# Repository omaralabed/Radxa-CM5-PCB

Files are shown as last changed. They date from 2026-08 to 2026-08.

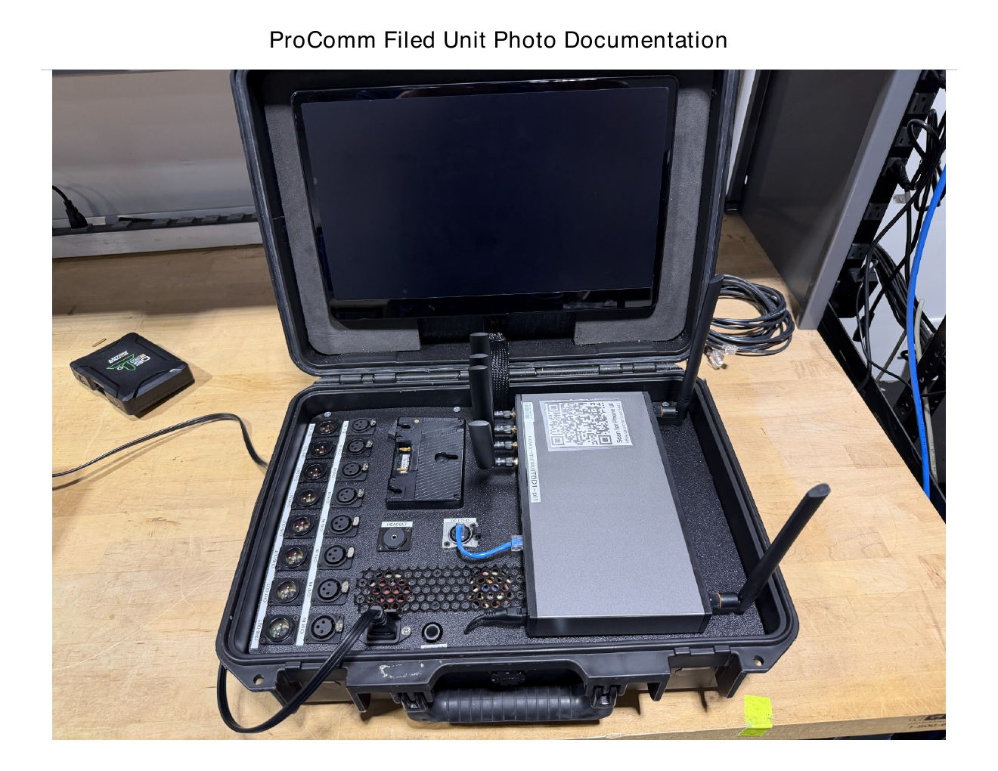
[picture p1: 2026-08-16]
references/procomm-field-unit/procomm_field_unit-4.png

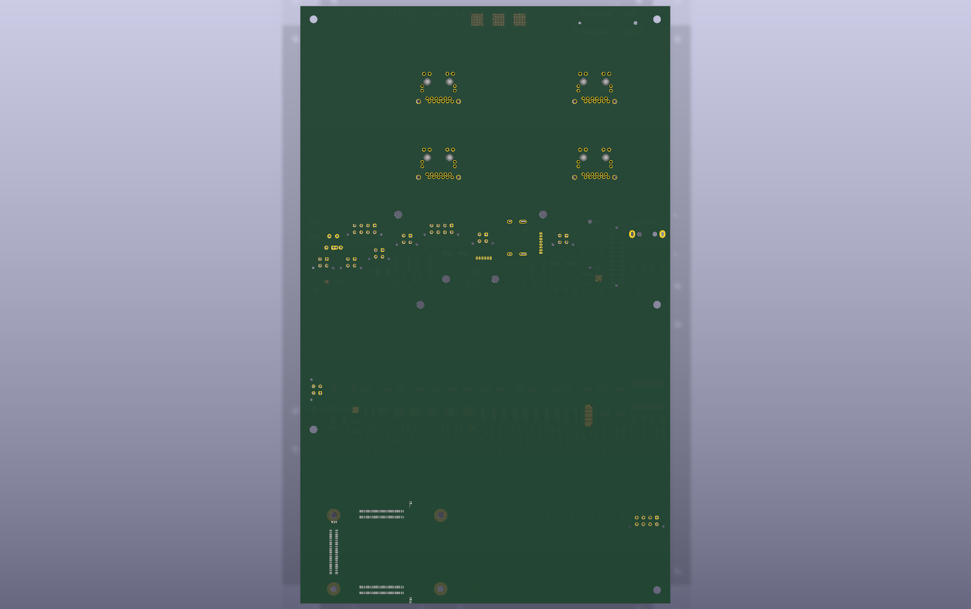
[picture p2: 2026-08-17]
cad/kicad/PCB-REVIEW/3D/CM5-Carrier-PCB-A1-bottom.png

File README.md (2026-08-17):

# Radxa CM5 Carrier PCB

Project workspace for a custom carrier board for the Radxa CM5 compute module.

## Self-Contained Project Files

Only the current Rev L top-panel drawing and Rev L underside-floorplan drawing
are retained under `cad/`. They reserve a 15 mm four-side frame/screw keepout,
limit the suspended PCB envelopes, and control six rigid M3 supports per long
PCB before routing. The battery calculation
is under `docs/`. The obsolete 8.7 GB design-session recording was intentionally
removed before repository publication.

Mechanical fabrication remains on A2 `HOLD_FOR_MEASUREMENT`. The controlled
gate is `docs/fabrication-readiness-audit-a2.md`; it corrects the below-panel
stack, locks battery-removed/eight-antennas-folded transport closure, and uses
the monitor's documented 396.24 x 203.20 x 20.32 mm body envelope. Actual case,
display-installation, dock, fan, tray, and connector checks remain required
before routing.

The ProComm field-unit photo PDF and rendered reference pages are preserved
under `references/procomm-field-unit/`.

## Current Status

- Workspace initialized.
- Official Radxa CM5 documentation and reference design identified.
- Audio architecture selected: photo-reference two-column XLR bank, left male outputs and right female inputs, with balanced 8x8 AK5558VN ADC and AK4458VN DAC over TDM.
- Capacitor/active-balanced XLR electrical reference selected from `/Users/viewvision/Desktop/ProComm enclosure and PCB boards`: THAT1206 input receivers, OPA1652/THAT1646 output drivers, coupling/filter/protection capacitors, and fail-silent output relays. The A1 AKM clock, level, filter, and rail starting values are calculated and captured; first-article audio validation remains mandatory.
- XLR bank geometry extracted from `/Users/viewvision/Desktop/2026/ProComm PCB XLRs + Transformer`: Neutrik `NC3MAV` / `NC3FAV`, 28 mm row pitch, 43.38 mm circular-center column spacing.
- Integrated headset architecture selected: ES8316 codec on a separate I2S bus,
  with headphone amplifier/driver and mic bias/preamp conditioning for a CTIA
  TRRS headset.
- Network architecture requirement added: 2x WAN, cellular WAN, 2x shared LAN, high-capacity Wi-Fi AP broadcast.
- Rev A Ethernet is locked to 1 GbE: native CM5 Ethernet for WAN1, three
  Microchip `LAN7430` controllers for WAN2/LAN1/LAN2, and an
  `PI7C9X2G608GP` PCIe switch shared with the 4T4R Wi-Fi AP module.
- Cellular modem direction locked to the ProComm native M.2 Key-B reference:
  SIM8260G-M2-class 3052 global target, 3042/3052 support, dual Nano-SIM, four
  cellular/GNSS antenna paths, and dedicated 3.8 V-class modem rail.
- Software runtime direction added: protect SIP/audio on reserved CPU resources,
  use the GPU for touchscreen UI, meters, waveform/spectrum display, and
  graphics, and reserve the NPU for future AI noise/classification and smart
  monitoring.
- Local touchscreen locked: JUNEBOX / DTM MALL `B0GK5X95D9` 15.6-inch HDMI
  touchscreen in the iM2300 lid, with USB touch and 12 V display power.
- Thermal architecture locked: four PWM/tach fans. The CM5 and modem are on the
  carrier underside with downward-facing heatsinks and attached, structurally
  supported dedicated fans. The enclosure uses a right-wall filtered intake
  and an operator-wall center-right exhaust; the top panel has no fan or mesh
  openings.
- The `RPS-400-24-C` remains bottom-mounted in a guarded hinge/display-side bay.
  Its footprint is rotated 90 degrees and shifted into the digital side, giving
  146 mm nominal separation from the audio quiet boundary to the grounded guard
  with a controlled 125 mm minimum. Enclosure-fan power/PWM harnesses stay out
  of the PSU corridor and the XLR analog quiet zone.
  The HDMI, USB-touch, and 12 V lid harness uses a separate protected corridor
  with at least 15 mm clearance to the PSU guard through service motion.
- Storage decision selected: CM5 eMMC only.
- Recovery/provisioning selected: USB recovery, debug UART, and network provisioning.
- Enclosure selected: Pelican Storm Case iM2300 with custom top panel and PCB mounted underneath.
- Top-panel connector envelope source-checked: 17.00 in x 11.733 in nominal base bezel reference.
- Power architecture selected: same ProComm source-selection baseline from
  `/Users/viewvision/Desktop/ProComm enclosure and PCB boards`, with
  bottom-panel MEAN WELL `RPS-400-24-C` 24 V AC/DC PSU as the locked
  production primary source,
  D-Tap / Gold Mount backup-source selection, telemetry, and Radxa-specific
  downstream regulators.
- Wi-Fi AP and cellular modem power are separate dedicated rails.
- No-blink primary/backup transfer is locked: with a valid backup source
  present, CM5, display, audio, headset, networking, and fan control must ride
  through source transfer without reset or mute.
- Preliminary system block diagram and power budget created; locked production
  PSU basis is `RPS-400-24-C` at 24 V / 10.5 A / 252 W convection-rated unless
  forced-air PSU cooling is intentionally designed and validated.
- AC mains entry direction selected: top-panel fused IEC C14 inlet with no
  built-in switch, using Qualtek `719W-00/03` as the production starting part;
  RS PRO `811-7204` remains the style reference.
- Main power control selected to match ProComm: E-Switch `RA812C1121`
  maintained DPST rocker. Its two isolated poles disable the LTC4421 primary
  selector and LTC4418 backup preselector; no high-current source wiring crosses
  the panel switch.
- Rev A schematic architecture, regulator starting parts, board partition,
  audio level, connector protection, antenna placement, service access, and
  AC safety/EMC direction are locked in `notes/rev-a-hardware-architecture.md`.
- The native KiCad 10 A1 suite under `cad/kicad/` now contains sixteen reviewed
  controlled schematic sheets across `PWR-SELECT`, `CM5-CARRIER`, and
  `AUDIO-8X8`. The
  source/status/telemetry, carrier/audio, fan, temperature-alert, and XLR
  interfaces have 174 critical connector and control pin/net assignments
  machine-validated. Each of the three electrically authoritative board roots
  reports `0 errors / 0 warnings`; isolated child-sheet context findings match
  a strict explicit allowlist. The controlled audit covers 1203 unique
  components and intentionally blocks final routing on ten audio package
  coupons. Native PCB-A1 files now carry the complete netlists, exact locked
  mating geometry, controlled support patterns, and deterministic in-board
  functional placement for all 1,190 schematic footprints; production routing
  has not begun.
- The three PCB-A1 baselines are checked by
  `cad/kicad/validate_pcb_placement.py` and
  `cad/kicad/validate_pcb_drc_baseline.py`. Locked XLR, RJ45, SIM, CM5, and
  support geometry has zero DRC errors. See
  `cad/kicad/PCB_LAYOUT_STATUS_A1.md` for the exact source, transform, placement,
  DRC, and 3D-review record.
- Footprint Coupon A1 is now a controlled 100 x 80 mm, six-layer KiCad board
  with zero DRC violations. It compares open, bottom-tented, and selective
  Type VII exposed-pad vias for AK5558VN/AK4458VN and includes physical fit
  sites for the TQ2-12V relay and Kycon CTIA jack. The PCBWay-ready Gerber,
  drill, drawing, placement, render, BOM, inspection, and result package is in
  `fabrication/footprint-coupon-a1`; physical qualification remains pending.
- The controlled PCBWay one-shot submission gate is under
  `fabrication/pcbway-release/`. It inventories the three production PCBs,
  complete PCBA outputs, mechanical machining release, harnesses, firmware,
  tests, and physical signoffs. Its validator prevents a partial or internally
  inconsistent factory upload.
- The reviewed factory-facing schematic PDFs are under
  `outputs/schematic-release-a1/`. The accompanying
  `docs/schematic-release-status-a1.md` records the passed electrical gates and
  the physical coupon/mechanical holds that must close before PCB placement.
- The complete native KiCad design now has one entry point at
  `cad/kicad/SYSTEM/Radxa-CM5-ProComm-System.kicad_pro`. Its first page is the
  real pin-level system electrical interconnect and pages 2-17 contain all
  sixteen component-level sheets, while preserving the three separate physical
  PCB netlists.
- The Radxa CM5 V2.21 A0 pin allocation is controlled in
  `notes/cm5-pin-allocation-a0.md` and
  `outputs/cm5-pin-allocation-a0/radxa_cm5_pin_allocation_a0.xlsx`. The audit
  contains 76 unique physical pins with no duplicate claims or source/mux
  mismatches. The monitor USB2 touch test and final `VCC_SYSIN` tolerance check
  remain release actions.

## Official References

- Radxa CM5 download page: https://docs.radxa.com/en/som/cm/cm5/download
- Radxa CM5 hardware interface page: https://docs.radxa.com/en/som/cm/cm5/hardware/hw-interface
- Radxa CM5 IO reference design: https://github.com/radxa/radxa-cm-projects/tree/main/cm5/radxa-cm5-io-board
- ProComm field unit photo documentation:
  `references/procomm-field-unit/procomm-field-unit-photo-documentation.pdf`

## Local Folders

- `cad/` - schematic and PCB design files
- `cad/kicad/` - native sixteen-sheet KiCad A1 capture, validators, and review artifacts
- `docs/` - datasheets, PDFs, pinout exports, design notes
- `fabrication/` - Gerbers, drill files, assembly files, BOM exports
- `notes/` - requirements and review notes
- `outputs/` - controlled engineering workbooks and review deliverables
- `references/` - vendor reference designs and imported examples

## Active Notes

- `notes/rev-a-hardware-architecture.md` - locked Rev A schematic architecture and release gates
- `notes/cm5-pin-allocation-a0.md` - controlled CM5 V2.21 pin ownership,
  mux exclusions, and schematic-integration actions
- `notes/connector-protection-matrix.md` - external-connector ESD, surge, and current-limit plan
- `notes/audio-tdm-architecture.md` - AK5558VN/AK4458VN TDM plan and CM5 pin candidates
- `notes/audio-8x8-a1.md` - detailed A1 TDM, analog level, power, grounding,
  sequencing, and routing-release contract
- `notes/enclosure-mechanical.md` - Pelican iM2300 enclosure constraints
- `docs/pcb-and-connector-mechanical-protection-a2.md` - controlled six-point
  PCB supports and panel/frame connector load paths
- `notes/headset-audio.md` - integrated 3.5 mm headset jack plan
- `notes/legacy-procomm-reference.md` - reference review of previous ProComm enclosure/PCB folder
- `notes/network-architecture.md` - WAN/LAN/Wi-Fi architecture options
- `notes/network-module-selection.md` - selected network, Wi-Fi AP, and cellular modem-slot direction
- `notes/power-architecture.md` - bottom-mounted 24 V AC/DC PSU plus D-Tap and Gold Mount power plan
- `notes/pre-schematic-open-decisions.md` - remaining decisions before schematic capture
- `notes/procomm-capacitor-xlr-audio-reference.md` - active capacitor-coupled XLR electrical reference from prior ProComm board
- `notes/software-runtime-architecture.md` - CPU partitioning and GPU/VPU/NPU offload plan for SIP/audio reliability
- `notes/system-block-diagram.md` - top-level power, data, audio, network, modem, display, and thermal block diagram
- `notes/power-budget.md` - first-pass power budget and locked production PSU margin check
- `notes/no-blink-power-transfer.md` - seamless primary/backup transfer requirements and validation plan
- `notes/power-regulators-a1.md` - calculated A1 regulator tree, selected parts,
  sequencing, hold-up, source-current checks, and release tests
- `notes/thermal-fans.md` - CPU and enclosure fan control plan
- `docs/thermal-control-firmware-spec.md` - Linux device-tree, driver,
  thermal-service, watchdog, fail-safe, and qualification specification for
  board-controlled fan speed
- `docs/power-telemetry-software-spec.md` - three-channel INA228 hardware map,
  carrier harness, Linux hwmon integration, touchscreen fields, calibration,
  backup-runtime method, and future firmware release checklist
- `notes/top-panel-layout.md` - source-checked iM2300 connector-panel layout envelope
- `notes/main-power-switch.md` - exact ProComm-matching DPST switch, cutout,
  harness, wiring, and acceptance tests
- `notes/xlr-bank-reference.md` - extracted Neutrik XLR bank geometry from the legacy ProComm XLR KiCad folder
- `notes/requirements.md` - product requirements draft
- `notes/bringup-checklist.md` - board bring-up checklist
- `notes/cellular-modem-reference.md` - native M.2 B-Key cellular modem reference adapted from ProComm
- `docs/power_budget_preliminary.csv` - CSV version of the preliminary power budget
- `docs/source_current_check_preliminary.csv` - CSV source-current check for 24 V, D-Tap, and Gold Mount operation
- `docs/akm_clock_mode_matrix_a1.csv` - locked 48 kHz TDM256 clock, strap,
  register, address, and start-up matrix
- `docs/audio_8x8_level_budget_a1.csv` - calculated +4/+24 dBu input and
  600-ohm output level budget
- `docs/audio_8x8_bom_a1.csv` - generated detailed AUDIO-8X8 schematic BOM
- `docs/qualification/footprint-coupon-a1.md` - controlled AKM exposed-pad,
  Panasonic relay, and Kycon jack physical qualification plan

## Remaining Detailed-Capture Work

The architecture and native CAD tool are selected. Complete these engineering
inputs before production layout release:

- Final CM5 `VCC_SYSIN` tolerance/setpoint release and monitor USB2 touch test
- Six-layer-or-greater controlled-impedance PCB stackup from the fabricator
- Physical build and signed inspection of Footprint Coupon A1, 67 PWR-SELECT
  passive MPN assignments, placement/thermal review, safety review, and final
  mechanical CAD
- Bench measurements for display, modem, Wi-Fi, fans, audio, transfer, and thermal load
- Manufacturing target: prototype only or assembly-ready production files

## Version Control Policy

- Canonical repository: https://github.com/omaralabed/Radxa-CM5-PCB
- `main` holds the latest reviewed project state.
- After each completed controlled design update, run the applicable validation,
  create a focused commit, and push it to `origin/main`.
- Do not commit temporary renders, editor state, KiCad session files, or local
  scratch data covered by `.gitignore`.

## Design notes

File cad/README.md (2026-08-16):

# CAD Workspace

Native schematic tool: KiCad 10. The three-board A0 capture is under `kicad/`;
see `kicad/README.md` for project status, regeneration, validation, and the
detailed-capture order.

## Current Mechanical Concept

- `im2300-top-panel-layout-rev-l.svg` - current connector-placement concept. It
  reserves a 15 mm four-side frame/screw keepout, moves the XLR bank only 2.3
  mm right to clear that boundary, and retains the preliminary centered
  90 x 8 mm notch opening through the hinge edge for the HDMI, USB-touch, and
  12 V display harness. It also adds two diffused 12 V warm-white courtesy
  lights and one latching capacitive touch control in the clear strip above
  the Gold Mount keepout. It includes
  the 8x8 XLR bank, left-to-right Gold Mount engagement sweep, four RP-SMA
  Wi-Fi and four SMA cellular bulkheads with inboard folded-transport
  projections, four Ethernet ports,
  lid-display harness, headset/SIM service, status, LEMO backup,
  separate DPST main source-enable rocker, and guarded fused C14 zone. It has
  no fan or mesh cooling openings; enclosure airflow is on the case sidewalls.

This SVG is a placement study, not a fabrication cut file. Replace every
connector representation with the final manufacturer's panel-cutout drawing
and replace the nominal panel outline with measurements from the actual case.

## Current Underside Study

- `mechanical/im2300-underside-pcb-floorplan-rev-l.svg` - current pre-routing
  floorplan. It limits `AUDIO-8X8` to 78 x 268 mm and `CM5-CARRIER` to 166 x
  268 mm, keeps both boards out of the 15 mm perimeter band, places the CM5 and
  modem on B.Cu with downward cooling cartridges, rotates the PSU 90 degrees
  in a guarded hinge-side floor bay at least 125 mm from the audio quiet
  boundary, and defines the right-wall intake/operator-wall exhaust airflow
  corridor. The nominal guard separation is 146 mm, and the lid-display bundle
  has a separate protected route with at least 15 mm guard clearance. It
  reserves the rear bodies plus fused 12 V harness route
  for the independent panel lights. It
  reserves the Gold Mount battery insertion corridor on the left and locks
  engagement toward the network side. It controls six rigid M3 mounting
  positions per long PCB and reserves their NPTH/copper/component keepouts.
- `mechanical/pcb-and-connector-support-detail-rev-a.svg` - controlled factory
  detail for long-PCB supports and panel/frame connector load transfer.

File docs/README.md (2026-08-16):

# Documents

Place downloaded datasheets, pinout tables, and exported design PDFs here.

Official Radxa resources are listed in the project README. The reference design is cloned under `references/radxa-cm-projects/cm5/radxa-cm5-io-board/`.

Mechanical A2 release gate:

- `fabrication-readiness-audit-a2.md` - factory-facing fit, material, thermal,
  power, transport-closure, and first-article audit.
- `mechanical-stack-budget-a2.csv` - controlled panel, tray, PSU, carrier,
  cooling, display, battery, and RF stack budget.
- `../fabrication/mechanical-release/` - M001-M080 register, A2 release data,
  printable worksheet, and validator.

Preliminary engineering tables:

- `power_budget_preliminary.csv` - typical, continuous-design, and transient
  load budget.
- `source_current_check_preliminary.csv` - source current at PSU and backup
  voltages.
- `battery_runtime_preliminary.csv` - Dionic XT 90 ideal and conservative
  backup-runtime estimates.
- `panel_mechanical_bom_preliminary.csv` - exact panel-part candidates,
  mechanical status, controlled drawing references, and fabrication blockers.
- `power_switch_bom.csv` - exact DPST panel-switch and four-wire harness parts.
- `../fabrication/harnesses/H01-PSU-24V.md` - factory assembly, pinout, length,
  crimp, routing, and acceptance requirements for the bottom-PSU 24 V harness.
- `../fabrication/harnesses/H01-PSU-24V-BOM.csv` - exact Mega-Fit, TPA, crimp,
  ring-terminal, and wire parts for that harness.
- `../fabrication/harnesses/H03-Lid-Display-Bundle.md` - controlled 1 m
  prototype HDMI, USB-touch, and monitor-power service bundle definition.
- `../fabrication/harnesses/H03-Lid-Display-BOM.csv` - selected carrier-side
  connectors and sample-gated monitor-side cable parts.
- `power_regulator_bom_a1.csv` - A1 regulator-sheet BOM exported directly from
  KiCad, including selected manufacturers and MPNs.
- `power_regulator_calculations_a1.csv` - machine-checkable rail, source,
  protection, and hold-up calculations for the A1 regulator capture.

Firmware and operating-system integration:

- `thermal-control-firmware-spec.md` - controlled EMC2305/TMP117 Linux
  integration, fan-channel mapping, device-tree starting point, fan curves,
  watchdog behavior, fail-safe requirements, and release tests.
- `power-telemetry-software-spec.md` - INA228 primary/backup/load channel map,
  I2C harness, Linux hwmon starting point, touchscreen requirements,
  calibration, runtime estimation, and future firmware checklist.

Controlled interface allocation:

- `radxa_cm5_v2210_pinout.xlsx` - local controlled copy of the official Radxa
  CM5 V2.21 connector pinout.
- `../outputs/cm5-pin-allocation-a0/radxa_cm5_pin_allocation_a0.xlsx` - A0
  physical-pin assignment, resource map, GPIO/control allocation, conflict
  ledger, and normalized official source rows.

Mechanical manufacturer drawings are archived under `mechanical-parts/`.

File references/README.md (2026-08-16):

# References

Vendor reference designs and examples live here.

Current references:

- `radxa-cm-projects/cm5/radxa-cm5-io-board/` - vendored official Radxa CM5 IO
  board reference design; upstream commit is recorded in
  `radxa-cm-projects/SOURCE.md`
- `procomm-field-unit/` - source photo PDF and rendered visual-reference pages
- `datasheets/AsiaRF-AW7915-NP1.pdf` - locked 4T4R Mini PCIe Wi-Fi module brief
- `datasheets/Molex-0679101002-Mini-PCIe-socket.pdf` - selected 52-position
  Mini PCIe host-socket drawing and recommended PCB layout
- `datasheets/INA228.pdf` - TI 85 V, 20-bit current/power monitor datasheet
- `datasheets/Vishay-WSK2512.pdf` - four-terminal source/load shunt datasheet

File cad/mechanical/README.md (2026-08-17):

# iM2300 Mechanical Studies

These drawings extend the current Rev L top-panel placement. The underside Rev L preserves
the XLR and panel datums while adding the A2 vertical-stack gate, low-profile
bottom tray, six supports per long PCB, selected modem fan, transport-closure
rules, PSU airflow wash, and corrected panel-thickness logic.

- `im2300-closed-lid-stack-rev-g.svg`: corrected side section using datum A at
  the finished panel top face, 3.175 mm panel thickness, the monitor's
  documented 396.24 x 203.20 x 20.32 mm body envelope, 65.425 mm nominal space below the panel underside, and
  battery-removed transport closure with all eight released compact hinged
  antennas installed and folded inboard. Their approximately 32 mm preliminary
  folded envelope remains sample-controlled and requires 12.7 mm (0.50 in)
  dynamic clearance from the monitor front.
- `im2300-underside-pcb-floorplan-rev-l.svg`: pre-routing revision that reserves
  a 15 mm four-side frame/screw keepout, reduces the audio and carrier board
  envelopes to 78 x 268 mm and 166 x 268 mm, moves the two Delta
  `THA0412AD-TZW3` enclosure fans to a right-wall intake and operator-wall
  exhaust, keeps all fan/PWM wiring out of the analog quiet zone and guarded
  PSU corridor, keeps the PCIe switch
  beside the CM5, fits the full-size AW7915-NP1 Mini PCIe card and eight coax
  paths, defines protected high-speed, lid-harness, TDM, RF, and power
  corridors, reserves the panel-mounted warm-white courtesy-light bodies and
  their independent fused AUX_12V harness, and keeps the Gold Mount insertion
  corridor clear on the left so the battery slides toward the network side.
  It also freezes six collision-checked M3 support coordinates on each long
  PCB, with 3.4 mm NPTH holes, 8 mm all-layer copper keepouts, and 10 mm
  component keepouts.
  The PSU guard is nominally 146 mm from the audio quiet boundary and may not
  fall below 125 mm after the physical tolerance stack is released.
  The lid-display harness has a separate protected corridor with 15 mm minimum
  clearance to the PSU guard. The complete installed PSU guard stays no more
  than 48 mm above the deepest floor and retains 10 mm minimum to carrier B.Cu.
- `cm5-5540a-delta-cooling-concept-rev-b.svg`: downward-facing cooling cartridge
  for
  the Radxa `5540A` heatsink and Delta `FFB0412EN-00Y2E` CPU fan, including
  a fan-to-heatsink adapter plus structural vibration-isolated support bracket,
  a 10 mm minimum bottom intake gap, and the protected 3 A fan power branch.
- `im2300-sidewall-cooling-layout-rev-c.svg`: preliminary right-wall intake and
  operator-wall exhaust centers, selected Qualtek guards, custom splash-hood
  rules, clean-air PSU wash, reinforcement/gasket rules, and thermal acceptance.
- `im2300-cooling-clearance-rev-d.scad`: parametric 3D clearance concept for the
  panel, suspended boards, hinge-side PSU, sidewall fans, and downward-facing
  CM5/modem cooling stacks, corrected panel underside, tray, and guarded PSU
  Z stack and all twelve controlled panel-to-PCB standoffs. Its assertions are
  planning checks, not release CAD.
- `pcb-and-connector-support-detail-rev-a.svg`: factory detail for supports
  `A1-A6` and `C1-C6`, panel-flanged connectors, and custom capture brackets
  that keep plug/unplug and downward loads out of PCB laminate and solder.
- `sim-service-daughterboard-stack-rev-b.svg`: exact horizontal 76 x 40 mm
  SIM-SERVICE relationship to carrier J702, four `SD1-SD4` / `S1-S4` support
  pairs, 2.50 mm Hirose DF40 mating height, and panel-clearance/load proof.

These drawings are fit studies, not fabrication releases. Replace nominal case,
monitor, connector, PCB, heatsink, fan, PSU, battery-dock, and harness envelopes
with measured dimensions and manufacturer STEP/drawing data before release.

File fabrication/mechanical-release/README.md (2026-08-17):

# iM2300 Mechanical Release Package

## Status

- Package revision: A2
- Release state: `HOLD_FOR_MEASUREMENT`
- Panel installation plane: 38.1 mm below the case parting line
- Controlled concept drawings:
  - `../../cad/im2300-top-panel-layout-rev-l.svg`
  - `../../cad/mechanical/im2300-underside-pcb-floorplan-rev-l.svg`
  - `../../cad/mechanical/im2300-sidewall-cooling-layout-rev-c.svg`
  - `../../cad/mechanical/im2300-closed-lid-stack-rev-g.svg`
  - `../../cad/mechanical/pcb-and-connector-support-detail-rev-a.svg`

This package controls the measurements that must be taken from the actual
Pelican iM2300, custom four-side frame, installed display assembly, battery
dock, and production connector samples. The monitor body uses the documented
396.24 x 203.20 x 20.32 mm nominal envelope; its mount, connector, cable, and
closed-lid geometry remain installation checks. Published case dimensions are
useful for planning but are not fabrication datums.

## Required Equipment

- Calibrated 0.01 mm digital caliper
- 300 mm depth gauge or height gauge
- Steel rule and machinist square
- Radius gauges or a printed radius template
- Feeler gauges or calibrated spacer blocks
- Actual iM2300 case, display, battery and dock, fans/guards, XLR connectors,
  C14 inlet, LEMO connector, switches, SIM holders, RJ45s, RF bulkheads, and
  four samples of each selected compact hinged antenna

## Datum System

- `A`: finished top-panel plane
- `B`: finished left panel edge at the operator-facing orientation
- `C`: finished hinge-side panel edge
- `D`: case parting-line plane
- `E`: custom frame inner support edge

All panel X/Y coordinates use the intersection of datums `B` and `C` as the
origin. Positive X runs toward the RF bank. Positive Y runs toward the
operator/handle side.

All vertical dimensions use the finished top face of the panel as datum `A`.
At the published 106.7 mm base depth, a 38.1 mm recess places `A` 68.6 mm
above the nominal deepest floor. A 3.175 mm panel leaves 65.425 mm below the panel
underside. These are planning values only; measure the actual floor ribs,
frame, tray, panel, and case.

## Procedure

1. Install temporary gauge rails at exactly 38.1 mm below datum `D`.
2. Measure the case opening at the four corners and centerlines without forcing
   the case walls outward. Record every value in
   `im2300-measurement-register.csv`.
3. Derive the preliminary plate size using the Pelican bezel rule: subtract
   2.3876 mm, then subtract 0.4572 mm per 6.35 mm of recess. At 38.1 mm recess,
   the total nominal subtraction is 5.1308 mm from each measured opening
   dimension. The actual frame geometry remains the controlling fit check.
4. Produce a cardboard, acrylic, or inexpensive aluminum gauge plate. Verify
   insertion, removal, frame seating, gasket clearance, and all screw access.
5. Mount representative connectors, battery, display, sidewall fans, guards, CM5
   cooling stack, and harnesses. Close and latch the case for the closure and
   impact-clearance measurements.
   Fit 1000 +/- 25 mm H03A HDMI, H03B USB-touch, and H03C display-power
   prototype cables. Verify full lid travel, then release the panel-service
   clamps and raise the connected top panel at least 300 mm while tilting it
   at least 45 degrees. No connector may carry tension and no cable may enter
   a fan, airflow path, sharp-edge zone, or PCB keepout.
   Mount the Gold Mount dock with its supplied backplate against a supported
   flat panel/frame load path. The battery engages from left to right and
   removes from right to left. Measure the complete slide travel and verify at
   least 20 mm of clear insertion/hand space between the XLR hardware and dock.
   Carry the dock, battery, insertion, and vibration loads entirely through the
   top panel/custom frame. No dock fastener or load path may terminate in a PCB.
   Perform the transport-closure test with the battery removed and all eight
   released compact hinged antennas installed and folded inboard toward the
   panel center. Do not force or latch a closure that shows interference.
   Upright antennas, substitute antenna models, or battery-installed closure
   require a separate signed sweep record.
6. Enter measured minimum/maximum values in
   `mechanical-release-a2.json`, attach measurement photos or inspection
   records, and run `validate_mechanical_release.py --release`.
7. Rev L nominal board envelopes, the controlled A1-A6/C1-C6 primary support
   pattern, and the SD1-SD4/S1-S4 direct SIM-stack pattern authorize
   engineering PCB placement and routing. Only after the release
   validator passes may the exact panel outline, connector Z datums, panel
   screw coordinates, and production machining files be frozen for fabrication.

## Hard Constraints

- Continuous 15.0 mm no-PCB frame/screw band on all four sides.
- `AUDIO-8X8` PCB envelope no larger than 78 x 268 mm.
- `CM5-CARRIER` PCB envelope no larger than 166 x 268 mm.
- Panel screws and frame hardware are mechanically independent of PCB mounts.
- Top panel is 3.175 mm nominal 5052-H32 aluminum with a matte black finish;
  validate a 3.0-3.3 mm coupon. Rear-pocket the RA812 rocker area to no more
  than 3.0 mm without weakening its local support.
- Bottom equipment tray is 2.0 mm nominal 5052-H32 aluminum. Its released top
  surface may be no more than 3.0 mm above the deepest local case-floor datum.
  Do not put a compressible foam stack under the PSU.
- The QRC-GOLD dock is top-panel/custom-frame hardware, not a PCB-mounted part;
  only its strain-relieved removable power harness reaches the selector PCB.
- Minimum 12.7 mm (0.50 in) closed-lid dynamic clearance from the monitor
  front after tolerance stack-up.
- Transport closure requires the Gold-mount battery removed and all four
  Taoglas `GW.05.0153` Wi-Fi antennas plus all four Taoglas `TG.66.A113`
  cellular antennas installed and folded inboard. Upright or substitute
  antennas are not an approved closure configuration.
- Minimum 3.0 mm static clearance between unrelated metal hardware; use more
  where cables, latches, fingers, insulation, or vibration motion require it.
- XLR bank outside edge remains at least 15.0 mm from the finished panel edge.
- The CM5/modem dedicated fan inlets face the bottom and retain at least 10 mm
  unobstructed clearance through the full tolerance and vibration stack.
- The right-wall filtered intake and operator-wall center-right exhaust require
  separate reinforcement plates, gaskets, guards, and splash-directed louvers.
- Maintain at least 100 mm practical separation between enclosure fan/PWM
  hardware and the AUDIO-8X8 quiet boundary; route fan power with a filtered
  star return and outside the guarded hinge-side PSU harness corridor.
- Rotate the `RPS-400-24-C` footprint 90 degrees in plan and maintain at least
  125 mm from the AUDIO-8X8 quiet boundary to the nearest grounded PSU guard
  edge after tolerance stack-up. The Rev L nominal study provides 146 mm.
  Keep the complete tray-mounted PSU/terminal-guard envelope no more than
  48.0 mm above the deepest interior floor. Maintain at least 10 mm vertically
  from that guard to the nearest carrier
  component or panel underside and keep the overlying carrier B.Cu area clear.
- Keep the actual HDMI, USB-touch, and 12 V lid-harness cable envelope at least
  15 mm from the grounded PSU guard through full lid travel and the complete
  panel-lift service motion. No mains conductor, fan harness, or shared clamp
  may enter that protected corridor.
- Gold Mount engagement is left to right. Keep the left insertion corridor and
  complete battery motion sweep free of panel hardware and connected cables.
- Use the six controlled supports `A1-A6` on AUDIO-8X8 and `C1-C6` on
  CM5-CARRIER from `pcb-support-pattern-a2.csv`. Each support uses a 3.4 mm
  finished NPTH, 8.0 mm all-layer copper keepout, 10.0 mm component keepout,
  and a rigid captive metal M3 standoff. Maximum longitudinal support-row span
  is 128 mm. Do not soft-float either PCB.
- Plug the horizontal SIM-SERVICE daughterboard directly into carrier J702
  through the specified Hirose DF40 plug/socket pair. Use all four matched
  `SD1/S1` through `SD4/S4` M3 supports with 2.50 +/-0.05 mm precision sleeves.
  No SIM cable harness is permitted, and the DF40 pair is not structural.
- Every user-operated connector shall transfer plug, unplug, downward push,
  cable-side, and vibration loads to the panel or frame. Follow
  `connector-load-path-a2.csv`; solder-only retention is prohibited. Release
  the RJ45 capture bracket and headset/SIM service-board coupons before routing.
- Qualify the complete unit at 45 C ambient and 151.7 W continuous load.
  Measure at least 15 CFM through-case with a clean filter, at least 12 CFM at
  the released filter-maintenance limit, and keep PSU inlet air at or below
  50 C. The RPS-400-24-C derates with temperature.

## Files

- `im2300-measurement-register.csv`: inspection record for the actual hardware
- `mechanical-release-a2.json`: machine-readable release gate
- `validate_mechanical_release.py`: package/release validator
- `pcb-support-pattern-a2.csv`: controlled board and panel support coordinates
- `connector-load-path-a2.csv`: controlled load path for each interface group
- `sim-service-daughterboard-stack-a1.csv`: direct socket stack, support pairs,
  connector datums, and panel-clearance calculation
- `im2300-measurement-worksheet-a2.svg`: printable factory worksheet

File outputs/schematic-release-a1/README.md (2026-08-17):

# Schematic Release A1

## State

**ELECTRICAL_CAPTURE_COMPLETE / PCB_ROUTING_HELD**

This folder contains the factory-review PDF set generated from all sixteen
controlled KiCad schematic sheets. The editable whole-system entry point is
`../../cad/kicad/SYSTEM/Radxa-CM5-ProComm-System.kicad_pro`.

- `Radxa-CM5-ProComm-Complete-Electrical-A2.pdf`: native KiCad 17-page export;
  page 1 is the real system electrical interconnect and pages 2-17 are the
  complete component-level circuits.
- `Power-Selector-Schematic-A1.pdf`: no-blink primary/backup selector,
  hold-up, telemetry, and protected output.
- `CM5-Carrier-Schematic-A1.pdf`: CM5 allocation, network, Wi-Fi, cellular,
  display, headset, power, fan, sensor, and service interfaces.
- `Audio-8x8-Schematic-A1.pdf`: AK5558VN ADC, AK4458VN DAC, TDM clock/control,
  balanced line stages, relays, XLRs, and audio power.
- `Radxa-CM5-ProComm-Schematic-Release-A1.pdf`: cover plus the complete master
  set in electrical review order.
- `SHA256SUMS.txt`: controlled hashes for all five release PDFs.

Regenerate only after the complete capture gate passes:

```sh
cad/kicad/review_detailed_capture.sh
/Users/viewvision/.cache/codex-runtimes/codex-primary-runtime/dependencies/python/bin/python3 \
  cad/kicad/build_schematic_release.py
```

The schematic set is electrically reviewed but does not authorize PCB routing.
Ten routing-critical footprint coupons and the measured enclosure/mechanical
release remain open. See `../../cad/kicad/FOOTPRINT_RELEASE.md` and
`../../fabrication/mechanical-release/README.md`.

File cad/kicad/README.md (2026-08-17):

# KiCad Hardware Projects

## Tool And Status

- Native CAD tool: KiCad 10.0.5.
- Capture milestone: A1 detailed CM5-carrier schematic suite.
- PCB milestone: native PCB-A1 in-board engineering-placement baselines.
- These files are not a fabrication release.
- Rev L nominal envelopes and controlled support coordinates authorize
  engineering carrier, audio, and selector PCB layout. Exact machining datums,
  production connector Z, and fabricator-approved impedance tables remain
  final-release gates.

## Project Split

- `SYSTEM/Radxa-CM5-ProComm-System.kicad_pro`: one native KiCad electrical
  project for the complete design. Page 1 captures the exact system harness,
  power, display, fan, network, service, RF, and XLR pin/net interconnects;
  pages 2-17 contain the sixteen component-level sheets. System connector and
  sheet instances are excluded from BOM and board update; the three physical
  PCB netlists remain controlled by their board projects below.

- `PWR-SELECT/PowerSelector.kicad_pro`: Radxa A1 source-selector capture with
  1.50 mOhm source-shunt starting values, three INA228 telemetry channels, and
  a delivered-load shunt. Four 6800 uF / 50 V Nichicon snap-ins plus 660 uF of
  local hybrids form the floor-mounted hold-up bank; all 15 A-class thermal,
  SOA, inrush, tolerance, retention, and transfer assumptions still require
  release validation.
- `CM5-CARRIER/CM5-Carrier.kicad_pro`: carrier interface overview and shared
  interboard connector contract.
- `CM5-CARRIER/CM5-Core-Allocated.kicad_pro`: exact 300-contact CM5 connector
  representation with all 76 allocation-ledger contacts owned, three
  official-source DF40 footprints, four grounded module mounts, plus
  power/service controls and debug UART.
- `CM5-CARRIER/Network-PCIe.kicad_pro`: native WAN1, PI7C9X2G608GP PCIe switch,
  three LAN7430 endpoints, four protected MagJacks, and the AW7915-NP1 4T4R
  Wi-Fi interface through a Molex 0679101002 Mini PCIe socket.
- `CM5-CARRIER/WWAN-SIM.kicad_pro`: USB3/USB2 cellular B-key interface, modem
  controls, protection, dual nano-SIM holders, and FSA2567 SIM mux.
- `CM5-CARRIER/Display-Harness.kicad_pro`: HDMI, USB touch, and the locked
  12 V / 2.5 A monitor branch.
- `CM5-CARRIER/Audio-Control.kicad_pro`: differential I2S0/TDM interboard link,
  I2S1 ES8316 CTIA headset path, and TPA6132A2 headphone amplifier.
- `CM5-CARRIER/Power-Regulators-A1.kicad_pro`: calculated 10.5-30 V power tree,
  protected input from the no-blink selector, dedicated system/radio/network/audio rails, branch
  protection, sequencing, and rail test access.
- `CM5-CARRIER/Thermal-IO.kicad_pro`: I2C translation, GPIO expansion, three
  temperature zones, status outputs, and four independent PWM/tach fans.
- `AUDIO-8X8/Audio-8x8.kicad_pro`: native audio interface sheet with the
  carrier contract and eight `NC3MAV` outputs plus eight `NC3FAV` inputs.
- `AUDIO-8X8/Audio-TDM-Clock.kicad_pro`: differential TDM harness receivers,
  ADC return driver, reset/mute defaults, and clock contract.
- `AUDIO-8X8/AK5558-ADC.kicad_pro`: exact eight-channel ADC pin capture,
  references, bypassing, mode straps, and I2C address `0x10`.
- `AUDIO-8X8/AK4458-DAC.kicad_pro`: exact eight-channel DAC pin capture,
  references, bypassing, mode defaults, and I2C address `0x11`.
- `AUDIO-8X8/Audio-Inputs.kicad_pro`: eight THAT1206/OPA1652 active-balanced
  input channels with protection and anti-alias networks.
- `AUDIO-8X8/Audio-Outputs.kicad_pro`: eight OPA1652/THAT1646 active-balanced
  output channels with fail-silent relays and connector protection.
- `AUDIO-8X8/Audio-Power.kicad_pro`: isolated bipolar line-stage power,
  low-noise AKM rails, sequencing, and controlled ground star.
- `INTERBOARD_INTERFACE_CONTRACT.md`: controlled pin assignment shared by all
  three projects.
- `../../notes/cm5-pin-allocation-a0.md` and
  `../../outputs/cm5-pin-allocation-a0/radxa_cm5_pin_allocation_a0.xlsx`:
  controlled Radxa CM5 V2.21 module-pin ownership and mux-conflict audit for
  detailed `CM5-CARRIER` capture.

Enclosure fan 1 is the filtered right-wall intake. Enclosure fan 2 is the
operator-wall center-right exhaust. Both are Delta `THA0412AD-TZW3` units.
They have independent 1 kHz PWM and tach nets from the EMC2305; internal
baffles must force intake air across the hot zones before it reaches the
separate exhaust opening.

## Regenerate And Validate

The carrier and audio sheets are generated through the structured
`kicad-sch-api` package. The generator is the source of truth; do not make a
manual edit to a generated `.kicad_sch` file without also updating it.

```sh
python3 -m pip install --target /tmp/radxa-cm5-kicad-deps -r cad/kicad/requirements.txt
PYTHONPATH=/tmp/radxa-cm5-kicad-deps python3 cad/kicad/generate_interface_schematics.py
PYTHONPATH=/tmp/radxa-cm5-kicad-deps python3 cad/kicad/PWR-SELECT/generate_power_selector.py

KICAD=/Applications/KiCad/KiCad.app/Contents/MacOS/kicad-cli
"$KICAD" sch export netlist --format kicadxml \
  --output cad/kicad/PWR-SELECT/REVIEW/PowerSelector-A0.xml \
  cad/kicad/PWR-SELECT/PowerSelector.kicad_sch
"$KICAD" sch erc --format report --units mm \
  --output cad/kicad/PWR-SELECT/REVIEW/PowerSelector-A0-ERC.rpt \
  cad/kicad/PWR-SELECT/PowerSelector.kicad_sch
"$KICAD" sch export netlist --format kicadxml \
  --output cad/kicad/CM5-CARRIER/REVIEW/CM5-Carrier-A1.xml \
  cad/kicad/CM5-CARRIER/CM5-Carrier.kicad_sch
"$KICAD" sch export netlist --format kicadxml \
  --output cad/kicad/CM5-CARRIER/REVIEW/Thermal-IO-A1.xml \
  cad/kicad/CM5-CARRIER/Thermal-IO.kicad_sch
"$KICAD" sch export netlist --format kicadxml \
  --output cad/kicad/AUDIO-8X8/REVIEW/Audio-8x8-A1.xml \
  cad/kicad/AUDIO-8X8/Audio-8x8.kicad_sch

python3 cad/kicad/PWR-SELECT/validate_power_selector.py
python3 cad/kicad/CM5-CARRIER/validate_cm5_pin_allocation.py
python3 cad/kicad/CM5-CARRIER/validate_power_regulators.py
python3 cad/kicad/AUDIO-8X8/validate_audio_8x8.py
python3 cad/kicad/validate_interface_contracts.py
python3 cad/kicad/audit_footprint_readiness.py
python3 cad/kicad/export_schematic_bom.py \
  --schematic cad/kicad/CM5-CARRIER/Power-Regulators-A1.kicad_sch \
  --output docs/power_regulator_bom_a1.csv \
  --exclude TP1190 --exclude TP1191 --exclude TP1192 --exclude TP1193 \
  --exclude TP1194 --exclude TP1195
python3 cad/kicad/AUDIO-8X8/export_audio_8x8_bom.py
```

The complete A1 gate is automated:

```sh
cad/kicad/review_detailed_capture.sh
```

Generate and validate the native PCB-A1 baselines with KiCad's bundled Python:

```sh
'/Applications/KiCad/KiCad.app/Contents/Frameworks/Python.framework/Versions/3.9/bin/python3' \
  cad/kicad/generate_pcb_projects.py
python3 cad/kicad/CM5-CARRIER/validate_cm5_mating_geometry.py
'/Applications/KiCad/KiCad.app/Contents/Frameworks/Python.framework/Versions/3.9/bin/python3' \
  cad/kicad/validate_pcb_placement.py
python3 cad/kicad/validate_pcb_drc_baseline.py
```

The same sequence, including regeneration of all three controlled DRC JSON
reports and the mechanical consistency gate, is automated as:

```sh
cad/kicad/review_pcb_baseline.sh
```

[`PCB_LAYOUT_STATUS_A1.md`](PCB_LAYOUT_STATUS_A1.md) records the no-guesswork
geometry sources, exact CM5 underside transform, PCBWay process rules, and the
controlled DRC/3D baseline. All schematic footprints are inside their correct
board; preliminary package blockers remain explicit until qualification.

After that gate passes, build the combined schematic review PDFs with:

```sh
/Users/viewvision/.cache/codex-runtimes/codex-primary-runtime/dependencies/python/bin/python3 \
  cad/kicad/build_schematic_release.py
```

The controlled outputs and electrical/physical release distinction are under
`../../outputs/schematic-release-a1/` and
`../../docs/schematic-release-status-a1.md`.

The generators use deterministic UUIDs. The review script writes temporary
ERC, netlist, and PDF outputs, then updates controlled review artifacts only
when their electrical content or rendered appearance changes. `pdftoppm` is
required for this visual comparison. Repeating the complete gate without a
source change must leave the working tree unchanged.

The interface validator checks 174 critical connector and control pin/net
assignments, including all three selector harnesses, power/temperature alerts,
the 30-pin buffered TDM/control link, separate audio power, four fan headers,
and all 16 XLR connectors.

The footprint audit covers every component once through the three physical
board roots; hierarchical child sheets are not double-counted. Its default
mode updates the controlled CSV and Markdown reports. Use `--routing` to
enforce the placement/routing gate and `--release` to additionally require a
manufacturer and MPN for every board-mounted item. The drawing-backed
connector evidence and the Molex 0679101002 datum contract are recorded in
[`FOOTPRINT_RELEASE.md`](FOOTPRINT_RELEASE.md).

The current audit covers 1203 components. Ten items intentionally block PCB
routing until physical coupons are approved: the two AKM exposed-pad packages
and eight Panasonic TQ2 relay lands. The stricter production audit also holds
the Kycon headset jack coupon, for 11 production blockers total.

The three electrically authoritative board roots (`PowerSelector`,
`CM5-Carrier`, and `Audio-8x8`) each report `0 errors / 0 warnings`. Standalone
child-sheet reports can contain expected off-sheet context findings; the review
script compares every one against an exact allowlist and fails on any drift.
The classification is recorded in `CM5-CARRIER/DETAILED_CAPTURE_STATUS.md`.
The AUDIO-8X8 XLR shield pins bond directly to `XLR_CHASSIS`; one controlled
1 Mohm / 4.7 nF bond joins chassis to `AGND` for static and RF control.

After every generated or manual schematic revision, export the full sheet to
PDF and inspect the dense areas at high resolution. Labels, wires, symbol
fields, connector identifiers, and sheet notes must not overlap or collide.
Electrical validation does not replace this visual readability gate.

## Next Engineering Order

1. Close the ten routing-critical AKM/TQ2 footprint coupons and the Kycon
   production coupon. All other schematic components currently resolve to a
   controlled footprint and production part; power and high-current lands
   still require first-article, copper-current, thermal, loop-response, and
   compensation review.
2. Complete selector shunt/current-limit tolerance, hold-up/precharge, SOA,
   telemetry calibration, and 15 A thermal review, then create its PCB.
3. Freeze the PCBWay-controlled impedance stackups. Continue placement and
   routing from the native PCB-A1 files while enforcing the Rev L underside
   limits of 78 x 268 mm for `AUDIO-8X8` and 166 x 268 mm for `CM5-CARRIER`,
   support patterns `A1-A6` and `C1-C6`, and the 15 mm frame/screw keepout.
   Keep every connector and CM5 mating datum locked.
4. Approve the AK5558VN/AK4458VN exposed-pad and TQ2 relay coupons, then bench
   validate the locked 48 kHz TDM256 mode, +4/+24 dBu level plan, 600 ohm
   compatibility load, mute sequencing, crosstalk, noise, and THD+N.
5. Run SI/PI, thermal, EMC, and fabrication DFM reviews before release.

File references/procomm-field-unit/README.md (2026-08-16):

# ProComm Field Unit Visual Reference

This folder preserves the original field-unit photo-documentation PDF and six
rendered page images used for enclosure, XLR-bank, display, antenna, and
connector-layout reference.

- `procomm-field-unit-photo-documentation.pdf` is the archived source.
- `procomm_field_unit-1.png` through `procomm_field_unit-6.png` are rendered
  reference pages.

The legacy ProComm hardware is a visual and architectural reference only. The
Radxa CM5 product uses its own PCB, AK5558VN/AK4458VN TDM audio architecture,
power calculations, and final mechanical drawings.

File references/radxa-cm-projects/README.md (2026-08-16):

## About




Welcome to the **Radxa Computer on Module (SoM)** projects. This repository contains the carrier board design files (PDF, DSN, PCB, DXF, XLSX) released by Radxa as well as community projects. 
For Large Language Models (LLMs) and autonomous engineering agents (like Cursor, GitHub Copilot), this repository acts as an **Agentic Hardware Knowledge Database**. By navigating to the `hardware-db` directory, agents can programmatically query JSON representations of board pinouts, interfaces, electrical domains, and hardware constraints without needing to parse complex schematic PDFs or unstructured markdown tables.

## CM Series

| CM Series | Description | Projects |
| --- | --- | --- |
| [Radxa CM3](https://rock.sh/cm3) | Computer on Module based on RK3566, compatible with Raspberry Pi CM4 | [CM3 Projects](./cm3/README.md) |
| [Radxa CM3I](https://rock.sh/cm3i) | Computer on Module based on RK3568(J) with industrial grade options | [CM3I Projects](./cm3i/README.md) |
| [Radxa CM4](https://rock.sh/cm4) | Computer on Module based on RK3676(J), compatible with Raspberry Pi CM4 | [CM4 Projects](./cm4/README.md) |
| [Radxa CM5](https://rock.sh/cm5) | Computer on Module based on RK3588S, compatible with Raspberry Pi CM4 | [CM5 Projects](./cm5/README.md) |

## NX Series

| NX Series | Description | Projects |
| --- | --- | --- |
| [Radxa CM3S](https://rock.sh/cm3s) | Computer on Module based on RK3566 in SODIMM form factor, compatible with Raspberry Pi CM3/CM3+ | [CM3S Projects](./cm3s/README.md) |
| [Radxa NX5](https://rock.sh/nx5) | Computer on Module based on RK3588S in SODIMM form factor | [NX5 Projects](./nx5/README.md) |
| [Radxa NX4](https://rock.sh/nx4) | Computer on Module based on RK3557(J) in SODIMM form factor | [NX4 Projects](./nx4/README.md) |
| [Orin NX](https://rock.sh/c200-orin) | Computer on Module based on NVIDIA Jetson Orin NX in SODIMM form factor | [Orin NX Projects](./c200/README.md) |

## Agent Friendly Hardware DB

This repository keeps all current hardware files and folder layout for human readers.

Machine readable hardware knowledge is added under `hardware-db` for agents and automation.

### New layout

- `hardware-db/schemas`: JSON Schema for board metadata and capability files
- `hardware-db/boards/<id>`: per board structured data and source tracking
- `tools/generate_readme_snippets.py`: generates `tools/out/<id>.md` summaries
- `tools/validate_db.py`: validates all board data against schema

### Why this matters (How it works)

To ensure both human documentation and machine-readable data never go out of sync, this repository operates under a unified **Single Source of Truth** pipeline:

```mermaid
graph TD
    A[(Raw Schematics / PDFs)] -->|Extract / Verify| B[hardware-db JSON Files]
    B -->|Verified Against| C{JSON Schemas}
    C -->|If Valid| D[tools/generate_readme_snippets.py]
    D -->|Injects / Updates| E[Human README.md Files]
    
    style B fill:#3498db,stroke:#2980b9,color:#fff
    style C fill:#f39c12,stroke:#d35400,color:#fff
    style E fill:#2ecc71,stroke:#27ae60,color:#fff
```

1. **Hardware Engineers/Contributors** write structured core data into `/hardware-db/` `.json`.
2. **Pre-commit Hooks & CI** validate that structure against `/schemas/`.
3. **Python Scripts** dynamically query the DB to print human-readable summary specs directly into each target documentation folder via `AGENT_SPEC_START` markdown blocks!

### Quick start

1. Create a Python virtual environment
2. Install dependency `jsonschema`
3. Run `python tools/validate_db.py`
4. Run `python tools/generate_readme_snippets.py`
5. Run `python tools/generate_readme_snippets.py --check` in CI or pre-commit

### Single source of truth

Board README files now include an `AGENT_SPEC_START` and `AGENT_SPEC_END` block at the top.

The content in this block is generated from `hardware-db/boards/<id>/*.json` through `tools/generate_readme_snippets.py`, with an explicit source path at the top of each block.

### Progressive migration

- Start from minimal known metadata with clear `sources.yaml` references
- Fill `interfaces.json`, `power.json`, and `capabilities.json` incrementally
- Add optional `pinout.json` when verifiable pin data is available
- Keep old docs and binary assets untouched during migration

### Contributing

If you'd like to help us add more SOM modules to the database, please check out our [Contribution Checklist](./CONTRIBUTING.md) to understand how to comply with schemas and install the mandated local `pre-commit` git hooks!

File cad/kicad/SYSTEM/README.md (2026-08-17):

# Complete System Schematic

Open `Radxa-CM5-ProComm-System.kicad_pro` to navigate the complete design from
one KiCad project. Page 1 is the pin-level system electrical interconnect for
AC/PSU/backup power, board-to-board harnesses, display, cooling, network,
service, RF, and all sixteen balanced XLR channels. Pages 2-18 are the seventeen
reviewed component-level circuit sheets, including the socketed SIM-SERVICE
daughterboard.

This project is the controlled whole-system electrical and factory-review entry
point. It does not merge the four physical PCB netlists:

- `PWR-SELECT` remains the source-selector PCB;
- `CM5-CARRIER` remains the compute/network/radio/control PCB;
- `AUDIO-8X8` remains the balanced-audio PCB.
- `SIM-SERVICE` remains the direct-socket dual-SIM daughterboard.

Run ERC, BOM export, netlist export, and PCB update from the corresponding board
project. The detailed sheet instances are excluded from BOM and board update so a
user cannot accidentally create one mixed PCB from the complete-system view.
The page-1 connector representations are also excluded; their purpose is to
document exact system wiring between the three board netlists and field wiring.

Regenerate and validate with:

```sh
PYTHONPATH=/tmp/radxa-cm5-kicad-deps \
  python3 cad/kicad/SYSTEM/generate_system_schematic.py
python3 cad/kicad/SYSTEM/validate_system_schematic.py
```

The native 18-page whole-system PDF is
`../../../outputs/schematic-release-a1/Radxa-CM5-ProComm-Complete-Electrical-A2.pdf`.
The cover-plus-review master remains
`../../../outputs/schematic-release-a1/Radxa-CM5-ProComm-Schematic-Release-A1.pdf`.

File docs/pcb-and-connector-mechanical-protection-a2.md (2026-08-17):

# PCB And Connector Mechanical Protection A2

## Controlled Rule

Every user-accessible connector must transfer insertion, extraction, downward
push, cable-side load, and transport vibration into the 3.175 mm aluminum top
panel or the custom four-side frame. PCB laminate, solder joints, connector
pins, board-to-board connectors, and thermal pads are not structural members.

This rule applies even when a selected connector is electrically soldered to a
PCB. A panel flange, bulkhead nut, capture bracket, supported service
daughterboard, or backplate must provide the mechanical load path.

## Long-PCB Support Pattern

The controlled support coordinates are in
`../fabrication/mechanical-release/pcb-support-pattern-a2.csv` and are shown on
`../cad/mechanical/im2300-underside-pcb-floorplan-rev-l.svg`.

- AUDIO-8X8: six supports `A1` through `A6` in three two-point rows.
- CM5-CARRIER: six supports `C1` through `C6` at four Y stations so the
  center/right supports clear the modem and CM5 cooling cartridges.
- SIM-SERVICE: four matched support pairs `SD1/S1` through `SD4/S4` use
  2.50 +/-0.05 mm precision sleeves between the carrier and daughterboard.
  These are additional to the six primary carrier standoffs.
- Maximum longitudinal distance between support rows: 128 mm.
- PCB mounting hole: 3.4 mm finished NPTH for M3 hardware.
- All-layer copper keepout: 8.0 mm diameter, centered on each hole.
- Component/body keepout: 10.0 mm diameter, both PCB sides.
- Hardware: rigid captive metal M3 standoff at the panel underside with an M3
  SEMS or captive-washer screw and a field-serviceable prevailing-torque or
  locking feature.
- The NPTH and copper keepout isolate the PCB from the standoff. Any chassis
  connection must be a separate intentional bond with its own net and hardware.

Do not replace the rigid standoffs with soft rubber PCB mounts. Case shock
isolation is provided between the panel and custom support frame by the
released EPDM/silicone strip. The connector-to-PCB stack must remain rigidly
aligned.

The support coordinates are pre-routing datums. Confirm standoff height, panel
flatness, connector Z stack, and tool access on a mechanical coupon before
locking the board outline.

## Connector Load Paths

The machine-readable matrix is
`../fabrication/mechanical-release/connector-load-path-a2.csv`.

### XLR Bank

Install both flange screws on every Neutrik XLR. The flange carries mating and
downward loads into the top panel; the six AUDIO-8X8 standoffs preserve PCB
alignment. The solder pins must not clamp the panel or carry panel preload.

### RJ45 Bank

The Bel vertical MagJacks require a custom four-port capture bracket because a
clearance hole alone would leave the solder joints carrying plug forces. Use a
2.0 mm 5052-H32 bracket fixed to the panel/frame that positively restrains the
MagJack bodies in insertion, extraction, and downward directions. Assemble
with zero preload on the carrier PCB. Release the bracket only after a coupon
test using actual MagJacks and latched Ethernet plugs.

### Headset And SIM Service

Mount the CTIA headset jack on a small four-M3-supported service daughterboard
with a panel capture bezel. Mount both Nano-SIM holders on the horizontal
76 x 40 mm SIM-SERVICE board. Its B.Cu Hirose
`DF40HC(2.5)-20DS-0.4V(51)` receptacle plugs directly into carrier J702
`DF40C-20DP-0.4V(51)`. Four aligned 2.50 mm precision spacer sleeves and the
panel guide carry all card and vibration load. The DF40 pair carries signals
only, and no SIM cable harness is permitted.

### Other Panel Interfaces

C14, LEMO, rocker, panel lights, touch switch, status indicators, RF bulkheads,
and the Gold Mount dock are panel/frame hardware. Use every specified flange
fastener, nut, anti-rotation feature, or backplate. Clamp each rear harness near
the interface so cable motion cannot reach a PCB header.

The internal HDMI, USB-touch, and 12 V display harness uses two-stage strain
relief: one clamp near the carrier and one at the hinge corridor. Maintain a
service loop that permits at least 300 mm panel lift and full lid travel without
loading a connector.

## Factory Inspection

1. Verify every `A1-A6`, `C1-C6`, and carrier-side `SD1-SD4` coordinate against
   the support CSV. Verify daughterboard `S1-S4` against the SIM stack drawing.
2. Confirm the twelve primary long-board holes and all eight matched
   SIM-stack holes are 3.4 mm NPTH and free of copper within 8.0 mm diameter.
   Gauge the four SIM spacer sleeves at 2.50 +/-0.05 mm before assembly.
3. Torque and witness-mark all PCB, flange, bracket, bulkhead, and backplate
   fasteners; keep these fastener systems independent.
4. Measure worst-case mating, unmating, and downward hand force with actual
   plugs/cards, then proof the released fixture at twice each measured force in
   the corresponding axis. No visible PCB flex, connector-body movement,
   solder-joint loading, continuity interruption, or permanent panel set is
   allowed. Do not exceed a connector manufacturer's stated proof-load limit.
5. Mate SIM-SERVICE J1 straight down onto carrier J702 with the four sleeves in
   place. Reject any assembly that requires rocking, side load, or screw force
   to pull the Hirose pair into alignment. The socket is electrical only.
6. Perform the released vibration and transport tests with representative cable
   masses and with all heavy heatsink/fan assemblies mechanically restrained.

Routing remains blocked until the RJ45 capture bracket and headset/SIM service
daughterboard coupons are released and the actual panel/frame survey confirms
the controlled support coordinates.

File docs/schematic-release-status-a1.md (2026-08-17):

# Schematic Release Status A1

## Decision

**Electrical capture is complete. Engineering PCB layout is authorized.**

The native KiCad source consists of seventeen controlled sheets across
`PWR-SELECT`, `CM5-CARRIER`, `AUDIO-8X8`, and `SIM-SERVICE`. The complete deterministic review
gate passes without source drift. Open
`cad/kicad/SYSTEM/Radxa-CM5-ProComm-System.kicad_pro` for one native KiCad
entry point to the complete design. Page 1 is the real system electrical
interconnect and pages 2-18 contain the component-level circuits. Its system
representations cannot update a PCB.

## Passed Gates

- All four electrically authoritative board roots: `0 errors / 0 warnings`.
  Standalone child-sheet context findings match the review script's exact
  allowlist; any new or changed finding fails the gate.
- Complete-system project: page 1 contains 58 electrical symbols and 294 named
  pin interconnects; all seventeen source sheets are present, and its A2 PDF
  export contains exactly 18 pages.
- PWR-SELECT: zero ERC errors/warnings, 186 critical checks, 111 exact BOM
  components, reverse-polarity controls, source thresholds, telemetry ranges,
  current limit, and hold-up calculations pass.
- CM5-CARRIER/AUDIO-8X8 interface contract: 174 critical connector and control
  pin/net assignments pass.
- CM5 allocation: all 76 owned contacts reconcile across the generator,
  controlled workbook, official Radxa source, and exported netlist; 74 are
  connected and two are explicitly assigned no-connects.
- Power-Regulators-A1: 49 regulator, inductor, rail, source-current, and hold-up
  checks pass; the production BOM has 163 controlled rows.
- Thermal-IO: 22 part, sensor-grade, fan-protection, and hot-current checks pass.
- Network-PCIe: 30 controlled-part and architecture checks pass.
- WWAN-SIM: 21 modem, SIM, local supply-network, protection, and RF-harness
  checks pass.
- SIM-SERVICE: 6 direct socket, protected dual-SIM, and mechanical declaration
  checks pass.
- Display-Harness: 20 HDMI, USB touch, 12 V monitor, and IO-5 V checks pass.
- Audio-Control: 22 TDM, I2S1, ES8316, headset-amplifier, CTIA, and grounding
  checks pass.
- AUDIO-8X8: 581 checks across seven detailed sheets pass; the generated BOM
  has 553 rows.
- Cross-board XLR, fan, temperature, telemetry, source-control, TDM, and audio
  power assignments pass.

## Physical Gates Before Fabrication Release

The root-counted component audit covers 1200 unique schematic components. Ten routing blockers are
deliberately retained for physical evidence:

- AK5558VN exposed-pad/via/stencil coupon and X-ray signoff;
- AK4458VN exposed-pad/via/stencil coupon and X-ray signoff;
- eight Panasonic TQ2-12V relay insertion, seating, and pin-map signoffs.

The Kycon STX-353K7A-6N-KTTR headset jack is route-ready at the schematic level
but remains blocked from production until its sample, plated-hole, bezel,
switch-polarity, and CTIA coupon pass. Total production blockers: 11.

Mechanical A2 remains `HOLD_FOR_MEASUREMENT` for factory release. Rev L board
envelopes and the controlled A1-A6/C1-C6 plus SD1-SD4/S1-S4 support coordinates authorize
engineering placement and routing now. Exact connector Z datums, sidewall
machining, panel cut files, and final manufacturing outputs cannot be released
until M001-M080 is completed and the mechanical validator passes.

## Controlled Commands

```sh
cad/kicad/review_detailed_capture.sh
python3 cad/kicad/audit_footprint_readiness.py
python3 cad/kicad/audit_footprint_readiness.py --routing
python3 fabrication/mechanical-release/validate_mechanical_release.py --release
python3 fabrication/pcbway-release/validate_release.py --release
```

The last three release-mode commands are expected to fail until their physical
evidence is attached. Do not replace those failures with assumptions.

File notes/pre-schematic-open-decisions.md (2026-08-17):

# Pre-Schematic Open Decisions

## Purpose

This is the remaining decision list for progressing the Radxa CM5 ProComm A0
interface baseline into complete detailed schematics.

## Must Lock Before Detailed Capture

- CAD tool and release format are locked to native KiCad 10 projects under
  `cad/kicad/`. The A0 interboard contract is captured and machine-validated.
- Board strategy is locked: separate `PWR-SELECT`, `CM5-CARRIER`, and
  `AUDIO-8X8` low-voltage assemblies plus the commercial bottom-mounted PSU.
- Board stackup: likely 6 layers minimum, with impedance-controlled pairs for
  HDMI, USB 3, PCIe, Ethernet, and clean audio reference planes.
- Exact Radxa CM5 hardware revision and connector pinout.
- Display/touchscreen model is locked to JUNEBOX / DTM MALL Amazon ASIN
  `B0GK5X95D9`; still verify exact brightness/current draw, bezel, connector
  orientation, mounting hardware, and lid harness on the received sample.
- Ethernet is locked to Rev A 1 GbE: native WAN1 plus three `LAN7430`
  controllers behind `PI7C9X2G608GP` for WAN2/LAN1/LAN2. The same PCIe switch
  feeds the `AW7915-NP1` Mini PCIe 4T4R Wi-Fi AP validation module.
- ProComm-style cellular M.2 B-Key WWAN slot details: SIM8260G-M2 global 3052
  validation target, 3042/3052 retention, dual Nano-SIM, four cellular/GNSS RF
  paths, Radxa GPIO assignments, region/carrier bands, GNSS behavior, and
  peak-current 3.8 V-class rail.
- Bottom-panel PSU integration: locked MEAN WELL `RPS-400-24-C` production
  supply, top-panel fused no-switch C14 inlet, EMI/PE plan, service barrier,
  low-voltage harness route, remote-sense/status wiring decisions, and thermal
  validation using its 252 W convection-rated design basis.
- Power architecture baseline selected from
  `/Users/viewvision/Desktop/ProComm enclosure and PCB boards`: 24 V primary,
  D-Tap second, Gold Mount third, LTC4418 backup preselector, LTC4421 main
  selector, telemetry, and protected raw-DC output.
- C14 production starting part is Qualtek `719W-00/03`, fused and unswitched.
  Its official rating is 10 A / 250 Vac, not the previously requested literal
  15 A / 120 Vac marking. Accept that agency/nameplate difference or select a
  different inlet before mechanical release; also confirm panel fit,
  gasket/cover, and fuse coordination.
- Main power switch in KiCad: copy the ProComm E-Switch `RA812C1121` DPST
  arrangement as `SW201` through keyed four-wire harness `J204`. Pole A enables
  LTC4421 `SHDN_MAIN`; pole B enables LTC4418 `SHDN_PRE`. Do not put the switch
  inside the IEC inlet or route AC mains/high-current source rails through it.
- Regulator targets and starting ICs are locked in
  `rev-a-hardware-architecture.md`; complete detailed calculations, simulation,
  layout, efficiency, transient, EMI, and thermal proof for every rail.
- No-blink/no-mute transfer budget: source-selector timing, protected raw-DC
  hold-up, local rail hold-up, regulator UVLO/dropout, display 12 V buck-boost,
  and oscilloscope acceptance limits.
- Thermal architecture is locked to a filtered right-wall intake, an
  operator-wall center-right exhaust, and downward-facing CM5/modem cooling
  cartridges. Complete wall measurements, baffles, guards, and 151.7 W
  closed-case validation; use a sealed heat exchanger if reduced sealing is
  unacceptable.
- Fans are locked to four independent 12 V PWM/tach channels controlled by an
  `EMC2305`. The two sidewall enclosure fans are Delta
  `THA0412AD-TZW3`; use one Qualtek `09150-F/30` filter guard on the intake and
  a Qualtek `09150-G` guard with custom downward splash hood on exhaust. Use
  Delta `AFB0412SHB-SP04` for the modem fan and place three
  `TMP117` sensors. Enclosure fan 1 is filtered
  right-wall intake and enclosure fan 2 is operator-wall exhaust. Baffles must
  route air through the hot zones. Keep fan/PWM wiring out of the XLR quiet zone
  and guarded hinge-side PSU corridor. The PSU guard stays at least 125 mm from
  the audio boundary, and the protected H03 lid-harness envelope stays at least
  15 mm from the guard through service motion.
- Top-panel mechanical layout inside the source-checked 17.00 in x 11.733 in
  nominal base bezel reference: XLR bank position, network/power/service
  connector positions, antenna placement, vents, labels, and service clearance.

## Audio Decisions

- XLR bank order is selected from the photo reference: two vertical columns,
  eight rows, left male outputs `CH1 OUT`-`CH8 OUT`, right female inputs
  `CH1 IN`-`CH8 IN`.
- XLR size source is selected from
  `/Users/viewvision/Desktop/2026/ProComm PCB XLRs + Transformer`: Neutrik
  `NC3MAV` outputs and `NC3FAV` inputs, starting from 28 mm row pitch,
  43.38 mm circular-center column spacing, and 22.8 mm reference circle
  diameter. Preserve 15.0 mm (0.59 in) from the finished left panel edge to the
  XLR bank outer edge so the bank clears the four-side frame boundary.
- Still confirm official panel cutouts, STEP models, latch-tab orientation, and
  whether the 28 mm pitch leaves enough room for labels under each connector.
- Audio level is locked to +4 dBu nominal and +24 dBu maximum, 10 kohm normal
  load, 600 ohm compatibility/test load, line level only, and no phantom power.
- Confirm AK5558VN/AK4458VN clocking: CM5 master first, external master clock
  option only if needed.
- Confirm sample rates for first bring-up: 48 kHz and 96 kHz.
- Define the audio stress-test target based on the prior Raspberry Pi issue:
  no silent audio, no lost sync, and no unrecovered ALSA xruns during CPU,
  network, Wi-Fi AP, cellular, HDMI/touch, and storage load spikes.
- Confirm balanced input receiver/output driver parts and analog supply rails.
- Define audio ground/chassis bonding, connector shield treatment, and ESD/RFI
  protection at every XLR.
- Define mute/pop protection for outputs during boot, reset, shutdown, and
  source switchover.
- Confirm ES8316 headset jack standard, likely CTIA TRRS, with headphone
  amplifier/driver, mic bias/preamp/input conditioning, headphone detect, ESD
  protection, dedicated headset regulator, mute/pop behavior, and software
  mixer routing.

## System I/O Decisions

- Debug UART is an internal keyed 3.3 V header; select its exact location.
- USB recovery must remain panel/service accessible. Reset/recovery buttons
  stay internal or on the PCB underside and must remain reachable during service
  without removing the main carrier.
- External service USB ports and current limits.
- Status LED functions are selected; finish color, drive, light-pipe, label,
  and panel location details. Top-panel indicators are now the Bulgin `DX06`
  12 V wire-lead family listed in `panel-mounted-parts-selection.md`.
- The two top-facing SIM openings use a horizontal 76 x 40 mm SIM-SERVICE
  daughterboard. It plugs directly into carrier J702 through a 20-pin Hirose
  DF40 2.5 mm stack and is restrained by four matched M3 supports.
- RTC battery or supercap requirement.
- Hardware watchdog requirement.
- Factory-test pads and programming headers.

## Software Decisions

- Target OS: Radxa Debian/Ubuntu, OpenWrt-derived image, or custom Linux build.
- Device tree plan for I2S0 TDM, I2S1 headset codec, PCIe, USB, fan PWM/tach,
  LEDs, buttons, and recovery controls.
- ALSA naming and channel map for 8x8 program audio plus headset.
- Audio runtime policy: CPU governor, IRQ affinity, buffer sizes, real-time
  scheduling, watchdog/recovery behavior, and logging for TDM underruns.
- Accelerator policy selected: use GPU for HDMI touchscreen UI, meters,
  waveform/spectrum display, and graphics; reserve NPU for future AI
  noise/classification and smart monitoring; keep I2S/TDM timing, ALSA DMA, and
  SIP/RTP real-time behavior on protected CPU/kernel paths.
- Router/firewall stack: `nftables`, NetworkManager, ModemManager, `hostapd`,
  and WAN failover policy.
- Factory provisioning flow for eMMC-only systems.

## Release Gates

- Electrical schematic ERC and manual review.
- No-blink power-transfer test: primary-to-backup and backup-to-primary under
  full system load with CM5, display, audio, Wi-Fi AP, cellular, Ethernet, and
  fans active.
- PCB DRC, impedance rules, and high-speed routing review.
- Mechanical 2D/3D fit check in the Pelican iM2300 with lid, panel, battery,
  XLR connectors, antennas, fans, and harnesses.
- Power, thermal, RF, audio-noise, Ethernet, Wi-Fi AP, cellular, HDMI/touch, and
  recovery tests on the acceptance prototype.

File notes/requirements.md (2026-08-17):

# Requirements Draft

## Board Intent

Custom carrier board for the Radxa CM5 module with multichannel TDM audio.

## Selected Requirements And Remaining Inputs

- CAD target:
- Board outline:
- PCB/board partition: separate `PWR-SELECT`, `CM5-CARRIER`, and `AUDIO-8X8`
  low-voltage boards plus the commercial AC/DC PSU
- Enclosure: Pelican Storm Case iM2300 with custom top panel and PCB mounted underneath
- Portable-field durability: panel, PCB standoffs, connector flanges, modules,
  heatsinks, fans, PSU, battery dock, and harnesses must withstand transport
  shock and vibration without PCB flex, connector-solder stress, loose
  fasteners, intermittent resets, audio dropouts, or cable damage
- Connector/top-panel source-checked envelope: 17.00 in x 11.733 in nominal base bezel reference (431.8 mm x 298.0 mm nominal)
- Power input: same ProComm source-selection architecture from
  `/Users/viewvision/Desktop/ProComm enclosure and PCB boards`, with internal
  bottom-panel MEAN WELL `RPS-400-24-C` 24 V AC/DC PSU as the locked production
  primary source,
  D-Tap / LEMO backup, and Gold Mount battery dock
- Power transfer: no interruption/no blink between primary and valid backup;
  CM5, HDMI touchscreen, main audio, headset, Ethernet, Wi-Fi, cellular, and fan
  control must ride through source transfer without reset or mute
- Full load budget: 151.7 W continuous design estimate and 184.2 W transient
  estimate; replace estimates with prototype measurements
- Storage/boot: CM5 eMMC only
- Main use case:
- Must-have interfaces:
- Audio converters: AK5558VN ADC and AK4458VN DAC over TDM
- Audio channel count: 8-channel capture and 8-channel playback
- Audio reliability: 8x8 TDM program audio must not mute, drop out, or lose
  clock sync during CPU, network, Wi-Fi AP, cellular, storage, or display load
  spikes.
- Main audio analog I/O: left-side two-column XLR bank like the photo reference, with CH1-CH8 OUT male XLRs in the left column and CH1-CH8 IN female XLRs in the right column; XLR size/spacing basis comes from `/Users/viewvision/Desktop/2026/ProComm PCB XLRs + Transformer`
- Headset audio: integrated 3.5 mm CTIA TRRS jack with headphone output and
  microphone input, using a separate ES8316-class codec plus headphone
  amplifier/driver, mic bias/preamp/input conditioning, and dedicated low-noise
  headset regulator
- Network ports: two wired WAN ports and two shared wired LAN ports
- Wireless: high-speed Wi-Fi AP broadcast for about 25 simultaneous devices
- Cellular: global-coverage modem WAN path for failover or policy routing
- Local display: locked lid-mounted 15.6-inch HDMI touchscreen, JUNEBOX Amazon
  ASIN `B0GK5X95D9`; 1920 x 1080 IPS, HDMI input, USB touch, 12 V display
  power rated 25 W / 2.08 A, locked 12 V / 2.5 A carrier branch, and rugged USB
  Type-B SuperSpeed panel/service connector where practical
- Night operation: two diffused 12 V warm-white courtesy lights above the Gold
  Mount zone, controlled together by one latching capacitive touch switch. The
  lighting target is approximately 3000 K with broad, low-glare coverage so
  connector colors and labels remain distinguishable. The lighting circuit is
  hardware-only, separately fused, and does not depend on
  the CM5, Linux, or a GPIO expander.
- Cooling: four fans total. The CM5 is mounted on carrier B.Cu with a downward-
  facing Radxa `5540A` and attached Delta `FFB0412EN-00Y2E`; a structural
  bracket carries fan mass/vibration and the inlet retains at least 10 mm floor
  clearance. The modem uses a similar downward heatsink/fan cartridge. Two
  Delta `THA0412AD-TZW3` 40 x 40 x 20 mm enclosure fans provide a filtered
  right-wall intake and operator-wall center-right exhaust. All four PWM/tach
  channels are board controlled; the top panel has no cooling openings.
- Thermal strategy: measured sidewall airflow through the digital/power hot
  zones with baffles, reinforcement plates, gaskets, and splash louvers; a
  sealed heat exchanger remains the fallback if field sealing is re-required
- Enclosure: Pelican Storm Case iM2300 with custom top panel and PCB mounted underneath
- Storage/boot: use CM5 eMMC only
- Recovery/provisioning: USB recovery, debug UART, and network provisioning
- Nice-to-have interfaces:
- Prototype quantity:
- PCB/assembly vendor:
- Enclosure or mounting constraints:

## Rev A Interface Set

Start from the Radxa CM5 IO reference design and remove anything not needed.

- Power input and sequencing
- Protected ProComm-style power-entry/source selector using internal `24V_PSU`
  > D-Tap > Gold Mount priority
- No-blink source transfer using PowerPath controllers, hold-up capacitance,
  wide-input regulators, and a buck-boost `DISPLAY_12V` rail if the display is
  powered from the carrier during backup operation
- Bottom-panel MEAN WELL `RPS-400-24-C` AC/DC PSU, 24 V / 10.5 A / 252 W
  convection-rated design basis, with top-panel fused C14 inlet, no integrated
  inlet switch, EMI/PE treatment, service barrier, and low-voltage harness to
  the carrier/source-selector assembly
- Backup inlet based on 15 A LEMO `EGG.1B.302.CLL`, 13.0-16.8 V operating
  range; any D-Tap source cable must also carry the measured backup load
- Gold Mount battery dock based on Anton/Bauer Dionic XT 90 and user-locked
  QRC-GOLD bracket `8375-0094`; the dock mounts only to the top panel/custom
  frame and connects by a strain-relieved removable harness to the
  power-selector PCB; production release requires sample-verified mounting,
  latch travel, polarity, release sweep, and 12 A thermal performance
- CM5 board-to-board connectors
- Debug UART
- USB recovery/service connector or external USB-C recovery path
- Recovery/reset controls as required by CM5 boot flow
- 8-channel balanced TDM audio using AK5558VN and AK4458VN
- Left-side XLR bank: two vertical columns and eight rows; CH1 at top, CH8 at bottom; left column Neutrik `NC3MAV`-size male outputs, right column Neutrik `NC3FAV`-size female inputs; start from the legacy board's 28 mm row pitch and 43.38 mm circular-center column spacing; 15.0 mm / 0.59 in clearance from the finished left panel edge to the XLR bank outer edge
- 3.5 mm headset jack using ES8316-class stereo codec on separate I2S bus, with
  headset headphone amplifier/driver, mic bias/preamp/input conditioning, and
  a dedicated headset regulator
- Native CM5 1 GbE WAN1 plus `PI7C9X2G608GP` and three `LAN7430` controllers
  for 1 GbE WAN2/LAN1/LAN2
- Dedicated Mini PCIe `AW7915-NP1` true 4T4R Wi-Fi AP module with four antennas
- Separate dedicated Wi-Fi AP power rail
- Universal M.2 B-Key WWAN cellular modem socket with USB 2.0/USB 3.x, dual
  Nano-SIM support, and 3042/3052 mechanical support
- Separate dedicated cellular modem power rail
- HDMI display output for locked 15.6-inch HDMI touchscreen
- USB host port for touchscreen touch controller, with USB Type-B SuperSpeed
  panel/service connector preferred for the product interface where practical
- Lid-to-base HDMI/USB/display-power harness through one centered notch that
  opens directly at the top panel's hinge edge
- USB 2.0/3.0
- Locked Delta `FFB0412EN-00Y2E` CPU-fan power, PWM, and tach control
- Dedicated Delta `AFB0412SHB-SP04` cellular modem fan header/control and
  module-specific modem heatsink/thermal spreader
- Two board/enclosure fan headers controlled by board temperature sensors
- RTC battery
- Six system-status LEDs plus two night-illumination LEDs and one touch
  on/off control

## Early Risk Items

- Verify the exact CM5 hardware revision and pinout before assigning connector pins.
- Keep all GPIO at 3.3 V max unless the Radxa docs specify a lower limit; SARADC is lower voltage.
- Keep the headset codec off `I2S0`; that bus is reserved for the AK5558VN/AK4458VN TDM converters.
- Prior Raspberry Pi testing showed I2S audio could go silent during CPU spikes;
  treat TDM underrun/xrun recovery and long-duration stress testing as a
  product requirement, not a bring-up detail.
- High-speed interfaces need controlled impedance, length matching, clean reference planes, and connector-specific routing rules.
- Multi-port Ethernet and Wi-Fi AP support likely require PCIe resource planning before finalizing the board outline.
- Cellular modem requires global-band validation, peak-current power design, SIM ESD/protection, RF antenna placement, carrier/regulatory planning, and a universal M.2 B-Key WWAN socket approach.
- HDMI and USB touchscreen routing need ESD protection, connector placement,
  and enough 12 V accessory power for the selected 15.6-inch display/touch
  assembly.
- Lid-mounted touchscreen needs hinge-safe harness routing, strain relief, and
  enough clearance when the case opens/closes. Keep the actual HDMI,
  USB-touch, and 12 V cable envelope at least 15 mm from the grounded PSU guard
  through full lid and panel-service motion.
- Fan control needs PWM/tach GPIO allocation, current budget, acoustic planning,
  one modem-zone sensor placement, and at least two board temperature sensor
  placements for the two board/enclosure fans.
- eMMC-only boot means USB recovery, network provisioning, and debug UART must be available.
- Power input and load switch/current-limit choices need to match peak CM5 and peripheral current.
- The locked `RPS-400-24-C` PSU must be validated mechanically and thermally in
  the iM2300; use the 252 W convection rating unless forced-air PSU cooling is
  intentionally designed and tested. Its guarded floor bay is on the
  hinge/display side, rotated 90 degrees in plan, with 146 mm nominal and 125
  mm minimum separation from the AUDIO-8X8 quiet boundary.
- AC mains entry requires a fused C14 inlet with no built-in rocker switch, PE bonding, guarded service isolation, strain relief, and separation from audio/RF/high-speed low-voltage wiring.
- Qualtek `719W-00/03` is the production C14 starting part; RS PRO `811-7204`
  remains only the fused/no-switch panel-style reference. Do not claim a 15 A
  marking unless the final ordered part and agency file support it. The current
  Qualtek drawing specifies 10 A / 250 Vac.
- ProComm source-selection architecture is selected as the baseline, but the
  Radxa load budget, regulator sizing, hold-up capacitance, MOSFET SOA, fusing,
  telemetry scaling, and thermal validation still need to be recalculated.
- No-blink transfer must be measured under full system load; do not accept a
  schematic-only claim of seamless switchover.
- LAN7430, PCIe switch, Wi-Fi AP module, cellular modem, and SIM circuits must
  use the exact voltages, sequencing, current limits, and protection required
  by their selected datasheets.
- Mechanical placement must respect CM5 connector stack height, keepouts, antenna clearances, and mounting holes.
- XLR placement should use the extracted legacy ProComm XLR geometry in `notes/xlr-bank-reference.md`, then verify final Neutrik mechanical drawings, latch orientation, panel cutouts, and label clearance.
- Top-panel connector placement must fit inside the source-checked 17.00 in x 11.733 in nominal base bezel reference after real connector cutouts, cable clearance, panel fasteners, gasket/lip, and case taper are included.
- Top panel layout should follow the existing ProComm field unit reference: left-side XLR audio connector bank, headset/service area, antennas, vents, and right-side electronics area.
- Top-facing SIM access uses the controlled horizontal SIM-SERVICE
  daughterboard, insulating panel guide, four structural M3 supports, and
  direct 20-pin Hirose DF40 connection to the carrier. No SIM harness is used.
- Pelican iM2300 starts sealed, but the selected sidewall intake/exhaust makes
  this product intentionally vented. Validate ingress and 45 C thermal behavior.

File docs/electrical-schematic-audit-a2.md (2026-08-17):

# Electrical Schematic Audit A2

## Decision

**SCHEMATIC ELECTRICAL REVIEW PASS / ENGINEERING PCB LAYOUT AUTHORIZED**

The three electrically authoritative KiCad board roots currently pass ERC with
`0 errors / 0 warnings`:

- `cad/kicad/PWR-SELECT/PowerSelector.kicad_sch`
- `cad/kicad/CM5-CARRIER/CM5-Carrier.kicad_sch`
- `cad/kicad/AUDIO-8X8/Audio-8x8.kicad_sch`

The system overview is a navigation and documentation sheet. It is not a PCB
netlist and must not be substituted for any of those roots. Standalone child
sheets lack their parent-sheet power drivers and interface context; their
expected findings are checked against an exact allowlist by
`cad/kicad/review_detailed_capture.sh`. Any changed finding fails the review.

This pass means the captured electrical logic is internally consistent and
matches the controlled source documents listed below. It does not prove that a
first article will have zero failures. PCB signal/power integrity, regulator
stability, thermal behavior, source transfer, EMC, safety, harnesses, and
mechanical fit still require layout review and measured qualification.

## Datasheet Corrections Closed

1. Reconciled all 76 owned CM5 contacts across the generator, controlled
   workbook, official Radxa V2.21 workbook, and exported KiCad netlist. Seventy
   four contacts are connected and two are explicitly assigned no-connects:
   unused WAN1 `LED2` and unused HDMI `SBDN/HEAC-N`.
2. Separated the CM5 PCIe reset request from the hardware-qualified switch
   reset. The PI7C9X2G608GP can leave reset only when the CM5 command,
   `NET_3V3_PG`, and `PCIE_1V0_PG` are all valid.
3. Added the RM520N-GL socket-local low-band VCC network: two 220 uF polymer
   capacitors, the specified high-frequency capacitor ladder, and an
   SMF4L5.0AT1G TVS at the M.2 power pins. The regulator board's upstream bulk
   does not replace these local parts.
4. Tied each LAN7430 `VAUX_DET` low to disable unsupported D3cold PME and left
   `ADV_PM_DISABLE` open so its internal pull-down retains advanced power
   management. Verified PCIe AC coupling, reference clocks, reset, local rails,
   and Ethernet front ends.
5. Qualified the AW7915-NP1 interface as a 4T4R Mini PCIe endpoint on a
   dedicated 3.3 V / 4 A rail. The vendor specifies 9.1 W maximum and recommends
   a 3.5 A supply capability, so the captured rail has startup margin.
6. Corrected AK5558VN and AK4458VN supply/reference capture and added a hardware
   fail-silent gate: DAC unmute and output-relay enable require both ADC and DAC
   power-good signals.
7. Corrected the ES8316 I2C level-shifter bias, retained the CTIA headset map,
   and kept headset, AKM, and line-stage power on their controlled clean rails.
8. Verified power-good sequencing, load-switch default pulldowns, telemetry,
   fan control, temperature sensing, HDMI/USB protection, and cross-board TDM,
   power, fan, XLR, and chassis-ground contracts.

## Automated Evidence

| Gate | Result |
| --- | --- |
| Authoritative board-root ERC | Three roots, each `0 errors / 0 warnings` |
| PWR-SELECT validator | 186 checks, 0 failures |
| CM5 pin-allocation validator | 9 checks, 0 failures |
| Power-regulator validator | 49 checks, 0 failures |
| Network/PCIe validator | 29 checks, 0 failures |
| WWAN/SIM validator | 23 checks, 0 failures |
| Display validator | 20 checks, 0 failures |
| Audio-control validator | 22 checks, 0 failures |
| Thermal/fan validator | 22 checks, 0 failures |
| AUDIO-8X8 validator | 581 checks, 0 failures |
| Cross-board interface validator | 174 pin/net checks, 0 failures |
| System-project validator | 58 electrical symbols, 294 named interconnects, all 13 child sheets exposed |
| Full release export | 17 reviewed PDF pages |
| Root-counted footprint audit | 1203 unique components; 10 routing blockers and 11 production blockers |

The generated review files under each board's `REVIEW` folder are controlled
evidence. Run the full gate after every generated or manual schematic change:

```sh
cad/kicad/review_detailed_capture.sh
```

Release-mode checks were also exercised during this audit. They remain blocked
for the intended physical work, not for an additional captured electrical
error: the routing audit reports ten unresolved footprint coupons, the
mechanical release reports 37 missing measurement/signoff records, and the
PCBWay package reports 54 open or missing package rows including the three
unrouted PCB sources and harness test evidence. These holds must remain active
until the listed evidence exists.

## Mandatory Holds

| Hold | Required evidence before release |
| --- | --- |
| AK5558VN and AK4458VN lands | Exposed-pad, via, paste, stencil, assembly, and X-ray coupon approval |
| Eight Panasonic TQ2 relay lands | Pin map, insertion, seating, solder, and physical coupon approval |
| Kycon headset jack | Physical sample, plated holes, bezel, CTIA map, and detect-switch polarity |
| Wi-Fi and WWAN sockets/modules | 3D/sample fit, rail transient capture, thermal interface, antenna map, and regulatory integration review |
| PCB routing | Controlled stackup, PCIe/USB/HDMI/TDM impedance, return paths, length matching, crosstalk, via budget, and SI review |
| Power integrity | DC drop, plane/via current, regulator compensation, startup, current limit, load step, and worst-tolerance review |
| Backup operation | Oscilloscope proof of no reset, display blink, audio mute, or network reset during source transfer |
| Battery limit | Firmware load shedding below the controlled battery threshold; 151.7 W at 11.35 V is 13.37 A, above the 12 A continuous battery rating |
| Thermal | Closed-enclosure 45 C / 113 F chamber run at simultaneous CPU/GPU/NPU, Wi-Fi, cellular, display, audio, and fan load |
| Audio | All 16 channels at +4 dBu nominal, +24 dBu maximum, 600 ohm compatibility, noise, THD+N, crosstalk, mute, and fault tests |
| Safety and EMC | PE/chassis continuity, mains barrier, creepage/clearance, fuse/abnormal test, ESD/EFT/surge, radiated/conducted emissions and immunity |
| Mechanics | Actual case, monitor, folded antennas, sidewall fans, panel, PCB supports, connector insertion loads, vibration, and lid-closure validation |

The 184.2 W short transient at 11.35 V is 16.23 A and must not be treated as a
sustainable battery operating point. The locked 24 V RPS-400-24-C supply has
adequate nominal wattage for the 151.7 W continuous design case, but its final
temperature and airflow remain qualification items.

## Controlled Primary Sources

- Radxa CM5 design files and V2.21 pin allocation:
  https://docs.radxa.com/en/som/cm/cm5/download
- Radxa CM5 IO V2.2 schematic, including the ES8316 reference implementation:
  https://dl.radxa.com/cm5/radxa_cm5_io_board_v2200_schematic.pdf
- Microchip LAN7430/LAN7431 data sheet:
  https://ww1.microchip.com/downloads/aemDocuments/documents/UNG/ProductDocuments/DataSheets/LAN7430-LAN7431-Data-Sheet-DS00002631.pdf
- AsiaRF AW7915-NP1 data sheet:
  https://asiarf.com/wp-content/uploads/2023/09/AW7915-NP1_V1231004.pdf
- Quectel RM520N hardware design guide used for the socket-local VCC network:
  https://forums.quectel.com/uploads/short-url/1zkjPRnxF5BZ2woox386baCZx4g.pdf
- Littelfuse SMF4L5.0AT1G product data:
  https://www.littelfuse.com/products/overvoltage-protection/tvs-diodes/surface-mount/smf4l-t1g/smf4l5-0at1g
- Texas Instruments SN74LVC1G11, TPS62913, TPS25982, and TPS22990 data sheets:
  https://www.ti.com/lit/ds/symlink/sn74lvc1g11.pdf
  https://www.ti.com/lit/ds/symlink/tps62913.pdf
  https://www.ti.com/lit/ds/symlink/tps25982.pdf
  https://www.ti.com/lit/ds/symlink/tps22990.pdf
- NXP PCA9306 data sheet:
  https://www.nxp.com/docs/en/data-sheet/PCA9306.pdf
- Analog Devices LT3045 data sheet:
  https://www.analog.com/media/en/technical-documentation/data-sheets/3045fa.pdf

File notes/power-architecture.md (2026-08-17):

# Power Architecture

## Decision

Use the same ProComm power/source-selection architecture from
`/Users/viewvision/Desktop/ProComm enclosure and PCB boards` as the Radxa CM5
baseline, with a locked internal bottom-mounted MEAN WELL `RPS-400-24-C` 24 V
AC/DC PSU as the primary 24 V source.

Mechanical location is locked to a guarded bay along the hinge/display side of
the case bottom. Keep both enclosure fans and all fan PWM/power wiring outside
this bay and outside the XLR analog quiet zone.

The ProComm source-selection architecture is reused intentionally: protected
24 V first, D-Tap second, Gold Mount third, LTC4418 backup preselector, LTC4421
main selector, back-to-back MOSFET blocking, fusing/protection, telemetry, and
a protected raw-DC output feeding the carrier regulators.

Rev A telemetry is now captured with three `INA228AIDGSR` monitors: primary at
`0x40`, selected backup at `0x41`, and delivered `RAW_OUT_LOAD` at `0x44`.
PWR-SELECT `J402` mates with CM5-CARRIER `J103` on the 3.3 V control I2C bus.
The software and future-release requirements are controlled in
`../docs/power-telemetry-software-spec.md`.

Radxa changes are downstream of the protected raw-DC output. The A1
regulator/load starting values are calculated for the Radxa CM5, HDMI
touchscreen, 8x8 AKM audio, Wi-Fi AP, cellular modem, Ethernet ports, headset
codec, and four fans. Final limits remain subject to measured module loads,
loop-response, efficiency, thermal, source-transfer, and fault validation.

Power reference files:

- `/Users/viewvision/Desktop/ProComm enclosure and PCB boards/POWER_ARCHITECTURE.md`
- `/Users/viewvision/Desktop/ProComm enclosure and PCB boards/ADVANCED_SCHEMATIC_WORK/POWER_ARCHITECTURE.md`
- `/Users/viewvision/Desktop/ProComm enclosure and PCB boards/ADVANCED_SCHEMATIC_WORK/POWER_SELECTOR_README.md`
- `/Users/viewvision/Desktop/ProComm enclosure and PCB boards/PCB_SOURCE/POWER_SELECTOR_24V_BATTERY`
- `/Users/viewvision/Desktop/ProComm enclosure and PCB boards/PCB_SOURCE/POWER_SELECTOR_24V_BATTERY/PowerSelector.kicad_sch`
- Controlled local baseline: `cad/kicad/PWR-SELECT/BASELINE_SOURCE.md`
- Current local A0 ERC: `cad/kicad/PWR-SELECT/REVIEW/PowerSelector-A0-ERC.rpt`
- Local Radxa budget note: `power-budget.md`

## Source Priority

Power-source priority:

1. Internal 24 V AC/DC PSU output
2. D-Tap / 2-pin LEMO alternate backup input
3. Gold Mount battery dock

The D-Tap and Gold Mount sources are never paralleled. A valid D-Tap source
takes priority over the Gold Mount battery. The internal 24 V PSU takes
priority over both backup sources.

## No-Blink Transfer Requirement

Power transfer between the primary 24 V PSU and a valid backup source must not
interrupt the product. The design target is no CM5 reset, no touchscreen blink,
no audio mute/click, no Ethernet/Wi-Fi/cellular reset, and no fan-controller
reset during source transfer.

This is a hard requirement only when a valid backup source is present before
the primary source is removed. If no backup source is valid, the unit may shut
down gracefully.

Implementation rule:

- Use the cascaded `LTC4418` and `LTC4421` source-selection architecture with
  correctly sized back-to-back MOSFETs, sense resistors, UV/OV thresholds,
  validation delays, and current-limit timers.
- Rate the low-voltage source path for at least 15 A and recalculate the old
  10 A-class sense setting for at least a 14 A operating threshold after
  tolerance analysis.
- Use the floor-mounted 27,200 uF nominal / 50 V protected raw-DC bank plus
  660 uF local storage after the source selector, with controlled precharge.
- Add local hold-up on critical downstream rails.
- Ensure every regulator remains in regulation across 24 V PSU operation,
  13.0-16.8 V D-Tap/LEMO operation, Gold Mount operation, wiring drop,
  MOSFET/fuse/eFuse drop, and transfer droop.
- Use a buck-boost or equivalent topology for `DISPLAY_12V` if the display must
  remain at 12 V during battery operation and source transfer.
- Do not shed noncritical loads until after the transfer is complete and the
  system has logged the new power source.

Detailed local note: `no-blink-power-transfer.md`.

The existing ProComm implementation already captures the intended behavior as a
Rev C schematic in
`/Users/viewvision/Desktop/ProComm enclosure and PCB boards/PCB_SOURCE/POWER_SELECTOR_24V_BATTERY`.
Use that schematic as the electrical starting point, not the older rejected
power board. Do not order or copy it unchanged for Radxa; the A1 capture adapts
the Radxa load, primary PSU, display rail, connector partition, source-current
telemetry, and hold-up bank. MOSFET SOA, inrush, tolerance, thermal behavior,
and no-blink transfer still require release testing.

## Power Path

```text
Top-panel fused C14 inlet, no switch -- EMI/PE -- bottom-mounted RPS-400-24-C PSU -- 24V_PSU -- protection --\
                                                                                                                > LTC4421 main selector -- protected raw DC -- carrier regulators -- system rails
LEMO EGG.1B.302.CLL backup inlet 13.0-16.8 V -- protection --\                       /
                                      > LTC4418 backup preselector -- BAT_SELECTED --/
Gold Mount battery ---- protection --/
```

Downstream rail split:

```text
protected raw DC
  -> main 4.006 V / 12 A CM5 rail
  -> dedicated 4.984 V / 2 A CM5 HDMI, HDMI connector, and touch-USB rail
  -> separate 3.3 V Wi-Fi AP rail
  -> separate 3.8 V-class cellular modem rail
  -> clean audio analog/digital rails
  -> display/touch power rail, buck-boost if 12 V must ride through backup
  -> fan power rail, buck-boost if 12 V fans must ride through backup
  -> Ethernet controller/switch rails
```

The Wi-Fi AP rail and cellular modem rail are separate supplies. They must not
share one undersized 3.3 V peripheral rail, because radio transmit bursts can
pull down or inject noise into the rest of the system.

See `power-budget.md` for the current first-pass load table. The locked
production PSU basis is the `RPS-400-24-C` used at its 24 V / 10.5 A / 252 W
convection rating unless forced-air PSU cooling is intentionally designed and
validated.

## Primary 24 V AC/DC PSU

Locked production PSU:

- PSU: MEAN WELL `RPS-400-24-C`
- Type: covered/enclosed, chassis-mount AC/DC converter
- Mounting: guarded hinge/display-side bay on the bottom panel, not the top panel
- AC input: 80-264 Vac universal input
- DC output design basis: 24 V, 10.5 A, 252 W convection-rated
- Forced-air rating: about 400 W class; do not claim or depend on this unless
  validated PSU airflow and heat exit are designed into the enclosure
- Mechanical envelope: about 130 x 86 x 43 mm
- Useful support outputs/signals: 5 V standby, 12 V fan output, power-good/fail,
  remote sense
- Cooling: use the 252 W convection rating for the sealed iM2300 design basis;
  temperature rise must still be tested with the final hinge-side mounting
  and internal airflow pattern
- Safety class: design as a Class I installation unless a full Class II
  integration is intentionally engineered; bond PSU metal case/chassis to PE

The top panel carries the PCB/connector panel plus the selected IEC C14 mains
inlet. Do not mount the AC/DC PSU on the top panel. The PSU remains on the
bottom panel and feeds the carrier/source-selector assembly through a protected
  low-voltage `24V_PSU` harness. Rotate the PSU 90 degrees in plan and keep its
  grounded guard at least 125 mm from the AUDIO-8X8 quiet boundary; the current
  nominal floorplan provides 146 mm. Keep the H03 HDMI/USB-touch/12 V cable
  envelope at least 15 mm from that guard and never share its clamps with mains
  or fan wiring.

## Top Panel AC Mains Inlet

Locked style and production starting part:

- Required style: IEC 60320 C14 male appliance inlet with integrated fuse
  holder and no built-in switch
- Production starting part: Qualtek `719W-00/03`
- Rating: 10 A, 250 Vac
- Fuse holder: one active 5 x 20 mm fuse position and one spare
- Termination: 4.8 mm quick-connect tabs
- Mounting: flanged panel mount
- Manufacturer-listed approvals: UL, CSA, TUV, and CCC; confirm the ordered
  suffix and current agency file at release
- Panel/style reference retained: RS PRO `811-7204`

Do not use the switched C14 module direction. The IEC inlet should not contain
a rocker switch. The user/system power switch remains the separate low-current
selector-enable switch described below.

The selected 10 A/250 Vac inlet is sufficient for the `RPS-400-24-C` input
current. Do not print or advertise a separate 15 A/125 Vac inlet rating unless
the final ordered connector and agency file explicitly support that claim.

Use a gasketed cover or sealed external door around the inlet if the product
must retain its rugged sealing rating. The inlet alone is not the enclosure
seal.

The AC side needs its own mechanical/electrical integration:

- Top-panel fused C14 inlet, strain relief, optional interlock, and EMI filter
- Protective-earth/chassis bond near the inlet and PSU mounting
- Mains wiring from the top-panel inlet to the hinge-side bottom PSU kept short,
  guarded, strain-relieved, and physically separated from audio, RF, Ethernet,
  HDMI, USB, fan, and low-voltage harnesses
- Finger-safe guard/cover or service barrier around AC terminals and exposed
  mains wiring
- Creepage/clearance, wire gauge, connector current rating, pull test, and
  safety-label plan reviewed before any powered prototype

The previous Bel/CUI `VOF-120C-24-CNF` 120 W PSU is no longer the production
baseline. Keep it only as a prior candidate/prototype reference if needed.

The previous ProComm external MEAN WELL `GST120A24-R7B` / Kycon `KPJX-4S-S`
24 V inlet approach is now a fallback/reference only, not the selected primary
source for this Radxa CM5 build.

## Production PSU Direction

The MEAN WELL `RPS-400-24-C` is locked as the production PSU baseline. Treat
the 252 W convection rating as the design rating for the sealed iM2300 unless
forced-air PSU cooling is intentionally added and verified.

Recommended production target:

- Primary candidate: MEAN WELL `RPS-400-24-C`
- Output for our sealed/recirculating design basis: 24 V, 10.5 A, 252 W
  convection-rated
- Forced-air rating: about 400 W class, but do not claim or depend on this
  unless the enclosure design provides validated PSU airflow and thermal exit
- Input: 80-264 Vac universal
- Type: covered/enclosed medical AC/DC supply, chassis mount
- Size: about 130 x 86 x 43 mm
- Useful extras: 5 V standby, 12 V fan output, remote sense, power-good/fail
  signals
- Why: gives better margin than the 200 W candidates while staying close to
  the same bottom-panel footprint class.

Mechanical A2 release limits the complete tray-mounted PSU and terminal guard
to 48 mm above the deepest case floor and requires 10 mm minimum vertical
clearance to carrier B.Cu. The covered supply derates with ambient temperature:
direct a low-velocity branch of clean intake air through the perforated guard,
measure PSU inlet air, and keep it at or below 50 C during the 45 C ambient,
151.7 W continuous qualification. Do not treat the guard as a sealed box.

Good alternate:

- TDK-Lambda `CUS200M-24/A`
- Output: 24 V, 8.4 A, 200 W convection / 250 W forced-air class
- Input: 85-265 Vac universal
- Type: enclosed / chassis mount
- Size: 139.7 x 90.0 x 43.0 mm
- Why: high-quality production alternate with useful headroom above the current
  151.7 W continuous estimate and 184.2 W transient estimate.

Compact open-frame variant:

- TDK-Lambda `CUS200M-24`
- Output: 24 V, 8.4 A, 200 W convection / 250 W forced-air class
- Input: 85-265 Vac universal
- Type: open frame / chassis mount
- Size: 127.0 x 76.2 x 31.0 mm
- Use only if the product design adds a proper finger-safe AC/service barrier,
  mounting standoffs, strain relief, and isolation from low-voltage wiring.

Smaller but lower-margin option:

- Bel Power / CUI `VOF-130-24-CNF`
- Output: 24 V, 5.4 A, 130 W
- Input: 80-264 Vac universal
- Type: enclosed / chassis mount
- Size: 91.4 x 64.0 x 34.5 mm
- This is the compact same-family upgrade, but it does not give enough margin
  for the current all-load transient estimate.

Low-cost/available mechanical backup:

- MEAN WELL `UHP-200-24`
- Output: 24 V, 8.4 A, about 202 W
- Input: 90-264 Vac universal
- Type: enclosed / chassis mount, slim fanless body
- Size: 194.0 x 55.0 x 26.0 mm
- Attractive for cost and availability, but its long, narrow shape and
  integration style need mechanical and EMC review before choosing it over the
  primary production candidate.

Production rule: design the bottom-panel PSU bay around the `RPS-400-24-C` /
`CUS200M-24/A` footprint class unless later measurements prove that a smaller
130 W or 150 W supply has safe thermal margin in the sealed enclosure.

## Bottom-PSU Harnesses

The bottom-mounted `RPS-400-24-C` has two different electrical interfaces. Do
not treat the visible white JST connector as the 24 V output.

### H01: 24 V DC output to PWR-SELECT

- PSU `CN3 +V` -> red 14 AWG -> `PWR-SELECT J101-1 V24_IN`
- PSU `CN2 -V` -> black 14 AWG -> `PWR-SELECT J101-2 GND`
- PSU ends use TE Connectivity `320619` insulated closed-ring terminals for
  the PSU's `M3.5` screws.
- PCB end uses Molex Mega-Fit right-angle header `76825-0002`, receptacle
  `171692-0202`, two tangless contacts `76823-0344`, and TPA `105415-0002`.
- Use one conductor per polarity. Do not double two smaller wires under either
  PSU screw.
- Prototype finished length is 750 +/- 20 mm from ring center to the rear face
  of the Mega-Fit housing. Its releasable service loop must permit at least
  300 mm of panel lift and 45 degrees of tilt without tension. Re-lock length
  from the dressed first-article route and service-opening test before
  production.
- Add a harness clamp within 50 mm of `J101` and another near the PSU. The
  connector and PSU screw terminals must not carry cable strain.

The full assembly drawing and controlled parts are in
`../fabrication/harnesses/H01-PSU-24V.md` and `H01-PSU-24V-BOM.csv`.

### H02: fused AC inlet to PSU CN1

The white PSU connector shown in product photos is `CN1`, a JST `B3P-VH` or
equivalent with 3.96 mm pitch. Its assignment is:

- `CN1-1 AC/L`
- `CN1-2` has no pin and must remain empty
- `CN1-3 AC/N`

Use genuine JST `VHR-3N` housing and `SVH-21T-P1.1` contacts or a formally
qualified equivalent. This is a mains harness, not the PCB-to-PSU DC harness.
Protective earth does not pass through `CN1`; it uses a separate green/yellow
bonding conductor and controlled chassis/PSU grounding point. H02 and the PE
bond remain safety-release items until the final C14 inlet, chassis grounding
point, insulation system, routing, and service barrier have been inspected.
Start H02 at 750 +/- 20 mm and retain its excess in releasable insulated
clamps. The mains harness and flexible panel PE bond must remain untensioned
during the same 300 mm lift / 45 degree tilt service-opening test used for H01.

## D-Tap / LEMO Backup Input

Reuse the previous ProComm alternate backup input concept:

- Function: backup power input only, not a charger
- Panel inlet: genuine LEMO `EGG.1B.302.CLL`, 15 A rated starting part
- Polarity: pin 1 return, pin 2 backup positive
- Intended operating range: 13.0-16.8 V DC
- Typical D-Tap valid threshold: 12.62 V rising, 12.25 V falling
- Overvoltage rejection around 18 V
- A 24 V supply must not be connected to this input
- Full reverse-polarity application must be non-destructive

The prior `EGG.0B.302.CLL` is rated 10 A and is rejected for Rev A because the
current budget reaches about 14.17 A at 13.0 V during the all-load transient.
Use the matching 1B cable connector, wire, fuse, MOSFETs, PCB copper, and source
path rated for at least 15 A. If an upstream D-Tap connector, cable, or source is
only rated 10 A, software must enforce a verified backup-load limit after the
no-blink transfer, or that cable cannot be approved for full-load operation.

The D-Tap/LEMO input feeds the LTC4418 backup preselector ahead of the Gold
Mount source.

## Gold Mount Battery

Reuse the previous ProComm Gold Mount direction:

- Battery basis: Anton/Bauer Dionic XT 90 Gold Mount, SKU `8675-0125`
- Nominal battery voltage: 14.1 V
- Capacity: 99 Wh
- Maximum continuous current: 12 A
- Battery envelope: 99 x 132 x 58 mm
- Dock basis: Anton/Bauer QRC-GOLD Universal Compact Gold Mount Bracket, SKU
  `8375-0094`; approximately 119.4 x 76.2 x 12.7 mm excluding the release latch
- Mechanical ownership: top panel/custom frame only; the dock is not mounted
  to or mechanically supported by any PCB
- Electrical interface: short, fused, strain-relieved positive/negative flying
  leads through a keyed removable high-current harness to power-selector `J203`
- Battery charging is external; no onboard charger unless a future battery
  protocol is explicitly selected and documented.

The exact QRC-GOLD polarity, mounting datum, latch travel, clearance, and main
power-path temperature rise at 12 A still need to be verified from manufacturer
documentation and a measured production sample.

## Selector Architecture

Use the cascaded selector concept:

- LTC4418 selects between D-Tap and Gold Mount.
- LTC4421 selects between `24V_PSU` and `BAT_SELECTED`.
- Back-to-back MOSFETs provide reverse/cross-current blocking.
- Each input has independent fusing/eFuse, surge/ESD protection, UV/OV windows,
  and current/thermal validation.
- Hold-up is required on the protected raw-DC output and critical downstream
  rails so source transfer does not reset, blink, or mute the system.
- Protected raw DC feeds the Radxa carrier regulator system.
- The ProComm Rev D telemetry concept is reused: monitor rear/primary source,
  selected backup source, and protected raw DC delivered to the carrier, with
  final shunt values and INA228 ranges recalculated if the Radxa load budget
  changes them.

Implemented ProComm Rev C reference points:

- Main selector: ADI `LTC4421IUHE#PBF`
- Backup preselector: ADI `LTC4418IUF#PBF`
- Main-path MOSFET candidate: Nexperia `PSMN4R2-80YSE`
- Backup reverse-protection MOSFET candidate: Vishay `SiR5607DP-T1-RE3`
- Input fuses: 15 A Littelfuse Nano2 class in the old schematic
- Raw output connector: `RAW_OUT_TO_LM5176`
- Raw-output bulk in old schematic: 3 x 220 uF / 50 V polymer plus ceramics
- Main current-sense value in old schematic: 2.50 mOhm, giving a 10 A-class
  selector current limit with the LTC4421 25 mV sense threshold
- Status outputs in old schematic include channel/valid status and battery-low
  telemetry to the carrier

For Radxa, preserve the topology and behavior. Recalculate part ratings,
thresholds, fuse values, sense values, timer values, connector current rating,
trace/copper width, inrush current, hold-up capacitance, and thermal rise for
the locked `RPS-400-24-C` PSU and the new 8x8/audio/network/display load.

## User Power Switch

Reuse the previous switch concept:

- Maintained DPST rocker: E-Switch `RA812C1121`
- Capture this in KiCad as `SW201` through keyed four-circuit harness `J204`,
  matching the ProComm low-voltage control circuit and not the IEC C14 inlet.
- One pole enables the LTC4421 main selector.
- One pole enables the LTC4418 backup preselector.
- No high-current system load crosses the panel switch.
- No AC mains should cross the user power switch unless a future safety review
  intentionally changes the AC entry architecture.
- OFF or disconnected switch harness must fail safely to source-selector
  shutdown.
- Retain separate 47 kOhm pull-downs on `SHDN_MAIN` and `SHDN_PRE`; do not tie
  the two controller INTVCC rails together.

The PCB uses Molex Micro-Fit 3.0 header `43045-0412` at `J204`. The panel harness
uses housing `0430250400`, four contacts `0430300007`, four 22 AWG conductors,
and four insulated TE `2-520182-2` FASTON receptacles. The rocker is not mounted
directly to the PCB.

## Radxa System Rails

The Rev A regulator tree is locked for schematic capture. Exact passives,
compensation, copper, and thermal design still require calculation.

| Rail | Target | Starting part/topology |
| --- | ---: | --- |
| `SYS_4V0` | 4.006 V / 12 A | `LM5146` synchronous buck controller with external MOSFETs; all six CM5 `VCC_SYSIN` pins |
| `IO_5V0` | 4.984 V / 2 A | `TPS62913` from fused `DISPLAY_IO_12V`; CM5 pin 106 plus separately fused HDMI and touch USB |
| `AUX_12V` | Revised 12 V / 8 A minimum target | `LM5176` four-switch buck-boost; recalculate and bench-qualify A1 stage |
| `DISPLAY_12V` | 12 V / 2.5 A | Simple fused harness branch from `AUX_12V`; no dedicated display eFuse/current limiter; 25 W / 2.08 A rated monitor load |
| `NIGHT_LIGHT_12V` | 12 V / 0.25 A protected branch | Two YIS Marine LS102W warm-white courtesy lights and one E-Switch CS7L2FR latching touch control; independent of CM5 software |
| `FAN_CPU_12V` | 12 V / 3 A | Protected Delta CPU-fan branch from `AUX_12V` |
| `FAN_AUX_12V` | 12 V / 3 A | Protected modem/enclosure-fan branch with local protection per fan |
| `MODEM_3V8` | 3.8 V / 6 A converter | `LM61460` plus `TPS25982` eFuse; 5 A minimum usable load |
| `WIFI_3V3` | 3.3 V / 4 A | Dedicated `LM61440` plus controlled load switch |
| `NET_3V3` | 3.3 V / 4 A | Separate `LM61440` |
| `PCIE_1V0` | 1.0 V / 2 A | Point-of-load buck for PCIe-switch core |
| `LOGIC_3V3` | 3.3 V / 3 A | Dedicated carrier-logic buck |
| `LOGIC_1V8` | 1.8 V / 1.5 A | Point-of-load regulator |
| `AUDIO_BIPOLAR` | +/-15 V, 20 W class | `TRI 20-1223` starting module plus pi/common-mode filtering |
| `AKM_5V_A` | Clean 5.0 V | Quiet pre-regulator plus `LT3045` |
| `HEADSET_3V3` | Clean 3.3 V / 250 mA | Separate `LP5907MFX-3.3/NOPB` LDO |

Selected separation rule:

- CM5 `SYS_4V0` rail is separate from the display-interface `IO_5V0` and radio rails.
- Wi-Fi AP gets its own switched/local 3.3 V rail sized for AP transmit duty.
- Cellular modem gets its own switched/protected 3.8 V-class rail sized for 5G
  registration and transmit bursts.
- Audio analog rails stay clean and filtered away from Wi-Fi/cellular current
  pulses.
- Headset codec/amplifier power gets its own local low-noise regulator/filter
  path and should not be fed directly from noisy system, radio, fan, USB, or
  Ethernet rails.
- Ethernet controller/switch rails follow their own regulator and sequencing
  requirements.
- Critical rails must ride through source transfer. `SYS_4V0`, `IO_5V0`, modem, Wi-Fi,
  audio, headset, `AUX_12V`, and display rails must not brown out when the
  selected source steps from 24 V PSU to backup voltage.
- `AUX_12V` is buck-boost so both display and fan branches remain at 12 V on
  the 13.0-16.8 V backup source and during transfer droop.

The CM5 input is locked at 4.006 V / 12 A. Radxa recommends a 4 V
`VCC_SYSIN` target for RK806 efficiency and performance; with an input below
5 V, CM5 `5V_HDMI` pin 106 must receive the separate `IO_5V0` supply.
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

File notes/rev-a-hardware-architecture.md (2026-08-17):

# Rev A Hardware Architecture Lock

## Status

This document is the schematic starting point for the first Radxa CM5 ProComm
prototype. Items marked `LOCKED` are design decisions. Parts marked
`STARTING PART` are approved for schematic work but still require calculation,
availability review, layout review, and prototype validation before release.

The three ProComm reference folders remain read-only references. No existing
converter, regulator, or XLR circuit is copied without recalculation for this
product.
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

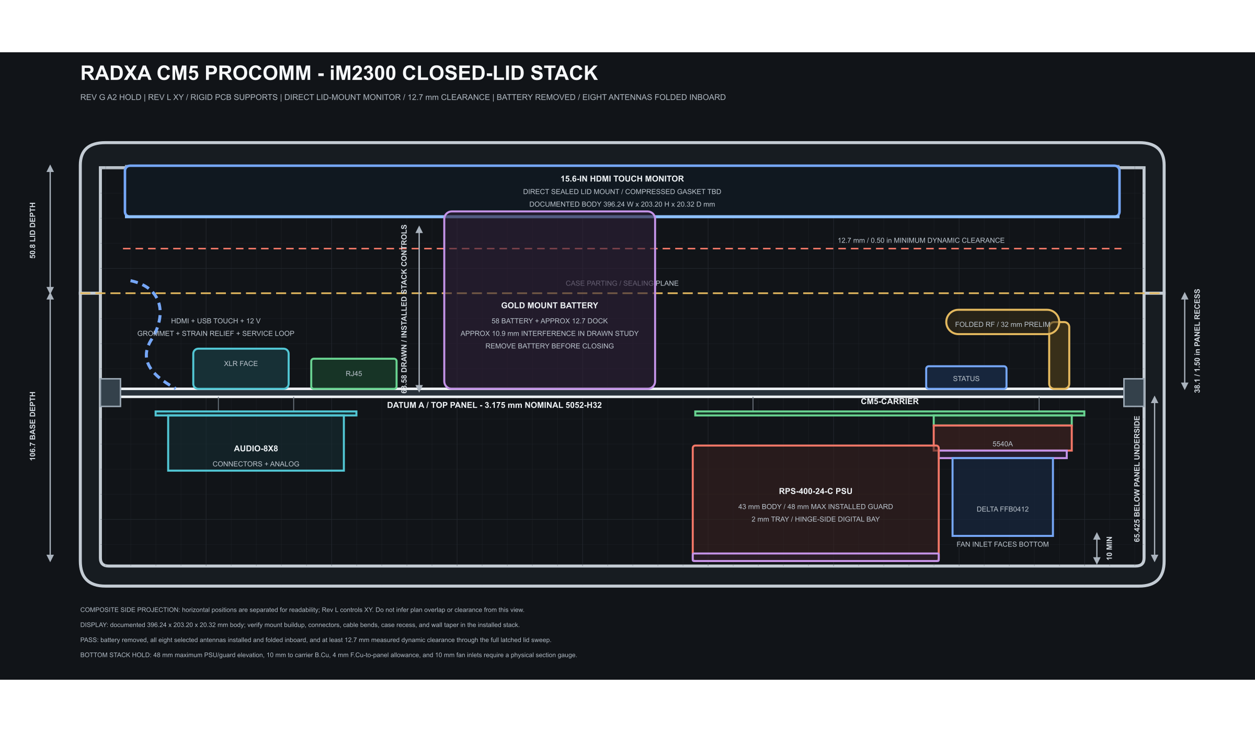
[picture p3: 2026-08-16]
cad/mechanical/im2300-closed-lid-stack-rev-g.png

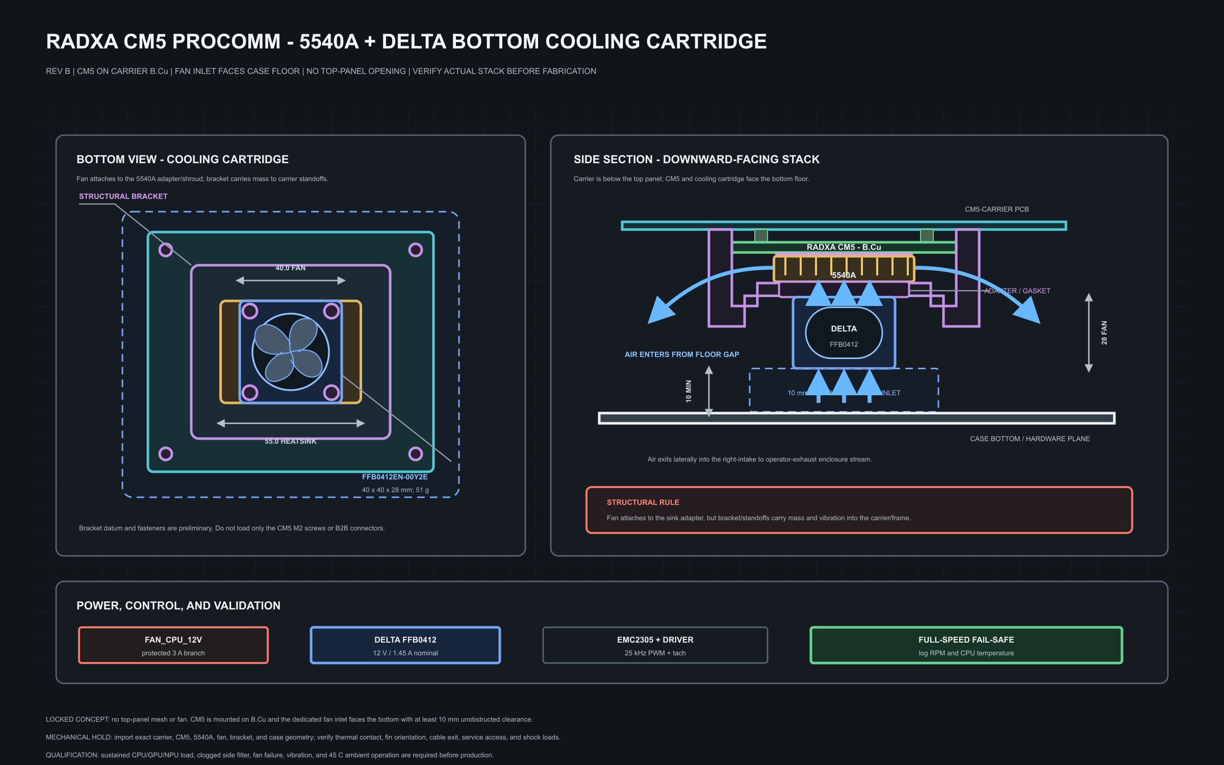
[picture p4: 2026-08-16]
cad/mechanical/cm5-5540a-delta-cooling-concept-rev-b.png

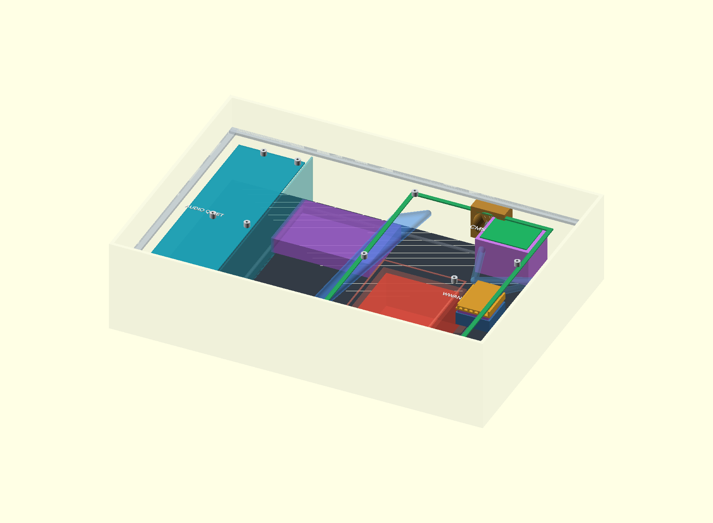
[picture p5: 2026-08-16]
cad/mechanical/im2300-cooling-clearance-rev-d.png

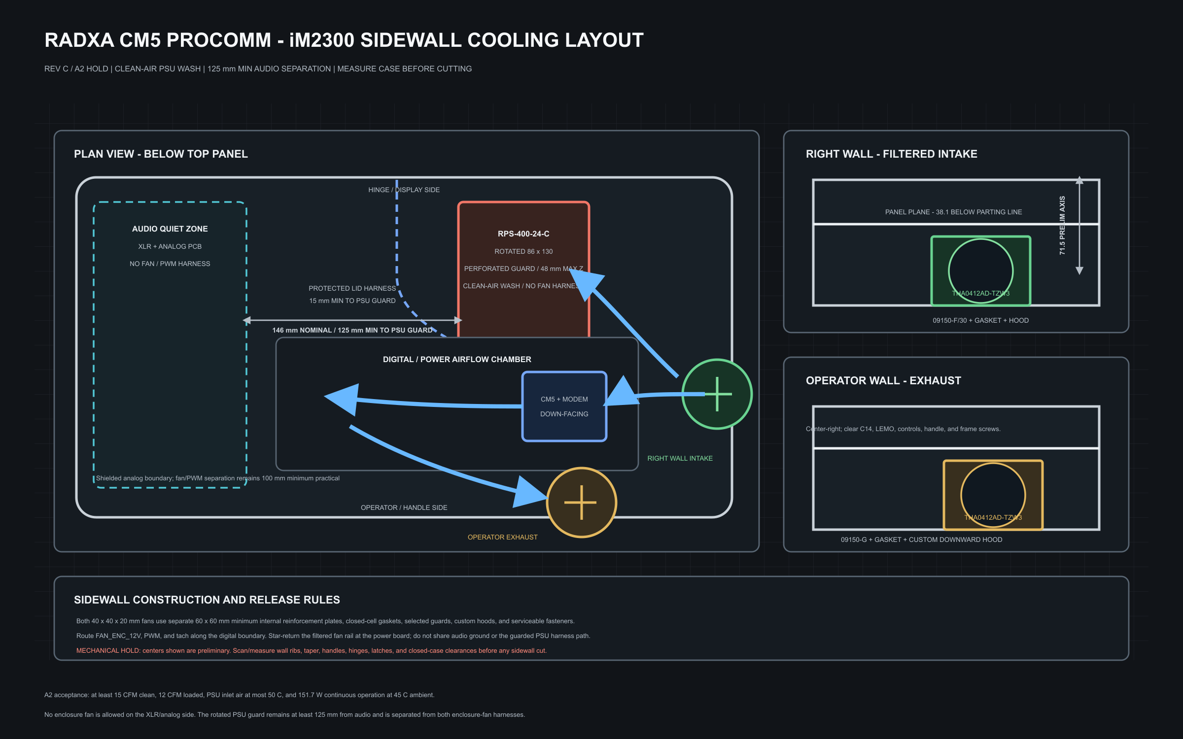
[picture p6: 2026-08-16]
cad/mechanical/im2300-sidewall-cooling-layout-rev-c.png

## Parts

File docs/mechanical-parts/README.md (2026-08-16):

# Mechanical Part Drawings

This folder contains locally archived manufacturer drawings used for the
preliminary iM2300 panel mechanical part freeze.

## Archived Files

- `neutrik-nc3mav-drawing.pdf`
- `neutrik-nc3fav-drawing.pdf`
- `qualtek-719w-00-03-drawing.pdf`
- `lemo-egg-1b-302-cll-datasheet.pdf`
- `e-switch-ra812c1121-drawing.pdf`
- `e-switch-cs-series-datasheet.pdf`
- `e-switch-cs7l2fr-drawing.pdf`
- `yis-marine-electrical-parts-catalogue.pdf` (LS102W courtesy-light dimensions and ratings)
- `kycon-stx-353k7a-drawing.pdf`
- `bulgin-dx06-indicators-catalog.pdf`
- `delta-tha0412ad-tzw3-spec.pdf`
- `delta-afb0412shb-sp04-spec.pdf`
- `qualtek-09150f-filter-drawing.pdf`
- `qualtek-09150g-guard-drawing.pdf`
- `wurth-693043020611-datasheet.pdf`
- `mean-well-rps-400-spec.pdf`
- `pelican-im2300-base-bezel-rev-c.pdf`
- `anton-bauer-qrc-gold-installation.pdf`
- `taoglas-gw05-0153-wifi-antenna.pdf`
- `taoglas-tg66-a113-cellular-antenna.pdf`
- `junebox-b0gk5x95d9-monitor-source.md`

Bel, TE, and monitor links are recorded in
`../panel_mechanical_bom_preliminary.csv`. The QRC-GOLD installation
instruction is archived, but its actual sample, backplate, latch sweep, and
panel/frame load path remain release measurements. The locked monitor listing
documents a nominal 396.24 x 203.20 x 20.32 mm body envelope; that value is
controlled for lid CAD. The monitor mounts directly to sealed lid penetrations;
the 75 x 75 mm VESA pattern is not used. Direct-mount hole coordinates, thread
and engagement, gasket buildup, connector locations, and cable bends remain
sample checks. Connector heads are treated as contained inside the monitor
rear-edge envelope and do not add forward protrusion.
The Taoglas drawings control the validation candidates and connector polarity,
but actual folded height, hinge sweep, lid clearance, and RF performance still
require eight installed antenna samples in the production panel configuration.

These files are reference inputs, not a fabrication release. Re-download each
drawing at purchasing release and compare its revision and manufacturer part
number against the approved BOM.

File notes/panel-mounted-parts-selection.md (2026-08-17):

# Panel-Mounted Parts Selection

## Status

This is the preliminary mechanical part freeze for the iM2300 top panel. It
supports schematic and 3D floorplanning, but it is not permission to cut the
production panel. The current Rev K connector-placement artwork remains the
authoritative layout.

The factory cut drawing can be released only after:

- the actual iM2300 opening is measured at the 38.1 mm panel recess;
- one sample of every panel-interfacing part is fitted to a 3.175 mm nominal
  5052-H32 coupon; the
  RA812 switch location must be locally rear-pocketed to no more than 3.0 mm;
- PCB-to-panel Z height and connector protrusion are fixed;
- the Gold Mount bracket and installed lid-display stack are verified;
- the hinge harness, SIM access, and RF pigtail interfaces are resolved.

## Selected Parts

| Function | Qty | Manufacturer part | Mechanical status |
| --- | ---: | --- | --- |
| XLR outputs | 8 | Neutrik `NC3MAV` | Selected; use official A-series drawing and sample coupon |
| XLR inputs | 8 | Neutrik `NC3FAV` | Selected; use official A-series drawing and sample coupon |
| WAN/LAN MagJacks | 4 | Bel `V8BR-1AX1-GH` | Selected for PCB plus custom zero-preload four-port panel capture bracket; bracket carries plug/unplug/downward loads |
| Fused C14 inlet | 1 | Qualtek `719W-00/03` | Conditional; exact cutout known, current-rating acceptance required |
| Backup inlet | 1 | LEMO `EGG.1B.302.CLL` | Selected; M12 panel drill, IP50 only |
| Main power control | 1 | E-Switch `RA812C1121` | Selected; maintained DPST OFF-ON rocker; thickness-dependent rectangular cutout |
| Headset jack | 1 | Kycon `STX-353K7A-6N-KTTR` | Selected for four-M3 service daughterboard plus positive panel capture bezel and short carrier harness |
| Status indicators | 6 | Bulgin `DX06` wire-lead, 12 V, black brass | Selected family; 6 mm cutouts |
| Panel lights | 2 | YIS Marine `LS102W` | Selected concept; 22 mm cutout, 38 mm matte diffused face, 12 V warm-white SMD light, IP67 |
| Night-light touch control | 1 | E-Switch `CS7L2FR` | Selected; 22.20 +0.25/-0.00 mm cutout, latching capacitive low-side output, IP68 |
| Sidewall enclosure fans | 2 | Delta `THA0412AD-TZW3` | Selected; right-wall filtered intake and operator-wall center-right exhaust; 40 x 40 x 20 mm, 12 V, 4-wire PWM/tach, IP55 fan body |
| Intake filter guard | 1 | Qualtek `09150-F/30` | Selected for intake; 40 mm frame, 30 PPI media |
| Exhaust guard | 1 | Qualtek `09150-G` | Selected 40 mm finger guard; pair with a custom formed 5052-H32 downward splash hood |
| Modem fan | 1 | Delta `AFB0412SHB-SP04` | Selected 40 x 40 x 15 mm, 12 V, four-wire PWM/tach fan; exact modem heatsink remains module-dependent |
| Nano-SIM holders | 2 | Wurth `693043020611` | Selected; horizontal SIM-SERVICE daughterboard plugs directly into carrier through 2.5 mm Hirose DF40 pair |
| Wi-Fi RF pigtails | 4 | TE `2016695-4` | Conditional on AW7915-NP1 IPEX receptacle and 200 mm route check |
| Cellular RF pigtails | 4 | TE `2016694-4` | Conditional on modem receptacle and 200 mm route check |
| Wi-Fi fold-down antennas | 4 | Taoglas `GW.05.0153` | Controlled validation candidate; 62.3 x 10 mm, hinged RP-SMA(M), preliminary folded height 29.4 mm; sample closure and RF test required |
| Cellular fold-down antennas | 4 | Taoglas `TG.66.A113` | Controlled validation candidate; 70.3 x 9.7 mm, hinged SMA(M), preliminary folded height 32 mm; sample closure and RF test required |
| Gold Mount battery | 1 | Anton/Bauer Dionic XT90 `8675-0125` | Selected battery; 99 Wh, 14.1 V, 12 A continuous |
| Gold Mount bracket | 1 | Anton/Bauer QRC-GOLD `8375-0094` | User-selected compact bracket; approximately 119.4 x 76.2 x 12.7 mm; mounts to the top panel/custom frame, never to a PCB; controlled drawing/sample still required |
| Lid display | 1 | JUNEBOX, Amazon ASIN `B0GK5X95D9` | User-locked; documented nominal body 396.24 x 203.20 x 20.32 mm; installation details require verification |

## Indicator Assignment

All six indicators use 200 mm wire leads, a 12 V internal resistor, black
plated brass, and an IP67 front-panel construction.

| Label | Color | Part number |
| --- | --- | --- |
| `PWR` | Green | `DX06WG012B` |
| `BACKUP` | Yellow | `DX06WY012B` |
| `WIFI` | Blue | `DX06WB012B` |
| `CELL` | White | `DX06WW012B` |
| `TEMP` | Red | `DX06WR012B` |
| `AUDIO` | Green | `DX06WG012B` |

The repeated green color is acceptable because every indicator has a permanent
label. Change colors only by BOM revision; the 6 mm mechanical interface stays
the same.

## Preliminary Cutout Schedule

Dimensions below are millimeters. The manufacturer's drawing controls if this
table and a drawing disagree.

| Interface | Preliminary panel work | Release condition |
| --- | --- | --- |
| `NC3MAV` / `NC3FAV` | Use the exact A-series manufacturer cut geometry: central panel opening at least `22.0` and two mounting holes from the controlled drawing; retain 32.0 row pitch and 43.38 column centers | Confirm front/rear mounting convention, latch orientation, connector sample, and screw engagement |
| `V8BR-1AX1-GH` | Rectangular opening plus custom four-port capture bracket around top-entry RJ45 bodies | Derive from final PCB Z datum, panel thickness, plug latch travel, LED visibility, and actual MagJack/plug coupon; bracket must restrain all user axes with zero PCB preload |
| `719W-00/03` | 36 x 44 flange; use the exact front-mounted or rear-mounted cutout in the Qualtek drawing; two `3.5` mounting holes | Select mounting side and verify finger-safe mains barrier and fuse-drawer access |
| `EGG.1B.302.CLL` | `M12` panel drill | Confirm key orientation, nut access, cable bend radius, and IP50 acceptance |
| `RA812C1121` | `13.0` high x `19.2`, `19.4`, or `19.62` wide for panel thickness `0.75-1.25`, `1.25-2.0`, or `2.0-3.0` respectively | Use manufacturer drawing; 3.175 mm nominal panel requires a rear pocket to `<=3.0`; verify snap retention and four FASTON clearances on a coupon |
| Bulgin `DX06` | `6.0` round cutout each | Confirm rear nut and lead clearance |
| YIS Marine `LS102W` | `22.0` round cutout each; `38.0` front-face envelope | Fit two samples, confirm the M22 x 1.5 body/nut, rear depth, warm-white CCT, beam coverage, glare, and lead exit |
| E-Switch `CS7L2FR` | `22.20 +0.25/-0.00` round cutout; maximum panel thickness 10 mm | Fit supplied O-ring/nut, retain 20.70 mm rear body/flats clearance and 150 mm six-wire lead bend radius |
| `THA0412AD-TZW3` + 40 mm guards | Sidewall work only: 40 x 40 fan envelope, 32 x 32 mounting-hole square, fan holes `3.5 +/-0.3`; use Qualtek `09150-F/30` at intake and `09150-G` at exhaust, with separate reinforcement plates and gaskets; center airflow opening is sample-controlled | Measure wall ribs/taper and nearby hardware; lock fan 1 intake/fan 2 exhaust labels; test custom exhaust splash hood, wall stiffness, finger safety, ingress, filter service, pressure balance, and internal baffle effectiveness |
| SMA / RP-SMA bulkheads | Current SVG uses approximately `6.4` round placeholders | Replace with TE bulkhead drawing after pigtail/module confirmation; include wrench flats and washer clearance if required |
| `GW.05.0153` / `TG.66.A113` folded sweep | Eight inboard dashed projections are transport envelopes, not cut geometry | Fit all eight actual antennas; verify RP-SMA versus SMA polarity, hinge rotation, 34 mm pitch, neighboring hardware, maximum folded height, and at least 8 mm latched-lid dynamic clearance |
| `STX-353K7A-6N-KTTR` | No threaded panel bushing; use positive panel bezel on a four-M3 service daughterboard | Fix service-board Z height, plug clearance, bezel capture, and no-load short harness on a coupon |
| Nano-SIM access | Two service openings above a vertical daughterboard, not above a horizontal holder | Design daughterboard, card insertion path, retention, ESD shield, and service cover before cutting |
| QRC-GOLD | Existing 99 x 132 mm battery envelope is keepout only | Replace with Anton/Bauer bracket hole pattern and full battery release-sweep measurement; published bracket dimensions exclude the release latch |
| Lid harness | Open hinge-edge notch, no enclosed top-panel hole | Measure HDMI, USB touch, and 12 V cable overmolds and specify edge protection and service loop |

The QRC-GOLD is independent enclosure hardware. Install the supplied backplate
and support the manufacturer's shaded areas against a flat panel/frame load
path. Its flying positive and
negative leads terminate in a strain-relieved, keyed, touch-safe high-current
harness that disconnects at the power-selector PCB. The dock mounting screws,
battery insertion load, and vibration load must be carried by the top panel and
custom frame, not by PCB laminate, standoffs, solder joints, or `J203`.

## Important Compatibility Findings

### SIM orientation

Wurth `693043020611` is a push-pull Nano-SIM holder with card travel parallel
to its PCB. The two holders live on a 76 x 40 mm horizontal SIM-SERVICE
daughterboard immediately below the panel guide. Its B.Cu Hirose
`DF40HC(2.5)-20DS-0.4V(51)` receptacle plugs directly into carrier
`DF40C-20DP-0.4V(51)` J702. Four 2.50 mm precision supports carry card and
vibration loads; there is no SIM cable harness.

### C14 current marking

Qualtek rates `719W-00/03` at 10 A / 250 Vac. It does not meet a literal
15 A / 120 Vac inlet-marking requirement. Its 10 A rating is well above the
approximately 2.8 A worst-case input current of a 252 W load at 100 Vac and
90 percent efficiency, but the product label and agency requirement must be
accepted explicitly or the inlet must be changed before release.

### Sealing

The LEMO `EGG.1B.302.CLL` is IP50, the Neutrik AV XLR parts are IP40, and the
two sidewall fan openings are intentionally vented. The assembled product is
therefore not an IP67 Pelican case. The RA812 switch is IP54 only when fitted
with optional E-Switch cap `ACC-P01`; the IP67 YIS lamps and IP68 CS touch
switch do not restore overall enclosure sealing.

### Display interface

The locked ASIN listing documents HDMI, touch capability, 12 V power, and a
nominal body envelope of 15.6 W x 8.0 H x 0.8 D in, or
396.24 x 203.20 x 20.32 mm. Use that envelope for lid CAD and retain the
user-locked 12 V / 2.5 A carrier branch and 25 W design allocation. The listing
does not control HDMI, USB-touch, power-connector, VESA-hole, mount-stack, or
hinge-notch geometry, so those installation details still require verification
before fabrication release.

## Factory Release Rule

Every cutout in the final DXF must reference a BOM item, drawing revision,
mounting side, panel thickness, tolerance, and datum coordinate. Placeholders
from the concept SVG must never be traced into production CAD.

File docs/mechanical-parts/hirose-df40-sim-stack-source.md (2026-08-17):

# Hirose DF40 Dual-SIM Board Stack

## Locked Architecture

The horizontal `SIM-SERVICE` daughterboard plugs directly into the
`CM5-CARRIER`. There is no cable harness in the SIM electrical path.

- Carrier J702: Hirose `DF40C-20DP-0.4V(51)` vertical plug.
- SIM-SERVICE J1: Hirose `DF40HC(2.5)-20DS-0.4V(51)` vertical receptacle/socket.
- Circuit count: 20.
- Nominal mated PCB spacing: 2.50 mm.
- Connector current rating: 0.30 A per contact.
- Published mating durability: 30 cycles.

Official source pages:

- Carrier plug: <https://www.hirose.com/en/product/p/CL0684-4010-9-51>
- 2.5 mm receptacle: <https://www.hirose.com/en/product/p/CL0684-4126-3-51>

The manufacturer drawings and STEP models are archived under
`references/components/hirose/DF40-SIM-20/`. Local KiCad footprints and STEP
links are under `cad/kicad/CM5-CARRIER/CM5Carrier.pretty/` and
`cad/kicad/CM5-CARRIER/CM5Carrier.3dshapes/`.

## Mechanical Rule

The DF40 pair is an electrical alignment datum, not a structural member. Four
matched M3 support pairs `SD1/S1` through `SD4/S4`, fitted with 2.50 +/-0.05 mm
precision metal sleeves, carry daughterboard mass, card insertion/extraction,
and vibration loads. An insulating panel guide carries lateral Nano-SIM card
loads at the two panel openings.

Do not use the screws to pull a misaligned connector pair together. The boards
must mate with the sleeves installed and without rocking or lateral force.

## Controlled Stack

The nominal distance from carrier F.Cu to the top-panel underside is 5.825 mm.
The nominal occupied stack is:

- DF40 mated spacing: 2.500 mm.
- SIM-SERVICE PCB: 1.600 mm.
- Wurth `693043020611` holder body: 1.200 mm nominal from the manufacturer
  drawing.
- Remaining nominal panel clearance: 0.525 mm.

This small residual is not a production tolerance allowance. PCBWay must build
and inspect the released stack coupon using production panel, PCB, connector,
holder, solder, and sleeve tolerances before main assembly release.

## Electrical Pin Map

| Pin | Net | Pin | Net |
| --- | --- | --- | --- |
| 1 | GND | 2 | CHASSIS_GND |
| 3 | SIM1_VCC | 4 | SIM1_RESET_RAW |
| 5 | GND | 6 | SIM1_CLK_RAW |
| 7 | GND | 8 | SIM1_DATA_RAW |
| 9 | SIM2_VCC | 10 | SIM2_RESET_RAW |
| 11 | GND | 12 | SIM2_CLK_RAW |
| 13 | GND | 14 | SIM2_DATA_RAW |
| 15 | GND | 16 | CHASSIS_GND |
| 17 | GND | 18 | CHASSIS_GND |
| 19 | GND | 20 | CHASSIS_GND |

The alternating return contacts reduce loop area and provide a controlled
ground/shield path across the separable board interface. SIM ESD/filter parts
remain on the daughterboard next to the card holders; modem-side control and
power remain on the carrier.

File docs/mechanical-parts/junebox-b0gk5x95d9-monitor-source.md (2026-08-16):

# JUNEBOX B0GK5X95D9 Monitor Mechanical Source

## Controlled Nominal Envelope

- Selected product: JUNEBOX 15.6-inch HDMI touchscreen
- Amazon ASIN: `B0GK5X95D9`
- Product URL: <https://www.amazon.com/dp/B0GK5X95D9>
- Source checked: 2026-08-16
- Listing dimensions, D x W x H: `0.8 x 15.6 x 8.0 in`
- Controlled CAD dimensions, W x H x D: `396.24 x 203.20 x 20.32 mm`

The documented body envelope is the nominal input for lid CAD. A duplicate
sample measurement is not required merely to establish body width, height, or
depth.

## Installation Verification

The monitor mounts directly to the inside of the iM2300 lid. Outside-in
fasteners pass through sealed lid penetrations and engage the monitor's
dedicated chassis mounting points. The 75 x 75 mm VESA pattern is not used and
no VESA plate is installed.

The listing does not provide a controlled drilling drawing for this direct
mount. Before fabrication release, use the received monitor to record every
mounting-hole coordinate, thread specification, maximum screw engagement,
fastener torque, sealing-washer geometry, and compressed interface-gasket
thickness. Do not derive lid holes from a listing image or the unused VESA
pattern. Use low-profile exterior fasteners with bonded sealing washers or an
equivalent qualified seal, and use a continuous closed-cell interface gasket
so the lid is not point-loaded or left with unsealed penetrations.

Orient the monitor connector edge toward the hinge-side harness corridor. The
HDMI, USB-touch, and power connector heads remain inside the monitor/rear-edge
envelope and do not add to forward display protrusion. Verify their in-plane
cable bend and strain-relief envelopes, full lid travel, and closed-lid
clearance with all eight antennas installed and folded inboard. These checks
validate the installation, not the documented monitor body size.

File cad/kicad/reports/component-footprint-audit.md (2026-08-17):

# Component and Footprint Audit

Generated once from each physical board root so hierarchical child components are not double-counted. This report is deterministic and contains no audit timestamp.

## Current gate

- Components audited: 1200
- Route-ready components: 1185
- Intentional non-board symbols: 5
- Routing blockers: 10
- Production/BOM blockers: 11

A routing blocker has no footprint, references an unresolved footprint, or still requires a routing-critical mechanical coupon. A production blocker also includes any board-mounted component without a locked manufacturer and MPN.

## By sheet

| Sheet | Components | Routing blockers | Production blockers |
|---|---:|---:|---:|
| PWR-SELECT | 111 | 0 | 0 |
| CM5-Carrier | 515 | 0 | 1 |
| Audio-8x8 | 574 | 10 | 10 |

## Gate commands

```sh
python3 cad/kicad/audit_footprint_readiness.py
python3 cad/kicad/audit_footprint_readiness.py --routing
python3 cad/kicad/audit_footprint_readiness.py --release
```

The default command refreshes this report. `--routing` fails while placement/routing blockers remain. `--release` also fails while production-part evidence is incomplete.

See `component-footprint-audit.csv` for every reference designator and its exact blocking reason.

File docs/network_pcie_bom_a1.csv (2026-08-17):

Reference | Value | Footprint | Manufacturer | MPN | Assembly | Qty | DNP
C601 | 100nF | Capacitor_SMD:C_0402_1005Metric | TDK | C1005X7R1H104K050BB |  | 1
C602 | 100nF | Capacitor_SMD:C_0402_1005Metric | TDK | C1005X7R1H104K050BB |  | 1
C603 | 100nF | Capacitor_SMD:C_0402_1005Metric | TDK | C1005X7R1H104K050BB |  | 1
C604 | 100nF | Capacitor_SMD:C_0402_1005Metric | TDK | C1005X7R1H104K050BB |  | 1
C605 | 100nF | Capacitor_SMD:C_0402_1005Metric | TDK | C1005X7R1H104K050BB |  | 1
C606 | 100nF | Capacitor_SMD:C_0402_1005Metric | TDK | C1005X7R1H104K050BB |  | 1
C607 | 100nF | Capacitor_SMD:C_0402_1005Metric | TDK | C1005X7R1H104K050BB |  | 1
C608 | 100nF | Capacitor_SMD:C_0402_1005Metric | TDK | C1005X7R1H104K050BB |  | 1
C609 | 100nF | Capacitor_SMD:C_0402_1005Metric | TDK | C1005X7R1H104K050BB |  | 1
C610 | 100nF | Capacitor_SMD:C_0402_1005Metric | TDK | C1005X7R1H104K050BB |  | 1
C611 | 100nF | Capacitor_SMD:C_0402_1005Metric | TDK | C1005X7R1H104K050BB |  | 1
C6111 | 22uF 10V X7R | Capacitor_SMD:C_0805_2012Metric | Murata | GRM21BR71A226ME44L |  | 1
C6112 | 100nF | Capacitor_SMD:C_0402_1005Metric | TDK | C1005X7R1H104K050BB |  | 1
C6113 | 1uF 35V X5R / ESR <1R | Capacitor_SMD:C_0402_1005Metric | Murata | GRM155R6YA105KE11D |  | 1
C6114 | 15pF C0G | Capacitor_SMD:C_0402_1005Metric | Murata | GRM1555C1H150JA01D |  | 1
C6115 | 15pF C0G | Capacitor_SMD:C_0402_1005Metric | Murata | GRM1555C1H150JA01D |  | 1
C6116 | 10nF | Capacitor_SMD:C_0603_1608Metric | Murata | GRM188R71H103KA01D |  | 1
C6117 | 10nF | Capacitor_SMD:C_0603_1608Metric | Murata | GRM188R71H103KA01D |  | 1
C6118 | 10nF | Capacitor_SMD:C_0603_1608Metric | Murata | GRM188R71H103KA01D |  | 1
C6119 | 10nF | Capacitor_SMD:C_0603_1608Metric | Murata | GRM188R71H103KA01D |  | 1
C6121 | 22uF 10V X7R | Capacitor_SMD:C_0805_2012Metric | Murata | GRM21BR71A226ME44L |  | 1
C6122 | 100nF | Capacitor_SMD:C_0402_1005Metric | TDK | C1005X7R1H104K050BB |  | 1
C6123 | 1uF 35V X5R / ESR <1R | Capacitor_SMD:C_0402_1005Metric | Murata | GRM155R6YA105KE11D |  | 1
C6124 | 15pF C0G | Capacitor_SMD:C_0402_1005Metric | Murata | GRM1555C1H150JA01D |  | 1
C6125 | 15pF C0G | Capacitor_SMD:C_0402_1005Metric | Murata | GRM1555C1H150JA01D |  | 1
C6126 | 10nF | Capacitor_SMD:C_0603_1608Metric | Murata | GRM188R71H103KA01D |  | 1
C6127 | 10nF | Capacitor_SMD:C_0603_1608Metric | Murata | GRM188R71H103KA01D |  | 1
C6128 | 10nF | Capacitor_SMD:C_0603_1608Metric | Murata | GRM188R71H103KA01D |  | 1
C6129 | 10nF | Capacitor_SMD:C_0603_1608Metric | Murata | GRM188R71H103KA01D |  | 1
C6131 | 22uF 10V X7R | Capacitor_SMD:C_0805_2012Metric | Murata | GRM21BR71A226ME44L |  | 1
C6132 | 100nF | Capacitor_SMD:C_0402_1005Metric | TDK | C1005X7R1H104K050BB |  | 1
C6133 | 1uF 35V X5R / ESR <1R | Capacitor_SMD:C_0402_1005Metric | Murata | GRM155R6YA105KE11D |  | 1
C6134 | 15pF C0G | Capacitor_SMD:C_0402_1005Metric | Murata | GRM1555C1H150JA01D |  | 1
C6135 | 15pF C0G | Capacitor_SMD:C_0402_1005Metric | Murata | GRM1555C1H150JA01D |  | 1
C6136 | 10nF | Capacitor_SMD:C_0603_1608Metric | Murata | GRM188R71H103KA01D |  | 1
C6137 | 10nF | Capacitor_SMD:C_0603_1608Metric | Murata | GRM188R71H103KA01D |  | 1
C6138 | 10nF | Capacitor_SMD:C_0603_1608Metric | Murata | GRM188R71H103KA01D |  | 1
C6139 | 10nF | Capacitor_SMD:C_0603_1608Metric | Murata | GRM188R71H103KA01D |  | 1
C6601 | 100nF | Capacitor_SMD:C_0402_1005Metric | TDK | C1005X7R1H104K050BB |  | 1
C6602 | 100nF | Capacitor_SMD:C_0402_1005Metric | TDK | C1005X7R1H104K050BB |  | 1
C6603 | 100nF | Capacitor_SMD:C_0402_1005Metric | TDK | C1005X7R1H104K050BB |  | 1
C6604 | 100nF | Capacitor_SMD:C_0402_1005Metric | TDK | C1005X7R1H104K050BB |  | 1
C6605 | 100nF | Capacitor_SMD:C_0402_1005Metric | TDK | C1005X7R1H104K050BB |  | 1
C6606 | 100nF | Capacitor_SMD:C_0402_1005Metric | TDK | C1005X7R1H104K050BB |  | 1
C6607 | 100nF | Capacitor_SMD:C_0402_1005Metric | TDK | C1005X7R1H104K050BB |  | 1
C6608 | 100nF | Capacitor_SMD:C_0402_1005Metric | TDK | C1005X7R1H104K050BB |  | 1
C6609 | 100nF | Capacitor_SMD:C_0402_1005Metric | TDK | C1005X7R1H104K050BB |  | 1
C6610 | 100nF | Capacitor_SMD:C_0402_1005Metric | TDK | C1005X7R1H104K050BB |  | 1
C6611 | 100nF | Capacitor_SMD:C_0402_1005Metric | TDK | C1005X7R1H104K050BB |  | 1
C6612 | 100nF | Capacitor_SMD:C_0402_1005Metric | TDK | C1005X7R1H104K050BB |  | 1
C6613 | 100nF | Capacitor_SMD:C_0402_1005Metric | TDK | C1005X7R1H104K050BB |  | 1
C6614 | 100nF | Capacitor_SMD:C_0402_1005Metric | TDK | C1005X7R1H104K050BB |  | 1
C6615 | 100nF | Capacitor_SMD:C_0402_1005Metric | TDK | C1005X7R1H104K050BB |  | 1
C6616 | 100nF | Capacitor_SMD:C_0402_1005Metric | TDK | C1005X7R1H104K050BB |  | 1
C6617 | 100nF | Capacitor_SMD:C_0402_1005Metric | TDK | C1005X7R1H104K050BB |  | 1
C6618 | 100nF | Capacitor_SMD:C_0402_1005Metric | TDK | C1005X7R1H104K050BB |  | 1
C6619 | 100nF | Capacitor_SMD:C_0402_1005Metric | TDK | C1005X7R1H104K050BB |  | 1
C6620 | 100nF | Capacitor_SMD:C_0402_1005Metric | TDK | C1005X7R1H104K050BB |  | 1
C6621 | 100nF | Capacitor_SMD:C_0402_1005Metric | TDK | C1005X7R1H104K050BB |  | 1
C6622 | 100nF | Capacitor_SMD:C_0402_1005Metric | TDK | C1005X7R1H104K050BB |  | 1
C6623 | 100nF | Capacitor_SMD:C_0402_1005Metric | TDK | C1005X7R1H104K050BB |  | 1
C6624 | 100nF | Capacitor_SMD:C_0402_1005Metric | TDK | C1005X7R1H104K050BB |  | 1
C6625 | 100nF | Capacitor_SMD:C_0402_1005Metric | TDK | C1005X7R1H104K050BB |  | 1
C6626 | 100nF | Capacitor_SMD:C_0402_1005Metric | TDK | C1005X7R1H104K050BB |  | 1
C6627 | 100nF | Capacitor_SMD:C_0402_1005Metric | TDK | C1005X7R1H104K050BB |  | 1
C6628 | 100nF | Capacitor_SMD:C_0402_1005Metric | TDK | C1005X7R1H104K050BB |  | 1
C6629 | 100nF | Capacitor_SMD:C_0402_1005Metric | TDK | C1005X7R1H104K050BB |  | 1
C6630 | 22uF 10V X7R | Capacitor_SMD:C_0805_2012Metric | Murata | GRM21BR71A226ME44L |  | 1
C6631 | 22uF 10V X7R | Capacitor_SMD:C_0805_2012Metric | Murata | GRM21BR71A226ME44L |  | 1
C61110 | 100nF | Capacitor_SMD:C_0402_1005Metric | TDK | C1005X7R1H104K050BB |  | 1
C61111 | 100nF | Capacitor_SMD:C_0402_1005Metric | TDK | C1005X7R1H104K050BB |  | 1
C61112 | 100nF | Capacitor_SMD:C_0402_1005Metric | TDK | C1005X7R1H104K050BB |  | 1
C61113 | 100nF | Capacitor_SMD:C_0402_1005Metric | TDK | C1005X7R1H104K050BB |  | 1
C61114 | 100nF | Capacitor_SMD:C_0402_1005Metric | TDK | C1005X7R1H104K050BB |  | 1
C61115 | 100nF | Capacitor_SMD:C_0402_1005Metric | TDK | C1005X7R1H104K050BB |  | 1
C61210 | 100nF | Capacitor_SMD:C_0402_1005Metric | TDK | C1005X7R1H104K050BB |  | 1
C61211 | 100nF | Capacitor_SMD:C_0402_1005Metric | TDK | C1005X7R1H104K050BB |  | 1
C61212 | 100nF | Capacitor_SMD:C_0402_1005Metric | TDK | C1005X7R1H104K050BB |  | 1
C61213 | 100nF | Capacitor_SMD:C_0402_1005Metric | TDK | C1005X7R1H104K050BB |  | 1
C61214 | 100nF | Capacitor_SMD:C_0402_1005Metric | TDK | C1005X7R1H104K050BB |  | 1
C61215 | 100nF | Capacitor_SMD:C_0402_1005Metric | TDK | C1005X7R1H104K050BB |  | 1
C61310 | 100nF | Capacitor_SMD:C_0402_1005Metric | TDK | C1005X7R1H104K050BB |  | 1
C61311 | 100nF | Capacitor_SMD:C_0402_1005Metric | TDK | C1005X7R1H104K050BB |  | 1
C61312 | 100nF | Capacitor_SMD:C_0402_1005Metric | TDK | C1005X7R1H104K050BB |  | 1
C61313 | 100nF | Capacitor_SMD:C_0402_1005Metric | TDK | C1005X7R1H104K050BB |  | 1
C61314 | 100nF | Capacitor_SMD:C_0402_1005Metric | TDK | C1005X7R1H104K050BB |  | 1
C61315 | 100nF | Capacitor_SMD:C_0402_1005Metric | TDK | C1005X7R1H104K050BB |  | 1
FB6111 | 220R ferrite | Inductor_SMD:L_0805_2012Metric | Murata | BLM21PG221SN1D |  | 1
FB6112 | 220R ferrite | Inductor_SMD:L_0805_2012Metric | Murata | BLM21PG221SN1D |  | 1
FB6121 | 220R ferrite | Inductor_SMD:L_0805_2012Metric | Murata | BLM21PG221SN1D |  | 1
FB6122 | 220R ferrite | Inductor_SMD:L_0805_2012Metric | Murata | BLM21PG221SN1D |  | 1
FB6131 | 220R ferrite | Inductor_SMD:L_0805_2012Metric | Murata | BLM21PG221SN1D |  | 1
FB6132 | 220R ferrite | Inductor_SMD:L_0805_2012Metric | Murata | BLM21PG221SN1D |  | 1
J610 | V8BR-1AX1-GH | CM5Carrier:Bel_V8BR_1AX1_GH | Bel | V8BR-1AX1-GH |  | 1
J611 | V8BR-1AX1-GH | CM5Carrier:Bel_V8BR_1AX1_GH | Bel | V8BR-1AX1-GH |  | 1
J612 | V8BR-1AX1-GH | CM5Carrier:Bel_V8BR_1AX1_GH | Bel | V8BR-1AX1-GH |  | 1
J613 | V8BR-1AX1-GH | CM5Carrier:Bel_V8BR_1AX1_GH | Bel | V8BR-1AX1-GH |  | 1
J620 | AW7915-NP1_WIFI6_4T4R | CM5Carrier:Molex_0679101002_Mini_PCIe | Molex | 0679101002 |  | 1
L6111 | 3.3uH / 2.37A min | CM5Carrier:TDK_VLS3012HBX | TDK | VLS3012HBX-3R3M-N |  | 1
L6121 | 3.3uH / 2.37A min | CM5Carrier:TDK_VLS3012HBX | TDK | VLS3012HBX-3R3M-N |  | 1
L6131 | 3.3uH / 2.37A min | CM5Carrier:TDK_VLS3012HBX | TDK | VLS3012HBX-3R3M-N |  | 1
R601 | 4.7k | Resistor_SMD:R_0603_1608Metric | Yageo | RC0603FR-074K7L |  | 1
R602 | 1.43k 1% | Resistor_SMD:R_0603_1608Metric | Yageo | RC0603FR-071K43L |  | 1
R603 | 1.43k 1% | Resistor_SMD:R_0603_1608Metric | Yageo | RC0603FR-071K43L |  | 1
R604 | 475R 1% | Resistor_SMD:R_0603_1608Metric | Yageo | RC0603FR-07475RL |  | 1
R605 | 2.2k | Resistor_SMD:R_0603_1608Metric | Yageo | RC0603FR-072K2L |  | 1
R606 | 2.2k | Resistor_SMD:R_0603_1608Metric | Yageo | RC0603FR-072K2L |  | 1
R607 | 0R | Resistor_SMD:R_0603_1608Metric | Yageo | RC0603JR-070RL |  | 1
R608 | 100k | Resistor_SMD:R_0603_1608Metric | Yageo | RC0603FR-07100KL |  | 1
R620 | 10k | Resistor_SMD:R_0603_1608Metric | Yageo | RC0603FR-0710KL |  | 1
R650 | 330R | Resistor_SMD:R_0603_1608Metric | Yageo | RC0603FR-07330RL |  | 1
R651 | 330R | Resistor_SMD:R_0603_1608Metric | Yageo | RC0603FR-07330RL |  | 1
R652 | 330R | Resistor_SMD:R_0603_1608Metric | Yageo | RC0603FR-07330RL |  | 1
R653 | 330R | Resistor_SMD:R_0603_1608Metric | Yageo | RC0603FR-07330RL |  | 1
R654 | 330R | Resistor_SMD:R_0603_1608Metric | Yageo | RC0603FR-07330RL |  | 1
R655 | 330R | Resistor_SMD:R_0603_1608Metric | Yageo | RC0603FR-07330RL |  | 1
R656 | 330R | Resistor_SMD:R_0603_1608Metric | Yageo | RC0603FR-07330RL |  | 1
R657 | 330R | Resistor_SMD:R_0603_1608Metric | Yageo | RC0603FR-07330RL |  | 1
R6111 | 200R 1% | Resistor_SMD:R_0603_1608Metric | Yageo | RC0603FR-07200RL |  | 1
R6112 | 6.04k 1% | Resistor_SMD:R_0603_1608Metric | Yageo | RC0603FR-076K04L |  | 1
R6113 | 10k | Resistor_SMD:R_0603_1608Metric | Yageo | RC0603FR-0710KL |  | 1
R6121 | 200R 1% | Resistor_SMD:R_0603_1608Metric | Yageo | RC0603FR-07200RL |  | 1
R6122 | 6.04k 1% | Resistor_SMD:R_0603_1608Metric | Yageo | RC0603FR-076K04L |  | 1
R6123 | 10k | Resistor_SMD:R_0603_1608Metric | Yageo | RC0603FR-0710KL |  | 1
R6131 | 200R 1% | Resistor_SMD:R_0603_1608Metric | Yageo | RC0603FR-07200RL |  | 1
R6132 | 6.04k 1% | Resistor_SMD:R_0603_1608Metric | Yageo | RC0603FR-076K04L |  | 1
R6133 | 10k | Resistor_SMD:R_0603_1608Metric | Yageo | RC0603FR-0710KL |  | 1
U601 | PI7C9X2G608GP | Package_BGA:BGA-196_15x15mm_Layout14x14_P1.0mm | Diodes Incorporated | PI7C9X2G608GPCNJEX |  | 1
U606 | SN74LVC1G11DBVR | Package_TO_SOT_SMD:SOT-23-6 | Texas Instruments | SN74LVC1G11DBVR |  | 1
U611 | LAN7430 | Package_DFN_QFN:QFN-48-1EP_7x7mm_P0.5mm_EP5.3x5.3mm_ThermalVias | Microchip | LAN7430T-I/Y9X |  | 1
U612 | LAN7430 | Package_DFN_QFN:QFN-48-1EP_7x7mm_P0.5mm_EP5.3x5.3mm_ThermalVias | Microchip | LAN7430T-I/Y9X |  | 1
U613 | LAN7430 | Package_DFN_QFN:QFN-48-1EP_7x7mm_P0.5mm_EP5.3x5.3mm_ThermalVias | Microchip | LAN7430T-I/Y9X |  | 1
U630 | TPD4E05U06DQA | Package_SON:USON-10_2.5x1.0mm_P0.5mm | Texas Instruments | TPD4E05U06DQAR |  | 1
U631 | TPD4E05U06DQA | Package_SON:USON-10_2.5x1.0mm_P0.5mm | Texas Instruments | TPD4E05U06DQAR |  | 1
U632 | TPD4E05U06DQA | Package_SON:USON-10_2.5x1.0mm_P0.5mm | Texas Instruments | TPD4E05U06DQAR |  | 1
U633 | TPD4E05U06DQA | Package_SON:USON-10_2.5x1.0mm_P0.5mm | Texas Instruments | TPD4E05U06DQAR |  | 1
U634 | TPD4E05U06DQA | Package_SON:USON-10_2.5x1.0mm_P0.5mm | Texas Instruments | TPD4E05U06DQAR |  | 1
U635 | TPD4E05U06DQA | Package_SON:USON-10_2.5x1.0mm_P0.5mm | Texas Instruments | TPD4E05U06DQAR |  | 1
U636 | TPD4E05U06DQA | Package_SON:USON-10_2.5x1.0mm_P0.5mm | Texas Instruments | TPD4E05U06DQAR |  | 1
U637 | TPD4E05U06DQA | Package_SON:USON-10_2.5x1.0mm_P0.5mm | Texas Instruments | TPD4E05U06DQAR |  | 1
Y611 | 25MHz / 10pF / -40..85C | Crystal:Crystal_SMD_3225-4Pin_3.2x2.5mm | Abracon | ABM8-25.000MHZ-10-D1G-T |  | 1
Y612 | 25MHz / 10pF / -40..85C | Crystal:Crystal_SMD_3225-4Pin_3.2x2.5mm | Abracon | ABM8-25.000MHZ-10-D1G-T |  | 1
Y613 | 25MHz / 10pF / -40..85C | Crystal:Crystal_SMD_3225-4Pin_3.2x2.5mm | Abracon | ABM8-25.000MHZ-10-D1G-T |  | 1

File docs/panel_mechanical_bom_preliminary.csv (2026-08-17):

item | qty | function | manufacturer | part_number | panel_interface | selection_status | release_blocker | local_drawing_or_reference | source_url
1 | 8 | Balanced XLR output | Neutrik | NC3MAV | A-series PCB receptacle; both flange screws transfer user mating loads to panel | Selected | Mounting side; latch orientation; flange and six-support alignment coupon | docs/mechanical-parts/neutrik-nc3mav-drawing.pdf | https://www.neutrik.com/en/product/nc3mav
2 | 8 | Balanced XLR input | Neutrik | NC3FAV | A-series PCB receptacle; both flange screws transfer user mating loads to panel | Selected | Mounting side; latch orientation; flange and six-support alignment coupon | docs/mechanical-parts/neutrik-nc3fav-drawing.pdf | https://www.neutrik.com/en/product/nc3fav
3 | 4 | Vertical 1GbE MagJack | Bel | V8BR-1AX1-GH | PCB soldered plus custom 2.0 mm 5052-H32 four-port panel capture bracket; bracket carries plug/unplug/downward loads | Selected | Release zero-preload bracket from actual MagJack and latched-plug coupon; final PCB Z datum; latch and LED clearance | Manufacturer web drawing | https://www.belfuse.com/products/ethernet/magjacks-icms/v8br-1ax1-gh
4 | 1 | Fused unswitched C14 inlet | Qualtek | 719W-00/03 | 36 x 44 flange; exact front/rear cutout per drawing | Conditional | Accept 10 A rating; select mounting side; mains barrier | docs/mechanical-parts/qualtek-719w-00-03-drawing.pdf | https://www.qualtekusa.com/images/AC_Receptacles/pdfs/719w0003.pdf
5 | 1 | Backup power inlet | LEMO | EGG.1B.302.CLL | M12 panel drill | Selected | Accept IP50; keying and rear nut clearance | docs/mechanical-parts/lemo-egg-1b-302-cll-datasheet.pdf | https://www.lemo.com/pdf/EGG.1B.302.CLL.pdf
6 | 1 | Dual-source low-voltage main power control | E-Switch | RA812C1121 | DPST snap-in rocker; 13.0 mm high x 19.2/19.4/19.62 mm wide by panel thickness | Selected | Panel must be <=3.0 mm at switch; verify snap retention and four FASTON clearances | docs/mechanical-parts/e-switch-ra812c1121-drawing.pdf | https://www.e-switch.com/product/ra8-series-illuminated-power-rocker-switch-with-pvc-cap/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
7 | 1 | CTIA headset jack | Kycon | STX-353K7A-6N-KTTR | Four-M3 service daughterboard plus positive panel capture bezel; short flexible harness to carrier | Selected | Release bezel/daughterboard coupon; final Z height and plug clearance; no mating load into PCB solder joints | docs/mechanical-parts/kycon-stx-353k7a-drawing.pdf | https://www.kycon.com/Catalog_PDF/STX-353K7A.pdf
8 | 2 | Green 12 V status indicator | Bulgin | DX06WG012B | 6 mm round cutout | Selected | Rear nut and lead clearance | docs/mechanical-parts/bulgin-dx06-indicators-catalog.pdf | https://www.bulgin.com/us/products/pub/media/bulgin/data/Indicators.pdf
9 | 1 | Yellow 12 V status indicator | Bulgin | DX06WY012B | 6 mm round cutout | Selected | Rear nut and lead clearance | docs/mechanical-parts/bulgin-dx06-indicators-catalog.pdf | https://www.bulgin.com/us/products/pub/media/bulgin/data/Indicators.pdf
10 | 1 | Blue 12 V status indicator | Bulgin | DX06WB012B | 6 mm round cutout | Selected | Rear nut and lead clearance | docs/mechanical-parts/bulgin-dx06-indicators-catalog.pdf | https://www.bulgin.com/us/products/pub/media/bulgin/data/Indicators.pdf
11 | 1 | White 12 V status indicator | Bulgin | DX06WW012B | 6 mm round cutout | Selected | Rear nut and lead clearance | docs/mechanical-parts/bulgin-dx06-indicators-catalog.pdf | https://www.bulgin.com/us/products/pub/media/bulgin/data/Indicators.pdf
12 | 1 | Red 12 V status indicator | Bulgin | DX06WR012B | 6 mm round cutout | Selected | Rear nut and lead clearance | docs/mechanical-parts/bulgin-dx06-indicators-catalog.pdf | https://www.bulgin.com/us/products/pub/media/bulgin/data/Indicators.pdf
13 | 2 | Sidewall enclosure fan | Delta | THA0412AD-TZW3 | 40 x 40 x 20 mm; 32 mm mounting pitch; 12 V; PWM/tach; right-wall intake and operator-wall exhaust | Selected | Measure wall ribs/taper and nearby hardware; 20.56 CFM free air; 1.385 inH2O; IP55 fan body; verify loaded-filter operating point and 45 C chamber performance | docs/mechanical-parts/delta-tha0412ad-tzw3-spec.pdf | https://www.delta-fan.com/tha0412ad-tzw3.html
14 | 1 | Sidewall intake filter guard | Qualtek | 09150-F/30 | 40 mm frame; 32 mm pitch; four 4.3 mm holes; right wall | Selected | Intake only; reinforcement plate; gasket; center aperture and filter service access | docs/mechanical-parts/qualtek-09150f-filter-drawing.pdf | https://www.qualtekusa.com/images/Fan%20Accessories/PDFDrawings/09150f.pdf
15 | 1 | Sidewall exhaust guard | Qualtek | 09150-G | 40 mm frame; 32 mm pitch; four 4.3 mm holes; operator wall | Selected | Add custom formed 5052-H32 downward splash hood; verify handle/frame clearance pressure loss finger safety drainage and external recirculation | docs/mechanical-parts/qualtek-09150g-guard-drawing.pdf | https://www.qualtekusa.com/Catalog/Fan_Accessories/PDFDrawings/09150g.pdf
16 | 2 | Nano-SIM holder | Wurth Elektronik | 693043020611 | Horizontal 76 x 40 mm SIM-SERVICE daughterboard on four matched M3 supports; direct 2.5 mm Hirose DF40 plug/socket; panel guide carries card loads | Selected | Verify 0.525 mm nominal panel clearance and 40 N insertion proof on stack coupon; no SIM harness | docs/mechanical-parts/wurth-693043020611-datasheet.pdf | https://www.we-online.com/components/products/datasheet/693043020611.pdf
17 | 4 | Wi-Fi bulkhead pigtail | TE Connectivity | 2016695-4 | RP-SMA jack bulkhead to MHF4/UMCC4; 200 mm | Conditional | AW7915-NP1 receptacle confirmation and route length | Manufacturer product page | https://www.te.com/usa-en/product-2016695-4.html
18 | 4 | Cellular bulkhead pigtail | TE Connectivity | 2016694-4 | SMA jack bulkhead to MHF4/UMCC4; 200 mm | Conditional | Installed modem receptacle confirmation and route length | Manufacturer product page | https://www.te.com/fr/product-2016694-4.html
19 | 1 | Gold Mount battery | Anton/Bauer | 8675-0125 | 99 x 132 x 58 mm manufacturer envelope | Selected | Release sweep with bracket and adjacent cables; battery removed for transport closure | Manufacturer product page | https://www.antonbauer.com/en/product/dionic-xt-90-gold-mount-battery/
20 | 1 | Gold Mount bracket | Anton/Bauer | 8375-0094 | QRC-GOLD; top-panel/custom-frame mounted and mechanically independent of all PCBs; approximately 119.4 x 76.2 x 12.7 mm excluding release latch; blind-mounted from rear with 6-32 screws; open-ended positive and negative leads connect by removable high-current harness to the power-selector PCB | User locked | Install supplied backplate; support shaded areas on flat panel/frame load path; physical sample; strain relief; latch travel; lead polarity and 12 A thermal verification | docs/mechanical-parts/anton-bauer-qrc-gold-installation.pdf | https://www.antonbauer.com/en/product/qrc-gold/
21 | 1 | Lid touchscreen | JUNEBOX | B0GK5X95D9 | Direct lid mount with sealed outside-in fasteners; no VESA plate; documented nominal body 396.24 W x 203.20 H x 20.32 D mm; hinge-edge HDMI USB and 12 V harness | User locked | Use documented body envelope for CAD; derive direct-mount drilling pattern thread screw engagement gasket and seals from received monitor; connector heads remain within hinge-edge envelope and do not add forward protrusion; verify cable bends and final lid clearance | Amazon listing | https://www.amazon.com/dp/B0GK5X95D9
22 | 2 | Diffused warm-white panel light | YIS Marine | LS102W | 22.0 mm round cutout / M22 x 1.5 body; 38 mm matte diffused face; 12 V; IP67 | Selected concept | Confirm nominal 3000 K sample; full-panel coverage; glare; rear depth; nut and lead clearance | Manufacturer product page | https://www.yismarine.com/en/product/LED_Step_Light_LS102.html
23 | 1 | Night-light capacitive touch control | E-Switch | CS7L2FR | 22.20 +0.25/-0.00 mm round cutout; O-ring and nut; six-wire harness | Selected | Sample coupon; O-ring compression; 20.70 mm rear body and lead bend clearance | docs/mechanical-parts/e-switch-cs7l2fr-drawing.pdf | https://www.e-switch.com/product/cs-series-illuminated-touch-sensor-anti-vandal-switch/
24 | 1 | Cellular modem dedicated fan | Delta | AFB0412SHB-SP04 | 40 x 40 x 15 mm; 12 V; 4-wire PWM/tach; attached to modem heatsink cartridge facing case floor | Selected | Exact modem heat spreader; structural bracket; 10 mm inlet clearance; RF pigtail clearance; thermal chamber test | docs/mechanical-parts/delta-afb0412shb-sp04-spec.pdf | https://www.delta-fan.com/products/dc-axial-fans/afb/AFB0412SHB-SP04.html
25 | 4 | Wi-Fi fold-down antenna | Taoglas | GW.05.0153 | 62.3 x 10 mm; hinged RP-SMA male; four RP-SMA jack bulkheads; folds inboard | Controlled validation candidate | Actual folded height and hinge sweep; 34 mm pitch; 12.7 mm latched-lid dynamic clearance; deployed 4T4R isolation throughput and regulatory test | docs/mechanical-parts/taoglas-gw05-0153-wifi-antenna.pdf | https://www.taoglas.com/product/gw-05-2-45-8ghz-monopole-antenna-rpsmam-hinged/
26 | 4 | Cellular fold-down antenna | Taoglas | TG.66.A113 | 70.3 x 9.7 mm; hinged SMA male; four SMA jack bulkheads; folds inboard | Controlled validation candidate | Actual folded height and hinge sweep; 34 mm pitch; 12.7 mm latched-lid dynamic clearance; deployed 4x4 MIMO isolation carrier certification and final modem port map | docs/mechanical-parts/taoglas-tg66-a113-cellular-antenna.pdf | https://www.taoglas.com/product/apex-tg-66-miniature-5g-4g-terminal/

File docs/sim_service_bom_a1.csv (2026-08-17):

Reference | Value | Footprint | Manufacturer | MPN | Assembly | Qty | DNP
J1 | DUAL_SIM_B2B_RECEPTACLE | CM5Carrier:Hirose_DF40HC(2.5)-20DS-0.4V_2x10_P0.4mm | Hirose Electric | DF40HC(2.5)-20DS-0.4V(51) |  | 1
J2 | SIM1_NANO_SIM | CM5Carrier:J_Wurth_WR-CRD_693043020611 | Wurth Elektronik | 693043020611 |  | 1
J3 | SIM2_NANO_SIM | CM5Carrier:J_Wurth_WR-CRD_693043020611 | Wurth Elektronik | 693043020611 |  | 1
U1 | TPD3F303DPV | Package_SON:Texas_R-PUSON-N8_USON-8-1EP_1.6x2.1mm_P0.5mm_EP0.4x1.7mm | Texas Instruments | TPD3F303DPVR |  | 1
U2 | TPD3F303DPV | Package_SON:Texas_R-PUSON-N8_USON-8-1EP_1.6x2.1mm_P0.5mm_EP0.4x1.7mm | Texas Instruments | TPD3F303DPVR |  | 1

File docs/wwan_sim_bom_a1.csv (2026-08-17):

Reference | Value | Footprint | Manufacturer | MPN | Assembly | Qty | DNP
C701 | 220uF 6.3V polymer | Capacitor_SMD:CP_Elec_8x6.9 | Panasonic | 6SVP220MX |  | 1
C702 | 220uF 6.3V polymer | Capacitor_SMD:CP_Elec_8x6.9 | Panasonic | 6SVP220MX |  | 1
C703 | 100nF | Capacitor_SMD:C_0402_1005Metric | TDK | C1005X7R1H104K050BB |  | 1
C704 | 6.8nF C0G | Capacitor_SMD:C_0603_1608Metric | Murata | GRM1885C1H682JA01D |  | 1
C705 | 220pF C0G | Capacitor_SMD:C_0402_1005Metric | Murata | GRM1555C1H221JA01D |  | 1
C706 | 68pF C0G | Capacitor_SMD:C_0402_1005Metric | Murata | GRM1555C1H680JA01D |  | 1
C707 | 100nF | Capacitor_SMD:C_0402_1005Metric | TDK | C1005X7R1H104K050BB |  | 1
C708 | 220pF C0G | Capacitor_SMD:C_0402_1005Metric | Murata | GRM1555C1H221JA01D |  | 1
C709 | 68pF C0G | Capacitor_SMD:C_0402_1005Metric | Murata | GRM1555C1H680JA01D |  | 1
C710 | 15pF C0G | Capacitor_SMD:C_0402_1005Metric | Murata | GRM1555C1H150JA01D |  | 1
C711 | 9.1pF C0G | Capacitor_SMD:C_0402_1005Metric | Murata | GRM1555C1H9R1BA01D |  | 1
C712 | 4.7pF C0G | Capacitor_SMD:C_0402_1005Metric | Murata | GRM1555C1H4R7BA01D |  | 1
D701 | 5.0V TVS | Diode_SMD:D_SOD-123F | Littelfuse | SMF4L5.0AT1G |  | 1
J701 | WWAN_M2_B_KEY_USB3_USB2 | CM5Carrier:TE_2199230-3_M2_Key_B_4.2mm | TE Connectivity | 2199230-3 |  | 1
J702 | DUAL_SIM_B2B_PLUG | CM5Carrier:Hirose_DF40C-20DP-0.4V_2x10-1MP_P0.4mm | Hirose Electric | DF40C-20DP-0.4V(51) |  | 1
J711 | CELL_1_RF |  | ECT | 818033349 |  | 1
J712 | CELL_2_RF |  | ECT | 818033349 |  | 1
J713 | CELL_3_RF |  | ECT | 818033349 |  | 1
J714 | CELL_4_GNSS_RF |  | ECT | 818033349 |  | 1
R701 | 100k | Resistor_SMD:R_0603_1608Metric | Yageo | RC0603FR-07100KL |  | 1
U702 | TPD4E05U06DQA | Package_SON:USON-10_2.5x1.0mm_P0.5mm | Texas Instruments | TPD4E05U06DQAR |  | 1
U703 | TPD4E05U06DQA | Package_SON:USON-10_2.5x1.0mm_P0.5mm | Texas Instruments | TPD4E05U06DQAR |  | 1
U704 | FSA2567MPX | Package_DFN_QFN:WQFN-16-1EP_3x3mm_P0.5mm_EP1.68x1.68mm | onsemi | FSA2567MPX |  | 1

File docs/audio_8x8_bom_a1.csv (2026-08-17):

Sheet | Reference | Value | Footprint | Manufacturer | MPN | Qty | RoutingGate
Audio-TDM-Clock | C101 | 100nF | Capacitor_SMD:C_0402_1005Metric | TDK | C1005X7R1H104K050BB | 1
Audio-TDM-Clock | C102 | 100nF | Capacitor_SMD:C_0402_1005Metric | TDK | C1005X7R1H104K050BB | 1
Audio-TDM-Clock | C103 | 100nF | Capacitor_SMD:C_0402_1005Metric | TDK | C1005X7R1H104K050BB | 1
Audio-TDM-Clock | C104 | 100nF | Capacitor_SMD:C_0402_1005Metric | TDK | C1005X7R1H104K050BB | 1
Audio-TDM-Clock | C105 | 100nF | Capacitor_SMD:C_0402_1005Metric | TDK | C1005X7R1H104K050BB | 1
Audio-TDM-Clock | C106 | 4.7uF | Capacitor_SMD:C_0805_2012Metric | Murata | GRM21BR71A475KA73L | 1
Audio-TDM-Clock | C107 | 100nF | Capacitor_SMD:C_0402_1005Metric | TDK | C1005X7R1H104K050BB | 1
Audio-TDM-Clock | J101 | AUDIO_TDM_CONTROL | Connector_Molex_Milligrid:Molex_8783230xx_2x15_P2.0mm_Header_Vertical_Polarized_MountingPegs | Molex | 87832-6423 | 1
Audio-TDM-Clock | R111 | 10k 0.1% | Resistor_SMD:R_0603_1608Metric | Yageo | RC0603FR-0710KL | 1
Audio-TDM-Clock | R112 | 10k 0.1% | Resistor_SMD:R_0603_1608Metric | Yageo | RC0603FR-0710KL | 1
Audio-TDM-Clock | R113 | 10k 0.1% | Resistor_SMD:R_0603_1608Metric | Yageo | RC0603FR-0710KL | 1
Audio-TDM-Clock | R114 | 10k 0.1% | Resistor_SMD:R_0603_1608Metric | Yageo | RC0603FR-0710KL | 1
Audio-TDM-Clock | R115 | 4.7k 0.1% | Resistor_SMD:R_0603_1608Metric | Yageo | RC0603FR-074K7L | 1
Audio-TDM-Clock | R116 | 4.7k 0.1% | Resistor_SMD:R_0603_1608Metric | Yageo | RC0603FR-074K7L | 1
Audio-TDM-Clock | R117 | 100k 1% | Resistor_SMD:R_0603_1608Metric | Yageo | RC0603FR-07100KL | 1
Audio-TDM-Clock | U101 | SN65LVDT2D | Package_SO:SOIC-8_3.9x4.9mm_P1.27mm | Texas Instruments | SN65LVDT2DR | 1
Audio-TDM-Clock | U102 | SN65LVDT2D | Package_SO:SOIC-8_3.9x4.9mm_P1.27mm | Texas Instruments | SN65LVDT2DR | 1
Audio-TDM-Clock | U103 | SN65LVDT2D | Package_SO:SOIC-8_3.9x4.9mm_P1.27mm | Texas Instruments | SN65LVDT2DR | 1
Audio-TDM-Clock | U104 | SN65LVDT2D | Package_SO:SOIC-8_3.9x4.9mm_P1.27mm | Texas Instruments | SN65LVDT2DR | 1
Audio-TDM-Clock | U105 | SN65LVDS1D | Package_SO:SOIC-8_3.9x4.9mm_P1.27mm | Texas Instruments | SN65LVDS1DR | 1
Audio-TDM-Clock | U106 | SN74LVC1G11DBVR | Package_TO_SOT_SMD:SOT-23-6 | Texas Instruments | SN74LVC1G11DBVR | 1
AK5558-ADC | C261 | 100nF | Capacitor_SMD:C_0402_1005Metric | TDK | C1005X7R1H104K050BB | 1
AK5558-ADC | C262 | 100nF | Capacitor_SMD:C_0402_1005Metric | TDK | C1005X7R1H104K050BB | 1
AK5558-ADC | C263 | 100nF | Capacitor_SMD:C_0402_1005Metric | TDK | C1005X7R1H104K050BB | 1
AK5558-ADC | C264 | 100nF | Capacitor_SMD:C_0402_1005Metric | TDK | C1005X7R1H104K050BB | 1
AK5558-ADC | C271 | 100uF 6.3V polymer | Capacitor_SMD:CP_Elec_6.3x5.8 | Panasonic | 6SVP100M | 1
AK5558-ADC | C272 | 100uF 6.3V polymer | Capacitor_SMD:CP_Elec_6.3x5.8 | Panasonic | 6SVP100M | 1
AK5558-ADC | C273 | 100uF 6.3V polymer | Capacitor_SMD:CP_Elec_6.3x5.8 | Panasonic | 6SVP100M | 1
AK5558-ADC | C274 | 100uF 6.3V polymer | Capacitor_SMD:CP_Elec_6.3x5.8 | Panasonic | 6SVP100M | 1
AK5558-ADC | C281 | 4.7uF | Capacitor_SMD:C_0805_2012Metric | Murata | GRM21BR71A475KA73L | 1
AK5558-ADC | C282 | 100nF | Capacitor_SMD:C_0402_1005Metric | TDK | C1005X7R1H104K050BB | 1
AK5558-ADC | C283 | 10uF | Capacitor_SMD:C_0603_1608Metric | Murata | GRM188R71A106KA73D | 1
AK5558-ADC | C284 | 100nF | Capacitor_SMD:C_0402_1005Metric | TDK | C1005X7R1H104K050BB | 1
AK5558-ADC | C285 | 10uF | Capacitor_SMD:C_0603_1608Metric | Murata | GRM188R71A106KA73D | 1
AK5558-ADC | C286 | 100nF | Capacitor_SMD:C_0402_1005Metric | TDK | C1005X7R1H104K050BB | 1
AK5558-ADC | C287 | 10uF | Capacitor_SMD:C_0603_1608Metric | Murata | GRM188R71A106KA73D | 1
AK5558-ADC | R221 | 10k 0.1% | Resistor_SMD:R_0603_1608Metric | Yageo | RC0603FR-0710KL | 1
AK5558-ADC | R222 | 10k 0.1% | Resistor_SMD:R_0603_1608Metric | Yageo | RC0603FR-0710KL | 1
AK5558-ADC | R223 | 10k 0.1% | Resistor_SMD:R_0603_1608Metric | Yageo | RC0603FR-0710KL | 1
AK5558-ADC | R224 | 10k 0.1% | Resistor_SMD:R_0603_1608Metric | Yageo | RC0603FR-0710KL | 1
AK5558-ADC | R225 | 10k 0.1% | Resistor_SMD:R_0603_1608Metric | Yageo | RC0603FR-0710KL | 1
AK5558-ADC | R226 | 10k 0.1% | Resistor_SMD:R_0603_1608Metric | Yageo | RC0603FR-0710KL | 1
AK5558-ADC | R227 | 10k 0.1% | Resistor_SMD:R_0603_1608Metric | Yageo | RC0603FR-0710KL | 1
AK5558-ADC | R228 | 10k 0.1% | Resistor_SMD:R_0603_1608Metric | Yageo | RC0603FR-0710KL | 1
AK5558-ADC | R241 | 10k 0.1% | Resistor_SMD:R_0603_1608Metric | Yageo | RC0603FR-0710KL | 1
AK5558-ADC | R242 | 10k 0.1% | Resistor_SMD:R_0603_1608Metric | Yageo | RC0603FR-0710KL | 1
AK5558-ADC | R243 | 10k 0.1% | Resistor_SMD:R_0603_1608Metric | Yageo | RC0603FR-0710KL | 1
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

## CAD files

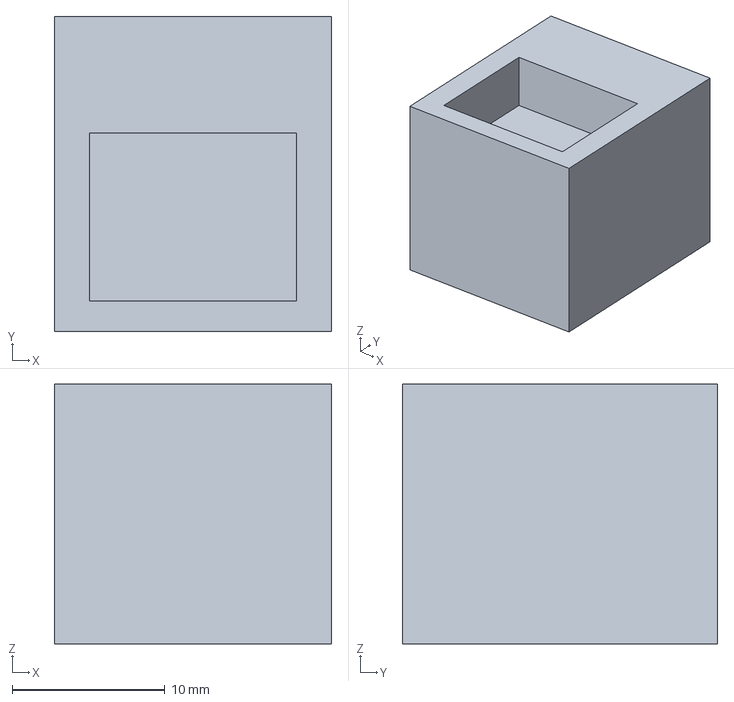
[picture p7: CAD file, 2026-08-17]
references/components/bel/V8BR-1AX1-GH/Bel_V8BR_1AX1_GH.step
18.2 x 20.6 x 17.0 mm

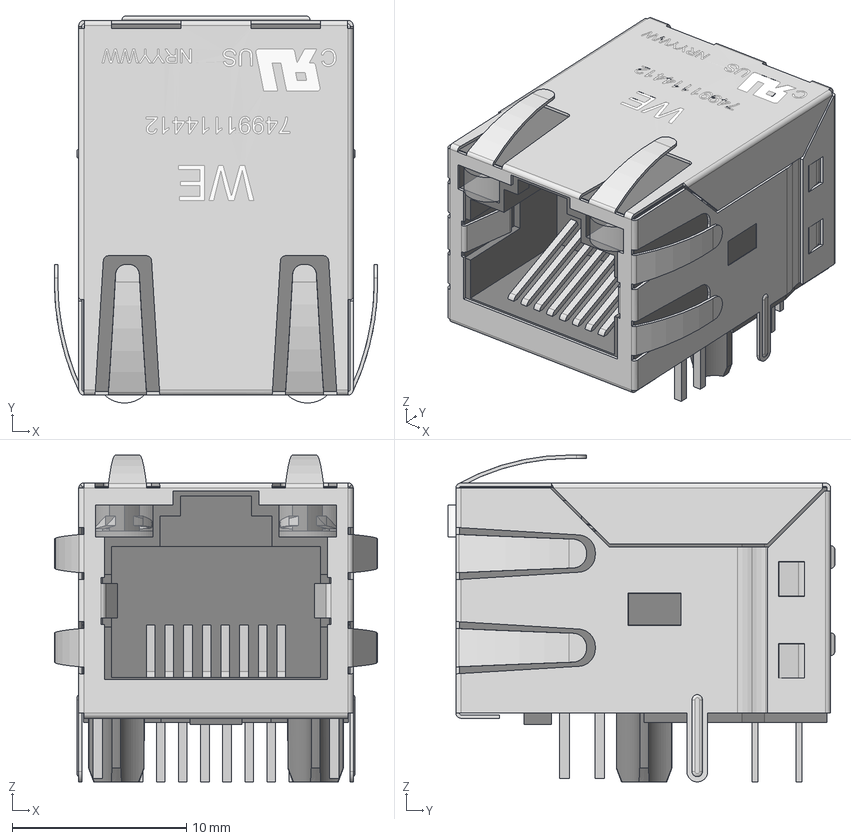
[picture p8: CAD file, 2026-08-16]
references/components/wurth/74991114412/T_Wurth_WE-RJ45LAN_74991114412.step
18.6 x 22.2 x 18.8 mm

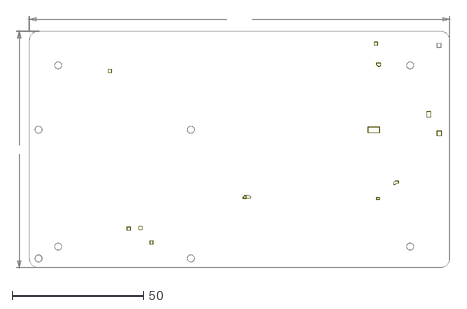
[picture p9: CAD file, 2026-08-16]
references/radxa-cm-projects/cm5/radxa-cm5-io-board/radxa_cm5_io_board_v2200_2d_bottom.dxf
165.6 x 96.3

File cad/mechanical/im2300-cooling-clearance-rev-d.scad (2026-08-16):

// ProComm iM2300 cooling and vertical-stack concept Rev D / mechanical gate A2.
// All dimensions are millimeters and remain preliminary until the actual case is measured.
$fn = 48;

inner_x = 431.8;
inner_y = 298.0;
bottom_depth = 106.7;
panel_below_parting = 38.1;
panel_top_z = bottom_depth - panel_below_parting; // 68.6 mm above nominal deepest floor.
panel_t = 3.175;
panel_underside_z = panel_top_z - panel_t; // 65.425 mm.
tray_t = 2.0;
tray_top_z = 3.0; // Includes any released rigid mounting/isolator stack.
carrier_z = 58.0;
carrier_t = 1.6;
standoff_h = panel_underside_z - (carrier_z + carrier_t);
audio_supports = [[47,21],[87,21],[47,149],[87,149],[47,277],[87,277]];
carrier_supports = [[225,21],[379,21],[225,149],[331,149],[225,277],[379,205]];

cpu_cm5_bottom_z = 53.4;
cpu_sink_h = 10.0;
cpu_adapter_h = 3.0;
cpu_fan_h = 28.0;
cpu_fan_bottom_z = cpu_cm5_bottom_z - cpu_sink_h - cpu_adapter_h - cpu_fan_h;
cpu_floor_gap = cpu_fan_bottom_z;

modem_card_bottom_z = 53.0;
modem_sink_h = 8.0;
modem_adapter_h = 4.0;
modem_fan_h = 15.0; // Delta AFB0412SHB-SP04.
modem_fan_bottom_z = modem_card_bottom_z - modem_sink_h - modem_adapter_h - modem_fan_h;
modem_floor_gap = modem_fan_bottom_z;

audio_quiet_boundary_x = 98.0;
psu_guard_x = 244.0;
psu_audio_gap = psu_guard_x - audio_quiet_boundary_x;
psu_guard_top_z = 48.0;
psu_carrier_gap = carrier_z - psu_guard_top_z;
lid_harness_corridor_right_x = 229.0;
lid_harness_psu_gap = psu_guard_x - lid_harness_corridor_right_x;

assert(cpu_floor_gap >= 10.0, "CM5 dedicated fan inlet clearance is below 10 mm");
assert(modem_floor_gap >= 10.0, "Modem dedicated fan inlet clearance is below 10 mm");
assert(abs(panel_underside_z - 65.425) < 0.001, "Panel underside nominal stack is inconsistent");
assert(tray_top_z <= 3.0, "Bottom equipment tray top exceeds the 3 mm limit");
assert(psu_guard_top_z <= 48.0, "Installed PSU/guard envelope exceeds 48 mm");
assert(panel_underside_z - (carrier_z + carrier_t) >= 4.0, "Carrier F.Cu gap to panel underside is below 4 mm");
assert(psu_audio_gap >= 125.0, "PSU guard is less than 125 mm from the audio quiet boundary");
assert(psu_carrier_gap >= 10.0, "PSU guard clearance to the carrier is below 10 mm");
assert(lid_harness_psu_gap >= 15.0, "Lid-harness corridor is less than 15 mm from the PSU guard");
assert(standoff_h > 0, "PCB standoff stack has no positive height");
assert(len(audio_supports) == 6, "AUDIO-8X8 must have six controlled supports");
assert(len(carrier_supports) == 6, "CM5-CARRIER must have six controlled supports");
echo(str("Panel top above floor: ", panel_top_z, " mm"));
echo(str("Panel underside above floor: ", panel_underside_z, " mm"));
echo(str("Tray top to panel underside: ", panel_underside_z - tray_top_z, " mm"));
echo(str("CM5 fan inlet gap: ", cpu_floor_gap, " mm"));
echo(str("Modem fan inlet gap: ", modem_floor_gap, " mm"));
echo(str("PSU guard to audio quiet boundary: ", psu_audio_gap, " mm"));
echo(str("PSU guard to carrier clearance: ", psu_carrier_gap, " mm"));
echo(str("Lid-harness corridor to PSU guard: ", lid_harness_psu_gap, " mm"));
echo(str("PCB standoff body height: ", standoff_h, " mm"));

module colored_box(size, color_value, alpha = 1.0) {
  color([color_value[0], color_value[1], color_value[2], alpha]) cube(size);
}

module fan_body(size = [40, 40, 20], axis = "z", body_color = [0.15, 0.32, 0.58]) {
  color(body_color) difference() {
    cube(size);
    if (axis == "z") translate([size[0] / 2, size[1] / 2, -1]) cylinder(h = size[2] + 2, d = min(size[0], size[1]) - 6);
    if (axis == "x") translate([-1, size[1] / 2, size[2] / 2]) rotate([0, 90, 0]) cylinder(h = size[0] + 2, d = min(size[1], size[2]) - 6);
    if (axis == "y") translate([size[0] / 2, -1, size[2] / 2]) rotate([-90, 0, 0]) cylinder(h = size[1] + 2, d = min(size[0], size[2]) - 6);
  }
}

module finned_sink(size = [55, 40, 10]) {
  color([0.88, 0.64, 0.18]) {
    cube([size[0], size[1], 2]);
    for (x = [2:6:size[0] - 2]) translate([x, 0, 2]) cube([2, size[1], size[2] - 2]);
  }
}

module pcb_standoff() {
  color([0.82, 0.84, 0.86]) difference() {
    cylinder(h = standoff_h, d = 7.0);
    translate([0, 0, -0.2]) cylinder(h = standoff_h + 0.4, d = 3.0);
  }
}

// Transparent nominal cavity. Z=0 is the deepest nominal interior floor.
color([0.75, 0.80, 0.84, 0.10]) difference() {
  translate([-4, -4, -3]) cube([inner_x + 8, inner_y + 8, bottom_depth + 3]);
  translate([0, 0, 0]) cube([inner_x, inner_y, bottom_depth + 1]);
}
color([0.20, 0.23, 0.27]) translate([0, 0, -3]) cube([inner_x, inner_y, 3]);

// Low-profile bottom equipment-tray reference. Actual outline follows measured floor ribs.
color([0.48, 0.52, 0.58, 0.40]) {
  translate([90, 15, tray_top_z - tray_t]) cube([258, 3, tray_t]);
  translate([90, 280, tray_top_z - tray_t]) cube([258, 3, tray_t]);
  translate([90, 15, tray_top_z - tray_t]) cube([3, 268, tray_t]);
  translate([345, 15, tray_top_z - tray_t]) cube([3, 268, tray_t]);
}

// Top-panel perimeter reference only, leaving the interior open for inspection.
// The actual panel is a solid plate with no cooling cutouts.
translate([0, 0, panel_underside_z]) {
  colored_box([inner_x, 8, panel_t], [0.70, 0.75, 0.80], 0.45);
  translate([0, inner_y - 8, 0]) colored_box([inner_x, 8, panel_t], [0.70, 0.75, 0.80], 0.45);
  colored_box([8, inner_y, panel_t], [0.70, 0.75, 0.80], 0.45);
  translate([inner_x - 8, 0, 0]) colored_box([8, inner_y, panel_t], [0.70, 0.75, 0.80], 0.45);
}

// Suspended PCBs.
translate([15, 15, carrier_z]) colored_box([78, 268, carrier_t], [0.12, 0.62, 0.70], 0.85); // AUDIO-8X8
// CM5 carrier is drawn as an outline so the B.Cu cooling hardware remains visible.
translate([219, 15, carrier_z]) {
  colored_box([166, 5, carrier_t], [0.15, 0.66, 0.38], 0.90);
  translate([0, 263, 0]) colored_box([166, 5, carrier_t], [0.15, 0.66, 0.38], 0.90);
  colored_box([5, 268, carrier_t], [0.15, 0.66, 0.38], 0.90);
  translate([161, 0, 0]) colored_box([5, 268, carrier_t], [0.15, 0.66, 0.38], 0.90);
}

// Controlled A1-A6 and C1-C6 rigid panel-to-PCB supports. Panel/frame screws
// and connector fasteners are separate systems and are not represented here.
for (p = audio_supports) translate([p[0], p[1], carrier_z + carrier_t]) pcb_standoff();
for (p = carrier_supports) translate([p[0], p[1], carrier_z + carrier_t]) pcb_standoff();

// Guarded hinge/display-side PSU bay on the bottom floor. The supply is rotated
// 90 degrees in plan and moved into the digital side to protect the audio zone.
translate([250, 21, tray_top_z]) colored_box([86, 130, 43], [0.82, 0.25, 0.20], 0.75);
color([0.95, 0.47, 0.39, 0.22]) translate([psu_guard_x, 15, 0]) cube([98, 142, psu_guard_top_z]);

// Carrier B.Cu keepout directly above the guarded PSU bay.
color([0.95, 0.47, 0.39, 0.52]) translate([psu_guard_x, 15, carrier_z - 0.3]) difference() {
  cube([98, 142, 0.6]);
  translate([2, 2, -0.1]) cube([94, 138, 0.8]);
}

// Power selector board remains in the center/operator-side floor bay.
translate([96, 190, tray_top_z]) colored_box([116, 80, 18], [0.62, 0.37, 0.80], 0.62);

// CM5 cooling cartridge on carrier B.Cu, facing down.
cpu_x = 318.5;
cpu_y = 240.0;
translate([cpu_x, cpu_y, 55.0]) colored_box([55, 40, 1.6], [0.12, 0.70, 0.38], 0.95);
translate([cpu_x, cpu_y, cpu_cm5_bottom_z - cpu_sink_h]) finned_sink([55, 40, cpu_sink_h]);
translate([cpu_x + 2, cpu_y + 1, cpu_cm5_bottom_z - cpu_sink_h - cpu_adapter_h]) colored_box([51, 38, cpu_adapter_h], [0.55, 0.30, 0.67], 0.75);
translate([cpu_x + 7.5, cpu_y, cpu_fan_bottom_z]) fan_body([40, 40, cpu_fan_h], "z");
color([0.78, 0.48, 0.90]) translate([cpu_x - 4, cpu_y - 4, cpu_fan_bottom_z]) difference() {
  cube([63, 48, 43]);
  translate([4, 4, -1]) cube([55, 40, 45]);
}

// Universal 3052 M.2 WWAN cooling cartridge on carrier B.Cu, facing down.
modem_x = 350.0;
modem_y = 116.0;
translate([modem_x, modem_y, 54.0]) colored_box([30, 52, 1.2], [0.83, 0.60, 0.18], 0.95);
translate([modem_x - 5, modem_y + 6, modem_card_bottom_z - modem_sink_h]) finned_sink([40, 40, modem_sink_h]);
translate([modem_x - 3, modem_y + 7, modem_card_bottom_z - modem_sink_h - modem_adapter_h]) colored_box([36, 38, modem_adapter_h], [0.55, 0.30, 0.67], 0.75);
translate([modem_x - 5, modem_y + 6, modem_fan_bottom_z]) fan_body([40, 40, modem_fan_h], "z", [0.22, 0.42, 0.62]);

// Right-side filtered intake and operator-side exhaust.
translate([inner_x - 20, 190, 24]) fan_body([20, 40, 40], "x", [0.18, 0.55, 0.34]);
translate([290, inner_y - 20, 24]) fan_body([40, 20, 40], "y", [0.72, 0.52, 0.20]);
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

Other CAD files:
cad/mechanical/im2300-cooling-clearance-rev-a.scad
cad/mechanical/im2300-cooling-clearance-rev-b.scad
cad/mechanical/im2300-cooling-clearance-rev-c.scad

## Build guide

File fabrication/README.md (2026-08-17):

# Fabrication Outputs

Place manufacturing outputs here when the design is ready.

The controlled one-shot PCBWay release gate is under `pcbway-release/`. Its
manifest covers all production PCBs, machined enclosure parts, harnesses,
source files, test instructions, and physical signoffs. The archive builder
will not run while any required release item is open or missing.

Expected outputs:

- Gerbers
- Drill files
- Pick-and-place / CPL
- BOM
- Assembly drawing
- Fabrication drawing
- Design rule report

Controlled harness work instructions are under `harnesses/`. They remain
prototype-controlled until their finished lengths are verified in the first
mechanical article.

The current mechanical gate is `mechanical-release/` revision A2 and remains
`HOLD_FOR_MEASUREMENT`. Rev L nominal envelopes and controlled PCB support
coordinates may be used for engineering layout. Production panel, tray,
sidewall, and final drilling files are prohibited until all M001-M080 checks
and signoffs are complete.

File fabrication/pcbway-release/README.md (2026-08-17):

# PCBWay One-Shot Release Package

## Status

**HOLD_ENGINEERING**

This directory is the only controlled entry point for the final PCBWay
submission. Do not upload concept SVGs, schematic-only projects, partial BOMs,
or preliminary Gerbers as a production order. The final archive is built only
after `validate_release.py --release` passes.

The current repository is not yet a production package:

- the sixteen detailed schematic sheets pass ERC;
- `CM5-CARRIER`, `AUDIO-8X8`, and `PWR-SELECT` now have native `.kicad_pcb`
  placement baselines with complete netlists, but they are deliberately
  unrouted and are not fabrication files;
- no production-board Gerber, NC-drill, CPL, assembly-drawing, or board STEP
  outputs exist;
- ten physical footprint-coupon results still block final route freeze and fabrication release;
- 11 component rows still block production release;
- mechanical release A2 remains `HOLD_FOR_MEASUREMENT`.

The footprint coupon is a separate qualification order. Its ready-to-upload
factory package is in `../footprint-coupon-a1/`. Passing CAD review on that
coupon does not close the physical X-ray, microsection, insertion, seating,
and pin-map requirements.

## One-Shot Rule

PCBWay receives one controlled archive after every required row in
`release-manifest-a0.csv` is `READY`, all referenced files exist, the physical
signoffs are attached, and the release validator passes. Any replacement made
after archive creation requires a new package revision and checksum file.

PCBWay's current PCBA guidance requires Gerbers, BOM, and centroid/pick-and-
place data. Their detailed assembly guidance also calls for copper,
silkscreen, solder-paste, NC-drill, and fabrication/assembly information. The
project adds schematic PDFs, 3D STEP, controlled stackup/impedance data,
polarity drawings, harness instructions, programming data, and acceptance
tests because this assembly is too complex to rely on minimum upload fields.

Official references:

- https://www.pcbway.com/assembly-file-requirements.html
- https://www.pcbway.com/assembly-process.html
- https://www.pcbway.com/helpcenter/Findproducts/How_do_I_place_an_order_.html

## Package Structure

The final archive contains five independently reviewable packages:

1. `01-cm5-carrier`: routed carrier fabrication, assembly, source, and test
   data.
2. `02-audio-8x8`: routed balanced-audio fabrication, assembly, source, and
   audio test data.
3. `03-pwr-select`: routed no-blink source-selector fabrication, assembly,
   source, and power-transfer test data.
4. `04-mechanical`: released top panel, four-side frame, bottom tray, sidewall
   fan openings/reinforcements, guards, hoods, datums, tolerances, material,
   finish, and inspection drawings.
5. `05-harness-test`: H01/H02/H03 and interboard harness drawings, wire tables,
   labels, lengths, strain relief, firmware/programming package, bring-up,
   calibration, and final acceptance procedure.

## Release Sequence

1. Build and sign Footprint Coupon A1.
2. Complete the actual-case mechanical register M001-M080 and pass
   `validate_mechanical_release.py --release`.
3. Freeze the PCBWay-controlled stackups and impedance tables.
4. Route the three production boards and complete SI, PI, thermal, safety, and
   current-density review.
5. Close every production MPN, DNP, polarity, and customer-supplied-part row.
6. Generate and independently inspect Gerber, NC drill, BOM, CPL, drawings,
   STEP, and source archives for each board.
7. Complete harness, programming, calibration, and acceptance files.
8. Run `python3 validate_release.py --release`, then
   `python3 build_submission.py`.

## Factory Change Control

- PCBWay may not substitute a component, alter copper, resize holes, change
  stackup, modify paste apertures, or change machined geometry without written
  engineering approval.
- All questions must reference the package revision, manifest item ID, board
  revision, and affected designators.
- The package checksum list controls every uploaded file.
- First build is an engineering first article. Production quantity is released
  only after electrical, thermal, RF, audio, source-transfer, mechanical,
  vibration, and safety acceptance passes.

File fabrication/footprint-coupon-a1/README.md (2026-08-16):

# Footprint Coupon A1 Fabrication Package

This directory contains the controlled manufacturing package for the Radxa CM5
ProComm footprint qualification coupon.

## Release state

- CAD generation: complete.
- KiCad validation: complete.
- KiCad DRC: zero violations.
- Bare-board fabrication: pending.
- Assembly and X-ray qualification: pending.
- AUDIO-8X8 / CM5-CARRIER routing release: blocked pending signed results.

## Factory files

Run `build_release.sh` to regenerate:

- `output/gerbers/`: six copper layers, paste, mask, legend, and outline.
- `output/drill/`: separate plated and non-plated Excellon files, drill map,
  and drill report.
- `output/drawings/`: fabrication and assembly PDFs.
- `output/placement/`: CSV component positions.
- `output/renders/`: top and bottom board renders.
- `output/filled_via_coordinates.csv`: the 50 selective Type VII vias.
- `output/Footprint-Coupon-A1-Gerber-Drill.zip`: upload archive.
- `output/SHA256SUMS.txt`: release checksums.

Read `PCBWAY_RFQ.md` and `ASSEMBLY_AND_INSPECTION.md` before quoting. Do not
substitute via treatment, hole sizes, finish, stackup, stencil, or component
part numbers without written engineering approval.

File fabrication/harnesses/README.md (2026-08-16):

# Controlled Harnesses

This folder contains cable-assembly definitions for the Radxa CM5 ProComm
field unit.

- `H01-PSU-24V.md`: bottom-mounted RPS-400-24-C 24 V output to PWR-SELECT
- `H01-PSU-24V-BOM.csv`: exact H01 connector and termination parts
- `H02-PSU-AC.md`: fused C14 inlet to PSU CN1 mains harness and PE boundary
- `PSU-Harness-Interfaces.svg` and `.png`: factory visual separating the H01
  and H02 pinouts
- `H03-Lid-Display-Bundle.md`: HDMI, USB-touch, and 12 V monitor cable build,
  service-loop, and motion-test requirements
- `H03-Lid-Display-BOM.csv`: controlled starting parts for the display bundle
- `H03-Lid-Display-Bundle.svg` and `.png`: factory motion/loop visual

Harness lengths are prototype values until the first fully dressed mechanical
article is measured. Do not release a production cable solely from a concept
floorplan.

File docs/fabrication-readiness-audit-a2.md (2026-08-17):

# Fabrication Readiness Audit A2

## Release State

**HOLD_FOR_MEASUREMENT**

This audit is the factory-facing mechanical and thermal gate before final
machining and fabrication release. Rev L is the controlled nominal basis for
engineering PCB envelopes, supports, placement, and routing, but it is not a
panel cut file. No production panel, sidewall, bottom tray, or final machining
pattern may be released until every row M001-M080 is complete and the A2
validator passes with the release option.

## Corrections Made In A2

1. The prior 68.6 mm value was the nominal distance from the deepest base floor
   to the top face of the recessed panel. It was incorrectly described as
   usable space below the panel. With a 3.175 mm panel, nominal clear height
   below the panel underside is 65.425 mm.
2. The Gold-mount closure study omitted the QRC-GOLD plate. The Dionic XT90 is
   58 mm deep and the plate is approximately 12.7 mm before latch tolerance,
   producing an approximately 70.7 mm protrusion. This is expected to interfere
   with the lid monitor. The battery must be removed before closing the case.
3. Upright RF antennas cannot close under the lid. The transport configuration
   keeps the released compact hinged antenna set installed and folds all eight
   antennas inboard. The linked 163 mm Sierra paddle is a form-factor reference,
   not the released part: its folded arm crosses other panel controls. Current
   candidates are Taoglas `GW.05.0153` for Wi-Fi and `TG.66.A113` for cellular.
   Actual samples still require a measured sweep and signoff.
4. The locked monitor listing documents a nominal body envelope of 15.6 W x
   8.0 H x 0.8 D inches, or 396.24 x 203.20 x 20.32 mm. These dimensions are
   controlled for lid CAD. Physical verification is limited to the installed
   stack: direct lid-mount hole coordinates, thread and screw engagement,
   sealed outside-in fasteners, gasket buildup, connector positions,
   rear-edge containment of the connector heads, cable bend envelopes,
   cable bends, lid placement, and the final closure sweep.
5. The RPS-400-24-C is 43 mm high, and the carrier overlaps it in plan. The
   complete tray-mounted PSU and terminal guard is limited to 48 mm above the
   deepest floor, with 10 mm minimum to carrier B.Cu. This is a tight measured
   stack, not a nominal promise.
6. AUDIO-8X8 now requires at least six supports. Four corner supports are not
   enough for a 268 mm portable-field board carrying sixteen XLR interfaces.
7. The cellular modem fan is selected as Delta AFB0412SHB-SP04, 40 x 40 x
   15 mm, 12 V, four-wire PWM/tach. Its 15 mm depth improves the bottom inlet
   margin compared with the earlier 20 mm placeholder.
8. The exhaust finger guard is selected as Qualtek 09150-G. A custom formed
   5052-H32 downward splash hood remains a custom mechanical part and must be
   validated for restriction and recirculation.
9. The closed-lid drawing is a composite side projection, not a literal cut
   through one XY station. The PSU and CM5 cooling cartridge are separated in
   the hinge-to-handle direction by the Rev L floorplan; their horizontal
   positions are separated in the projection for readability. Rev L and the
   final STEP model, not the side projection, control XY collision checks.

## Controlled Materials

| Assembly | Material / construction | Release rule |
| --- | --- | --- |
| Top panel | 3.175 mm nominal 5052-H32 aluminum | Accept 3.0-3.3 mm coupon; matte black powder coat; mask PE and chassis-bond points; local RA812 rear pocket no thicker than 3.0 mm |
| Four-side support frame | 5052-H32 or 6061-T6 aluminum, final section from measured case | Continuous support, 15 mm minimum support/no-PCB band, panel screws independent of PCB standoffs |
| Bottom equipment tray | 2.0 mm nominal 5052-H32 aluminum | Rigid low-profile tray; top no more than 3.0 mm above deepest local floor; no thick compressible foam under PSU |
| PSU terminal guard | Grounded perforated aluminum or UL94 V-0 insulating cover as required by safety review | No exposed mains; maintain airflow, creepage, service-tool clearance, and 48 mm total installed envelope |
| Fan reinforcement plates | 1.5-2.0 mm 5052-H32 aluminum | Separate plate and closed-cell gasket at each modified HPX sidewall |
| Splash hoods | Formed 5052-H32 aluminum | Downward-facing, finger-safe, drainable, and tested for pressure loss and hot-air recirculation |
| PCB supports | Captive M3 metal standoffs with prevailing-torque hardware | Six minimum per long PCB; add supports beside heavy parts and panel connectors |
| Seals / isolation | Closed-cell EPDM or silicone chosen by coupon | Do not rely on coated fasteners for PE continuity; do not soft-float panel-mounted XLRs |

## Verified Manufacturer Interfaces

| Part | Verified fact | Factory status |
| --- | --- | --- |
| Pelican iM2300 | 431.8 x 297.2 x 157.5 mm general interior; 50.8 mm lid and 106.7 mm base; HPX resin; P111-0095 Rev C controls bezel sizing | Case sample and 38.1 mm recessed opening still required |
| Mean Well RPS-400-24-C | Enclosed -C body 130 x 86 x 43 mm; 24 V, 10.5 A convection / 16.7 A with forced air; 93 percent efficiency; output derates with ambient temperature | Selected; measure installed terminal guard, conductor bends, local inlet air, and case temperature |
| Anton/Bauer Dionic XT90 8675-0125 | 99 x 132 x 58 mm; 99 Wh; 14.1 V; 12 A continuous | Selected; remove for transport closure |
| Anton/Bauer QRC-GOLD 8375-0094 | Universal compact plate, blind-mounted with 6-32 screws; supplied backplate; shaded areas require flat support | Selected; panel/frame load path and full latch sweep required |
| Delta THA0412AD-TZW3 | 40 x 40 x 20 mm; 12 V; PWM/tach; 20.56 CFM free-air; IP55 fan body | Selected for right intake and operator-side exhaust |
| Delta FFB0412EN-00Y2E | 40 x 40 x 28 mm; 12 V; high-power PWM/tach CPU fan | Selected with Radxa 5540A and structural carrier/frame support |
| Delta AFB0412SHB-SP04 | 40 x 40 x 15 mm; 12 V; 0.25 A; 3 W; 14.83 CFM; PWM/tach | Selected for modem cartridge; exact modem heatsink remains module-dependent |
| Qualtek 09150-F/30 | 40 mm intake filter assembly; 32 mm hole centers; 4.3 mm holes; 4.75 mm thick | Selected; clean and loaded CFM tests required |
| Qualtek 09150-G | 40 mm exhaust guard; 32 mm hole centers; 4.3 mm holes; 4.75 mm thick | Selected with custom downward splash hood |
| Neutrik NC3MAV / NC3FAV | Rear-mount A-series XLR interfaces | Use manufacturer cut geometry. Central panel opening is at least 22 mm, not 19.8 mm; verify mounting face and latch orientation on coupon |

Local source drawings are archived in docs/mechanical-parts.

## Monitor And Closed-Lid Gate

The selected monitor's documented 396.24 x 203.20 x 20.32 mm body envelope
controls engineering lid CAD. The received assembly remains a fabrication-fit
verification for the direct-mount drilling pattern, screw engagement, gasket,
connector retention, cable bends, lid position, and dynamic closure sweep.

Use this closure equation:

**display-front to panel-top gap = measured lid depth + measured panel recess - measured total display protrusion**

The tallest permanent panel hardware under the display must be at least 12.7 mm
shorter than that gap after tolerance, gasket compression, lid flex, and
impact allowance. Test with the case latched and with pressure applied at the
lid center and corners. The transport test is:

- Gold-mount battery removed;
- all eight released external antennas installed and folded inboard;
- all panel plugs removed unless a separate connected-transport condition is
  intentionally qualified;
- hinge bundle clamped in its operating loop with no contact against display,
  PSU, fan, or sharp edges.

## Bottom Stack Gate

The current planning stack is:

| Interface | Planning value |
| --- | ---: |
| Deepest floor to panel top A | 68.6 mm nominal |
| Panel thickness | 3.175 mm nominal |
| Deepest floor to panel underside | 65.425 mm nominal |
| Bottom tray top above deepest floor | 3.0 mm maximum |
| Tray top to panel underside | 62.425 mm nominal |
| Complete PSU/guard top above deepest floor | 48.0 mm maximum |
| PSU guard to carrier B.Cu | 10.0 mm minimum |
| Carrier F.Cu/highest ordinary part to panel underside | 4.0 mm minimum |
| CM5 and modem fan inlet to floor/tray/harness | 10.0 mm minimum |

This stack has little tolerance reserve. The factory must make a simple section
gauge representing the tray, 48 mm PSU guard, carrier B.Cu, PCB thickness,
panel connector Z, and panel underside before PCB mounting holes are frozen.
If the gauge fails, change the tray/guard or split/reposition the carrier. Do
not reduce the 10 mm PSU or fan clearances.

## Thermal And Power Logic

The preliminary electrical budget is 151.7 W continuous and 184.2 W transient.
The RPS-400-24-C has enough room at moderate temperature, but its convection
rating derates as local air warms. At 93 percent efficiency it rejects roughly
11.4 W while supplying 151.7 W. The guarded hinge-side bay therefore needs a
low-velocity branch of the clean intake airflow or a validated conductive path;
the guard may not become a sealed hot box.

Acceptance at 45 C ambient:

- maximum stated continuous system load, full display brightness, CPU/GPU/NPU,
  Wi-Fi AP traffic, cellular uplink, and all audio channels active;
- at least 15 CFM measured through the case with a clean intake filter;
- at least 12 CFM at the released filter-maintenance loading limit;
- PSU inlet-air temperature no higher than 50 C;
- no unintended CM5, modem, regulator, or PSU throttling/shutdown;
- every PWM command, tach signal, board temperature, modem temperature, CM5
  thermal zone, source voltage/current, and load voltage/current logged.

The two enclosure fans form one series flow path; their CFM values are not
added. Right wall remains intake. Operator wall center-right remains exhaust.
The audio/XLR side remains free of fan bodies, PWM wiring, and switching-power
loops.

## Power And Harness Checks

- AC inlet, fuse, PE bond, PSU chassis, bottom tray, support frame, and top panel
  need one documented protective-earth path. Coating is masked at bond points.
- The RPS AC connector is JST VH B3P-VH; DC output uses its specified M3.5
  screw terminals. H02 and H01 remain removable, touch-safe, strain-relieved,
  and long enough to raise the top panel for service.
- H03 HDMI, USB touch, and 12 V display cables start at 1000 +/-25 mm only for
  the first article. Final lengths come from the full lid and 300 mm panel-lift
  test. No connector carries service-loop tension.
- Battery source current exceeds 12 A near low-voltage operation at the full
  continuous design load. Existing load-shed behavior remains mandatory on
  backup. Do not advertise full 151.7 W operation through the 12 A battery down
  to cutoff.
- The monitor branch remains 12 V / 2.5 A with a simple replaceable fuse, per
  the project decision.

## PCB Engineering And Release Rules

- Engineering placement and routing may proceed from the controlled Rev L
  board envelopes, A1-A6/C1-C6 support coordinates, and nominal connector
  datums. Do not freeze production connector Z, final board-edge interfaces,
  or manufacturing outputs until the installation measurements pass.
- The current footprint audit covers 1203 unique physical-board components and reports 10 routing
  blockers and 11 production blockers. These are local final-routing and
  production-release holds, not a global floorplanning hold. The blockers are the two AKM
  exposed-pad package coupons and eight Panasonic TQ2 relay fit coupons. The
  additional production blocker is the Kycon headset-jack physical coupon; see
  `cad/kicad/reports/component-footprint-audit.md`. Zero ERC errors does not
  clear these blockers; keep their local escape, stencil, and fit regions
  provisional until the coupon results pass.
- AUDIO-8X8: controlled `A1-A6` supports, panel-supported XLRs, controlled chassis
  shield connection, no PWM/fan harness crossing the quiet boundary.
- CM5-CARRIER: controlled `C1-C6` supports, 15 mm perimeter frame keepout, no B.Cu
  parts or switch-node copper above the PSU guard, and exact 3D keepouts for
  CM5/5540A/fan, Wi-Fi, WWAN/heatsink/fan, RF pigtails, RJ45s, and lid harness.
- M.2 modem support means B-key 3042/3052 with an adjustable standoff and
  verified USB2/USB3, SIM, power, and thermal interfaces. It does not mean
  every modem on the market.
- Final DXF/STEP must be generated from controlled manufacturer drawings,
  documented nominal envelopes, and measured installation details. Concept
  SVG shapes may not be traced as cut geometry.

## Required First-Article Records

1. Completed im2300-measurement-register.csv, M001-M080.
2. Updated mechanical-release-a2.json.
3. Case serial/asset ID and calibrated-tool list.
4. Panel/frame gauge-plate photos and drawing.
5. Bottom stack section-gauge photo and measurements.
6. Monitor documented-envelope traceability, direct lid-mount drilling and
   sealing survey, connector installation survey, and closed-lid pressure test.
7. Battery insertion/removal sweep and QRC backplate inspection.
8. Eight-antenna installed/folded closure record, including the maximum folded
   hinge height and full closing/latched sweep.
9. Sidewall scan, fan reinforcement, guard, gasket, and splash-hood drawings.
10. Clean/loaded-filter CFM and 45 C thermal report.
11. PE continuity and mains barrier inspection.
12. Full H01/H02/H03 harness motion and strain-relief record.

## Source Files

- Pelican iM2300 base-bezel drawing: mechanical-parts/pelican-im2300-base-bezel-rev-c.pdf
- Mean Well RPS-400 series: mechanical-parts/mean-well-rps-400-spec.pdf
- Anton/Bauer QRC-GOLD: mechanical-parts/anton-bauer-qrc-gold-installation.pdf
- Delta modem fan: mechanical-parts/delta-afb0412shb-sp04-spec.pdf
- Delta enclosure fans: mechanical-parts/delta-tha0412ad-tzw3-spec.pdf
- Qualtek intake/exhaust guards: mechanical-parts/qualtek-09150f-filter-drawing.pdf and mechanical-parts/qualtek-09150g-guard-drawing.pdf
- Taoglas Wi-Fi fold-down antenna: mechanical-parts/taoglas-gw05-0153-wifi-antenna.pdf
- Taoglas cellular fold-down antenna: mechanical-parts/taoglas-tg66-a113-cellular-antenna.pdf

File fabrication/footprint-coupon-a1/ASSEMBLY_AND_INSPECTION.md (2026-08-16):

# Assembly And Inspection - Footprint Coupon A1

## Process controls

- Use the supplied F.Paste Gerber without undocumented aperture edits.
- Use a 0.10 mm laser-cut stainless stencil.
- Use fresh SAC305 Type 4 no-clean paste or an approved equivalent recorded in
  the result sheet.
- Use the assembler's qualified lead-free reflow profile, with thermocouples on
  one QFN-64 site and one QFN-48 site.
- Record paste lot, stencil identifier, oven/profile identifier, peak
  temperature, and time above liquidus.
- Place package pin 1 at the board marker.
- Do not hand-rework any site before initial AOI and X-ray.

## Build population

- Assembly A: U101-U103, U201-U203, K1, and J1.
- Assembly B: U103 and U203 only.
- Assembly C: U103 and U203 only.

Use only the exact manufacturer part numbers in `coupon-bom.csv`. K1 and J1 are
hand-inserted after their unsoldered fit measurements are recorded.

## Incoming bare-board inspection

Measure and record:

- Overall board width, height, thickness, and flatness.
- Four 3.20 mm NPTH tooling holes.
- The 0.80/0.90/1.00/1.10 mm hole gauge with calibrated pins.
- At least two J1 holes and two K1 holes.
- ENIG coverage and solder-mask registration at all QFN sites.
- U103/U203 via cap planarity and the supplier witness microsection.

## QFN inspection

Perform AOI and 2D/3D X-ray on every populated AKM site.

Pass criteria:

- No perimeter opens, bridges, solder balls, or package misorientation.
- Package offset no more than 0.10 mm in X or Y.
- Package tilt no more than 0.10 mm corner-to-corner.
- Exposed-pad solder coverage at least 65 percent.
- Total exposed-pad void area no more than 25 percent.
- No individual void greater than 10 percent of exposed-pad area.
- No continuous void or solder-depleted channel from the exposed-pad center to
  a package edge.
- No evidence of solder wicking at U103/U203.
- U103 and U203 meet every limit on assemblies A, B, and C without rework.

Record open and bottom-tented controls even if they fail; they are comparison
sites and their results determine whether the less expensive process is usable.

## Through-hole inspection

Before soldering K1 and J1:

- Insert the exact sample by hand without tools, force, or lead forming.
- Verify all leads enter simultaneously and the body seats within 0.20 mm.
- Photograph top and bottom seating.
- Verify terminal numbers against the manufacturer schematic.

After soldering:

- Confirm barrel wetting and fillet without bridge, land lift, or body damage.
- Check K1 coil and both Form-C contact maps.
- Check J1 CTIA tip/ring/ring/sleeve map and both switch states with a mating
  plug.
- Perform 100 plug/unplug cycles on J1, then repeat continuity and visual
  inspection. This is a coupon handling screen, not the connector's full rated
  life qualification.

## Release record

Complete `coupon-results-template.csv`, attach dimensional photographs,
microsection, AOI, X-ray, and electrical mapping records, then sign the final
disposition. Only an engineering `PASS` may clear the associated routing and
production gates.

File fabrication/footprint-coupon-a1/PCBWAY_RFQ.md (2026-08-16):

# PCBWay RFQ - Footprint Coupon A1

## Order parameters

| Parameter | Requirement |
|---|---|
| Quantity | 5 bare boards |
| Size | 100.0 x 80.0 mm |
| Layers | 6 |
| Thickness | 1.60 mm nominal |
| Material | FR-4, Tg 150 C minimum |
| Copper | 1 oz finished, all six layers |
| Finish | ENIG |
| Solder mask | Green, both sides |
| Legend | White, both sides where supplied |
| Electrical test | 100 percent bare-board test |
| Edge | Routed, no V-score or mouse bites on finished coupon |
| Finished-hole tolerance | PCBWay standard or better; report measured coupon values |
| Impedance control | Not required for this nonfunctional coupon |

Use PCBWay's published 1.6 mm six-layer stackup as the starting construction:

`F.Cu 35 / PP 0.11 / In1 35 / Core 0.53 / In2 35 / PP 0.11 / In3 35 / Core 0.53 / In4 35 / PP 0.11 / B.Cu 35`, all dimensions in micrometers for copper and millimeters for dielectric.

Confirm the final pressed stackup, material family, Tg, finished thickness, and
copper values before production. The KiCad stackup is an RFQ target, not
permission to change the factory-approved laminate construction silently.

## Selective via treatment

The coupon intentionally contains three exposed-pad treatments. Preserve the
difference:

- U101 and U201: bottom solder-mask openings remain open; no fill or cap.
- U102 and U202: bottom-tented vias; no fill or cap.
- U103 and U203: IPC-4761 Type VII, non-conductive resin filled, planarized,
  copper capped, and plated over.

Apply Type VII processing only to the 50 coordinates in
`output/filled_via_coordinates.csv`. Finished hole is 0.20 mm. Do not globally
fill all vias and do not alter U101/U201 or U102/U202. If selective Type VII is
not supported on one panel, stop and request engineering disposition; do not
manufacture a substituted coupon.

Supply:

- Written DFM confirmation of the selective Type VII process.
- A finished stackup table.
- Final drill chart and finished-hole tolerance.
- Type VII fill/cap process certificate.
- Microsection of a same-panel Type VII witness via showing continuous fill,
  planarization, and copper cap.
- Bare-board electrical-test report.
- Dimensional inspection report for board outline, 0.20 mm vias, 0.80 mm J1
  holes, and 0.90 mm K1 holes.

## Fabrication hold points

1. Hold before tooling if any Gerber, drill, stackup, or selective-fill conflict
   exists.
2. Send DFM questions and proposed changes in writing.
3. Release fabrication only after the stackup and selective-fill map are
   acknowledged by both parties.

Reference data:

- PCBWay capabilities: <https://www.pcbway.com/capabilities.html>
- PCBWay six-layer stackup: <https://www.pcbway.com/blog/Engineering_Technical/stackup___pcbway.html>
- PCBWay Type VII via process: <https://www.pcbway.com/pcb_prototype/PCB_Via_Covering.html>

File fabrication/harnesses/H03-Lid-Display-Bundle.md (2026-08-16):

# H03 Lid-Display Cable Bundle

## Purpose

`H03` connects the underside-facing CM5-CARRIER display interfaces to the
15.6-inch touchscreen in the iM2300 lid. The three cables remain separately
replaceable:

- `H03A`: HDMI video
- `H03B`: USB touch data
- `H03C`: 12 V monitor power

## Prototype Length

Use a finished length of 1000 +/- 25 mm for each first-article cable.

- Measure H03A and H03B connector mating face to connector mating face.
- Measure H03C from the rear face of the fully assembled P803 Micro-Fit
  housing to the monitor-plug strain-relief reference.
- Do not release 1000 mm as the final production length until the actual
  monitor, connector orientations, carrier placement, notch, clamps, lid, and
  removable top panel have passed the motion test below.

## H03A HDMI

- Carrier end: HDMI Type-A male into `J801`, Molex `208658-1001` receptacle.
- Monitor end: HDMI Type-A male, subject to orientation check on the received
  monitor sample.
- Use a shielded, certified High Speed HDMI cable rated for repeated flexing.
- Select low-profile or right-angle overmolds only after the installed sample
  confirms the required exit direction and bend clearance.
- Add positive cable retention near both connectors. Do not rely on HDMI
  connector friction as strain relief.

## H03B USB Touch

- Carrier end: USB Type-A male into `J802`, Wurth `692122030100` receptacle.
- Starting monitor end: USB Type-B male. Confirm whether the received monitor
  uses USB 2.0 Type-B, USB 3.x Type-B, USB-C, or another touch connector before
  production release.
- A USB 3.x A-to-B cable is acceptable even though the carrier currently uses
  only the USB 2.0 D+/D- pair for HID touch.
- Use a shielded high-flex cable and positive retention near both connectors.

## H03C 12 V Power

Carrier connector `J803` is Molex Micro-Fit 3.0 `43045-0412`, mounted on the
PCB underside and facing down.

| J803 / P803 cavity | Assignment | Conductor |
| ---: | --- | --- |
| 1 | `DISPLAY_12V` | 18 AWG red |
| 2 | `DISPLAY_12V` | 18 AWG red |
| 3 | `GND` | 18 AWG black |
| 4 | `GND` | 18 AWG black |

Use Molex housing `43025-0400` and four tin-plated 18 AWG female contacts
`43030-0038`. Join the two positive and two return conductors only in a
qualified monitor-end termination or sealed splice. The monitor-end power
plug remains sample-gated because its exact barrel/locking geometry is not in
the controlled monitor documentation.

The branch is 12 V / 2.5 A and is protected by the upstream 3 A time-lag fuse.
There is no dedicated display eFuse by project requirement.

## Routing And Retention

- Route all three cables through the centered open hinge-edge notch with an
  abrasion liner. Do not pull connector overmolds through an enclosed hole.
- Provide a gentle retained loop for normal lid travel and a separate
  releasable loop for top-panel service.
- Use cushioned clamps and broad hook-and-loop retention. Do not crush HDMI or
  USB cable geometry with narrow cable ties.
- Follow the cable manufacturer's moving bend radius; use at least 10 times
  cable outside diameter where no stricter value is available.
- Keep stored and released cable outside all fan swept volumes, fan intakes,
  PSU airflow, heatsinks, RF coax corridors, board keepouts, and sharp edges.
- Clamp within 75 mm of each carrier connector and at the lid-side transition
  so no PCB or monitor connector carries bundle weight or service force.

## First-Article Acceptance

1. Open and close the lid through its complete travel while all three cables
   are connected. Nothing may pinch, scrape, tighten, or enter a fan opening.
2. With the lid open, release the panel-service clamps. Raise the connected top
   panel at least 300 mm above its support frame and tilt it at least 45
   degrees in the intended service direction.
3. At the entire service envelope, verify visible slack at all six cable ends,
   compliant bend radii, intact edge protection, and no load on connectors.
4. Return the panel to operating position and secure all loops. Verify the case
   closes and latches without compressing a cable.
5. Operate 1080p60 HDMI video, USB HID touch, and maximum display brightness
   during motion. Reject any video blanking, USB disconnect, touch dropout, or
   power interruption.
6. Complete 500 lid open/close cycles, then repeat signal, insulation, visual,
   retention, and H03C polarity tests.
7. Record the dressed lengths. Production may shorten a cable only if the
   complete test still passes with manufacturing and installation tolerance.

## Release Blockers

- Receive the locked JUNEBOX / DTM MALL display and verify its connector,
  mounting, and installed-stack details against the documented
  396.24 x 203.20 x 20.32 mm nominal body envelope.
- Confirm USB touch connector type and orientation.
- Confirm monitor 12 V input plug size, polarity, retention, and current.
- Select exact high-flex HDMI and USB cable manufacturer part numbers.
- Release clamp locations and the protected notch geometry in the mechanical
  assembly drawing.

## Manufacturer Sources

- Molex `43045-0412` PCB header:
  https://www.molex.com/en-us/products/part-detail/0430450412
- Molex `43025-0400` cable housing:
  https://www.molex.com/en-us/products/part-detail/0430250400
- Molex `43030-0038` 18 AWG female contact:
  https://www.molex.com/en-us/products/part-detail/0430300038
- Molex `208658-1001` HDMI receptacle:
  https://www.molex.com/en-us/products/part-detail/2086581001
- Wurth `692122030100` USB receptacle:
  https://www.we-online.com/components/products/datasheet/692122030100.pdf

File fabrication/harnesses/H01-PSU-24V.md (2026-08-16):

# H01 Bottom-PSU 24 V Harness

## Purpose

`H01` carries the low-voltage output of the bottom-mounted MEAN WELL
`RPS-400-24-C` to `PWR-SELECT J101`. It is not an AC mains harness.

## Electrical Definition

| Circuit | PSU end | Wire | PCB end |
| --- | --- | --- | --- |
| `+24V_PSU` | `CN3 +V`, M3.5 closed ring | 14 AWG red | `P101-1` -> `J101-1 V24_IN` |
| `0V_PSU` | `CN2 -V`, M3.5 closed ring | 14 AWG black | `P101-2` -> `J101-2 GND` |

The connector cavity numbers and continuity test control polarity. Do not use
wire color alone as the acceptance method.

## Mechanical Definition

- Prototype finished length: 750 +/- 20 mm, measured from each ring center to
  the rear face of the fully assembled Mega-Fit receptacle.
- Use 14 AWG stranded copper, UL1015 or equivalent, 600 V, 105 C minimum.
- Keep red and black conductors together in abrasion-resistant sleeving except
  for the minimum breakout needed at both ends.
- Install the Molex `105415-0002` TPA after both contacts pass the primary-lock
  tug check.
- Label the connector end `H01 / PWR-SELECT J101 / PIN 1 +24V`.
- Label the ring ends `CN3 +V` and `CN2 -V` individually.
- Clamp the dressed harness within 50 mm of J101 and near the PSU so neither
  the PCB header nor PSU screws carry vibration or service strain.
- Store the closed-case service loop in releasable cushioned clamps. The loop
  must not enter either fan inlet, the PSU airflow path, or a board keepout.
- With the clamps released, H01 must let the top panel rise at least 300 mm
  above its support frame and tilt at least 45 degrees without connector,
  terminal, or conductor tension.
- Keep H01 outside the guarded mains corridor and away from sharp sheet-metal
  edges. Fit an edge grommet anywhere a crossing cannot be avoided.

## Assembly

1. Cut one red and one black conductor to the controlled build length.
2. Crimp TE `320619` rings at the PSU ends with the approved PIDG tooling.
3. Crimp Molex `76823-0344` contacts at the PCB ends with tooling qualified to
   Molex application specification `768232000-AS`.
4. Insert red into housing cavity 1 and black into cavity 2 until the primary
   latches engage.
5. Perform a light individual contact tug check, then install TPA
   `105415-0002` fully seated.
6. Apply abrasion sleeve, identification labels, and strain-relief features.
7. Connect red to PSU `CN3 +V` and black to PSU `CN2 -V`. Use a calibrated
   driver and never exceed the PSU limit of 8 lb-in / 90 cN-m.

## Acceptance Tests

1. Visual inspection: correct parts, no exposed conductor, no cut insulation,
   TPA fully seated, ring barrels and contact insulation wings correctly
   formed.
2. Point-to-point continuity: `CN3 +V` ring to P101 cavity 1; `CN2 -V` ring to
   P101 cavity 2.
3. Isolation: greater than 20 MOhm between the two circuits at 100 VDC.
4. Four-wire resistance: record each circuit; reject either circuit above
   25 mOhm before mating-contact resistance is added to the system record.
5. Polarity at J101: with current-limited 24 V applied at the PSU end, verify
   `J101-1` is positive relative to `J101-2` before connecting PWR-SELECT.
6. Retain the crimp-height and pull-force records required by the terminal
   manufacturers for each production lot.

## Release Gate

The 750 mm length is the first-article service-loop target, not a final
production dimension. Release the final length only after the installed
harness passes both the closed-case retention check and the 300 mm lift / 45
degree tilt service-opening test. Do not coil unused cable in the PSU airflow
path.

## Manufacturer Sources

- MEAN WELL RPS-400 specification:
  https://www.meanwell.com/Upload/PDF/RPS-400/RPS-400-SPEC.PDF
- Molex `76825-0002` PCB header:
  https://www.molex.com/en-us/products/part-detail/768250002
- Molex `171692-0202` receptacle series:
  https://www.molex.com/en-us/products/series-chart/171692
- Molex `76823-0344` terminal:
  https://www.molex.com/en-us/products/part-detail/0768230344
- Molex `105415-0002` TPA series:
  https://www.molex.com/en-us/products/series-chart/105415
- TE Connectivity `320619` ring terminal:
  https://www.te.com/en/product-320619.html

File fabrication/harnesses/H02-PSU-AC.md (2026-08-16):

# H02 Fused-Inlet to PSU AC Harness

## Status

Preliminary safety-controlled definition. A qualified product-safety engineer
must release the finished mains harness, PE bond, routing, guarding, and strain
relief before any production build.

## PSU Connector

The white connector shown on the `RPS-400-24-C` is AC input `CN1`, not the
24 V output. MEAN WELL specifies a JST `B3P-VH` or equivalent.

| CN1 cavity | Assignment | Conductor |
| ---: | --- | --- |
| 1 | `AC/L` | brown, fused line from C14 inlet |
| 2 | no pin | no contact; leave empty |
| 3 | `AC/N` | blue, neutral from C14 inlet |

Use JST `VHR-3N` housing with two JST `SVH-21T-P1.1` contacts. Use 18 AWG
stranded copper, 600 V, 105 C minimum wire unless the final safety review
requires a larger conductor or a different recognized wiring style.

Prototype finished length is 750 +/- 20 mm from the released C14 terminal
reference to the rear face of the VHR-3N housing. This is a first-article
service-loop target, not a final production dimension.

## Protective Earth

Protective earth does not pass through CN1. Use a separate green/yellow
conductor from the C14 earth terminal to the primary chassis stud, with a
separate branch or approved bond to the PSU chassis grounding point. Use ring
terminals, toothed washers, locking hardware, and a dedicated earth stud. Do
not rely on painted panel contact or ordinary PSU mounting screws as the sole
protective-earth path.

## Production Controls

- Mark both ends `DANGER MAINS H02`.
- Put H02 and PE inside the guarded AC zone and physically separate them from
  H01 and all SELV/data/audio harnesses.
- Store the closed-case service loop in releasable, insulated cushioned clamps.
  With those clamps released, H02 must allow the top panel to rise at least
  300 mm and tilt at least 45 degrees without tension or loss of guarding.
- The flexible panel-to-chassis PE bond must remain slack throughout that same
  service position and must be the last conductor disconnected during panel
  removal.
- No part of the released or stored loop may enter a fan, PSU airflow path,
  sharp-edge zone, or low-voltage PCB keepout.
- Position 2 of the VHR-3N housing must remain empty.
- Perform continuity, polarity, PE-bond, dielectric-withstand, leakage-current,
  fuse, strain-relief, and enclosure safety tests to the applicable final
  product standard.
- Do not substitute a generic marketplace JST-lookalike harness without proof
  of connector authenticity, wire recognition, voltage/temperature rating,
  crimp qualification, and lot traceability.
- Release the final H02 and PE lengths only after the closed-case retention and
  full service-opening tests pass in the first mechanical article.

Manufacturer source:
https://www.meanwell.com/Upload/PDF/RPS-400/RPS-400-SPEC.PDF

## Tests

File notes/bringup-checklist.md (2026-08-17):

# Bring-Up Checklist

## Before Fabrication

- Schematic ERC reviewed.
- PCB DRC reviewed.
- CM5 connector pin mapping reviewed against official Radxa V2.21 pinout.
- Power rails checked for voltage, current, sequencing, and protection.
- Every regulator design worksheet, compensation result, inductor saturation,
  MOSFET SOA, eFuse limit, copper loss, and worst-case thermal calculation is
  independently reviewed.
- ProComm-style source selector checked for 24 V, D-Tap, and Gold Mount priority behavior.
- USB, HDMI, PCIe, Ethernet, TDM-clock, and RF impedance/routing rules documented.
- Connector protection matches `connector-protection-matrix.md` and is placed
  at the connector boundary.
- PE/chassis schematic, mains barrier, creepage/clearance, fuse coordination,
  MOV/EMI filter, wire, terminal, strain-relief, and ground-bond details receive
  a qualified safety review.
- Connector orientation and pin 1 markings verified.
- Mounting holes, board outline, and component heights verified.
- BOM availability checked.
- Assembly drawings and polarity marks checked.

## First Power

- Inspect PCB and assembly under magnification.
- Check input-to-ground resistance before applying power.
- Current-limit bench supply for first power-up.
- Verify standby and main power rails before installing CM5.
- Verify source-selector output and regulator rails from rear 24 V, D-Tap, and Gold Mount inputs before installing CM5.
- Verify no-blink source transfer with a scope before installing CM5:
  `24V_PSU`, `BAT_SELECTED`, protected raw DC, `SYS_4V0`, `IO_5V0`, `DISPLAY_12V`,
  `AUX_12V`, `FAN_CPU_12V`, `FAN_AUX_12V`, `MODEM_3V8`, `WIFI_3V3`, `NET_3V3`, `PCIE_1V0`,
  audio rails, reset lines, and mute lines must stay inside limits.
- Use the ProComm PowerSelector Rev C bench-test style as the starting point,
  but repeat it at Radxa current levels and with the locked `RPS-400-24-C`
  primary PSU.
- Confirm no rail exceeds documented maximum voltage.
- Install CM5 and repeat with current limit.
- Check debug UART output.
- Boot from known-good OS image.
- Verify USB recovery and eMMC provisioning path.

## Interface Tests

- Verify all four 1 GbE ports independently and simultaneously, including
  WAN/LAN isolation and shared PCIe-upstream saturation behavior.
- USB 2.0 and USB 3.0 enumeration.
- HDMI display output at all supported modes.
- HDMI touchscreen USB input.
- PCIe switch, three LAN7430 controllers, and AW7915-NP1 enumeration.
- All four Wi-Fi RF chains, AP band selection, and 25-client closed-case load test.
- M.2 WWAN USB 2/3 enumeration, both SIM trays, power cycle, and all four RF paths.
- RTC battery retention.
- Fan PWM/tach if populated.
- CPU fan speed control.
- Cellular modem fan speed control from modem-zone temperature.
- Board/enclosure fan 1 and fan 2 speed control from board temperature sensors.
- Thermal alarm and fan-fail behavior for all four fans if tach feedback is
  populated.
- Confirm all four fans default to full speed when I2C/control is removed.
- Confirm each enclosure-fan channel starts at 100% duty, runs at 1 kHz PWM,
  provides valid tach feedback, and is never commanded below 30% duty.
- Run the 151.7 W continuous design case in the closed enclosure at 45 C / 113 F
  ambient; record internal sensors, CM5/modem telemetry, PSU, spreader,
  bulkhead, external-fin, lid, and connector temperatures.
- Apply ESD, EFT, surge, short-circuit, hot-plug, and fault tests in a controlled
  compliance/pre-compliance setup before field use.
- Perform powered and unpowered shock/vibration testing in all three axes with
  the production monitor, battery, modem, Wi-Fi module, heatsinks, fans, PSU,
  and harnesses installed. Test both transport configuration and normal
  operating configuration.
- During powered vibration, log rail voltage, source transfer, CM5 resets,
  Ethernet links, Wi-Fi/cellular registration, fan tach, storage errors, audio
  clocks, and ALSA xruns.
- After testing, inspect panel and PCB fasteners, standoffs, XLR and RJ45 solder
  joints, CM5 board-to-board connectors, M.2 retainers, large components,
  heatsinks, fan mounts, battery dock, PSU mounts, and every harness clamp.
- Require no loose hardware, cracked solder joints, fretting, connector motion,
  intermittent operation, enclosure contact, or visible PCB deformation.

## Audio Stress Tests

- Before releasing either converter reset, verify the common 12.288 MHz MCLK,
  12.288 MHz BCLK, 48 kHz frame sync, eight 32-bit TDM256 slots, and the
  expected I2C devices: AK5558 at `0x10` and AK4458 at `0x11`.
- Read back AK5558 registers `0x02=0x17` and `0x03=0x40`; read back AK4458
  registers `0x0A=0x8D` and `0x0B=0x0C`. Treat any mismatch as a latched audio
  fault and keep the output relays de-energized.
- Keep the DAC soft-muted and K501-K508 de-energized during rail/clock setup.
  Send stable zero data, complete the soft-mute ramp, and energize the relays
  only after all rail, clock, address, and register checks pass.
- Confirm 8-channel capture and 8-channel playback enumerate with the expected
  ALSA names and channel map.
- Verify +4 dBu nominal and +24 dBu maximum input/output on every channel;
  confirm outputs remain stable into 600 ohm and meet noise/distortion targets
  with a normal 10 kohm load.
- Confirm +4 dBu input measures approximately -21.0 dBFS and +24 dBu input
  remains below clipping on all channels. Calibrate playback digital gain so
  +24 dBu is the operating ceiling despite the calculated analog headroom.
- Exercise mute, reset, relay drop-out, clock loss, hot-plug, and source-transfer
  sequences while monitoring XLR outputs for clicks, DC, or unsafe transients.
- Run simultaneous 8x8 playback/capture while applying CPU stress.
- Repeat the same audio test while routing WAN/LAN traffic, broadcasting Wi-Fi
  AP traffic, using the cellular modem, displaying HDMI video, using USB touch,
  and writing logs to eMMC.
- Confirm no audible mute, no lost channels, no ALSA xruns, no kernel ASoC
  errors, and no converter reset/mute glitches during load spikes.
- Power-cycle and warm-reboot repeatedly to verify that ADC/DAC clocks, reset,
  and mute sequencing recover every time.
- Repeat the simultaneous 8x8 audio stress test while removing and restoring
  AC power with a valid backup source installed; confirm no display blink, no
  CM5 reset, no audible mute/click, and no ALSA xrun.

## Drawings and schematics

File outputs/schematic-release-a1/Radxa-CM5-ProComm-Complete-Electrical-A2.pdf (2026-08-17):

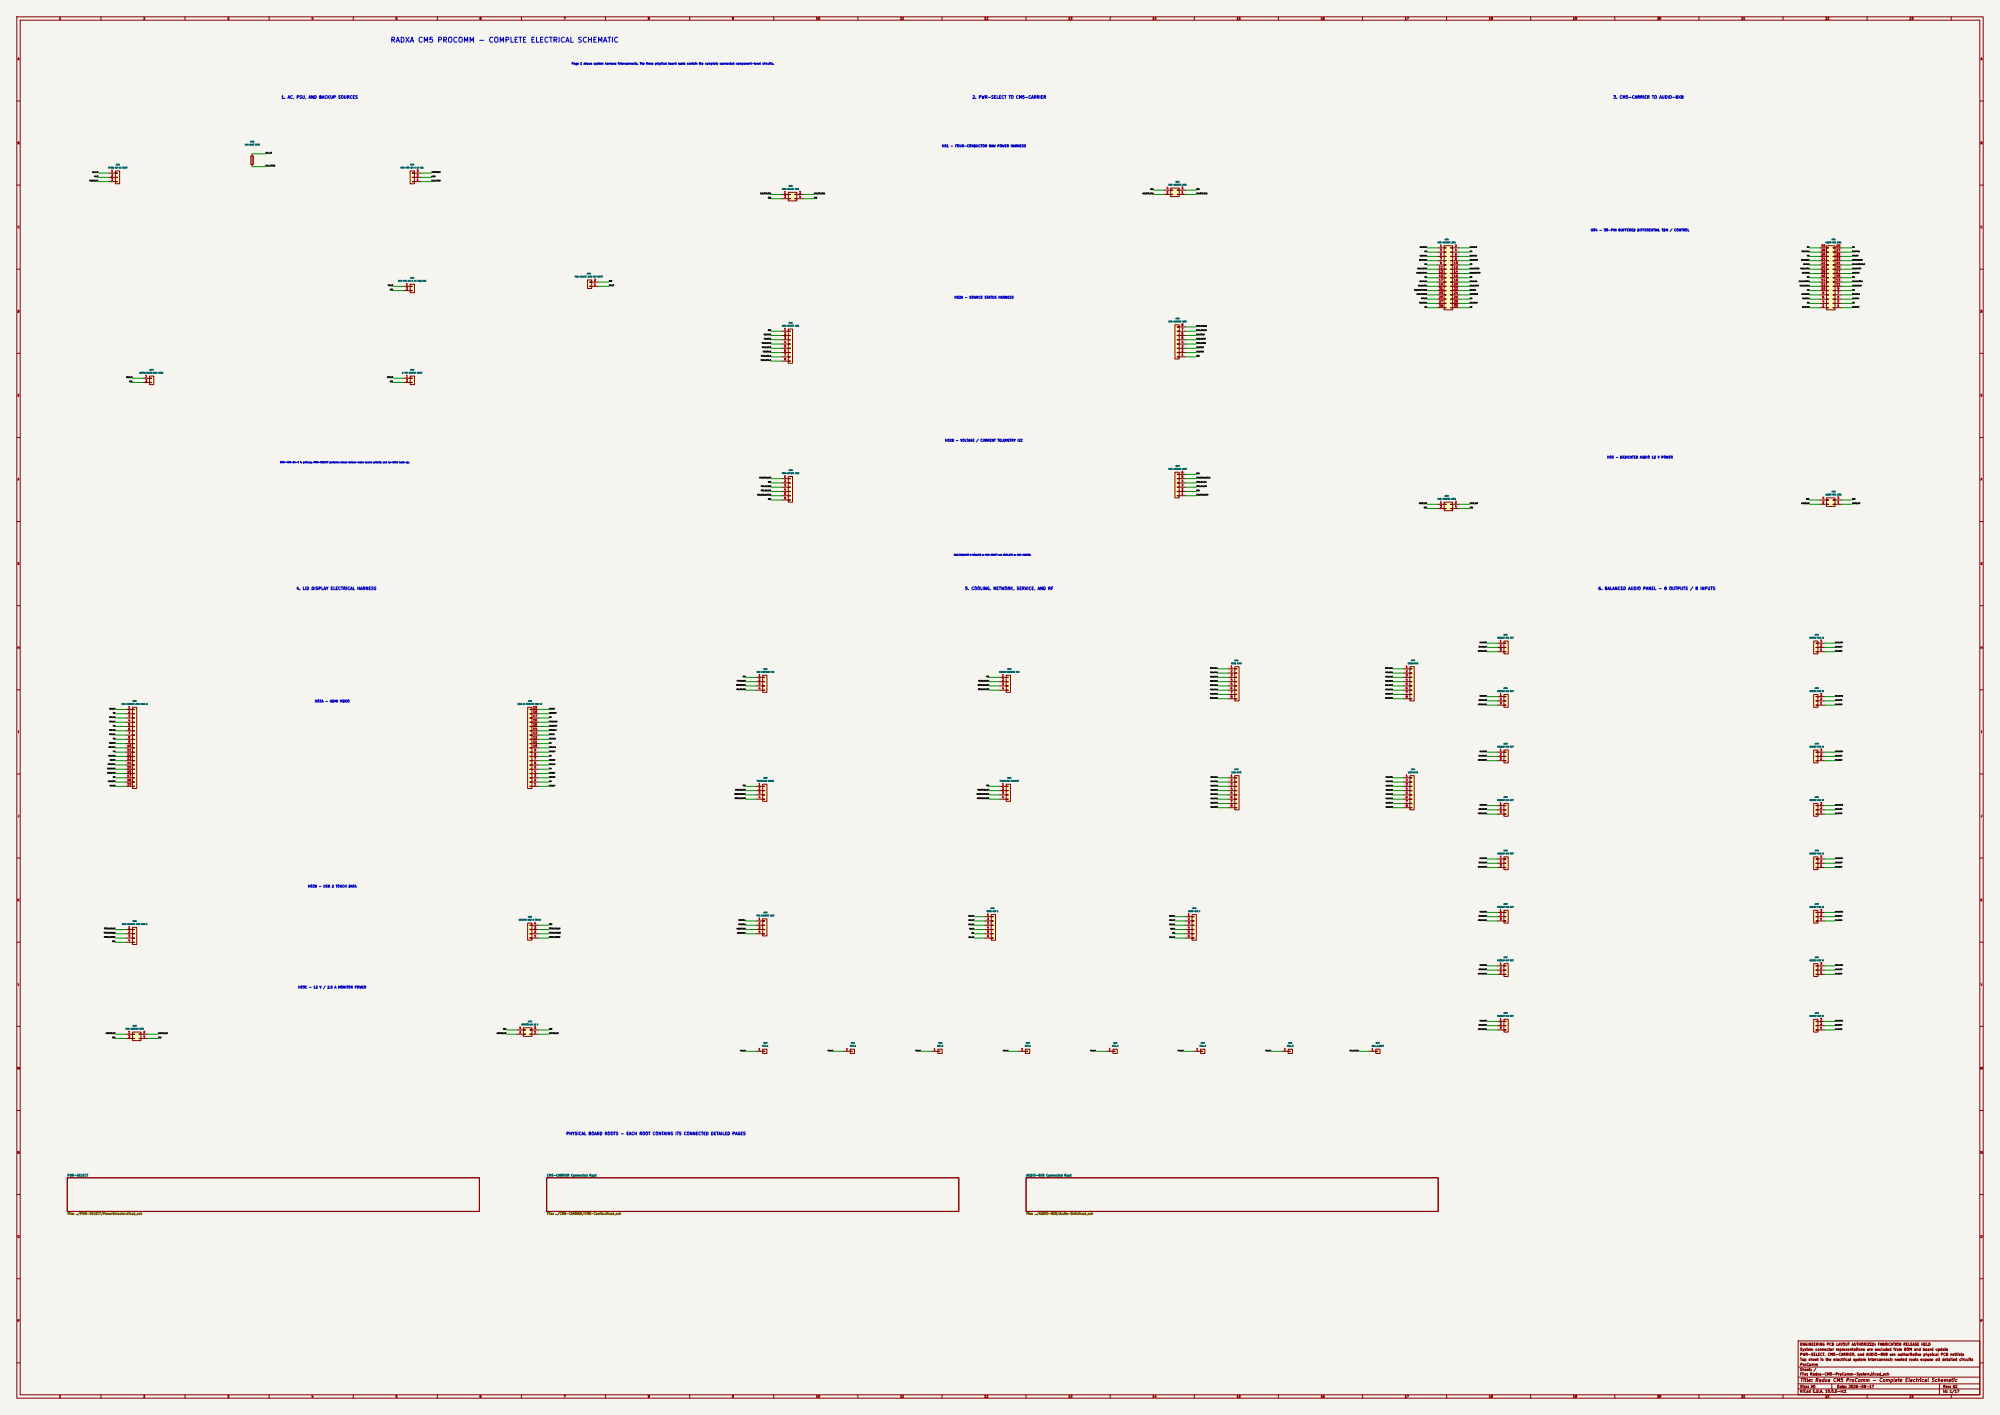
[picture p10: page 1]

RADXA CM5 PROCOMM - COMPLETE ELECTRICAL SCHEMATIC

Page 1 shows system harness interconnects. The three physical board roots contain the complete connected component-level circuits.

1. AC, PSU, AND BACKUP SOURCES

2. PWR-SELECT TO CM5-CARRIER

H01 - FOUR-CONDUCTOR RAW POWER HARNESS

J9004 PWR-SELECT J101 PSU INPUT 1

H04 - 30-PIN BUFFERED DIFFERENTIAL TDM / CONTROL

J9005 ANTON/BAUER QRC-GOLD

RPS-400-24-C is primary. PWR-SELECT performs break-before-make source priority and no-blink hold-up.

PWR_TELEM_3V3 is MON_3V3 on PWR-SELECT and LOGIC_3V3 on CM5-CARRIER.

5. COOLING, NETWORK, SERVICE, AND RF

J9851 15.6-IN MONITOR HDMI IN

PHYSICAL BOARD ROOTS - EACH ROOT CONTAINS ITS CONNECTED DETAILED PAGES

ENGINEERING PCB LAYOUT AUTHORIZED; FABRICATION RELEASE HELD
System connector representations are excluded from BOM and board update
PWR-SELECT, CM5-CARRIER, and AUDIO-8X8 are authoritative physical PCB netlists
Top sheet is the electrical system interconnect; nested roots expose all detailed circuits
ProComm
Sheet: /
File: Radxa-CM5-ProComm-System.kicad_sch
Title: Radxa CM5 ProComm - Complete Electrical Schematic

Size: A0 | Rev: A2
KiCad E.D.A. 10.0.5-rc1 | Id: 1/17

1 | 2 | 3 | 4 | 5 | 6 | 7 | 8 | 9 | 10 | 11
1 | 2 | 3 | 4 | 5 | 6 | 7 | 8 | 9 | 10 | 11

AB

C

D

E

## FGH

AB

C

D

E

# FGH Date: 2026-08-16

Size: A2 | Rev: A1

# Title: Radxa CM5 ProComm 24 V / Battery Seamless Power Selector

# File: PowerSelector.kicad_sch

# Sheet: /PWR-SELECT/

# Fixed priority: internal PSU 24 V, then D-Tap, then Gold Mount dock

# RAW_OUT_LOAD feeds the protected CM5-CARRIER regulator input

# 27.2 mF / 50 V hold-up bank is retained on this floor-mounted board

# Battery inputs use LTC4418 plus back-to-back P-MOS reverse-polarity blocking

## 470nF 50V

1
2
3
4
5
6
1nF C0G | 100uF 63V
220uF 50V | 220uF 50V | 220uF 50V | 1uF 50V X7R

A1

1

A0

2

Alert | 3
SDA | 4
SCL | 5 VS

# 6 GND

7

## Vbus 8

## Vin-

9

## Vin+

10

# 100nF 50V 47nF 50V

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
# 5 47nF 50V

TMR | 1 UV1 2 | OV1 3 | UV2 4 | OV2 5

## VALID1 6

VALID2 7 | GND

## 8 CAS 9 INTVCC 10 G2 11

VS2 | 12 G1 | 13
VS1 | 14
VOUT | 15

V2 16

V1 17

EN | 18
SHDN | 19 HYS 20 | EP 21

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
## 100nF 16V

6800uF 50V | 6800uF 50V | 1

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
4 | D
| 5

S

1

S

2

S

3 G

4 | D

# 5 10uF 50V

CTR 1 | GND

## 2 CTS 3 RESET 4

## SENSE 5

## VDD 6

## 100nF 1uF 50V X7R

S

1

S

2

S

3 G

4 | D

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
SOURCE1 | 1 GATE1 | 2
V1 3 | UVF1 4 | UVR1 5 | OV1 6
TMR1 7 | DISABLE1 8 | CH1 9

## VALID1 10

FAULT1 11 | CASIN 12 INTVCC 13 | CASOUT | 14 QUAL 15 GND 16 | RETRY | 17
SHDN | 18

## FAULT2 19

VALID2 20 | CH2 21 | DISABLE2 22
TMR2 23 | OV2 24 | UVR2 25 | UVF2 26
V2 27 | GATE2 | 28
| SOURCE2 | 29
SENSE2 | 30 OUT2 | 31 CPOREF 32 | CPO 33 | EXTVCC 34 | OUT1 | 35
SENSE1 | 36 EP 37
1 | 2
3 | 4

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
## 510uF 50V

PWR_FLAG | PWR_FLAG

## 1uF 50V X7R

1 | 2
3 | 4

## PWR_FLAG

1
2
1 | 2
3 | 4

## 1uF 16V 1

2

34

## 10uF 50V X7R

1

2

34

## 6800uF 50V

## PWR_FLAG

## 6800uF 50V

## PWR_FLAG

1

2

## 34 PWR_FLAG

## PWR_FLAG

## 10uF 50V X7R

1uF 16V | 1nF C0G | 100nF

A1

1

A0

2

Alert | 3
SDA | 4
SCL | 5 VS

# 6 GND

7

## Vbus 8

## Vin-

9

## Vin+

10

## 470nF 50V

S

1

S

2

S

3 G

4 | D

## 5 47nF 50V PWR_FLAG

A1

1

A0

2

Alert | 3
SDA | 4
SCL | 5 VS

# 6 GND

7

## Vbus 8

## Vin-

9

## Vin+

10

1 | 2
3 | 4

## PWR_FLAG

# 47nF 50V INTVCC

## BAT_FUSED

# V24_SENSE SRC_24GND

## BAT_SELECTED

## SRC_GOLD

## BAT_SELECTED

## MON24_INN MON24_INP

RAW_OUT | MON24_INN

## SHDN_MAIN

## GND

## SRC_BAT

## GND

## BAT_SENSE RAW_OUT

## BAT_SENSE

## GATE_GOLD

## GATE_BAT RAW_OUT

## MON_3V3 PWR_MON_SCL PWR_MON_SDA PWR_MON_ALERT_N

GND

## RAW_OUT

MON24_INP MON24_INN MON24_VBUS | GND
V24_SENSE | MON24_INP

## GATE_GOLD

## G2_CTRL

## PRE_INTVCC

V24_FUSED | MON24_VBUSMON24_VBUS GND

## INTVCC

INTVCC | MONBAT_VBUS

## GND

## MONBAT_INP MONBAT_INN MON_3V3 PWR_MON_SDA PWR_MON_SCL PWR_MON_ALERT_N

## GND

## GND

## BAT_FUSED MONBAT_INP MONBAT_INN

INTVCC | FAULT_DISABLE_24

## MONLOAD_INN MONLOAD_INN MONLOAD_VBUS MONLOAD_VBUS

## RAW_OUT_LOAD

## GATE_GOLD

## SRC_GOLD

FAULT_DISABLE_BAT | PWR_MON_SDA
MON_3V3 | GND

## GATE_GOLD

GND MON_3V3 | PWR_MON_SCL PWR_MON_ALERT_N MONLOAD_INP MON_3V3 MON_3V3 | PWR_MON_SCL PWR_MON_SDA PWR_MON_ALERT_N
MON_3V3 | MONLOAD_INP MONLOAD_INN MONLOAD_VBUS
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

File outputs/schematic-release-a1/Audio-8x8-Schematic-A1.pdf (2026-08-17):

1 | 2 | 3 | 4 | 5 | 6 | 7 | 8 | 9 | 10 | 11 | 12 | 13 | 14 | 15 | 16

AB

C

D

E

## FGH

## IJK

AB

C

D

E

## FGH

# IJK Date: 2026-08-16

# KiCad E.D.A. 10.0.5-rc1

Size: A1 | Rev: A1 Id: 1/7

# Title: Radxa CM5 ProComm Audio 8x8 - Interface Contract

# File: Audio-8x8.kicad_sch

# Sheet: /

# ProComm

# AK5558VN ADC and AK4458VN DAC over buffered differential TDM

# +4 dBu nominal, +24 dBu maximum, active-balanced XLR stages

# Left bank male outputs; right bank female inputs

# Physical AUDIO-8X8 root; nested detailed pages form one connected board netlist

# TDM / Clock / Control File: Audio-TDM-Clock.kicad_sch

# Audio Power File: Audio-Power.kicad_sch Balanced Outputs 1-8

# File: Audio-Outputs.kicad_sch Balanced Inputs 1-8

# File: Audio-Inputs.kicad_sch

# AK4458VN DAC

# File: AK4458-DAC.kicad_sch

# AK5558VN ADC

File: AK5558-ADC.kicad_sch 1 | 2
3 | 4
5 | 6
7 | 8
9 | 10
11 | 12
13 | 14
15 | 16
17 | 18
19 | 20
21 | 22
23 | 24
25 | 26
27 | 28
29 | 30
| J9901

# AUDIO_TDM_CONTROL

1

3

2 1 | 2 G

3

1

3

2 1 | 2 G

3

1
2

# J901 CHASSIS_BOND_TEST 1MR901

1

3

2 1 | 2 G

3

1

3

2 1 | 2

3

1

3

2 1 | 2 G

3

1

3

2 1 | 2

3

1

3

2 1 | 2

3

1

3

2 1 | 2

3

1

3

2 1 | 2

3

1

3

2 1 | 2 G

3

1

3

2 1 | 2

3

1

3

2 1 | 2

3

1

3

2 1 | 2 G

3

1

3

2 1 | 2

3

1

3

2 1 | 2 G

3

C901

# 4.7nF Y1 500Vac

1

3

2 1 | 2 G

3

1 | 2
3 | 4 J9902

# AUDIO_12V_POWER

## AOUT_CH7_HOT AOUT_CH7_COLD

## AUD_FSYNC_P

## GND

## AUD_DAC_SDIN_P

## AUD_ADC_SDOUT_P

## GND

## AUD_I2C_SCL AUD_ADC_RST_N

## GND

## AUD_I2C_SDA

## AUD_DAC_RST_N

## AUD_IRQ_N

## AUDIO_ENABLE GND

## TDM_SPARE_2 GND

## AUD_DAC_MUTE_CMD_N

## AUDIO_PRESENT_N

## LOGIC_3V3

## TDM_SPARE_1 GND

## XLR_CHASSIS

## AUD_MCLK_P

## GND

## AUDIO_12V GND

## AUDIO_12V GND

## AUD_ADC_SDOUT_N

## AUD_DAC_SDIN_N

## GND

XLR_CHASSIS | AIN_CH5_HOT AIN_CH6_HOT

## AUD_FSYNC_N

## AUD_BCLK_N

## GND

## AUD_MCLK_N

## AIN_CH2_COLD

## AIN_CH5_COLD

## XLR_CHASSIS

## AIN_CH6_COLD

## XLR_CHASSIS

## AIN_CH1_COLD

## XLR_CHASSIS

## XLR_CHASSIS

## AIN_CH8_HOT

## AOUT_CH2_COLD

## XLR_CHASSIS

## XLR_CHASSIS

## XLR_CHASSIS

## AIN_CH7_COLD

## XLR_CHASSIS

# AOUT_CH2_HOT AOUT_CH1_COLD

## XLR_CHASSIS

## AIN_CH8_COLD

## AIN_CH4_COLD

## XLR_CHASSIS

## AIN_CH3_COLD

## XLR_CHASSIS

## AOUT_CH1_HOT

## AGND

## AOUT_CH4_HOT

## AIN_CH7_HOT

XLR_CHASSIS | AOUT_CH3_COLD
XLR_CHASSIS | AOUT_CH3_HOT AOUT_CH4_COLD
AIN_CH4_HOT | AGND

## XLR_CHASSIS

## AIN_CH3_HOT AIN_CH2_HOT XLR_CHASSIS

## AIN_CH1_HOT

## XLR_CHASSIS

## XLR_CHASSIS

## AOUT_CH6_HOT AOUT_CH6_COLD

## XLR_CHASSIS

## XLR_CHASSIS

## XLR_CHASSIS

## XLR_CHASSIS

## XLR_CHASSIS

## XLR_CHASSIS

## XLR_CHASSIS

## AOUT_CH8_COLD

## AOUT_CH8_HOT

## AGND

## XLR_CHASSIS

## AOUT_CH5_HOT AOUT_CH5_COLD

## AUD_BCLK_P

J307 / NC3FAV CH6 OUT

J206 / NC3MAV

Mates with CM5-CARRIER J201; 100 ohm differential pairs with interleaved grounds. Detailed A1 sheet captures TDM256 straps, four VREFH feeds, low-noise rails, and the +24 dBu level map. J204 / NC3MAV CH4 OUT | CH4 IN
J304 / NC3FAV | Eight differential channels; no phantom power; +4 dBu nominal / +24 dBu max. NC3FAV -> chassis/RFI/ESD -> THAT1206 -> level/filter network -> AK5558VN C. INPUT SIGNAL CHAIN
J205 / NC3MAV | Hardware mute remains asserted through boot, clock loss, reset and power transfer. CH5 OUT

J203 / NC3MAV

Stable into 600 ohm test load; 10 kohm or higher is the normal operating load. AK4458VN -> reconstruction/gain filter -> OPA165x -> THAT1646 -> RFI/fault network -> NC3MAV D. OUTPUT SIGNAL CHAIN

## CH8 IN

## CH2 OUT

J202 / NC3MAV

## CH7 IN

## CH1 OUT

# J201 / NC3MAV CH3 OUT

J308 / NC3FAV

## CH6 IN

## CH3 IN

J303 / NC3FAV

# J306 / NC3FAV CH5 IN

J305 / NC3FAV

B. CARRIER INTERFACES | G. CONNECTED AUDIO-8X8 HIERARCHY

J301 / NC3FAV

Routing hold: AKM exposed-pad coupons and TQ2 insertion/land-pattern coupon 06 Audio-Power: TRI20 +/-15 V, 5.5 V pre-rail, dual LT3045, 3.3 V and star 05 Audio-Outputs: 8x OPA1652/THAT1646, fail-silent relays and protection 04 Audio-Inputs: 8x THAT1206, OPA1652, RFI/ESD and anti-alias networks

Local filtered conversion produces +/-15 V, AKM 5 V analog and audio 3.3 V.

03 AK4458-DAC: exact pins, serial control, references and reconstruction contract 02 AK5558-ADC: exact pins, TDM256/32-bit I2S straps, references and bypass 01 Audio-TDM-Clock: LVDS TDM, protected I2C/control, clock distribution E. DETAILED A1 CAPTURE SHEETS
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

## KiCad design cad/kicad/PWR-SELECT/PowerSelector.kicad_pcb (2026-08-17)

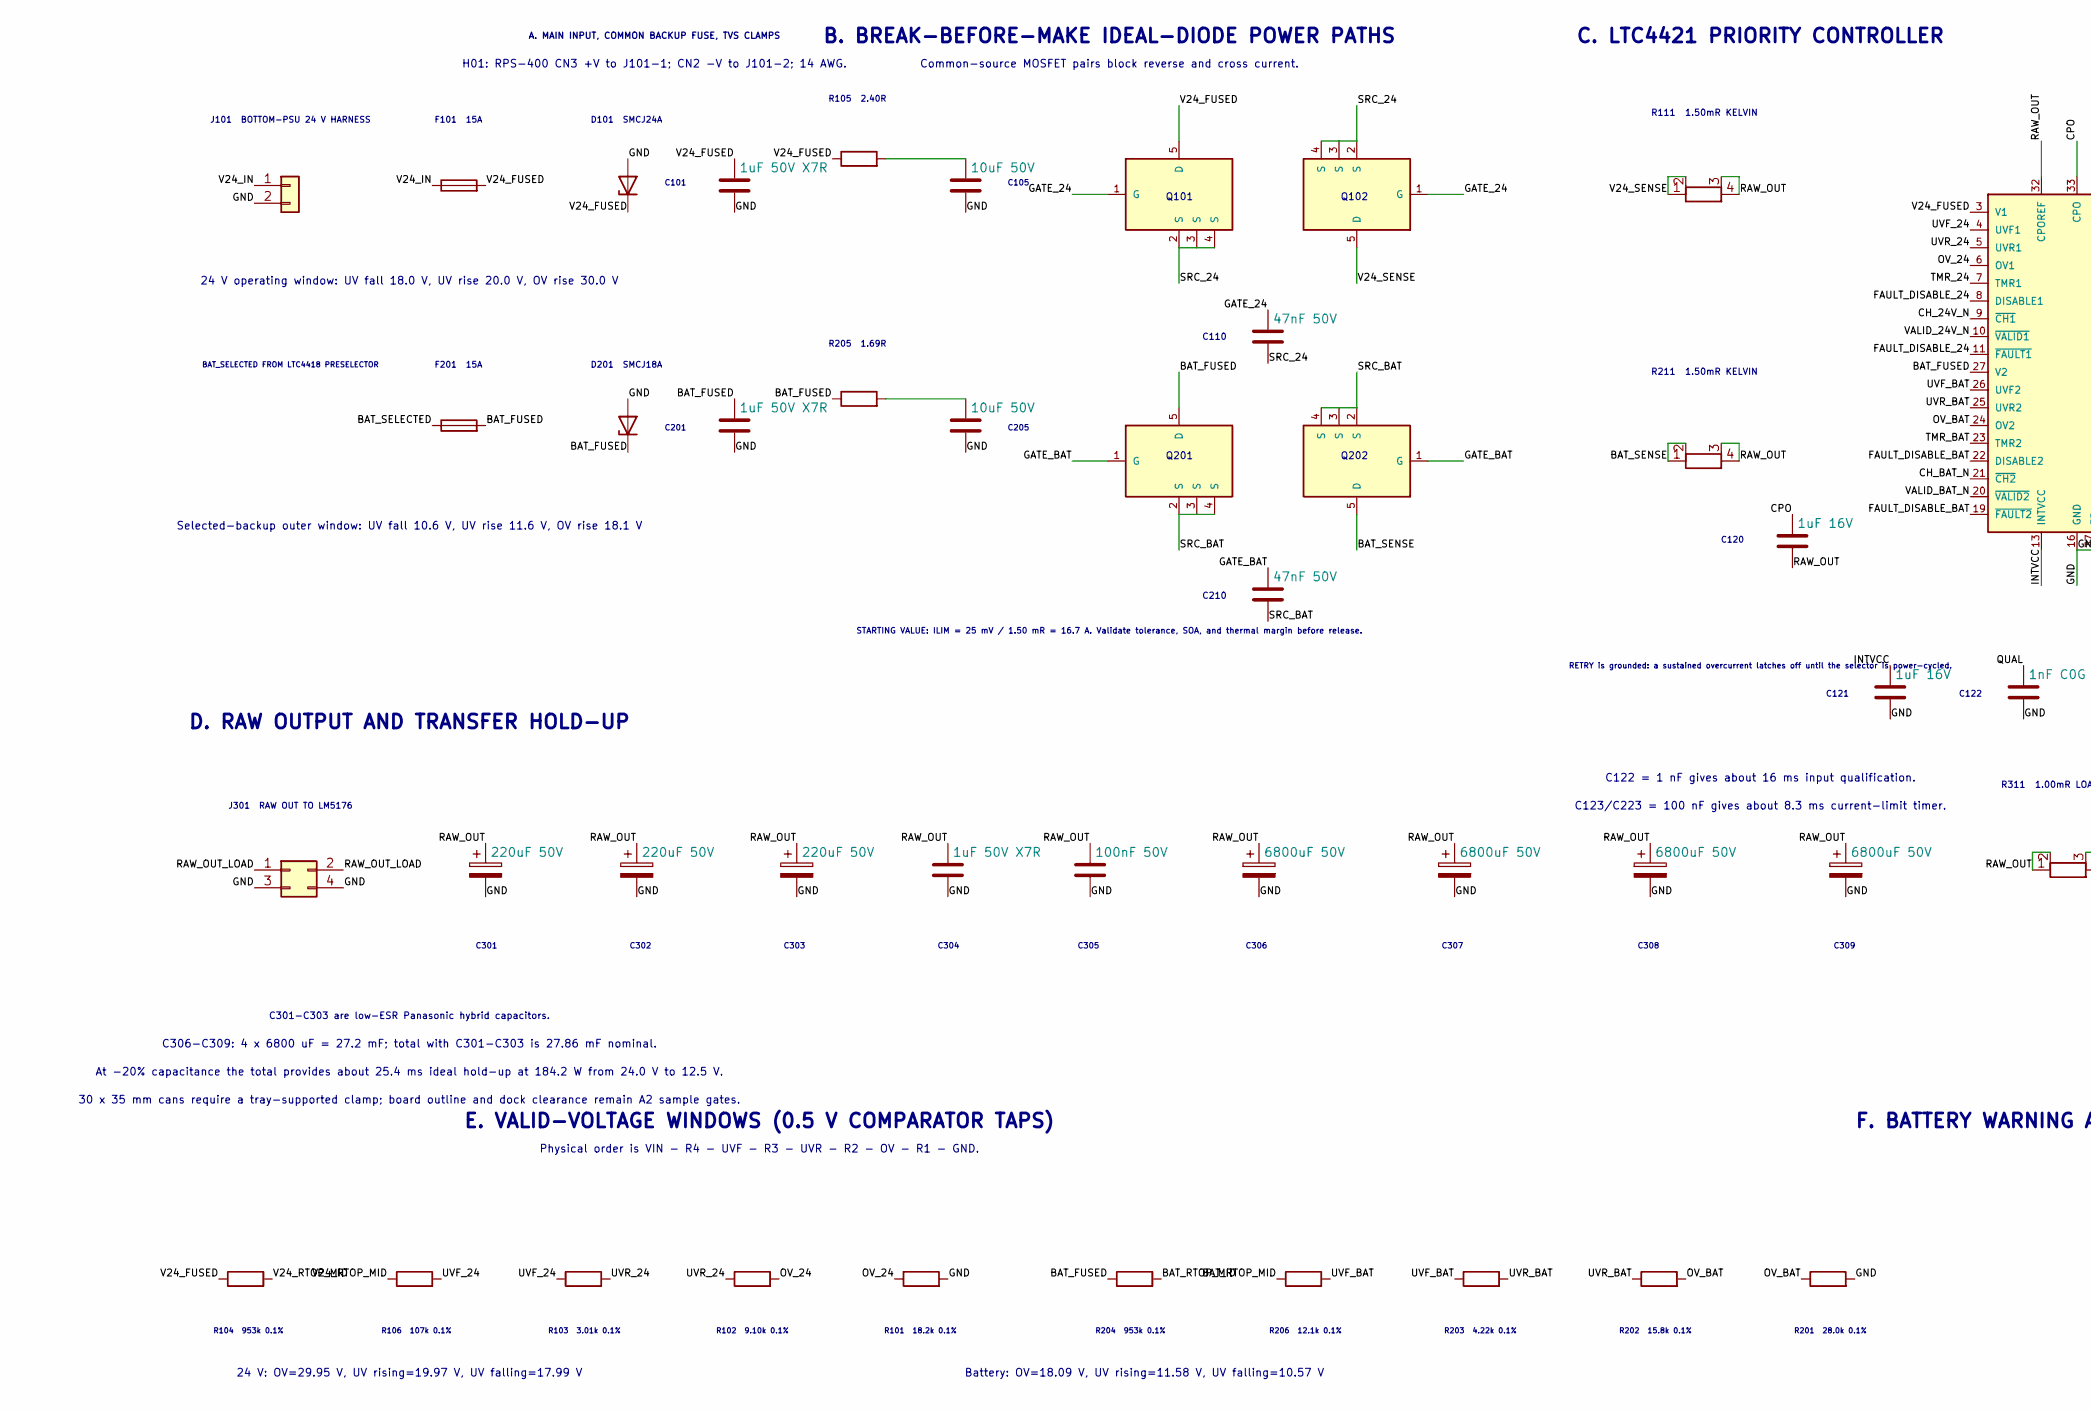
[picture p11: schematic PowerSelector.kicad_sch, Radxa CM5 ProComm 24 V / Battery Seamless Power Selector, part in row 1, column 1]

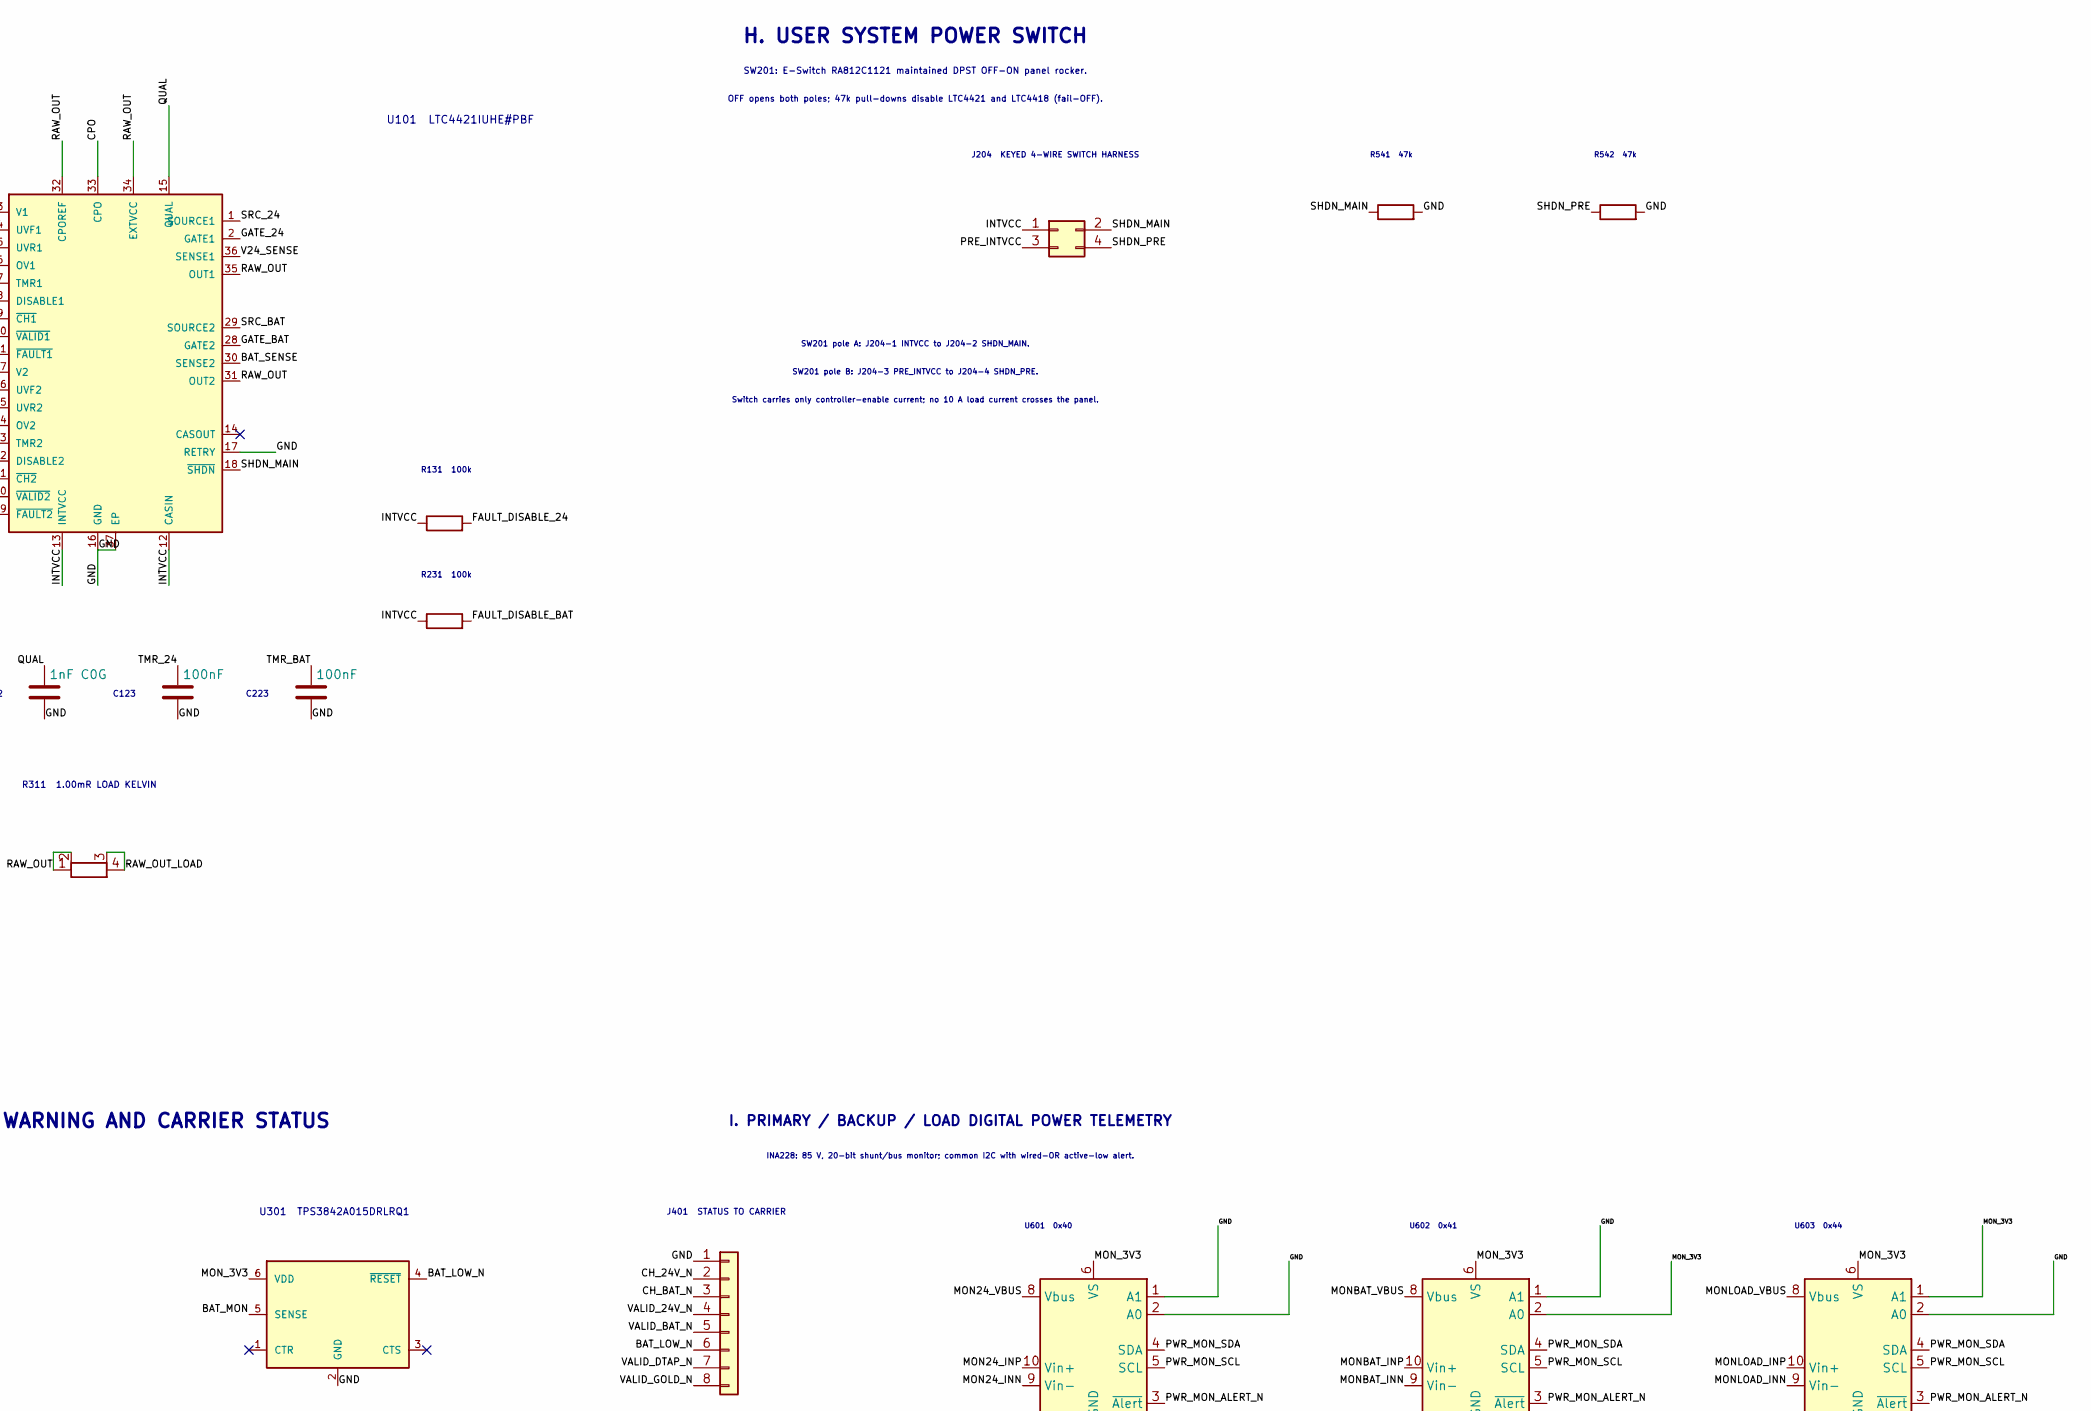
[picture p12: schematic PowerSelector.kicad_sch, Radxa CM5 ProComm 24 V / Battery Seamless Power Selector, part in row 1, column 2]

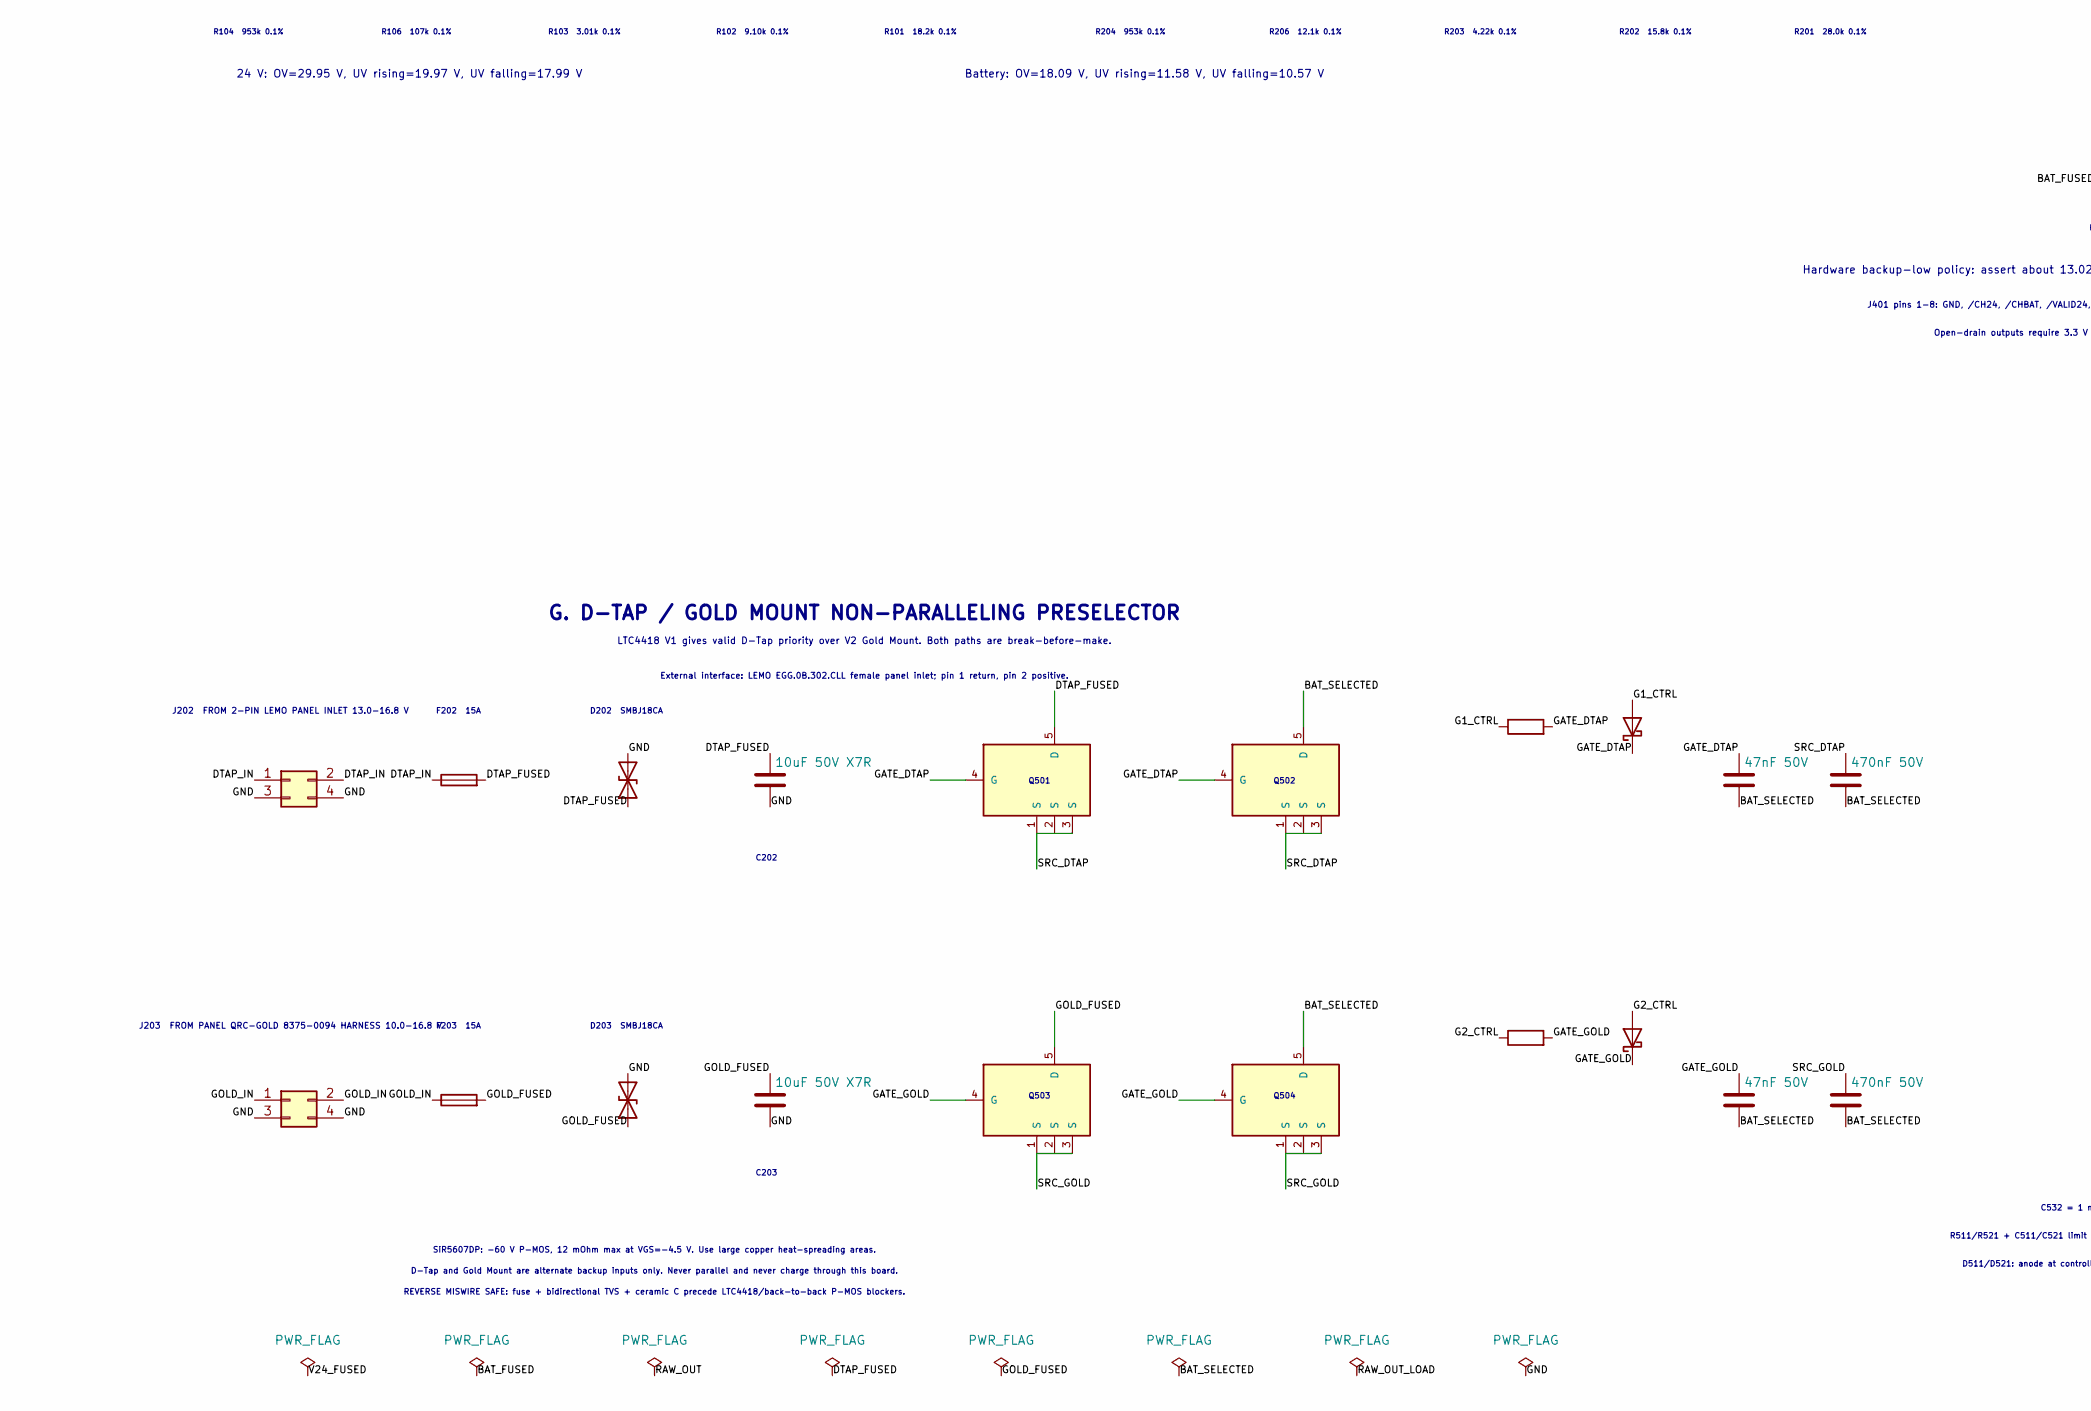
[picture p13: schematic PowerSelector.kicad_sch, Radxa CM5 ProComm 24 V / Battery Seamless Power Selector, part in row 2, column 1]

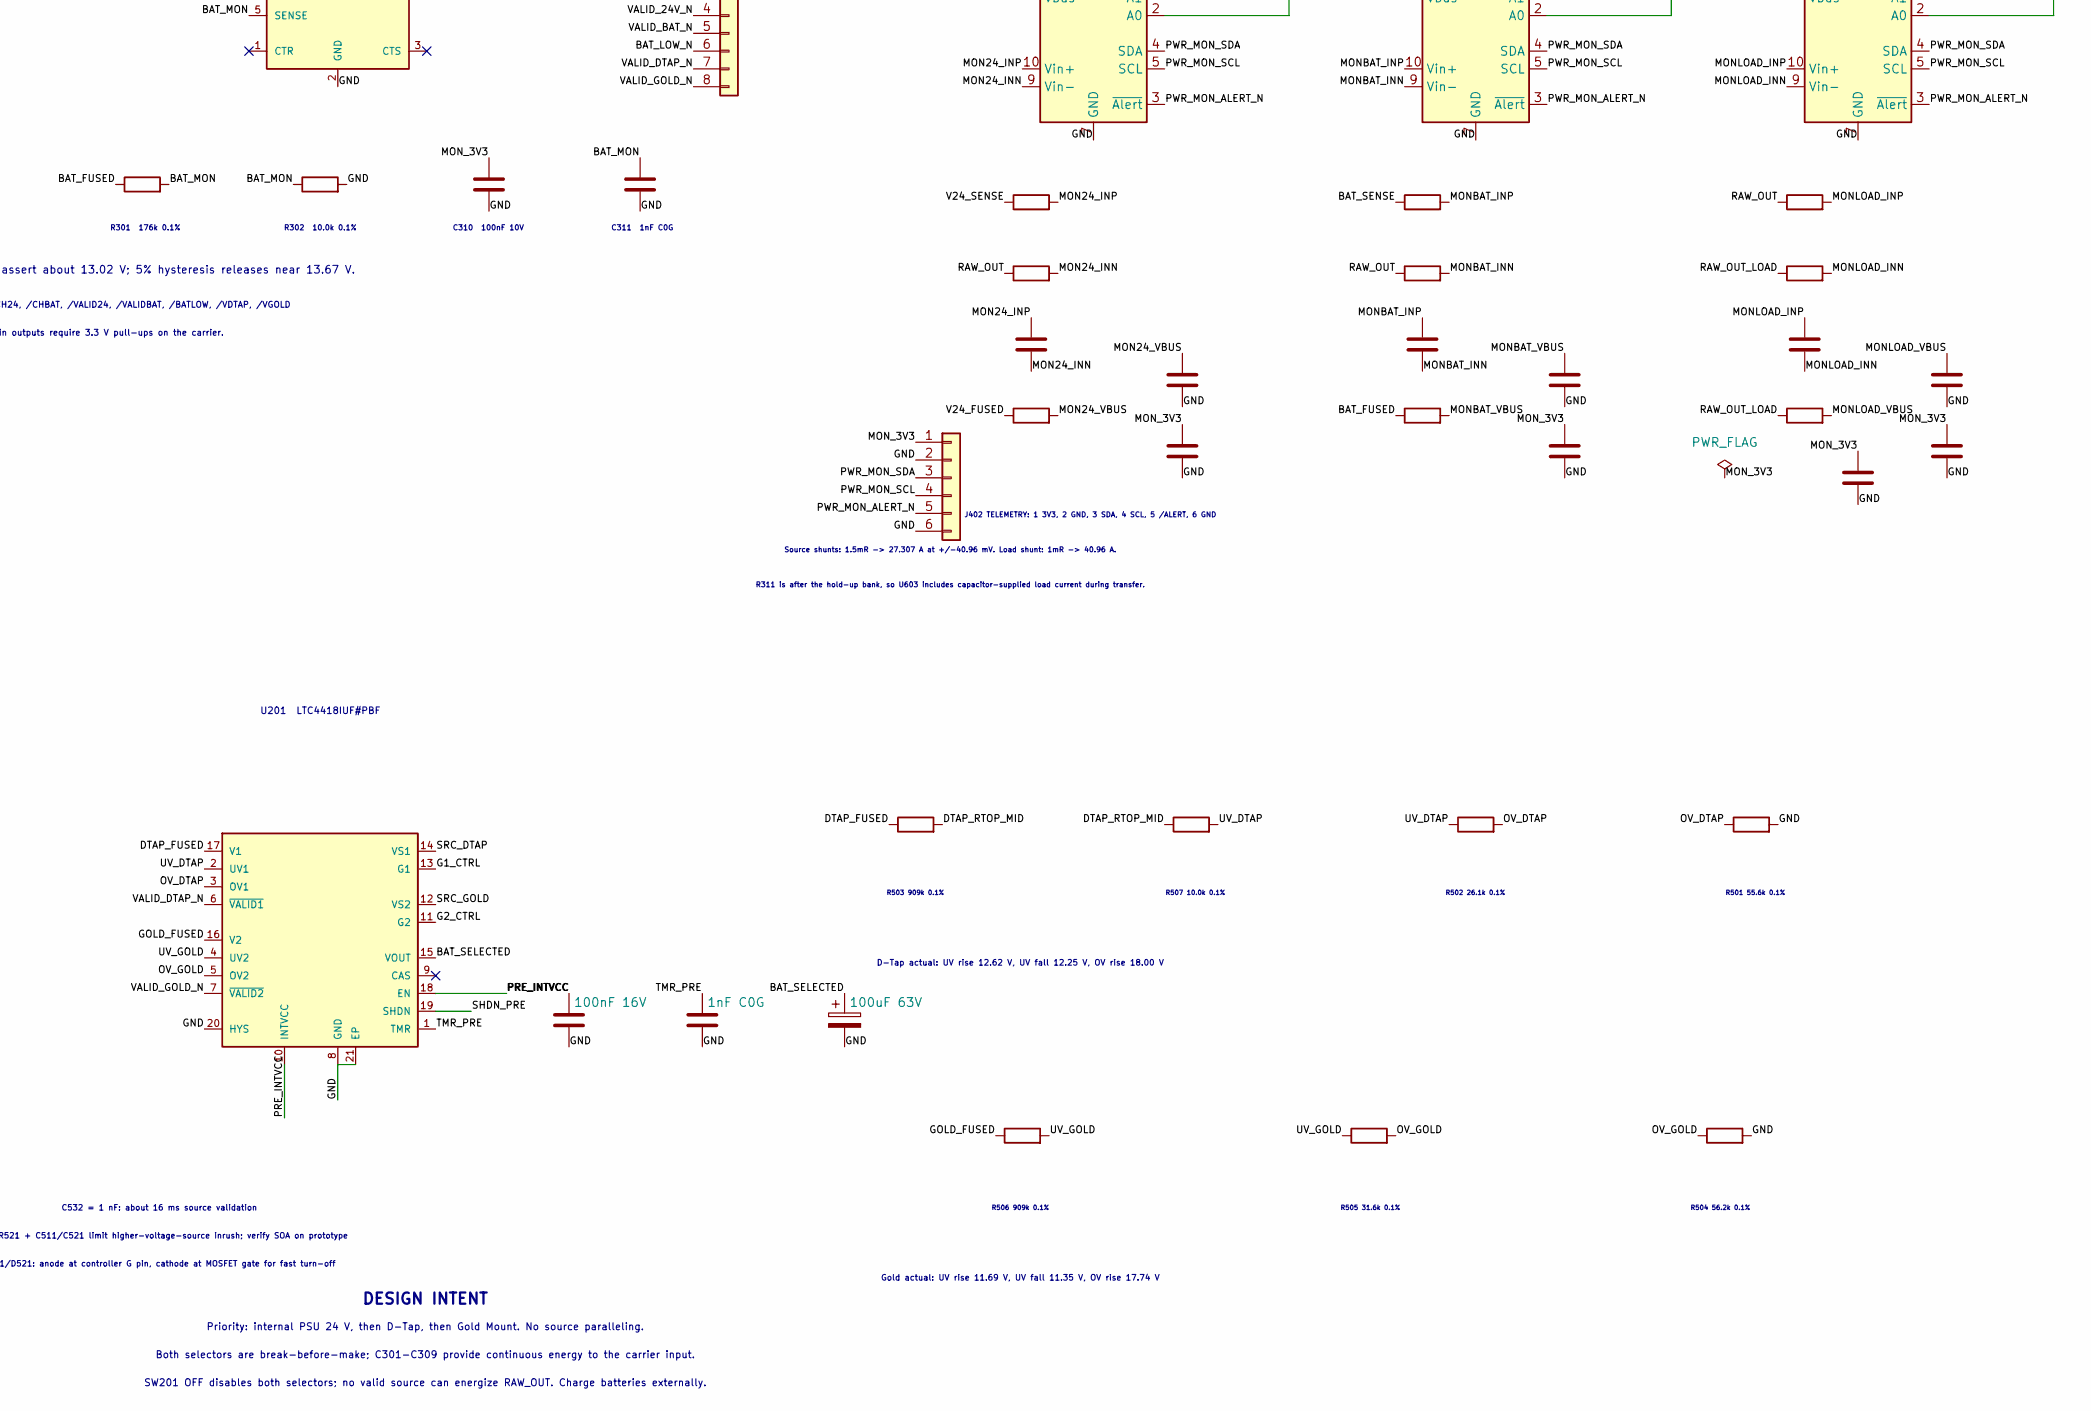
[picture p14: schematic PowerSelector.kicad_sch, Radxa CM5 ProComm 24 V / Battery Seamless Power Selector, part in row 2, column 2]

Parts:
C101, C201, C304: 1uF 50V X7R; C_1210_3225Metric; MPN GRM32RR71H105KA01L
C105, C205: 10uF 50V; C_1210_3225Metric; MPN GRM32ER71H106KA12L
C110, C210, C511, C521: 47nF 50V; C_0603_1608Metric; MPN GRM188R71H473KA61D
C120, C121: 1uF 16V; C_0603_1608Metric; MPN GRM188R71E105KA12D
C122, C532: 1nF C0G; C_0603_1608Metric; MPN GRM1885C1H102JA01D
C123, C223, C601, C603, C611, C613, C621, C623: 100nF; C_0603_1608Metric; MPN GRM188R71E104KA01D
C202, C203: 10uF 50V X7R; C_1210_3225Metric; MPN GRM32ER71H106KA12L
C301, C302, C303: 220uF 50V; CP_Panasonic_EEH-ZS_G16_10x16.8; MPN EEH-ZS1H221V
C305: 100nF 50V; C_0603_1608Metric; MPN GRM188R71H104KA93D
C306, C307, C308, C309: 6800uF 50V; CP_Radial_D30.0mm_P10.00mm_SnapIn; MPN LGU1H682MELB
C310: 100nF 10V X7R; C_0603_1608Metric; MPN GRM188R71E104KA01D
C311: 1nF 50V C0G; C_0603_1608Metric; MPN GRM1885C1H102JA01D
C512, C522: 470nF 50V; C_0603_1608Metric; MPN GRM188R71H474KA12D
C531: 100nF 16V; C_0603_1608Metric; MPN GRM188R71E104KA01D
C533: 100uF 63V; CP_Elec_10x10; MPN EEEFK1J101L
C602, C612, C622: 10nF 100V; C_0603_1608Metric; MPN GRM188R72A103KA01D
C630: 1uF; C_0603_1608Metric; MPN GRM188R71A105KA61D
D101: SMCJ24A; D_SMC; MPN SMCJ24A
D201: SMCJ18A; D_SMC; MPN SMCJ18A
D202, D203: SMBJ18CA; D_SMB; MPN SMBJ18CA
D511, D521: BAT46WJ; D_SOD-323; MPN BAT46WJ,115
F101, F201, F202, F203: 15A; Fuse_Littelfuse-NANO2-451_453; MPN 0451015.MRL
J101: PSU_24V_HARNESS; Molex_Mega-Fit_76825-0002_2x01_P5.70mm_Horizontal; MPN 76825-0002
J202: LEMO_EGG.0B.302.CLL_13V_TO_16V8; Molex_Micro-Fit_3.0_43045-0412_2x02_P3.00mm_Vertical; MPN 43045-0412
J203: GOLD_MOUNT_10V_TO_16V8; Molex_Micro-Fit_3.0_43045-0412_2x02_P3.00mm_Vertical; MPN 43045-0412
J204: PANEL_POWER_SWITCH_HARNESS; Molex_Micro-Fit_3.0_43045-0412_2x02_P3.00mm_Vertical; MPN 43045-0412
J301: RAW_OUT_TO_LM5176; Molex_Micro-Fit_3.0_43045-0412_2x02_P3.00mm_Vertical; MPN 43045-0412
J401: STATUS_TO_CARRIER_3V3_PULLUPS; Molex_PicoBlade_53047-0810_1x08_P1.25mm_Vertical; MPN 53047-0810
J402: POWER_TELEMETRY_TO_CARRIER; Molex_PicoBlade_53047-0610_1x06_P1.25mm_Vertical; MPN 53047-0610
Q101, Q102, Q201, Q202: PSMN4R2-80YSE; LFPAK56E_SOT1023; MPN PSMN4R2-80YSE
Q501, Q502, Q503, Q504: SiR5607DP-T1-RE3; PowerPAK_SO-8_Single; MPN SiR5607DP-T1-RE3
R101: 18.2k 0.1%; R_0603_1608Metric; MPN ERA3AEB1822V
R102: 9.10k 0.1%; R_0603_1608Metric; MPN ERA3AEB9101V
R103: 3.01k 0.1%; R_0603_1608Metric; MPN ERA3AEB3011V
R104, R204: 953k 0.1%; R_0603_1608Metric; MPN ERA3AEB9533V
R105: 2.40R 1%; R_0603_1608Metric; MPN RC0603FR-072R4L
R106: 107k 0.1%; R_0603_1608Metric; MPN ERA3AEB1073V
R111, R211: 1.50mR 1% 1W; R_Shunt_Vishay_WSK2512_6332Metric_T2.21mm; MPN WSK25121L500FEA
R131, R231: 100k; R_0603_1608Metric; MPN RC0603FR-07100KL
R201: 28.0k 0.1%; R_0603_1608Metric; MPN ERA3AEB2802V
R202: 15.8k 0.1%; R_0603_1608Metric; MPN ERA3AEB1582V
R203: 4.22k 0.1%; R_0603_1608Metric; MPN ERA3AEB4221V
R205: 1.69R 1%; R_0603_1608Metric; MPN RC0603FR-071R69L
R206: 12.1k 0.1%; R_0603_1608Metric; MPN ERA3AEB1212V
R301: 176k 0.1%; R_0603_1608Metric; MPN ERA3AEB1763V
R302, R507: 10.0k 0.1%; R_0603_1608Metric; MPN ERA3AEB1002V
R311: 1.00mR 1% 1W; R_Shunt_Vishay_WSK2512_6332Metric_T2.21mm; MPN WSK25121L000FEA
R501: 55.6k 0.1%; R_0603_1608Metric; MPN ERA3AEB5562V
R502: 26.1k 0.1%; R_0603_1608Metric; MPN ERA3AEB2612V
R503, R506: 909k 0.1%; R_0603_1608Metric; MPN ERA3AEB9093V
R504: 56.2k 0.1%; R_0603_1608Metric; MPN ERA3AEB5622V
R505: 31.6k 0.1%; R_0603_1608Metric; MPN ERA3AEB3162V
R511, R521: 6.81k 1%; R_0603_1608Metric; MPN RC0603FR-076K81L
R541, R542: 47k; R_0603_1608Metric; MPN RC0603FR-0747KL
R601, R602, R611, R612, R621, R622: 10R 1%; R_0603_1608Metric; MPN RC0603FR-0710RL
R603, R613, R623: 100R 1%; R_0603_1608Metric; MPN RC0603FR-07100RL
U101: LTC4421IUHE#PBF; QFN-36-1EP_5x6mm_P0.5mm_EP3.6x4.6mm_ThermalVias; MPN LTC4421IUHE#PBF
U201: LTC4418IUF#PBF; QFN-20-1EP_4x4mm_P0.5mm_EP2.6x2.6mm_ThermalVias; MPN LTC4418IUF#PBF
U301: TPS3842A015DRLRQ1; Texas_DRL0006A_SOT-5X3-6_1.6x1.6mm_P0.5mm; MPN TPS3842A015DRLRQ1
U601, U602, U603: INA228AIDGSR; TSSOP-10_3x3mm_P0.5mm; MPN INA228AIDGSR

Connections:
/BAT_FUSED: C201.1, D201.1 (K), F201.2, Q201.5 (D), R204.1, R205.1, R301.1, R613.1, U101.27 (V2)
/BAT_LOW_N: J401.6, U301.4 (~RESET)
/BAT_MON: C311.1, R301.2, R302.1, U301.5 (SENSE)
/BAT_RTOP_MID: R204.2, R206.1
/BAT_SELECTED: C511.2, C512.2, C521.2, C522.2, C533.1, F201.1, Q502.5 (D), Q504.5 (D), U201.15 (VOUT)
/BAT_SENSE: Q202.5 (D), R211.1, R211.2, R611.1, U101.30 (SENSE2)
/CH_24V_N: J401.2, U101.9 (~CH1)
/CH_BAT_N: J401.3, U101.21 (~CH2)
/CPO: C120.1, U101.33 (CPO)
/DTAP_FUSED: C202.1, D202.1 (A1), F202.2, Q501.5 (D), R503.1, U201.17 (V1)
/DTAP_IN: F202.1, J202.1, J202.2
/DTAP_RTOP_MID: R503.2, R507.1
/FAULT_DISABLE_24: R131.2, U101.8 (DISABLE1), U101.11 (~FAULT1)
/FAULT_DISABLE_BAT: R231.2, U101.19 (~FAULT2), U101.22 (DISABLE2)
/G1_CTRL: D511.2 (A), R511.1, U201.13 (G1)
/G2_CTRL: D521.2 (A), R521.1, U201.11 (G2)
/GATE_24: C110.1, Q101.1 (G), Q102.1 (G), U101.2 (GATE1)
/GATE_BAT: C210.1, Q201.1 (G), Q202.1 (G), U101.28 (GATE2)
/GATE_DTAP: C511.1, D511.1 (K), Q501.4 (G), Q502.4 (G), R511.2
/GATE_GOLD: C521.1, D521.1 (K), Q503.4 (G), Q504.4 (G), R521.2
/GND: C101.2, C105.2, C121.2, C122.2, C123.2, C201.2, C202.2, C203.2, C205.2, C223.2, C301.2, C302.2, C303.2, C304.2, C305.2, C306.2, C307.2, C308.2, C309.2, C310.2, C311.2, C531.2, C532.2, C533.2, C602.2, C603.2, C612.2, C613.2, C622.2, C623.2, C630.2, D101.2 (A), D201.2 (A), D202.2 (A2), D203.2 (A2), J101.2, J202.3, J202.4, J203.3, J203.4, J301.3, J301.4, J401.1, J402.2, J402.6, R101.2, R201.2, R302.2, R501.2, R504.2, R541.2, R542.2, U101.16 (GND), U101.17 (RETRY), U101.37 (EP), U201.8 (GND), U201.20 (HYS), U201.21 (EP), U301.2 (GND), U601.1 (A1), U601.2 (A0), U601.7 (GND), U602.1 (A1), U602.7 (GND), U603.2 (A0), U603.7 (GND)
/GOLD_FUSED: C203.1, D203.1 (A1), F203.2, Q503.5 (D), R506.1, U201.16 (V2)
/GOLD_IN: F203.1, J203.1, J203.2
/INTVCC: C121.1, J204.1, R131.1, R231.1, U101.12 (CASIN), U101.13 (INTVCC)
/MON24_INN: C601.2, R602.2, U601.9 (Vin-)
/MON24_INP: C601.1, R601.2, U601.10 (Vin+)
/MON24_VBUS: C602.1, R603.2, U601.8 (Vbus)
/MONBAT_INN: C611.2, R612.2, U602.9 (Vin-)
/MONBAT_INP: C611.1, R611.2, U602.10 (Vin+)
/MONBAT_VBUS: C612.1, R613.2, U602.8 (Vbus)
/MONLOAD_INN: C621.2, R622.2, U603.9 (Vin-)
/MONLOAD_INP: C621.1, R621.2, U603.10 (Vin+)
/MONLOAD_VBUS: C622.1, R623.2, U603.8 (Vbus)
/MON_3V3: C310.1, C603.1, C613.1, C623.1, C630.1, J402.1, U301.6 (VDD), U601.6 (VS), U602.2 (A0), U602.6 (VS), U603.1 (A1), U603.6 (VS)
/OV_24: R101.1, R102.2, U101.6 (OV1)
/OV_BAT: R201.1, R202.2, U101.24 (OV2)
/OV_DTAP: R501.1, R502.2, U201.3 (OV1)
/OV_GOLD: R504.1, R505.2, U201.5 (OV2)
/PRE_INTVCC: C531.1, J204.3, U201.10 (INTVCC), U201.18 (EN)
/PWR_MON_ALERT_N: J402.5, U601.3 (~Alert), U602.3 (~Alert), U603.3 (~Alert)
/PWR_MON_SCL: J402.4, U601.5 (SCL), U602.5 (SCL), U603.5 (SCL)
/PWR_MON_SDA: J402.3, U601.4 (SDA), U602.4 (SDA), U603.4 (SDA)
/QUAL: C122.1, U101.15 (QUAL)
/RAW_OUT: C120.2, C301.1, C302.1, C303.1, C304.1, C305.1, C306.1, C307.1, C308.1, C309.1, R111.3, R111.4, R211.3, R211.4, R311.1, R311.2, R602.1, R612.1, R621.1, U101.31 (OUT2), U101.32 (CPOREF), U101.34 (EXTVCC), U101.35 (OUT1)
/RAW_OUT_LOAD: J301.1, J301.2, R311.3, R311.4, R622.1, R623.1
/SHDN_MAIN: J204.2, R541.1, U101.18 (~SHDN)
/SHDN_PRE: J204.4, R542.1, U201.19 (SHDN)
/SRC_24: C110.2, Q101.2 (S), Q101.3 (S), Q101.4 (S), Q102.2 (S), Q102.3 (S), Q102.4 (S), U101.1 (SOURCE1)
/SRC_BAT: C210.2, Q201.2 (S), Q201.3 (S), Q201.4 (S), Q202.2 (S), Q202.3 (S), Q202.4 (S), U101.29 (SOURCE2)
/SRC_DTAP: C512.1, Q501.1 (S), Q501.2 (S), Q501.3 (S), Q502.1 (S), Q502.2 (S), Q502.3 (S), U201.14 (VS1)
/SRC_GOLD: C522.1, Q503.1 (S), Q503.2 (S), Q503.3 (S), Q504.1 (S), Q504.2 (S), Q504.3 (S), U201.12 (VS2)
/TMR_24: C123.1, U101.7 (TMR1)
/TMR_BAT: C223.1, U101.23 (TMR2)
/TMR_PRE: C532.1, U201.1 (TMR)
/UVF_24: R103.1, R106.2, U101.4 (UVF1)
/UVF_BAT: R203.1, R206.2, U101.26 (UVF2)
/UVR_24: R102.1, R103.2, U101.5 (UVR1)
/UVR_BAT: R202.1, R203.2, U101.25 (UVR2)
/UV_DTAP: R502.1, R507.2, U201.2 (UV1)
/UV_GOLD: R505.1, R506.2, U201.4 (UV2)
/V24_FUSED: C101.1, D101.1 (K), F101.2, Q101.5 (D), R104.1, R105.1, R603.1, U101.3 (V1)
/V24_IN: F101.1, J101.1
/V24_RTOP_MID: R104.2, R106.1
/V24_SENSE: Q102.5 (D), R111.1, R111.2, R601.1, U101.36 (SENSE1)
/VALID_24V_N: J401.4, U101.10 (~VALID1)
/VALID_BAT_N: J401.5, U101.20 (~VALID2)
/VALID_DTAP_N: J401.7, U201.6 (~VALID1)
/VALID_GOLD_N: J401.8, U201.7 (~VALID2)
unnamed: C105.1, R105.2
unnamed: C205.1, R205.2

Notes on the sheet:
A. MAIN INPUT, COMMON BACKUP FUSE, TVS CLAMPS
H01: RPS-400 CN3 +V to J101-1; CN2 -V to J101-2; 14 AWG.
J101 BOTTOM-PSU 24 V HARNESS
F101 15A
D101 SMCJ24A
C101
R105 2.40R
C105
24 V operating window: UV fall 18.0 V, UV rise 20.0 V, OV rise 30.0 V
F201 15A
BAT_SELECTED FROM LTC4418 PRESELECTOR
D201 SMCJ18A
C201
R205 1.69R
C205
Selected-backup outer window: UV fall 10.6 V, UV rise 11.6 V, OV rise 18.1 V
B. BREAK-BEFORE-MAKE IDEAL-DIODE POWER PATHS
Common-source MOSFET pairs block reverse and cross current.
Q101
Q102
C110
R111 1.50mR KELVIN
Q201
Q202
C210
R211 1.50mR KELVIN
STARTING VALUE: ILIM = 25 mV / 1.50 mR = 16.7 A. Validate tolerance, SOA, and thermal margin before release.
C. LTC4421 PRIORITY CONTROLLER
U101 LTC4421IUHE#PBF
RETRY is grounded: a sustained overcurrent latches off until the selector is power-cycled.
C120
C121
C122
C123
C223
R131 100k
R231 100k
C122 = 1 nF gives about 16 ms input qualification.
C123/C223 = 100 nF gives about 8.3 ms current-limit timer.
H. USER SYSTEM POWER SWITCH

Board: 6 copper layers, 111 parts (94 on the bottom side), 70 nets, no tracks yet.

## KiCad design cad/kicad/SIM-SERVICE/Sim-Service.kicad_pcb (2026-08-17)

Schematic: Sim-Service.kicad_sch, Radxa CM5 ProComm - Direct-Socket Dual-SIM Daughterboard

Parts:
J1: DUAL_SIM_B2B_RECEPTACLE; Hirose_DF40HC(2.5)-20DS-0.4V_2x10_P0.4mm; MPN DF40HC(2.5)-20DS-0.4V(51)
J2: SIM1_NANO_SIM; J_Wurth_WR-CRD_693043020611; MPN 693043020611
J3: SIM2_NANO_SIM; J_Wurth_WR-CRD_693043020611; MPN 693043020611
U1, U2: TPD3F303DPV; Texas_R-PUSON-N8_USON-8-1EP_1.6x2.1mm_P0.5mm_EP0.4x1.7mm; MPN TPD3F303DPVR

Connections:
CHASSIS_GND: J1.2, J1.16, J1.18, J1.20, J2.S1 (SHIELD), J2.S2 (SHIELD), J2.S3 (SHIELD), J2.S4 (SHIELD), J2.S5 (SHIELD), J2.S6 (SHIELD), J3.S1 (SHIELD), J3.S2 (SHIELD), J3.S3 (SHIELD), J3.S4 (SHIELD), J3.S5 (SHIELD), J3.S6 (SHIELD)
GND: J1.1, J1.5, J1.7, J1.11, J1.13, J1.15, J1.17, J1.19, J2.C5 (GND), J3.C5 (GND), U1.9 (GND), U2.9 (GND)
SIM1_CLK: J2.C3 (CLOCK), U1.2 (CLK_OUT)
SIM1_CLK_RAW: J1.6, U1.7 (CLK_IN)
SIM1_DATA: J2.C7 (I/O), U1.1 (DATA1_OUT)
SIM1_DATA_RAW: J1.8, U1.8 (DATA1_IN)
SIM1_RESET: J2.C2 (RESET), U1.3 (DATA2_OUT)
SIM1_RESET_RAW: J1.4, U1.6 (DATA2_IN)
SIM1_VCC: J1.3, J2.C1 (VCC), U1.5 (V_{CC})
SIM2_CLK: J3.C3 (CLOCK), U2.2 (CLK_OUT)
SIM2_CLK_RAW: J1.12, U2.7 (CLK_IN)
SIM2_DATA: J3.C7 (I/O), U2.1 (DATA1_OUT)
SIM2_DATA_RAW: J1.14, U2.8 (DATA1_IN)
SIM2_RESET: J3.C2 (RESET), U2.3 (DATA2_OUT)
SIM2_RESET_RAW: J1.10, U2.6 (DATA2_IN)
SIM2_VCC: J1.9, J3.C1 (VCC), U2.5 (V_{CC})

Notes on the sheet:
1. DIRECT CARRIER SOCKET
Direct pin-for-pin mate to CM5-CARRIER J702; no wire harness exists in the dual-SIM path.
2. GUIDED TOP-FACING NANO-SIM HOLDERS
SIM1: holder shield to chassis; C6/VPP intentionally NC
SIM2: holder shield to chassis; C6/VPP intentionally NC
Socket mouths face the daughterboard service edge. Do not rotate either socket independently during PCB placement.
The PCB lies parallel to the carrier and top panel. Four supports and the service guide, not J1 or solder joints, react card force.

Board: 4 copper layers, 9 parts (1 on the bottom side), 16 nets, no tracks yet.

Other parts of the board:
S1, S2, S3, S4: M3_CAPTIVE_SUPPORT_3.4; ProComm_M3_Support_NPTH_3.4mm

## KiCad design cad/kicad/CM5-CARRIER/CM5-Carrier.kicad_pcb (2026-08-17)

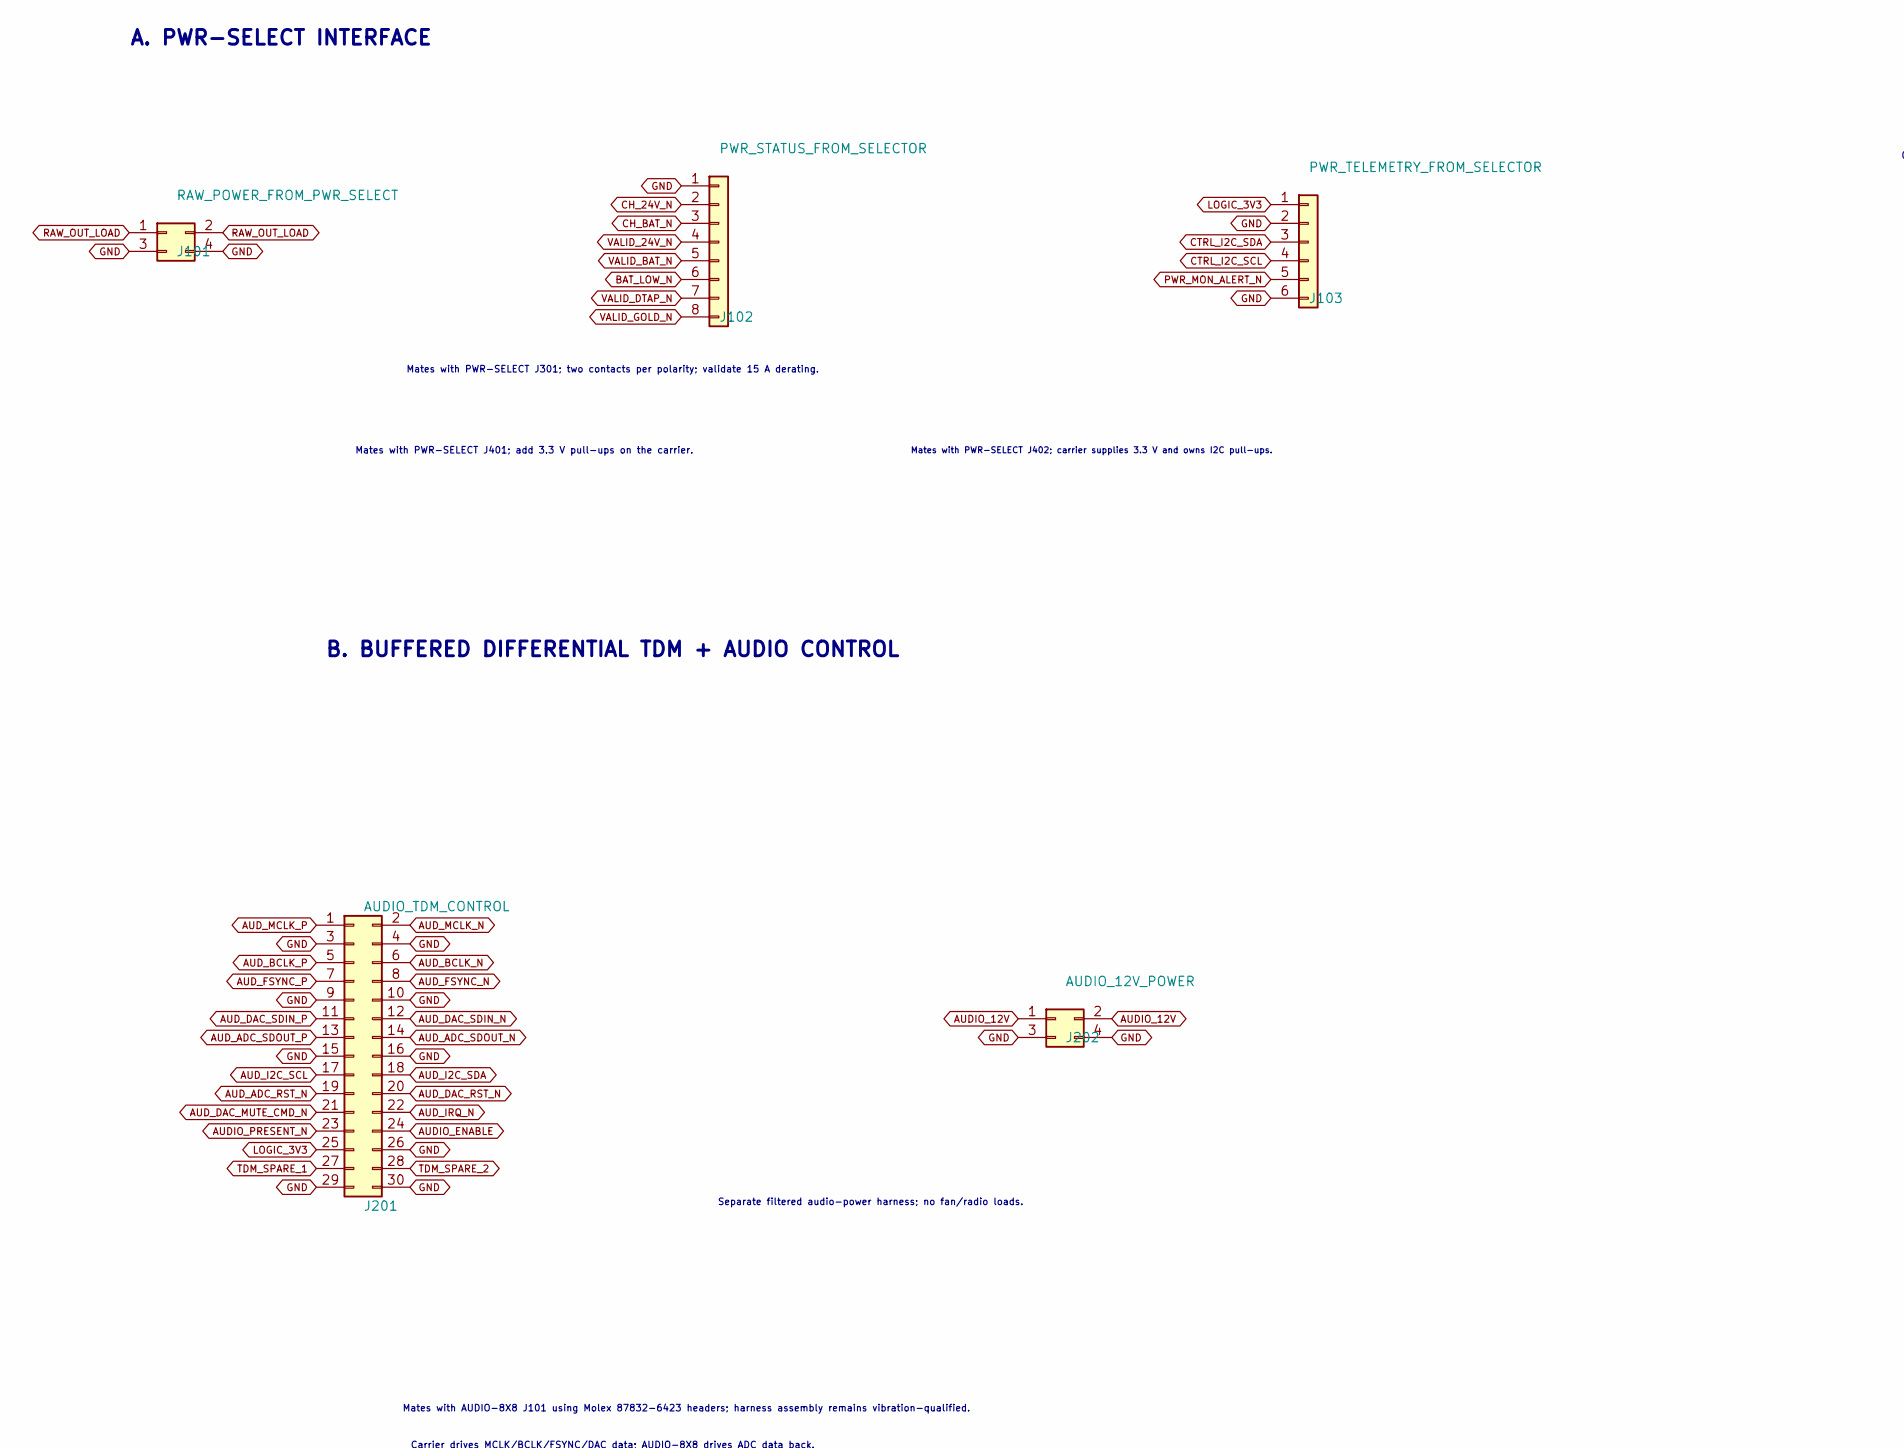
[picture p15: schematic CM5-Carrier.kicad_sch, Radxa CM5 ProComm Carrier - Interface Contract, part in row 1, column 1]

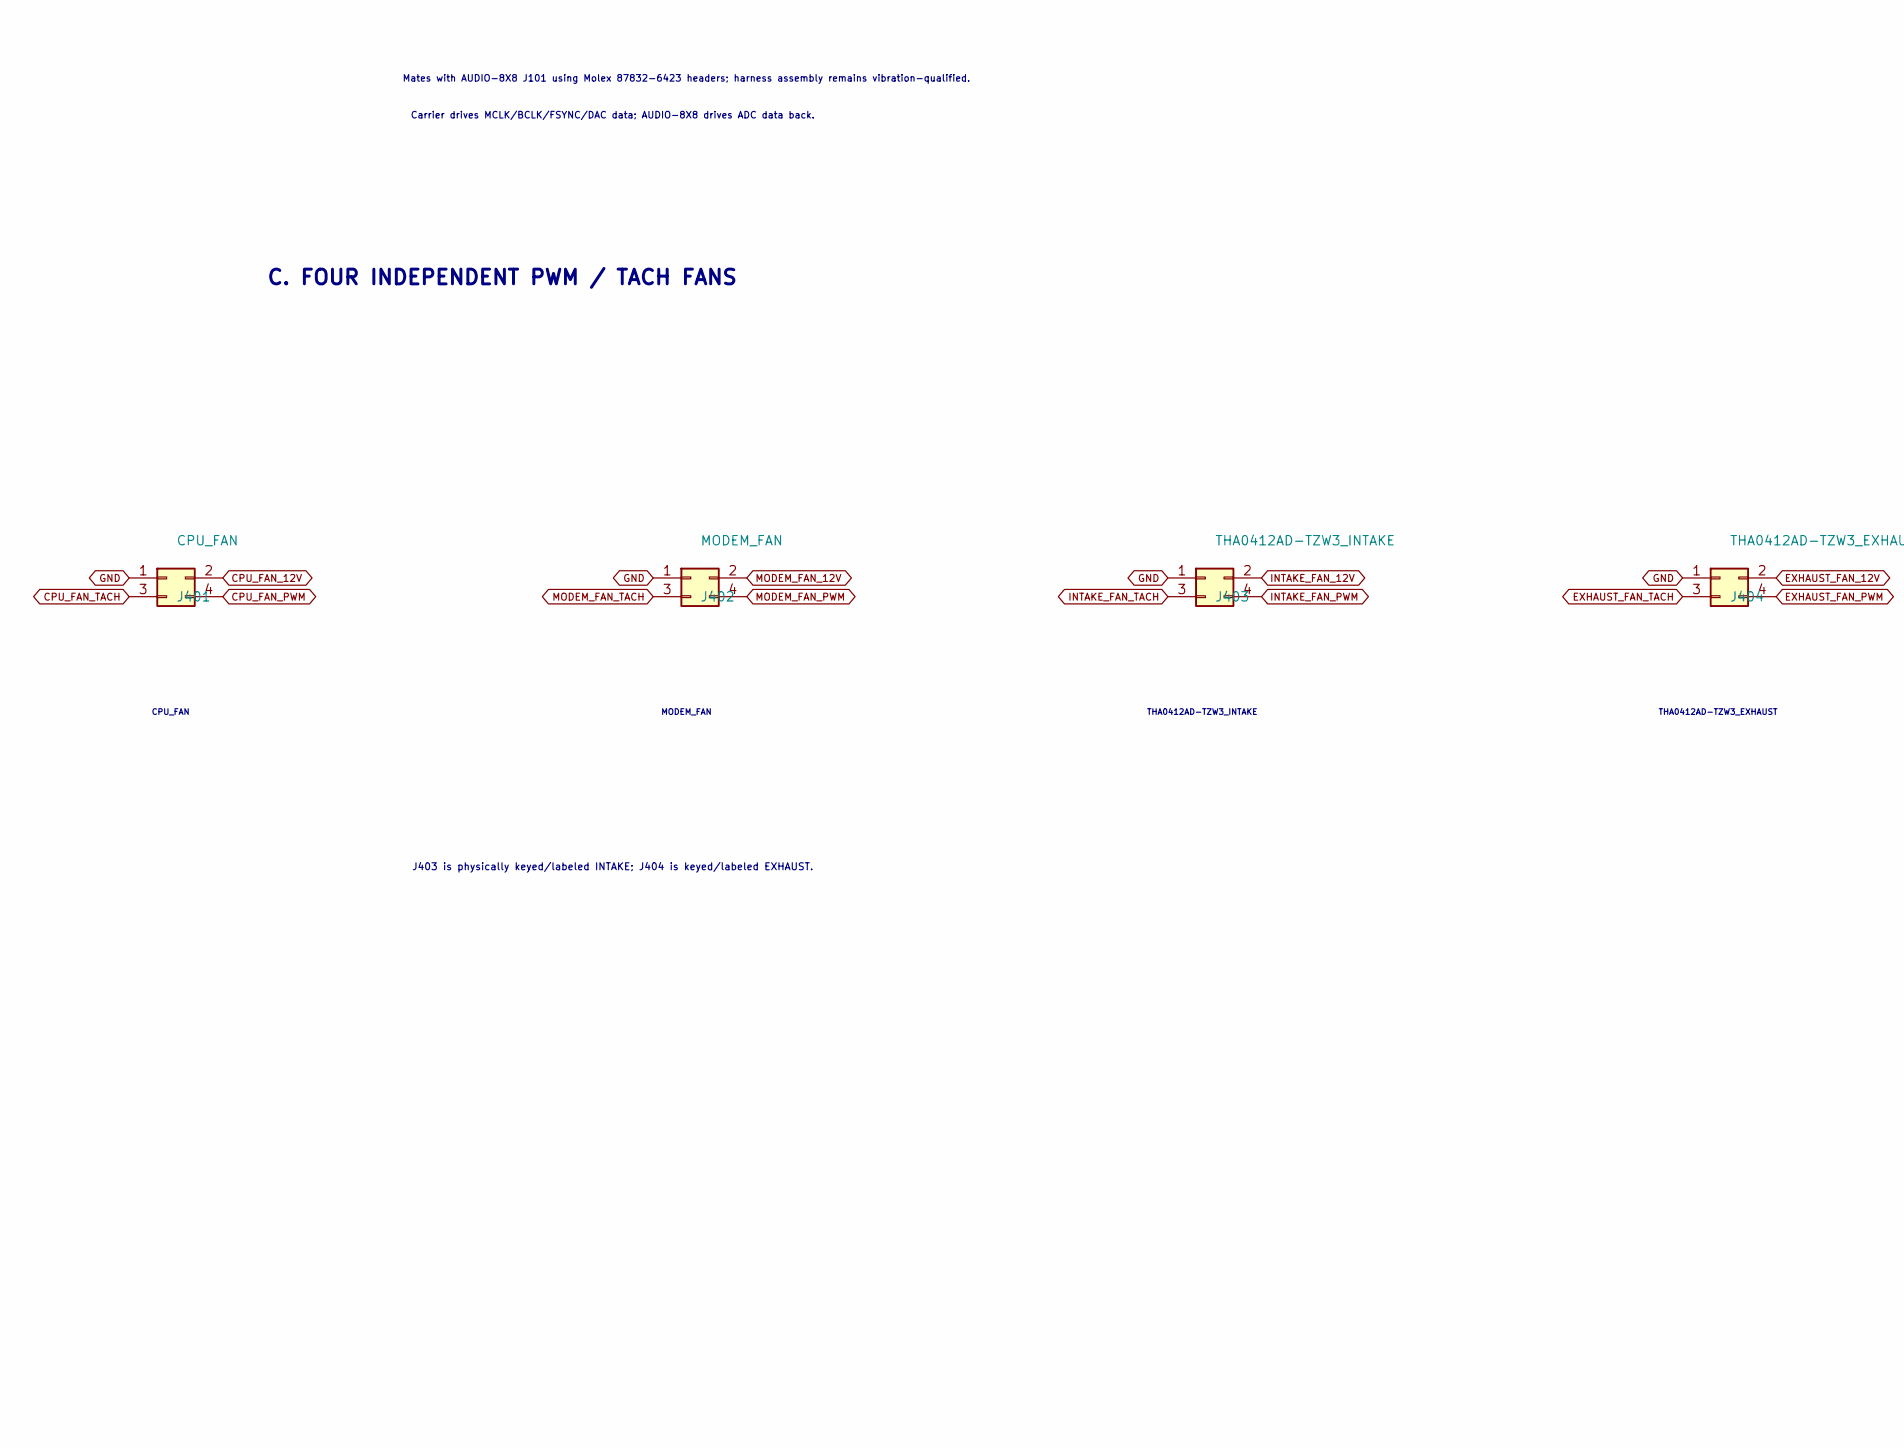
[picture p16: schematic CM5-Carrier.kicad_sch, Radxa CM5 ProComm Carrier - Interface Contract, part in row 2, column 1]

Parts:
J101: RAW_POWER_FROM_PWR_SELECT; Molex_Micro-Fit_3.0_43045-0412_2x02_P3.00mm_Vertical; MPN 43045-0412
J102: PWR_STATUS_FROM_SELECTOR; Molex_PicoBlade_53047-0810_1x08_P1.25mm_Vertical; MPN 53047-0810
J103: PWR_TELEMETRY_FROM_SELECTOR; Molex_PicoBlade_53047-0610_1x06_P1.25mm_Vertical; MPN 53047-0610
J201: AUDIO_TDM_CONTROL; Molex_8783230xx_2x15_P2.0mm_Header_Vertical_Polarized_Mount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; MPN 87832-6423
J202: AUDIO_12V_POWER; Molex_Micro-Fit_3.0_43045-0412_2x02_P3.00mm_Vertical; MPN 43045-0412
J401: CPU_FAN; Molex_Micro-Fit_3.0_43045-0412_2x02_P3.00mm_Vertical; MPN 43045-0412
J402: MODEM_FAN; Molex_Micro-Fit_3.0_43045-0412_2x02_P3.00mm_Vertical; MPN 43045-0412
J403: THA0412AD-TZW3_INTAKE; Molex_Micro-Fit_3.0_43045-0412_2x02_P3.00mm_Vertical; MPN 43045-0412
J404: THA0412AD-TZW3_EXHAUST; Molex_Micro-Fit_3.0_43045-0412_2x02_P3.00mm_Vertical; MPN 43045-0412

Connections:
AUDIO_12V: J202.1, J202.2; also elsewhere on the board
BAT_LOW_N: J102.6; also elsewhere on the board
CH_24V_N: J102.2; also elsewhere on the board
CH_BAT_N: J102.3; also elsewhere on the board
CTRL_I2C_SCL: J103.4; also elsewhere on the board
CTRL_I2C_SDA: J103.3; also elsewhere on the board
GND: J101.3, J101.4, J102.1, J103.2, J103.6, J201.3, J201.4, J201.9, J201.10, J201.15, J201.16, J201.26, J201.29, J201.30, J202.3, J202.4, J401.1, J402.1, J403.1, J404.1; also elsewhere on the board
LOGIC_3V3: J103.1, J201.25; also elsewhere on the board
unnamed: J101.1, J101.2
PWR_MON_ALERT_N: J103.5; also elsewhere on the board
VALID_24V_N: J102.4; also elsewhere on the board
VALID_BAT_N: J102.5; also elsewhere on the board
VALID_DTAP_N: J102.7; also elsewhere on the board
VALID_GOLD_N: J102.8; also elsewhere on the board

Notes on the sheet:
A. PWR-SELECT INTERFACE
Mates with PWR-SELECT J301; two contacts per polarity; validate 15 A derating.
Mates with PWR-SELECT J401; add 3.3 V pull-ups on the carrier.
Mates with PWR-SELECT J402; carrier supplies 3.3 V and owns I2C pull-ups.
B. BUFFERED DIFFERENTIAL TDM + AUDIO CONTROL
Mates with AUDIO-8X8 J101 using Molex 87832-6423 headers; harness assembly remains vibration-qualified.
Carrier drives MCLK/BCLK/FSYNC/DAC data; AUDIO-8X8 drives ADC data back.
Separate filtered audio-power harness; no fan/radio loads.
C. FOUR INDEPENDENT PWM / TACH FANS
CPU_FAN
MODEM_FAN
THA0412AD-TZW3_INTAKE
THA0412AD-TZW3_EXHAUST
J403 is physically keyed/labeled INTAKE; J404 is keyed/labeled EXHAUST.
D. DETAILED CAPTURE SUITE - REV A1
01 CM5-Core-Allocated: exact 300-contact CM5 symbol, 76 owned contacts (74 connected, 2 assigned NC)
02 CM5-Core-Allocated: VCC_SYSIN, reset, recovery, power-on and debug UART
03 Network-PCIe: PI7C9X2G608GP, 3x LAN7430 and native WAN1 front end
04 Network-PCIe: 4x Wurth MagJack and Molex 0679101002 Mini PCIe 4T4R Wi-Fi
05 WWAN-SIM: TE 2199230-3 B-key, USB3/USB2, controls and dual-SIM mux
06 Display-Harness: HDMI, USB touch and dedicated 12 V / 2.5 A branch
07 Audio-Control: I2S0 TDM, I2S1 ES8316 headset and CTIA amplifier path
08 Thermal-IO: I2C translation, GPIO expansion, sensors and four fan channels
09 Power-Regulators-A1: protected raw hold-up, all main rails, sequencing and test points
10 Audio-8x8: all XLR shields bonded to chassis with one controlled AGND bond
11 Review: all three board roots have zero ERC violations; child context is allowlisted
DC/DC compensation and magnetics remain a separate power-design calculation milestone.
High-speed routing starts only after stackup and connector Z datums are released.
The two enclosure fans require an underside baffle to prevent direct intake/exhaust short flow.
E. CONNECTED CM5-CARRIER HIERARCHY
J101/J201/J401-J404 are interface-only duplicates; the detailed-page connectors own the board footprints.

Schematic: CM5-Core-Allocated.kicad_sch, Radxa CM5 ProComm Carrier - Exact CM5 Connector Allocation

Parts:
J501: RADXA CM5 U13-A MATE; Radxa_CM5_U33A_DF40C_100DS_OFFICIAL; MPN DF40C-100DS-0.4V(51)
J502: RADXA CM5 U13-B MATE; Radxa_CM5_U33B_DF40C_100DS_OFFICIAL; MPN DF40C-100DS-0.4V(51)
J503: RADXA CM5 J1 MATE; Radxa_CM5_J24_DF40C_100DS_OFFICIAL; MPN DF40C-100DS-0.4V(51)
J510: CM5_POWER_SERVICE; JST_GH_BM06B-GHS-TBT_1x06-1MP_P1.25mm_Vertical; MPN BM06B-GHS-TBT(LF)(SN)
J511: DEBUG_UART_3V3; JST_GH_BM04B-GHS-TBT_1x04-1MP_P1.25mm_Vertical; MPN BM04B-GHS-TBT(LF)(SN)
J512: INTERNAL_USB_RECOVERY; JST_GH_BM05B-GHS-TBT_1x05-1MP_P1.25mm_Vertical; MPN BM05B-GHS-TBT(LF)(SN)
J513: CM5_POWER_ENTRY; Molex_Micro-Fit_3.0_43045-0812_2x04_P3.00mm_Vertical; MPN 43045-0812

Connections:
AUD_ADC_SDOUT: J501.54 (I2S0_SDI0); also elsewhere on the board
AUD_BCLK: J501.46 (I2S0_SCLK_TX); also elsewhere on the board
AUD_DAC_SDIN: J501.34 (I2S0_SDO0); also elsewhere on the board
AUD_FSYNC: J501.48 (I2S0_LRCK_TX); also elsewhere on the board
AUD_IRQ_N: J501.20 (HP_INT); also elsewhere on the board
AUD_MCLK: J501.50 (I2S0_MCLK); also elsewhere on the board
CM5_BOOT: J501.93 (SARADC_VIN0_BOOT), J510.4
CM5_PWRON_N: J501.99 (PWRON_L), J510.5
CM5_RECOVERY_KEY: J503.26 (SARADC_VIN1_KEY/RECOVERY), J510.6
CM5_RESET_N: J501.92 (RESET_L), J510.3
DBG_UART_RX: J501.51 (UART2_RX_M0), J511.4
DBG_UART_TX: J501.55 (UART2_TX_M0), J511.3
GND: J501.1 (GND), J501.2 (GND), J501.7 (GND), J501.8 (GND), J501.13 (GND), J501.14 (GND), J501.22 (GND), J501.23 (GND), J501.32 (GND), J501.33 (GND), J501.42 (GND), J501.43 (GND), J501.52 (GND), J501.53 (GND), J501.59 (GND), J501.60 (GND), J501.65 (GND), J501.66 (GND), J501.71 (GND), J501.74 (GND), J501.98 (GND), J501.201 (MODULE_MOUNT_GND_1), J501.202 (MODULE_MOUNT_GND_2), J501.203 (MODULE_MOUNT_GND_3), J501.204 (MODULE_MOUNT_GND_4), J502.107 (GND), J502.108 (GND), J502.113 (GND), J502.114 (GND), J502.119 (GND), J502.120 (GND), J502.125 (GND), J502.126 (GND), J502.131 (GND), J502.132 (GND), J502.137 (GND), J502.138 (GND), J502.144 (GND), J502.150 (GND), J502.155 (GND), J502.156 (GND), J502.161 (GND), J502.162 (GND), J502.167 (GND), J502.168 (GND), J502.173 (GND), J502.174 (GND), J502.179 (GND), J502.180 (GND), J502.185 (GND), J502.186 (GND), J502.191 (GND), J502.192 (GND), J502.197 (GND), J502.198 (GND), J503.1 (GND), J503.2 (GND), J503.7 (GND), J503.13 (GND), J503.19 (GND), J503.22 (GND), J503.25 (GND), J503.31 (GND), J503.32 (GND), J503.37 (GND), J503.42 (GND), J503.43 (GND), J503.48 (GND), J503.49 (GND), J503.55 (GND), J503.56 (GND), J503.61 (GND), J503.62 (GND), J503.67 (GND), J503.68 (GND), J503.72 (GND), J503.73 (GND), J503.76 (GND), J503.99 (GND), J503.100 (GND), J510.2, J511.2, J512.5, J513.5, J513.6, J513.7, J513.8; also elsewhere on the board
HDMI_CEC: J502.151 (HDMI_TX0_CEC_PORT); also elsewhere on the board
HDMI_CLK_N: J502.190 (HDMI0_TX3N); also elsewhere on the board
HDMI_CLK_P: J502.188 (HDMI0_TX3P); also elsewhere on the board
HDMI_D0_N: J502.184 (HDMI0_TX0N); also elsewhere on the board
HDMI_D0_P: J502.182 (HDMI0_TX0P); also elsewhere on the board
HDMI_D1_N: J502.178 (HDMI0_TX1N); also elsewhere on the board
HDMI_D1_P: J502.176 (HDMI0_TX1P); also elsewhere on the board
HDMI_D2_N: J502.172 (HDMI0_TX2N); also elsewhere on the board
HDMI_D2_P: J502.170 (HDMI0_TX2P); also elsewhere on the board
HDMI_DDC_SCL: J502.200 (HDMI_TX0_SCL_5V); also elsewhere on the board
HDMI_DDC_SDA: J502.199 (HDMI_TX0_SDA_5V); also elsewhere on the board
HDMI_HEAC_P: J502.145 (HDMI0_TX_SBDP); also elsewhere on the board
HDMI_HPD: J502.153 (HDMI_TX0_HPD); also elsewhere on the board
HS_BCLK: J501.28 (SPIO_MOSI_M1); also elsewhere on the board
HS_I2C_SCL: J503.6 (GPIO3_B7); also elsewhere on the board
HS_I2C_SDA: J503.4 (GPIO3_C0); also elsewhere on the board
HS_JACK_DET_N: J503.36 (HP_DET_L); also elsewhere on the board
HS_LRCK: J501.30 (SPIO_CLK_M1); also elsewhere on the board
HS_MCLK: J501.100 (SPIO_MISO_M1); also elsewhere on the board
HS_SDIN_FROM_CODEC: J503.40 (GPIO4_A5); also elsewhere on the board
HS_SDOUT_TO_CODEC: J501.31 (SPIO_CS0M1); also elsewhere on the board
IO_5V0: J502.106 (5V_HDMI); also elsewhere on the board
LOGIC_3V3: J501.78 (GPIO_VREF), J510.1, J511.1; also elsewhere on the board
PCIE_UP_CLKREQ_N: J502.102 (PCIE20X1_2_CLKREQN_M0); also elsewhere on the board
PCIE_UP_PERST_CMD_N: J502.109 (PCIE20X1_2_PERSTN_M0); also elsewhere on the board
PCIE_UP_REFCLK_N: J502.112 (PCIE20_0_REFCLKN); also elsewhere on the board
PCIE_UP_REFCLK_P: J502.110 (PCIE20_0_REFCLKP); also elsewhere on the board
PCIE_UP_RX_N_CM5: J502.118 (PCIE20_0_RXN); also elsewhere on the board
PCIE_UP_RX_P_CM5: J502.116 (PCIE20_0_RXP); also elsewhere on the board
PCIE_UP_TX_N_CM5: J502.124 (PCIE20_0_TXN); also elsewhere on the board
PCIE_UP_TX_P_CM5: J502.122 (PCIE20_0_TXP); also elsewhere on the board
PCIE_UP_WAKE_N: J501.24 (PCIE20X1_2_WAKEN_M0); also elsewhere on the board
REC_USB_DM: J502.103 (TYPEC0_OTG_DM), J512.2
REC_USB_DP: J502.105 (TYPEC0_OTG_DP), J512.3
REC_USB_ID: J502.101 (TYPEC0_USB20_OTG_ID), J512.4
REC_USB_VBUS_DET: J503.97 (TYPEC0_OTG_VBUSDET), J512.1
SYS_4V0: J501.77 (VCC_SYSIN), J501.79 (VCC_SYSIN), J501.81 (VCC_SYSIN), J501.83 (VCC_SYSIN), J501.85 (VCC_SYSIN), J501.87 (VCC_SYSIN), J513.1, J513.2, J513.3, J513.4; also elsewhere on the board
SYS_I2C7_SCL: J501.80 (I2C7_SCL_M2); also elsewhere on the board
SYS_I2C7_SDA: J501.82 (I2C7_SDA_M2); also elsewhere on the board
TOUCH_USB_DM: J503.47 (USB20_HOST1_DM); also elsewhere on the board
TOUCH_USB_DP: J503.45 (USB20_HOST1_DP); also elsewhere on the board
WAN1_LED0: J501.19 (PHY1_LED0_Y1); also elsewhere on the board
WAN1_LED1: J501.17 (PHY1_LED1_G); also elsewhere on the board
WAN1_MDI0_N: J501.10 (PHY1_MDI0-); also elsewhere on the board
WAN1_MDI0_P: J501.12 (PHY1_MDI0+); also elsewhere on the board
WAN1_MDI1_N: J501.6 (PHY1_MDI1-); also elsewhere on the board
WAN1_MDI1_P: J501.4 (PHY1_MDI1+); also elsewhere on the board
WAN1_MDI2_N: J501.9 (PHY1_MDI2-); also elsewhere on the board
WAN1_MDI2_P: J501.11 (PHY1_MDI2+); also elsewhere on the board
WAN1_MDI3_N: J501.5 (PHY1_MDI3-); also elsewhere on the board
WAN1_MDI3_P: J501.3 (PHY1_MDI3+); also elsewhere on the board
WWAN_USB2_DM: J503.65 (USB20_HOST0_DM); also elsewhere on the board
WWAN_USB2_DP: J503.63 (USB20_HOST0_DP); also elsewhere on the board
WWAN_USB3_RX_N: J503.59 (USB30_2_SSRXN); also elsewhere on the board
WWAN_USB3_RX_P: J503.57 (USB30_2_SSRXP); also elsewhere on the board
WWAN_USB3_TX_N: J503.53 (USB30_2_SSTXN); also elsewhere on the board
WWAN_USB3_TX_P: J503.51 (USB30_2_SSTXP); also elsewhere on the board

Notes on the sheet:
1. EXACT RADXA CM5 MATING CONNECTORS
U13-A: 100 contacts + official grounded module pads 201-204
U13-B: 100 physical contacts
J1: 100 physical contacts
2. INTERNAL POWER / STARTUP / RECOVERY SERVICE
Internal keyed service header; never exposed on the top panel.
3.3 V UART only; keyed factory/debug cable.
Internal keyed recovery harness; service fixture owns the protected USB-C receptacle and CC network.
Kelvin-sense SYS_4V0 at J501; 4.0 V follows the Radxa CM5 carrier design note.
PCB lock: J501 and J502 share the U33 origin; J503 is +11.405, -25.415 mm at -90 degrees.
3. OWNERSHIP AUDIT
76 / 76 contacts owned; 74 connected, 2 assigned NC, 0 duplicate physical-pin claims.
WAN1 uses native MDI. PCIe Gen2 x1 feeds the packet switch.
WWAN owns USB30_2 + USB20_HOST0; touch owns USB20_HOST1.
HDMI_TX0, I2S0 TDM, I2S1 headset, I2C7, I2C3 and UART2 are reserved exactly once.
Pin 145 reaches HDMI pin 14; pin 147 is assigned NC because HEAC/ARC is unused. U13-B pin 106 receives IO_5V0.
Unused alternate-function contacts carry explicit no-connect markers on this A1 baseline.

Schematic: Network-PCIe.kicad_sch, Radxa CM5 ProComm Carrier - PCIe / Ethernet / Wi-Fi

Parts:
C601, C602, C603, C604, C605, C606, C607, C608, C609, C610, C611, C6112, C6122, C6132, C6601, C6602, C6603, C6604, C6605, C6606, C6607, C6608, C6609, C6610, C6611, C6612, C6613, C6614, C6615, C6616, C6617, C6618, C6619, C6620, C6621, C6622, C6623, C6624, C6625, C6626, C6627, C6628, C6629, C61110, C61111, C61112, C61113, C61114, C61115, C61210, C61211, C61212, C61213, C61214, C61215, C61310, C61311, C61312, C61313, C61314, C61315: 100nF; C_0402_1005Metric; MPN C1005X7R1H104K050BB
C6111, C6121, C6131, C6630, C6631: 22uF 10V X7R; C_0805_2012Metric; MPN GRM21BR71A226ME44L
C6113, C6123, C6133: 1uF 35V X5R / ESR <1R; C_0402_1005Metric; MPN GRM155R6YA105KE11D
C6114, C6115, C6124, C6125, C6134, C6135: 15pF C0G; C_0402_1005Metric; MPN GRM1555C1H150JA01D
C6116, C6117, C6118, C6119, C6126, C6127, C6128, C6129, C6136, C6137, C6138, C6139: 10nF; C_0603_1608Metric; MPN GRM188R71H103KA01D
FB6111, FB6112, FB6121, FB6122, FB6131, FB6132: 220R ferrite; L_0805_2012Metric; MPN BLM21PG221SN1D
J610, J611, J612, J613: V8BR-1AX1-GH; Bel_V8BR_1AX1_GH; MPN V8BR-1AX1-GH
J620: AW7915-NP1_WIFI6_4T4R; Molex_0679101002_Mini_PCIe; MPN 0679101002
L6111, L6121, L6131: 3.3uH / 2.37A min; TDK_VLS3012HBX; MPN VLS3012HBX-3R3M-N
R601: 4.7k; R_0603_1608Metric; MPN RC0603FR-074K7L
R602, R603: 1.43k 1%; R_0603_1608Metric; MPN RC0603FR-071K43L
R604: 475R 1%; R_0603_1608Metric; MPN RC0603FR-07475RL
R605, R606: 2.2k; R_0603_1608Metric; MPN RC0603FR-072K2L
R607: 0R; R_0603_1608Metric; MPN RC0603JR-070RL
R608: 100k; R_0603_1608Metric; MPN RC0603FR-07100KL
R620, R6113, R6123, R6133: 10k; R_0603_1608Metric; MPN RC0603FR-0710KL
R650, R651, R652, R653, R654, R655, R656, R657: 330R; R_0603_1608Metric; MPN RC0603FR-07330RL
R6111, R6121, R6131: 200R 1%; R_0603_1608Metric; MPN RC0603FR-07200RL
R6112, R6122, R6132: 6.04k 1%; R_0603_1608Metric; MPN RC0603FR-076K04L
U601: PI7C9X2G608GP; BGA-196_15x15mm_Layout14x14_P1.0mm; MPN PI7C9X2G608GPCNJEX
U606: SN74LVC1G11DBVR; SOT-23-6; MPN SN74LVC1G11DBVR
U611, U612, U613: LAN7430; QFN-48-1EP_7x7mm_P0.5mm_EP5.3x5.3mm_ThermalVias; MPN LAN7430T-I/Y9X
U630, U631, U632, U633, U634, U635, U636, U637: TPD4E05U06DQA; USON-10_2.5x1.0mm_P0.5mm; MPN TPD4E05U06DQAR
Y611, Y612, Y613: 25MHz / 10pF / -40..85C; Crystal_SMD_3225-4Pin_3.2x2.5mm; MPN ABM8-25.000MHZ-10-D1G-T

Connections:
CHASSIS_GND: J610.21 (SHIELD), J610.22 (SHIELD), J611.21 (SHIELD), J611.22 (SHIELD), J612.21 (SHIELD), J612.22 (SHIELD), J613.21 (SHIELD), J613.22 (SHIELD); also elsewhere on the board
GND: C611.2, C6111.2, C6112.2, C6113.2, C6114.2, C6115.2, C6116.2, C6117.2, C6118.2, C6119.2, C6121.2, C6122.2, C6123.2, C6124.2, C6125.2, C6126.2, C6127.2, C6128.2, C6129.2, C6131.2, C6132.2, C6133.2, C6134.2, C6135.2, C6136.2, C6137.2, C6138.2, C6139.2, C6601.2, C6602.2, C6603.2, C6604.2, C6605.2, C6606.2, C6607.2, C6608.2, C6609.2, C6610.2, C6611.2, C6612.2, C6613.2, C6614.2, C6615.2, C6616.2, C6617.2, C6618.2, C6619.2, C6620.2, C6621.2, C6622.2, C6623.2, C6624.2, C6625.2, C6626.2, C6627.2, C6628.2, C6629.2, C6630.2, C6631.2, C61110.2, C61111.2, C61210.2, C61211.2, C61310.2, C61311.2, J610.1 (TRCT3), J610.6 (TRCT2), J610.7 (TRCT4), J610.12 (TRCT1), J611.1 (TRCT3), J611.6 (TRCT2), J611.7 (TRCT4), J611.12 (TRCT1), J612.1 (TRCT3), J612.6 (TRCT2), J612.7 (TRCT4), J612.12 (TRCT1), J613.1 (TRCT3), J613.6 (TRCT2), J613.7 (TRCT4), J613.12 (TRCT1), J620.4 (GND), J620.9 (GND), J620.15 (GND), J620.18 (GND), J620.21 (GND), J620.26 (GND), J620.27 (GND), J620.29 (GND), J620.34 (GND), J620.35 (GND), J620.37 (GND), J620.40 (GND), J620.43 (GND), J620.50 (GND), R602.2, R603.2, R604.2, R607.2, R608.2, R6111.2, R6112.2, R6121.2, R6122.2, R6131.2, R6132.2, U601.B8 (REXT_GND[1]), U601.C5 (AGND), U601.C6 (AGND), U601.C9 (AGND), U601.C10 (AGND), U601.C11 (AGND), U601.E5 (DGND), U601.E6 (DGND), U601.E7 (DGND), U601.E8 (DGND), U601.E9 (DGND), U601.E10 (DGND), U601.F5 (DGND), U601.F6 (DGND), U601.F7 (DGND), U601.F8 (DGND), U601.F9 (DGND), U601.F10 (DGND), U601.G5 (DGND), U601.G6 (DGND), U601.G7 (DGND), U601.G8 (DGND), U601.G9 (DGND), U601.G10 (DGND), U601.H3 (AGND), U601.H5 (DGND), U601.H6 (DGND), U601.H7 (DGND), U601.H8 (DGND), U601.H9 (DGND), U601.H10 (DGND), U601.J5 (DGND), U601.J6 (DGND), U601.J7 (DGND), U601.J8 (DGND), U601.J9 (DGND), U601.J10 (DGND), U601.K5 (DGND), U601.K6 (DGND), U601.K7 (DGND), U601.K8 (DGND), U601.K9 (DGND), U601.K10 (DGND), U601.M5 (AGND), U601.M6 (AGND), U601.M9 (AGND), U601.M10 (AGND), U601.M11 (AGND), U601.N7 (REXT_GND[0]), U606.2 (GND), U611.15 (GD_1), U611.18 (GD_2), U611.22 (GD_3), U611.30 (TEST), U611.35 (VAUX_DET/GPIO3/LED3/TCK), U611.49 (VSS_EP), U612.15 (GD_1), U612.18 (GD_2), U612.22 (GD_3), U612.30 (TEST), U612.35 (VAUX_DET/GPIO3/LED3/TCK), U612.49 (VSS_EP), U613.15 (GD_1), U613.18 (GD_2), U613.22 (GD_3), U613.30 (TEST), U613.35 (VAUX_DET/GPIO3/LED3/TCK), U613.49 (VSS_EP), U630.3 (GND), U630.8 (GND), U631.3 (GND), U631.8 (GND), U632.3 (GND), U632.8 (GND), U633.3 (GND), U633.8 (GND), U634.3 (GND), U634.8 (GND), U635.3 (GND), U635.8 (GND), U636.3 (GND), U636.8 (GND), U637.3 (GND), U637.8 (GND), Y611.2 (GND), Y611.4 (GND), Y612.2 (GND), Y612.4 (GND), Y613.2 (GND), Y613.4 (GND); also elsewhere on the board
LAN1_1V2: C6121.1, C6122.1, FB6121.1, L6121.2, U612.13 (VDD12CORE), U612.31 (VDD12CORE), U612.34 (VDD12_SW_FB), U612.40 (VDD12CORE)
LAN1_1V2_A: C61210.1, FB6121.2, U612.4 (AVDDL_1), U612.9 (AVDDL_2), U612.14 (VP), U612.20 (VPTX), U612.45 (AVDD12)
LAN1_2V5_A: C61211.1, FB6122.2, U612.1 (AVDDH_1), U612.12 (AVDDH_2), U612.23 (VPH)
LAN1_2V5_OUT: C6123.1, FB6122.1, U612.27 (VDD25_REG_OUT)
LAN1_EP_TX_N: C61215.1, U612.21 (PCIE_TX_M)
LAN1_EP_TX_P: C61214.1, U612.19 (PCIE_TX_P)
LAN1_ISET: R6122.1, U612.48 (ISET)
LAN1_LED0: J612.17 (LED1-), U612.38 (EECS/GPIO0/LED0/TDI)
LAN1_LED1: J612.19 (LED2-), U612.37 (EEDIO/GPIO1/LED1/TDO)
LAN1_LED_A1: J612.18 (LED1+), R654.2
LAN1_LED_A2: J612.20 (LED2+), R655.2
LAN1_MDI_A_N: J612.10 (TRD1-), U612.3 (TXRXM_A), U634.2 (D1-)
LAN1_MDI_A_P: J612.11 (TRD1+), U612.2 (TXRXP_A), U634.1 (D1+)
LAN1_MDI_B_N: J612.5 (TRD2-), U612.6 (TXRXM_B), U634.5 (D2-)
LAN1_MDI_B_P: J612.4 (TRD2+), U612.5 (TXRXP_B), U634.4 (D2+)
LAN1_MDI_C_N: J612.2 (TRD3-), U612.8 (TXRXM_C), U635.2 (D1-)
LAN1_MDI_C_P: J612.3 (TRD3+), U612.7 (TXRXP_C), U635.1 (D1+)
LAN1_MDI_D_N: J612.9 (TRD4-), U612.11 (TXRXM_D), U635.5 (D2-)
LAN1_MDI_D_P: J612.8 (TRD4+), U612.10 (TXRXP_D), U635.4 (D2+)
LAN1_PCIE_CLKREQ_N: U601.D12 (CLKREQ_L[2]), U612.42 (CLKREQ#)
LAN1_PCIE_PERST_N: U601.N2 (DWNRST_L[2]), U612.44 (PERST#)
LAN1_PCIE_REFCLK_N: U601.H14 (REFCLKON[4]), U612.26 (PCIE_CLK_M)
LAN1_PCIE_REFCLK_P: U601.H13 (REFCLKOP[4]), U612.25 (PCIE_CLK_P)
LAN1_PCIE_RX_N: C61213.2, U612.17 (PCIE_RX_M)
LAN1_PCIE_RX_P: C61212.2, U612.16 (PCIE_RX_P)
LAN1_PCIE_TX_N: C61215.2, U601.B10 (PERN[5])
LAN1_PCIE_TX_P: C61214.2, U601.A10 (PERP[5])
LAN1_RESET_LOCAL_N: R6123.2, U612.29 (RESET_N); also elsewhere on the board
LAN1_RESREF: R6121.1, U612.24 (RESREF)
LAN1_SW_NODE: L6121.1, U612.32 (VDD12_SW_OUT)
LAN1_SW_TX_N: C61213.1, U601.B9 (PETN[5])
LAN1_SW_TX_P: C61212.1, U601.A9 (PETP[5])
LAN1_XI: C6124.1, U612.47 (XI), Y612.1 (XI)
LAN1_XO: C6125.1, U612.46 (XO), Y612.3 (XO)
LAN2_1V2: C6131.1, C6132.1, FB6131.1, L6131.2, U613.13 (VDD12CORE), U613.31 (VDD12CORE), U613.34 (VDD12_SW_FB), U613.40 (VDD12CORE)
LAN2_1V2_A: C61310.1, FB6131.2, U613.4 (AVDDL_1), U613.9 (AVDDL_2), U613.14 (VP), U613.20 (VPTX), U613.45 (AVDD12)
LAN2_2V5_A: C61311.1, FB6132.2, U613.1 (AVDDH_1), U613.12 (AVDDH_2), U613.23 (VPH)
LAN2_2V5_OUT: C6133.1, FB6132.1, U613.27 (VDD25_REG_OUT)
LAN2_EP_TX_N: C61315.1, U613.21 (PCIE_TX_M)
LAN2_EP_TX_P: C61314.1, U613.19 (PCIE_TX_P)
LAN2_ISET: R6132.1, U613.48 (ISET)
LAN2_LED0: J613.17 (LED1-), U613.38 (EECS/GPIO0/LED0/TDI)
LAN2_LED1: J613.19 (LED2-), U613.37 (EEDIO/GPIO1/LED1/TDO)
LAN2_LED_A1: J613.18 (LED1+), R656.2
LAN2_LED_A2: J613.20 (LED2+), R657.2
LAN2_MDI_A_N: J613.10 (TRD1-), U613.3 (TXRXM_A), U636.2 (D1-)
LAN2_MDI_A_P: J613.11 (TRD1+), U613.2 (TXRXP_A), U636.1 (D1+)
LAN2_MDI_B_N: J613.5 (TRD2-), U613.6 (TXRXM_B), U636.5 (D2-)
LAN2_MDI_B_P: J613.4 (TRD2+), U613.5 (TXRXP_B), U636.4 (D2+)
LAN2_MDI_C_N: J613.2 (TRD3-), U613.8 (TXRXM_C), U637.2 (D1-)
LAN2_MDI_C_P: J613.3 (TRD3+), U613.7 (TXRXP_C), U637.1 (D1+)
LAN2_MDI_D_N: J613.9 (TRD4-), U613.11 (TXRXM_D), U637.5 (D2-)
LAN2_MDI_D_P: J613.8 (TRD4+), U613.10 (TXRXP_D), U637.4 (D2+)
LAN2_PCIE_CLKREQ_N: U601.C13 (CLKREQ_L[3]), U613.42 (CLKREQ#)
LAN2_PCIE_PERST_N: U601.P2 (DWNRST_L[3]), U613.44 (PERST#)
LAN2_PCIE_REFCLK_N: U601.J14 (REFCLKON[5]), U613.26 (PCIE_CLK_M)
LAN2_PCIE_REFCLK_P: U601.J13 (REFCLKOP[5]), U613.25 (PCIE_CLK_P)
LAN2_PCIE_RX_N: C61313.2, U613.17 (PCIE_RX_M)
LAN2_PCIE_RX_P: C61312.2, U613.16 (PCIE_RX_P)
LAN2_PCIE_TX_N: C61315.2, U601.B5 (PERN[6])
LAN2_PCIE_TX_P: C61314.2, U601.A5 (PERP[6])
LAN2_RESET_LOCAL_N: R6133.2, U613.29 (RESET_N); also elsewhere on the board
LAN2_RESREF: R6131.1, U613.24 (RESREF)
LAN2_SW_NODE: L6131.1, U613.32 (VDD12_SW_OUT)
LAN2_SW_TX_N: C61313.1, U601.B6 (PETN[6])
LAN2_SW_TX_P: C61312.1, U601.A6 (PETP[6])
LAN2_XI: C6134.1, U613.47 (XI), Y613.1 (XI)
LAN2_XO: C6135.1, U613.46 (XO), Y613.3 (XO)
LOGIC_3V3: C611.1, R605.2, R606.2, U606.5 (VCC); also elsewhere on the board
NET_3V3: C6116.1, C6117.1, C6118.1, C6119.1, C6126.1, C6127.1, C6128.1, C6129.1, C6136.1, C6137.1, C6138.1, C6139.1, C6601.1, C6602.1, C6609.1, C6612.1, C6615.1, C6618.1, C6621.1, C6628.1, C6629.1, C6631.1, R601.2, R650.1, R651.1, R652.1, R653.1, R654.1, R655.1, R656.1, R657.1, R6113.1, R6123.1, R6133.1, U601.C8 (AVDDH), U601.D4 (VDDR), U601.D11 (VDDR), U601.G3 (AVDDH), U601.G12 (CVDDR), U601.H12 (CVDDR), U601.L4 (VDDR), U601.L11 (VDDR), U601.M7 (AVDDH), U611.28 (VDD_REG_IN), U611.33 (VDD_SW_IN), U611.39 (VDDVARIO), U611.41 (VDD_OTP), U612.28 (VDD_REG_IN), U612.33 (VDD_SW_IN), U612.39 (VDDVARIO), U612.41 (VDD_OTP), U613.28 (VDD_REG_IN), U613.33 (VDD_SW_IN), U613.39 (VDDVARIO), U613.41 (VDD_OTP); also elsewhere on the board
NET_3V3_PG: U606.3; also elsewhere on the board
PCIE_1V0: C6603.1, C6604.1, C6605.1, C6606.1, C6607.1, C6608.1, C6610.1, C6611.1, C6613.1, C6614.1, C6616.1, C6617.1, C6619.1, C6620.1, C6622.1, C6623.1, C6624.1, C6625.1, C6626.1, C6627.1, C6630.1, U601.D5 (VDDC), U601.D6 (VDDC), U601.D7 (AVDD), U601.D8 (AVDD), U601.D9 (VDDC), U601.D10 (VDDC), U601.E4 (VDDC), U601.E11 (VDDC), U601.G4 (VDDC), U601.G11 (VDDC), U601.H4 (VDDC), U601.H11 (VDDC), U601.K4 (VDDC), U601.K11 (VDDC), U601.L5 (VDDC), U601.L6 (VDDC), U601.L7 (AVDD), U601.L8 (AVDD), U601.L9 (VDDC), U601.L10 (VDDC); also elsewhere on the board
PCIE_1V0_PG: U606.6; also elsewhere on the board
PCIE_MODE_606_HIGH: R601.1, U601.D2 (GPIO[0])
PCIE_UP_CLKREQ_N: R607.1; also elsewhere on the board
PCIE_UP_PERST_CMD_N: U606.1; also elsewhere on the board
PCIE_UP_PERST_N: R608.1, U601.C12 (PERST_L), U606.4
PCIE_UP_REFCLK_N: U601.G14 (REFCLKIN); also elsewhere on the board
PCIE_UP_REFCLK_P: U601.G13 (REFCLKIP); also elsewhere on the board
PCIE_UP_RX_N_CM5: C608.2; also elsewhere on the board
PCIE_UP_RX_P_CM5: C607.2; also elsewhere on the board
PCIE_UP_SW_RX_N: C606.2, U601.N3 (PERN[0])
PCIE_UP_SW_RX_P: C605.2, U601.P3 (PERP[0])
PCIE_UP_SW_TX_N: C608.1, U601.N4 (PETN[0])
PCIE_UP_SW_TX_P: C607.1, U601.P4 (PETP[0])
PCIE_UP_TX_N_CM5: C606.1; also elsewhere on the board
PCIE_UP_TX_P_CM5: C605.1; also elsewhere on the board
PCIE_UP_WAKE_N: J620.1 (WAKE#), U611.43 (WAKE#), U612.43 (WAKE#), U613.43 (WAKE#); also elsewhere on the board
SW_IREF: R604.1, U601.E12 (IREF)
SW_REFCLK0_IN_N: C602.2, U601.P8 (REFCLKN[0])
SW_REFCLK0_IN_P: C601.2, U601.N8 (REFCLKP[0])
SW_REFCLK1_IN_N: C604.2, U601.A7 (REFCLKN[1])
SW_REFCLK1_IN_P: C603.2, U601.B7 (REFCLKP[1])
SW_REFCLK1_RAW_N: C602.1, U601.D14 (REFCLKON[1])
SW_REFCLK1_RAW_P: C601.1, U601.D13 (REFCLKOP[1])
SW_REFCLK2_RAW_N: C604.1, U601.E14 (REFCLKON[2])
SW_REFCLK2_RAW_P: C603.1, U601.E13 (REFCLKOP[2])
SW_REXT0: R603.1, U601.P7 (REXT[0])
SW_REXT1: R602.1, U601.A8 (REXT[1])
SYS_I2C7_SCL: J620.30 (SMB_CLK), R606.1, U601.J11 (SCL_I2C); also elsewhere on the board
SYS_I2C7_SDA: J620.32 (SMB_DATA), R605.1, U601.F12 (SDA_I2C); also elsewhere on the board
WAN1_LED0: J610.17 (LED1-); also elsewhere on the board
WAN1_LED1: J610.19 (LED2-); also elsewhere on the board
WAN1_LED_A1: J610.18 (LED1+), R650.2
WAN1_LED_A2: J610.20 (LED2+), R651.2
WAN1_MDI0_N: J610.10 (TRD1-), U630.2 (D1-); also elsewhere on the board
WAN1_MDI0_P: J610.11 (TRD1+), U630.1 (D1+); also elsewhere on the board
WAN1_MDI1_N: J610.5 (TRD2-), U630.5 (D2-); also elsewhere on the board
WAN1_MDI1_P: J610.4 (TRD2+), U630.4 (D2+); also elsewhere on the board
WAN1_MDI2_N: J610.2 (TRD3-), U631.2 (D1-); also elsewhere on the board
WAN1_MDI2_P: J610.3 (TRD3+), U631.1 (D1+); also elsewhere on the board
WAN1_MDI3_N: J610.9 (TRD4-), U631.5 (D2-); also elsewhere on the board
WAN1_MDI3_P: J610.8 (TRD4+), U631.4 (D2+); also elsewhere on the board
WAN2_1V2: C6111.1, C6112.1, FB6111.1, L6111.2, U611.13 (VDD12CORE), U611.31 (VDD12CORE), U611.34 (VDD12_SW_FB), U611.40 (VDD12CORE)
WAN2_1V2_A: C61110.1, FB6111.2, U611.4 (AVDDL_1), U611.9 (AVDDL_2), U611.14 (VP), U611.20 (VPTX), U611.45 (AVDD12)
WAN2_2V5_A: C61111.1, FB6112.2, U611.1 (AVDDH_1), U611.12 (AVDDH_2), U611.23 (VPH)
WAN2_2V5_OUT: C6113.1, FB6112.1, U611.27 (VDD25_REG_OUT)
WAN2_EP_TX_N: C61115.1, U611.21 (PCIE_TX_M)
WAN2_EP_TX_P: C61114.1, U611.19 (PCIE_TX_P)
WAN2_ISET: R6112.1, U611.48 (ISET)
WAN2_LED0: J611.17 (LED1-), U611.38 (EECS/GPIO0/LED0/TDI)
WAN2_LED1: J611.19 (LED2-), U611.37 (EEDIO/GPIO1/LED1/TDO)
WAN2_LED_A1: J611.18 (LED1+), R652.2
WAN2_LED_A2: J611.20 (LED2+), R653.2
WAN2_MDI_A_N: J611.10 (TRD1-), U611.3 (TXRXM_A), U632.2 (D1-)
WAN2_MDI_A_P: J611.11 (TRD1+), U611.2 (TXRXP_A), U632.1 (D1+)
WAN2_MDI_B_N: J611.5 (TRD2-), U611.6 (TXRXM_B), U632.5 (D2-)
WAN2_MDI_B_P: J611.4 (TRD2+), U611.5 (TXRXP_B), U632.4 (D2+)
WAN2_MDI_C_N: J611.2 (TRD3-), U611.8 (TXRXM_C), U633.2 (D1-)
WAN2_MDI_C_P: J611.3 (TRD3+), U611.7 (TXRXP_C), U633.1 (D1+)
WAN2_MDI_D_N: J611.9 (TRD4-), U611.11 (TXRXM_D), U633.5 (D2-)
WAN2_MDI_D_P: J611.8 (TRD4+), U611.10 (TXRXP_D), U633.4 (D2+)
WAN2_PCIE_CLKREQ_N: U601.F11 (CLKREQ_L[1]), U611.42 (CLKREQ#)
WAN2_PCIE_PERST_N: U601.M2 (DWNRST_L[1]), U611.44 (PERST#)
WAN2_PCIE_REFCLK_N: U601.F14 (REFCLKON[3]), U611.26 (PCIE_CLK_M)
WAN2_PCIE_REFCLK_P: U601.F13 (REFCLKOP[3]), U611.25 (PCIE_CLK_P)
WAN2_PCIE_RX_N: C61113.2, U611.17 (PCIE_RX_M)
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

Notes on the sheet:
1. PI7C9X2G608GP PCIe GEN2 SWITCH - 606 MODE
U601A: exact PCIe lanes, reset and distributed reference clocks
U601B: 606-mode strap, I2C and calibration; other straps use documented internal defaults
U601C: every 1.0 V / 3.3 V / ground ball shown; one 100 nF capacitor is assigned to every supply ball
GPIO[1:0] = 01 selects 606 mode. GPIO1 uses its internal pulldown; GPIO0 is pulled high.
HARDWARE-QUALIFIED UPSTREAM RESET
U606 asserts switch PERST# unless the CM5 request and both PCIe rail power-good signals are high.
CM5 firmware/root-complex timing must keep the request low until REFCLK and rails have been stable for at least 100 ms.
U601 rail bypass: one 100 nF per supply ball plus 22 uF bulk on 1.0 V and 3.3 V.
2. THREE LAN7430 PCIe GIGABIT ENDPOINTS
NATIVE CM5 WAN1 FRONT END
WAN1: vertical V8BR-1AX1-GH; PHY CTs to GND, PoE CTs NC, shield to chassis
WAN2: pin 35 tied low disables D3cold PME; pin 36 floats on its internal pull-down so advanced PCIe PM remains enabled.
WAN2: RESET_N pulled high; PCIe TX pairs AC-coupled; analog 1.2 V/2.5 V rails ferrite-isolated.
WAN2: vertical V8BR-1AX1-GH; PHY CTs to GND, PoE CTs NC, shield to chassis
LAN1: pin 35 tied low disables D3cold PME; pin 36 floats on its internal pull-down so advanced PCIe PM remains enabled.
LAN1: RESET_N pulled high; PCIe TX pairs AC-coupled; analog 1.2 V/2.5 V rails ferrite-isolated.
LAN1: vertical V8BR-1AX1-GH; PHY CTs to GND, PoE CTs NC, shield to chassis
LAN2: pin 35 tied low disables D3cold PME; pin 36 floats on its internal pull-down so advanced PCIe PM remains enabled.
LAN2: RESET_N pulled high; PCIe TX pairs AC-coupled; analog 1.2 V/2.5 V rails ferrite-isolated.
LAN2: vertical V8BR-1AX1-GH; PHY CTs to GND, PoE CTs NC, shield to chassis
3. WI-FI AP MINI PCIE 4T4R
AW7915-NP1: Wi-Fi 6 4T4R Mini PCIe AP; vendor maximum 9.1 W and 3.5 A recommended; dedicated rail is 3.3 V / 4 A.
J620 uses the controlled SD-67910-001 C2 land pattern; 3D/first-article fit remains a release gate.
Switch port 5 is disabled and unrouted to avoid PCIe Gen2 stubs and an unsafe generic test header.
PWR_FLAG symbols declare off-sheet regulator outputs for ERC; they are not physical parts.

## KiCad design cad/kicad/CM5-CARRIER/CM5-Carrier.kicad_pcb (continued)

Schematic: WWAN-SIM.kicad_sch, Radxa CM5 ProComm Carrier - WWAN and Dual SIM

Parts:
C701, C702: 220uF 6.3V polymer; CP_Elec_8x6.9; MPN 6SVP220MX
C703, C707: 100nF; C_0402_1005Metric; MPN C1005X7R1H104K050BB
C704: 6.8nF C0G; C_0603_1608Metric; MPN GRM1885C1H682JA01D
C705, C708: 220pF C0G; C_0402_1005Metric; MPN GRM1555C1H221JA01D
C706, C709: 68pF C0G; C_0402_1005Metric; MPN GRM1555C1H680JA01D
C710: 15pF C0G; C_0402_1005Metric; MPN GRM1555C1H150JA01D
C711: 9.1pF C0G; C_0402_1005Metric; MPN GRM1555C1H9R1BA01D
C712: 4.7pF C0G; C_0402_1005Metric; MPN GRM1555C1H4R7BA01D
D701: 5.0V TVS; D_SOD-123F; MPN SMF4L5.0AT1G
J701: WWAN_M2_B_KEY_USB3_USB2; TE_2199230-3_M2_Key_B_4.2mm; MPN 2199230-3
J702: DUAL_SIM_B2B_PLUG; Hirose_DF40C-20DP-0.4V_2x10-1MP_P0.4mm; MPN DF40C-20DP-0.4V(51)
J711: CELL_1_RF; MPN 818033349
J712: CELL_2_RF; MPN 818033349
J713: CELL_3_RF; MPN 818033349
J714: CELL_4_GNSS_RF; MPN 818033349
R701: 100k; R_0603_1608Metric; MPN RC0603FR-07100KL
TP7201: MODEM_FULL_CARD_POWER_OFF_N; TestPoint_Pad_D2.0mm
TP7202: MODEM_W_DISABLE1_N; TestPoint_Pad_D2.0mm
TP7203: MODEM_RESET_N; TestPoint_Pad_D2.0mm
TP7204: MODEM_WAKE_N; TestPoint_Pad_D2.0mm
TP7205: MODEM_STATUS_LED_N; TestPoint_Pad_D2.0mm
TP7206: MODEM_SIM_MUX_SEL_OD; TestPoint_Pad_D2.0mm
TP7207: MODEM_3V8; TestPoint_Pad_D2.0mm
TP7208: GND; TestPoint_Pad_D2.0mm
U702, U703: TPD4E05U06DQA; USON-10_2.5x1.0mm_P0.5mm; MPN TPD4E05U06DQAR
U704: FSA2567MPX; WQFN-16-1EP_3x3mm_P0.5mm_EP1.68x1.68mm; MPN FSA2567MPX

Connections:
CHASSIS_GND: J702.2, J702.16, J702.18, J702.20; also elsewhere on the board
GND: C701.2, C702.2, C703.2, C704.2, C705.2, C706.2, C707.2, C708.2, C709.2, C710.2, C711.2, C712.2, D701.2 (A2), J701.3 (GND), J701.5 (GND), J701.11 (GND), J701.27 (GND), J701.33 (GND), J701.39 (GND), J701.45 (GND), J701.51 (GND), J701.57 (GND), J701.71 (GND), J701.73 (GND), J702.1, J702.5, J702.7, J702.11, J702.13, J702.15, J702.17, J702.19, TP7208.1, U702.3 (GND), U702.8 (GND), U703.3 (GND), U703.8 (GND), U704.6 (GND), U704.17 (EP); also elsewhere on the board
MODEM_3V8: C701.1, C702.1, C703.1, C704.1, C705.1, C706.1, C707.1, C708.1, C709.1, C710.1, C711.1, C712.1, D701.1 (A1), J701.2 (3.3V), J701.4 (3.3V), J701.70 (3.3V), J701.72 (3.3V), J701.74 (3.3V), TP7207.1; also elsewhere on the board
MODEM_FULL_CARD_POWER_OFF_N: J701.6 (~FULL_CARD_POWER_OFF), TP7201.1; also elsewhere on the board
MODEM_RESET_N: J701.67 (~RESET), TP7203.1; also elsewhere on the board
MODEM_SIM_MUX_SEL_OD: R701.2, TP7206.1, U704.2 (SEL); also elsewhere on the board
MODEM_STATUS_LED_N: J701.10 (GPIO_9/DAS/~DSS/~LED1), TP7205.1; also elsewhere on the board
MODEM_UIM_CLK: J701.32 (UIM-CLK), U704.8 (CLK)
MODEM_UIM_DATA: J701.34 (UIM-DATA), U704.12 (DAT)
MODEM_UIM_PWR: J701.36 (UIM-PWR), R701.1, U704.14 (VCC), U704.16 (VSIM)
MODEM_UIM_RESET: J701.30 (UIM-RESET), U704.4 (RST)
MODEM_WAKE_N: J701.54 (~PEWAKE), TP7204.1; also elsewhere on the board
MODEM_W_DISABLE1_N: J701.8 (~W_DISABLE1), TP7202.1; also elsewhere on the board
SIM1_CLK_RAW: J702.6, U704.7 (2CLK)
SIM1_DATA_RAW: J702.8, U704.11 (2DAT)
SIM1_RESET_RAW: J702.4, U704.3 (2RST)
SIM1_VCC: J702.3, U704.15 (2VSIM)
SIM2_CLK_RAW: J702.12, U704.9 (1CLK)
SIM2_DATA_RAW: J702.14, U704.13 (1DAT)
SIM2_RESET_RAW: J702.10, U704.5 (1RST)
SIM2_VCC: J702.9, U704.1 (1VSIM)
WWAN_USB2_DM: J701.9 (USB_D-), U702.2 (D1-); also elsewhere on the board
WWAN_USB2_DP: J701.7 (USB_D+), U702.1 (D1+); also elsewhere on the board
WWAN_USB3_RX_N: J701.35 (PETn1/USB3.0-Tx-/SSIC-TxN), U703.2 (D1-); also elsewhere on the board
WWAN_USB3_RX_P: J701.37 (PETp1/USB3.0-Tx+/SSIC-TxP), U703.1 (D1+); also elsewhere on the board
WWAN_USB3_TX_N: J701.29 (PERn1/USB3.0-Rx-/SSIC-RxN), U702.5 (D2-); also elsewhere on the board
WWAN_USB3_TX_P: J701.31 (PERp1/USB3.0-Rx+/SSIC-RxP), U702.4 (D2+); also elsewhere on the board

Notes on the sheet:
1. UNIVERSAL M.2 B-KEY WWAN SOCKET
Socket power pins retain the stock symbol's 3.3 V names but are intentionally fed from MODEM_3V8.
Qualification window: 3.135-4.4 V module input, >=5 A transient capability, keyed B socket, 42 mm standoff.
2. USB ESD AND MODEM BULK CAPACITANCE
Place USB ESD at the modem socket; route USB 3 pairs as short, continuous 90 ohm differential channels.
C701-C712 and D701 implement the RM520N-GL two-bank VCC reference network directly at M.2 pins 2/4 and 70/72/74.
Power-Regulators C1189-C1192 retain 1320 uF upstream bulk; they do not replace the socket-local 2 x 220 uF and HF ladder.
3. FSA2567 DUAL-SIM MUX
R701 keeps SEL high: SIM 1 is selected by default. GPIO control must be open drain; low selects SIM 2.
Physical SIM 1 uses FSA2567 channel 2 and physical SIM 2 uses channel 1 to implement that default.
The control domain tracks MODEM_UIM_PWR, preventing a fixed 3.3 V overdrive when the SIM rail is 1.8 V.
4. DIRECT DUAL-SIM DAUGHTERBOARD SOCKET
J702 plugs directly into SIM-SERVICE J1. There is no SIM cable harness; the horizontal daughterboard is fixed by four precision supports.
The 2.5 mm DF40 stack carries signals only. Four interleaved returns plus six auxiliary ground/chassis pins control loop area and shield impedance.
5. RF BULKHEAD HARNESS CONTRACT
CELL_1
CELL_2
CELL_3
CELL_4_GNSS
Four off-board ECT 818033349 USS RF IV-to-SMA bulkhead pigtails; final cable length remains a routed sample gate.
6. MODEM CONTROL CONTRACT
Control outputs originate at the system GPIO expander. FULL_CARD_POWER_OFF and RESET require final modem-specific timing validation.
TP7201-TP7208 are copper factory probes. USB 2/3 has no branch or generic test header.

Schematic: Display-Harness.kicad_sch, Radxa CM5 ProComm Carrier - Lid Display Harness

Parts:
C801: 10uF 25V X5R; C_0603_1608Metric; MPN GRM188R61E106MA73D
C802: 100nF; C_0402_1005Metric; MPN C1005X7R1H104K050BB
C805: 470nF; C_0603_1608Metric; MPN GRM188R71E474KA12D
C806, C807: 10uF 25V X7R; C_0805_2012Metric; MPN GRM21BR71E106KA73L
C808, C809, C810: 22uF 10V X7R; C_0805_2012Metric; MPN GRM21BR71A226ME44L
F801: 0.10A hold / 15V; Fuse_0603_1608Metric; MPN 0603L010YR
F802: 1.10A hold / 16V; Fuse_1206_3216Metric; MPN 1206L110/16WR
J801: HDMI_TO_LID_DISPLAY; HDMI_A_Molex_208658-1001_Horizontal; MPN 208658-1001
J802: TOUCH_USB_HOST; USB3_A_Receptacle_Wuerth_692122030100; MPN 692122030100
J803: LID_DISPLAY_12V; Molex_Micro-Fit_3.0_43045-0412_2x02_P3.00mm_Vertical; MPN 43045-0412
L805: 2.2uH / 3.7A; L_Coilcraft_XxL4040; MPN XGL4030-222MEC
R805: 26.1k 0.1%; R_0603_1608Metric; MPN TNPW060326K1BEEA
R806: 4.99k 0.1%; R_0603_1608Metric; MPN TNPW06034K99BEEA
R807: 7.5k S-CONF; R_0603_1608Metric; MPN RC0603FR-077K5L
U801, U802, U803, U804: TPD4E05U06DQA; USON-10_2.5x1.0mm_P0.5mm; MPN TPD4E05U06DQAR
U805: TPS62913RPU; Texas_RPU0010A_VQFN-HR-10_2x2mm_P0.5mm; MPN TPS62913RPUT

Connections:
CHASSIS_GND: J801.SH, J802.SH (SHIELD); also elsewhere on the board
DISPLAY_12V: J803.1, J803.2; also elsewhere on the board
DISPLAY_IO_12V: C806.1, C807.1, U805.1 (EN/SYNC), U805.6 (VIN); also elsewhere on the board
GND: C801.2, C802.2, C805.2, C806.2, C807.2, C808.2, C809.2, C810.2, J801.2 (D2S), J801.5 (D1S), J801.8 (D0S), J801.11 (CKS), J801.17 (GND), J802.4 (GND), J803.3, J803.4, R806.2, R807.2, U801.3 (GND), U801.8 (GND), U802.3 (GND), U802.8 (GND), U803.3 (GND), U803.8 (GND), U804.3 (GND), U804.8 (GND), U805.4 (PGND), U805.7 (PSNS); also elsewhere on the board
HDMI_5V_OUT: F801.2, J801.18 (+5V)
HDMI_CEC: J801.13 (CEC), U803.1 (D1+); also elsewhere on the board
HDMI_CLK_N: J801.12 (CK-), U802.5 (D2-); also elsewhere on the board
HDMI_CLK_P: J801.10 (CK+), U802.4 (D2+); also elsewhere on the board
HDMI_D0_N: J801.9 (D0-), U802.2 (D1-); also elsewhere on the board
HDMI_D0_P: J801.7 (D0+), U802.1 (D1+); also elsewhere on the board
HDMI_D1_N: J801.6 (D1-), U801.5 (D2-); also elsewhere on the board
HDMI_D1_P: J801.4 (D1+), U801.4 (D2+); also elsewhere on the board
HDMI_D2_N: J801.3 (D2-), U801.2 (D1-); also elsewhere on the board
HDMI_D2_P: J801.1 (D2+), U801.1 (D1+); also elsewhere on the board
HDMI_DDC_SCL: J801.15 (SCL), U803.2 (D1-); also elsewhere on the board
HDMI_DDC_SDA: J801.16 (SDA), U803.4 (D2+); also elsewhere on the board
HDMI_HEAC_P: J801.14 (UTILITY); also elsewhere on the board
HDMI_HPD: J801.19 (HPD), U803.5 (D2-); also elsewhere on the board
IO5V0_FB: R805.2, R806.1, U805.9 (FB)
IO5V0_NRSS: C805.1, U805.8 (NR/SS)
IO5V0_SCONF: R807.1, U805.10 (S-CONF)
IO5V0_SW: L805.1, U805.2 (SW)
IO_5V0: C808.1, C809.1, C810.1, F801.1, F802.1, L805.2, R805.1, U805.3 (VO); also elsewhere on the board
IO_5V0_PG: U805.5 (PG); also elsewhere on the board
TOUCH_USB_5V: C801.1, C802.1, F802.2, J802.1 (VBUS)
TOUCH_USB_DM: J802.2 (D-), U804.2 (D1-); also elsewhere on the board
TOUCH_USB_DP: J802.3 (D+), U804.1 (D1+); also elsewhere on the board

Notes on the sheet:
1. HDMI TYPE-A SOURCE CONNECTOR
HDMI_HEAC_N remains unused in Rev A; the selected monitor uses video/DDC/CEC/HPD only.
Shell bonds to chassis at the connector. TMDS shield returns use the local digital ground plane.
2. HDMI ESD / LOW-CAPACITANCE SHUNTS
Place all HDMI ESD arrays immediately behind J801 with no stubs on TMDS pairs.
HDMI DDC connects directly to the CM5 5 V DDC pins, matching Radxa CM5 IO V2.2; do not add duplicate carrier pull-ups.
3. DEDICATED IO_5V0 / 2 A BUCK
IO_5V0 feeds CM5 U13-B pin 106, HDMI source 5 V and USB-touch VBUS; no monitor-power eFuse.
4. USB TOUCH HOST PORT
Only USB 2 is allocated from the CM5. A standard USB 3 A-to-B cable still carries USB 2 touch data.
The monitor-side SuperSpeed Type-B receptacle is not duplicated as a device connector on this host carrier.
5. 12 V / 2.5 A DISPLAY POWER
DISPLAY_12V design load: 2.5 A continuous / 30 W branch, covering the locked 25 W monitor.
No local display eFuse. Use the upstream AUX_12V branch fuse and H03C keyed 18 AWG harness.
6. HINGE-EDGE HARNESS BUILD
H03A HDMI, H03B USB touch, H03C 12 V: 1000 +/- 25 mm each, with separate retained hinge and service loops.
Acceptance: full lid travel plus 300 mm panel lift / 45 degree tilt; no connector tension or hinge-line bend.
Carrier connectors face down. Store released loops clear of fans, PSU airflow, board keepouts and sharp edges.

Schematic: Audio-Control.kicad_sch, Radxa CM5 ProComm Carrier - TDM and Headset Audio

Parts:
C901, C903, C904, C905, C906, C907, C908, C926, C927, C928, C929, C930: 100nF; C_0402_1005Metric; MPN C1005X7R1H104K050BB
C902, C910, C911, C912, C913, C920, C921, C922: 1uF; C_0603_1608Metric; MPN GRM188R71A105KA61D
C914, C915, C916, C917, C918: 10uF; C_0603_1608Metric; MPN GRM188R61E106MA73D
C919: 4.7uF; C_0805_2012Metric; MPN GRM21BR71A475KA73L
C923, C924, C925: 2.2uF; C_0603_1608Metric; MPN GRM188R71A225KE15
J901: AUDIO_8X8_TDM_CONTROL; Molex_8783230xx_2x15_P2.0mm_Header_Vertical_Polarized_Mount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; MPN 87832-6423
J910: STX-353K7A-6N-KTTR; Kycon_STX-353K7A-6N-KTTR_PRELIMINARY; MPN STX-353K7A-6N-KTTR
R900: 0R star bond; R_0603_1608Metric; MPN RC0603JR-070RL
R901, R902, R903, R904, R905, R906, R907, R908, R910: 2.2k; R_0603_1608Metric; MPN RC0603FR-072K2L
R909: 200k; R_0603_1608Metric; MPN RC0603FR-07200KL
R911: 330k; R_0603_1608Metric; MPN RC0603FR-07330KL
R912, R913: 100k; R_0603_1608Metric; MPN RC0603FR-07100KL
R914: 10k; R_0603_1608Metric; MPN RC0603FR-0710KL
U900: CM5_AUDIO_OFFSHEET_PORT
U901: SN65LVDS047PW; TSSOP-16_4.4x5mm_P0.65mm; MPN SN65LVDS047PWR
U902: SN65LVDT2D; SOIC-8_3.9x4.9mm_P1.27mm; MPN SN65LVDT2DR
U903: PCA9517ADP; TSSOP-8_3x3mm_P0.65mm; MPN PCA9517ADP,118
U904: PCA9306DP; TSSOP-8_3x3mm_P0.65mm; MPN PCA9306DP,118
U905: SN74AVC4T245PW; TSSOP-16_4.4x5mm_P0.65mm; MPN SN74AVC4T245PWR
U906: SN74LVC1T45DCK; SOT-363_SC-70-6; MPN SN74LVC1T45DCKR
U910: LP5907MFX-3.3; SOT-23-5; MPN LP5907MFX-3.3/NOPB
U911: LP5907MFX-1.8; SOT-23-5; MPN LP5907MFX-1.8/NOPB
U912: ES8316; QFN-32-1EP_4x4mm_P0.4mm_EP2.9x2.9mm_ThermalVias; MPN ES8316
U913: TPA6132A2RTE; WQFN-16-1EP_3x3mm_P0.5mm_EP1.68x1.68mm_ThermalVias; MPN TPA6132A2RTER
U914: TPD4E05U06DQA; USON-10_2.5x1.0mm_P0.5mm; MPN TPD4E05U06DQAR

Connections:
AUDIO_ENABLE: J901.24, U901.1 (EN), U903.5 (EN); also elsewhere on the board
AUDIO_PRESENT_N: J901.23; also elsewhere on the board
AUD_ADC_RST_N: J901.19; also elsewhere on the board
AUD_ADC_SDOUT: U900.5 (AUD_ADC_SDOUT), U902.7 (R); also elsewhere on the board
AUD_ADC_SDOUT_N: J901.14, U902.1 (B)
AUD_ADC_SDOUT_P: J901.13, U902.2 (A)
AUD_BCLK: U900.2 (AUD_BCLK), U901.3 (DIN2); also elsewhere on the board
AUD_BCLK_N: J901.6, U901.13 (DOUT2-)
AUD_BCLK_P: J901.5, U901.14 (DOUT2+)
AUD_DAC_MUTE_CMD_N: J901.21; also elsewhere on the board
AUD_DAC_RST_N: J901.20; also elsewhere on the board
AUD_DAC_SDIN: U900.4 (AUD_DAC_SDIN), U901.7 (DIN4); also elsewhere on the board
AUD_DAC_SDIN_N: J901.12, U901.9 (DOUT4-)
AUD_DAC_SDIN_P: J901.11, U901.10 (DOUT4+)
AUD_FSYNC: U900.3 (AUD_FSYNC), U901.6 (DIN3); also elsewhere on the board
AUD_FSYNC_N: J901.8, U901.12 (DOUT3-)
AUD_FSYNC_P: J901.7, U901.11 (DOUT3+)
AUD_I2C_SCL: J901.17, R903.2, U903.7 (SCLB)
AUD_I2C_SDA: J901.18, R904.2, U903.6 (SDAB)
AUD_IRQ_N: J901.22, U900.8 (AUD_IRQ_N); also elsewhere on the board
AUD_MCLK: U900.1 (AUD_MCLK), U901.2 (DIN1); also elsewhere on the board
AUD_MCLK_N: J901.2, U901.16 (DOUT1-)
AUD_MCLK_P: J901.1, U901.15 (DOUT1+)
ES8316_ADCVREF: C918.1, U912.24 (ADCVREF)
ES8316_CE: R914.2, U912.31 (CE)
ES8316_CPBOT: C916.2, U912.16 (CPBOT)
ES8316_CPTOP: C916.1, U912.15 (CPTOP)
ES8316_CPVSS: C914.1, U912.13 (CPVSSP)
ES8316_DACVREF: C917.1, U912.21 (DACVREF)
ES8316_MICBIAS: R910.1, U912.26 (MICBIAS)
ES8316_VMID: C919.1, U912.25 (VMID)
GND: C901.2, C902.2, J901.3, J901.4, J901.9, J901.10, J901.15, J901.16, J901.26, J901.29, J901.30, R900.1, U901.5 (GND), U901.8 (~EN), U902.5 (GND), U903.4 (GND); also elsewhere on the board
HEADSET_1V8: C904.1, C906.1, C908.1, C913.1, C915.1, C926.1, C927.1, C928.1, R905.1, R906.1, R914.1, U904.2 (VREF1), U905.16 (VCCB), U906.6 (VCCB), U911.5 (OUT), U912.3 (DVDD), U912.4 (PVDD), U912.14 (CPVDD)
HEADSET_3V3: C911.1, C912.1, C923.1, C925.1, C929.1, U910.5 (OUT), U911.1 (IN), U912.22 (AVDD), U913.6 (G0), U913.12 (HPVDD), U913.14 (VDD)
HEADSET_AGND: C903.2, C904.2, C905.2, C906.2, C907.2, C908.2, C910.2, C911.2, C912.2, C913.2, C914.2, C915.2, C917.2, C918.2, C919.2, C923.2, C924.2, C925.2, C926.2, C927.2, C928.2, C929.2, J910.2 (R2_GND), J910.5 (SWITCH_A), R900.2, R912.2, R913.2, U904.1 (GND), U905.8 (GND), U905.9 (GND), U905.14 (2~OE), U905.15 (1~OE), U906.2 (GND), U906.5 (DIR), U910.2 (GND), U911.2 (GND), U912.5 (DGND), U912.17 (CPGND), U912.18 (CPGNDREF), U912.23 (AGND), U912.33 (E-PAD), U913.2 (INL+), U913.3 (INR+), U913.7 (G1), U913.10 (PGND), U913.15 (SGND), U913.17 (EP), U914.3 (GND), U914.8 (GND)
HEADSET_AMP_EN: R913.1, U913.13 (EN); also elsewhere on the board
HEADSET_HP_L: J910.4 (TIP_HP_L), U913.16 (OUTL), U914.1 (D1+)
HEADSET_HP_R: J910.3 (R1_HP_R), U913.5 (OUTR), U914.2 (D1-)
HEADSET_POWER_EN: R912.1, U910.3 (EN), U911.3 (EN); also elsewhere on the board
HPAMP_CPN: C922.2, U913.9 (CPN)
HPAMP_CPP: C922.1, U913.11 (CPP)
HPAMP_HPVSS: C924.1, U913.8 (HPVSS)
HPAMP_IN_L: C920.2, U913.1 (INL-)
HPAMP_IN_R: C921.2, U913.4 (INR-)
HS_BCLK: U900.10 (HS_BCLK), U905.5 (1A2); also elsewhere on the board
HS_CODEC_BCLK: U905.12 (1B2), U912.6 (SCLK)
HS_CODEC_HP_L: C920.1, U912.20 (LOUT)
HS_CODEC_HP_R: C921.1, U912.19 (ROUT)
HS_CODEC_I2C_SCL: R905.2, U904.3 (SCL1), U912.1 (CCLK)
HS_CODEC_I2C_SDA: R906.2, U904.4 (SDA1), U912.32 (CDATA)
HS_CODEC_LRCK: U905.11 (2B1), U912.8 (DLRCK)
HS_CODEC_MCLK: U905.13 (1B1), U912.2 (MCLK)
HS_CODEC_SDIN: U906.4 (B), U912.9 (ASDOUT)
HS_CODEC_SDOUT: U905.10 (2B2), U912.7 (DSDIN)
HS_I2C_BIAS: R909.2, U904.7 (VREF2), U904.8 (EN)
HS_I2C_SCL: R907.2, U900.14 (HS_I2C_SCL), U904.6 (SCL2); also elsewhere on the board
HS_I2C_SDA: R908.2, U900.15 (HS_I2C_SDA), U904.5 (SDA2); also elsewhere on the board
HS_JACK_DET_N: J910.6 (SWITCH_B), R911.2, U900.16 (HS_JACK_DET_N), U914.5 (D2-); also elsewhere on the board
HS_LRCK: U900.11 (HS_LRCK), U905.6 (2A1); also elsewhere on the board
HS_MCLK: U900.9 (HS_MCLK), U905.4 (1A1); also elsewhere on the board
HS_MIC_INPUT: C930.2, U912.27 (RIN2)
HS_MIC_JACK: C930.1, J910.1 (SLEEVE_MIC), R910.2, U914.4 (D2+)
HS_SDIN_FROM_CODEC: U900.13 (HS_SDIN_FROM_CODEC), U906.3 (A); also elsewhere on the board
HS_SDOUT_TO_CODEC: U900.12 (HS_SDOUT_TO_CODEC), U905.7 (2A2); also elsewhere on the board
LOGIC_3V3: C901.1, C902.1, C903.1, C905.1, C907.1, J901.25, R901.1, R902.1, R903.1, R904.1, R907.1, R908.1, R909.1, R911.1, U901.4 (VCC), U902.8 (V_{CC}), U903.1 (VCCA), U903.8 (VCCB), U905.1 (VCCA), U905.2 (1DIR), U905.3 (2DIR), U906.1 (VCCA); also elsewhere on the board
SYS_4V0: C910.1, U910.1 (IN); also elsewhere on the board
SYS_I2C7_SCL: R901.2, U900.6 (SYS_I2C7_SCL), U903.2 (SCLA); also elsewhere on the board
SYS_I2C7_SDA: R902.2, U900.7 (SYS_I2C7_SDA), U903.3 (SDAA); also elsewhere on the board
TDM_SPARE_1: J901.27
TDM_SPARE_2: J901.28

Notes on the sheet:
1. I2S0/TDM PROGRAM-AUDIO LVDS LINK
J901 mates with AUDIO-8X8 J101. Route five 100 ohm differential pairs with the assigned interleaved returns.
SN65LVDT2D includes the ADC-data receiver termination; do not add a duplicate far-end resistor.
2. I2S1 HEADSET LEVEL TRANSLATION
PCA9306 VREF2 and EN share HS_I2C_BIAS through the required 200 k pull-up to 3.3 V.
CM5 audio GPIO is 3.3 V. ES8316 digital pins remain entirely in the translated 1.8 V domain.
3. DEDICATED LOW-NOISE HEADSET RAILS
R900 is the only headset analog-ground bond. Do not create a second PCB or chassis bond.
4. ES8316 I2S1 HEADSET CODEC
CE is pulled to 1.8 V; all ES8316 digital pins are translated. Decoupling follows the Radxa reference topology.
5. TPA6132A2 HEADPHONE AMPLIFIER
G0=1 and G1=0 select 0 dB gain. EN remains software-controlled for pop-free mute.
6. CTIA HEADSET JACK, MIC BIAS, DETECT, AND ESD
CTIA contact map: tip=L, ring1=R, ring2=GND, sleeve=MIC. Verify isolated switch polarity on a Kycon sample.
J910 is routable for prototype capture, but its drawing-derived footprint is blocked from production until sample/coupon sign-off.
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

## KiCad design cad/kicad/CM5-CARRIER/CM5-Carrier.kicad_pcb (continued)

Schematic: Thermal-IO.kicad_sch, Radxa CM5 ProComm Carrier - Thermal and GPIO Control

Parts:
C1011, C1012, C1013, C1020, C1050, C1051, C1052: 100nF; C_0603_1608Metric; MPN GRM188R71E104KA01D
F1021: 3.0A hold / 15V; Fuse_2920_7451Metric; MPN 2920L300/15DR
F1022, F1023, F1024: 1.1A hold / 33V; Fuse_1812_4532Metric; MPN 1812L110/33DR
F1060: 0.25A fast; Fuse_Littelfuse-NANO2-451_453; MPN 0453.250MR
J1021: FFB0412EN-00Y2E CPU FAN; Molex_Micro-Fit_3.0_43045-0412_2x02_P3.00mm_Vertical; MPN 43045-0412
J1022: AFB0412SHB-SP04 MODEM FAN; Molex_Micro-Fit_3.0_43045-0412_2x02_P3.00mm_Vertical; MPN 43045-0412
J1023: THA0412AD-TZW3 INTAKE; Molex_Micro-Fit_3.0_43045-0412_2x02_P3.00mm_Vertical; MPN 43045-0412
J1024: THA0412AD-TZW3 EXHAUST; Molex_Micro-Fit_3.0_43045-0412_2x02_P3.00mm_Vertical; MPN 43045-0412
J1060: STATUS_LAMP_PANEL_HARNESS; Molex_Micro-Fit_3.0_43045-0812_2x04_P3.00mm_Vertical; MPN 43045-0812
J1070: NIGHT_LIGHT_PANEL_HARNESS; Molex_Micro-Fit_3.0_43045-0812_2x04_P3.00mm_Vertical; MPN 43045-0812
Q1060, Q1061, Q1062, Q1063, Q1064, Q1065: 2N7002K-7; SOT-23; MPN 2N7002K-7
R1001, R1002, R1003, R1004: 2.2k; R_0603_1608Metric; MPN RC0603FR-072K2L
R1005, R1021: 4.7k; R_0603_1608Metric; MPN RC0603FR-074K7L
R1006: 200k; R_0603_1608Metric; MPN RC0603FR-07200KL
R1010, R1011, R1012, R1013, R1014, R1015, R1016, R1017, R1018, R1019, R1022, R1080, R1081, R1082, R1083, R1084, R1085: 100k; R_0603_1608Metric; MPN RC0603FR-07100KL
R1020: 4.7k 5%; R_0603_1608Metric; MPN RC0603FR-074K7L
R1031, R1032, R1033, R1034, R1041, R1042, R1043, R1044: 10k; R_0603_1608Metric; MPN RC0603FR-0710KL
R1050: 5.1k; R_0603_1608Metric; MPN RC0603FR-075K1L
R1060, R1061, R1062, R1063, R1064, R1065: 1k; R_0603_1608Metric; MPN RC0603FR-071KL
R1070: 1k ring limit; R_0603_1608Metric; MPN RC0603FR-071KL
TP1001: U1001_INT_N; TestPoint_Pad_D2.0mm
TP1002: U1002_INT_N; TestPoint_Pad_D2.0mm
TP1003: U1003_INT_N; TestPoint_Pad_D2.0mm
U1000: PCA9306DP; TSSOP-8_3x3mm_P0.65mm; MPN PCA9306DP,118
U1001: TCA9535PWR_0x20; TSSOP-24_4.4x7.8mm_P0.65mm; MPN TCA9535PWR
U1002: TCA9535PWR_0x21; TSSOP-24_4.4x7.8mm_P0.65mm; MPN TCA9535PWR
U1003: TCA9535PWR_0x22; TSSOP-24_4.4x7.8mm_P0.65mm; MPN TCA9535PWR
U1020: EMC2305-1-AP-TR; QFN-16-1EP_4x4mm_P0.65mm_EP2.1x2.1mm; MPN EMC2305-1-AP-TR
U1050: TMP117_CM5; WSON-6-1EP_2x2mm_P0.65mm_EP1x1.6mm; MPN TMP117AIDRVR
U1051: TMP117_MODEM; WSON-6-1EP_2x2mm_P0.65mm_EP1x1.6mm; MPN TMP117AIDRVR
U1052: TMP117_BOARD_POWER; WSON-6-1EP_2x2mm_P0.65mm_EP1x1.6mm; MPN TMP117AIDRVR
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

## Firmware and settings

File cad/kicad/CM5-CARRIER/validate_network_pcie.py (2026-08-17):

#!/usr/bin/env python3
"""Validate the controlled Network/PCIe production BOM and release invariants."""

from __future__ import annotations

import csv
from collections import Counter
import os
from pathlib import Path
import subprocess
import tempfile
import xml.etree.ElementTree as ET


ROOT = Path(__file__).resolve().parent
WORKSPACE = ROOT.parent.parent.parent
BOM = WORKSPACE / "docs" / "network_pcie_bom_a1.csv"
SCHEMATIC = ROOT / "Network-PCIe.kicad_sch"
INDUCTOR_FOOTPRINT = ROOT / "CM5Carrier.pretty" / "TDK_VLS3012HBX.kicad_mod"
KICAD_CLI = Path(
    os.environ.get("KICAD_CLI", "/Applications/KiCad/KiCad.app/Contents/MacOS/kicad-cli")
)


def check(name: str, condition: bool, detail: str) -> bool:
    print(f"{'PASS' if condition else 'FAIL'}  {name}: {detail}")
    return condition


def refs_with_mpn(rows: list[dict[str, str]], mpn: str) -> set[str]:
    return {row["Reference"] for row in rows if row["MPN"] == mpn}


def export_net_map() -> dict[tuple[str, str], str]:
    with tempfile.TemporaryDirectory(prefix="radxa-network-validation-") as temp:
        output = Path(temp) / "Network-PCIe.xml"
        result = subprocess.run(
            [
                str(KICAD_CLI), "sch", "export", "netlist", "--format", "kicadxml",
                "--output", str(output), str(SCHEMATIC),
            ],
            check=False,
            stdout=subprocess.PIPE,
            stderr=subprocess.PIPE,
            text=True,
        )
        if result.returncode:
            raise RuntimeError(f"KiCad netlist export failed:\n{result.stderr.strip()}")
        root = ET.parse(output)
        return {
            (node.attrib["ref"], node.attrib["pin"]): net.attrib["name"].lstrip("/")
            for net in root.findall("./nets/net")
            for node in net.findall("node")
        }


def main() -> int:
    rows = list(csv.DictReader(BOM.open())) if BOM.exists() else []
    by_ref = {row["Reference"]: row for row in rows}
    schematic_text = SCHEMATIC.read_text() if SCHEMATIC.exists() else ""
    footprint_text = INDUCTOR_FOOTPRINT.read_text() if INDUCTOR_FOOTPRINT.exists() else ""
    net_map = export_net_map()
    checks: list[bool] = []

    complete = bool(rows) and all(
        row["Manufacturer"] and row["MPN"] and row["Footprint"] for row in rows
    )
    checks.append(
        check(
            "Network/PCIe production BOM",
            len(rows) == 143 and complete,
            f"{len(rows)} rows; all manufacturer, MPN, and footprint fields complete",
        )
    )

    controlled_parts = {
        "U601": (
            "PI7C9X2G608GPCNJEX",
            "Package_BGA:BGA-196_15x15mm_Layout14x14_P1.0mm",
        ),
        "U606": ("SN74LVC1G11DBVR", "Package_TO_SOT_SMD:SOT-23-6"),
        "U611": (
            "LAN7430T-I/Y9X",
            "Package_DFN_QFN:QFN-48-1EP_7x7mm_P0.5mm_EP5.3x5.3mm_ThermalVias",
        ),
        "J610": ("V8BR-1AX1-GH", "CM5Carrier:Bel_V8BR_1AX1_GH"),
        "J620": ("0679101002", "CM5Carrier:Molex_0679101002_Mini_PCIe"),
        "L6111": ("VLS3012HBX-3R3M-N", "CM5Carrier:TDK_VLS3012HBX"),
        "Y611": (
            "ABM8-25.000MHZ-10-D1G-T",
            "Crystal:Crystal_SMD_3225-4Pin_3.2x2.5mm",
        ),
    }
    for reference, (mpn, footprint) in controlled_parts.items():
        row = by_ref.get(reference, {})
        checks.append(
            check(
                f"{reference} controlled part",
                row.get("MPN") == mpn and row.get("Footprint") == footprint,
                f"{row.get('MPN', 'missing')} / {row.get('Footprint', 'missing')}",
            )
        )

    expected_groups = {
        "industrial LAN7430 endpoints": (
            "LAN7430T-I/Y9X",
            {"U611", "U612", "U613"},
        ),
        "active 3.3 uH LAN inductors": (
            "VLS3012HBX-3R3M-N",
            {"L6111", "L6121", "L6131"},
        ),
        "industrial 25 MHz crystals": (
            "ABM8-25.000MHZ-10-D1G-T",
            {"Y611", "Y612", "Y613"},
        ),
        "Bel vertical integrated-magnetics jacks": (
            "V8BR-1AX1-GH",
            {"J610", "J611", "J612", "J613"},
        ),
        "low-capacitance Ethernet ESD arrays": (
            "TPD4E05U06DQAR",
            {f"U{reference}" for reference in range(630, 638)},
        ),
        "22 uF LAN buck and switch bulk capacitors": (
            "GRM21BR71A226ME44L",
            {"C6111", "C6121", "C6131", "C6630", "C6631"},
        ),
        "1 uF LAN LDO capacitors": (
            "GRM155R6YA105KE11D",
            {"C6113", "C6123", "C6133"},
        ),
        "15 pF crystal load capacitors": (
            "GRM1555C1H150JA01D",
            {"C6114", "C6115", "C6124", "C6125", "C6134", "C6135"},
        ),
    }
    for name, (mpn, expected_refs) in expected_groups.items():
        observed = refs_with_mpn(rows, mpn)
        checks.append(check(name, observed == expected_refs, f"refs {sorted(observed)}"))

    value_counts = Counter(row["Value"] for row in rows)
    checks.append(
        check(
            "LAN7430 2.5 V LDO capacitor requirement",
            value_counts["1uF 35V X5R / ESR <1R"] == 3,
            f"{value_counts['1uF 35V X5R / ESR <1R']} channels use the controlled <1 ohm ESR value",
        )
    )
    expected_10nf = {
        f"C{channel}{index}"
        for channel in (611, 612, 613)
        for index in range(6, 10)
    }
    checks.append(
        check(
            "LAN7430 3.3 V pin decoupling",
            refs_with_mpn(rows, "GRM188R71H103KA01D") == expected_10nf,
            "four 10 nF capacitors are assigned to VDD_REG_IN, VDD_SW_IN, VDDVARIO, and VDD_OTP per endpoint",
        )
    )
    expected_beads = {
        f"FB{channel}{index}"
        for channel in (611, 612, 613)
        for index in (1, 2)
    }
    checks.append(
        check(
            "LAN7430 analog rail ferrites",
            refs_with_mpn(rows, "BLM21PG221SN1D") == expected_beads,
            "each endpoint isolates its 1.2 V and 2.5 V analog loads through a controlled ferrite",
        )
    )

    switch_decouplers = {f"C{reference}" for reference in range(6601, 6630)}
    checks.append(
        check(
            "PCIe switch supply-ball decoupling",
            all(
                reference in by_ref
                and by_ref[reference].get("MPN") == "C1005X7R1H104K050BB"
                for reference in switch_decouplers
            ),
            "29 supply balls each have a dedicated 100 nF capacitor",
        )
    )

    upstream_coupling = {
        "C605": ("PCIE_UP_TX_P_CM5", "PCIE_UP_SW_RX_P"),
        "C606": ("PCIE_UP_TX_N_CM5", "PCIE_UP_SW_RX_N"),
        "C607": ("PCIE_UP_SW_TX_P", "PCIE_UP_RX_P_CM5"),
        "C608": ("PCIE_UP_SW_TX_N", "PCIE_UP_RX_N_CM5"),
        "C609": ("WIFI_SW_TX_P", "WIFI_PCIE_RX_P"),
        "C610": ("WIFI_SW_TX_N", "WIFI_PCIE_RX_N"),
    }
    checks.append(
        check(
            "CM5 and Wi-Fi host PCIe TX coupling",
            all(
                net_map.get((reference, "1")) == source
                and net_map.get((reference, "2")) == load
                for reference, (source, load) in upstream_coupling.items()
            ),
            "CM5 and switch transmitters are AC-coupled at their source boundaries",
        )
    )

    lan_contract_ok = True
    for reference, prefix in (("U611", "WAN2"), ("U612", "LAN1"), ("U613", "LAN2")):
        channel = reference.removeprefix("U")
        expected_pin_nets = {
            "1": f"{prefix}_2V5_A", "4": f"{prefix}_1V2_A",
            "9": f"{prefix}_1V2_A", "12": f"{prefix}_2V5_A",
            "13": f"{prefix}_1V2", "14": f"{prefix}_1V2_A",
            "19": f"{prefix}_EP_TX_P", "20": f"{prefix}_1V2_A",
            "21": f"{prefix}_EP_TX_N", "23": f"{prefix}_2V5_A",
            "27": f"{prefix}_2V5_OUT", "28": "NET_3V3",
            "29": f"{prefix}_RESET_LOCAL_N", "31": f"{prefix}_1V2",
            "32": f"{prefix}_SW_NODE", "33": "NET_3V3",
            "34": f"{prefix}_1V2", "35": "GND", "39": "NET_3V3",
            "40": f"{prefix}_1V2", "41": "NET_3V3",
            "45": f"{prefix}_1V2_A",
        }
        lan_contract_ok &= all(
            net_map.get((reference, pin)) == net for pin, net in expected_pin_nets.items()
        )
        lan_contract_ok &= net_map.get((reference, "36"), "").startswith("unconnected-")
        lan_contract_ok &= (
            net_map.get((f"R{channel}3", "1")) == "NET_3V3"
            and net_map.get((f"R{channel}3", "2")) == f"{prefix}_RESET_LOCAL_N"
            and net_map.get((f"FB{channel}1", "1")) == f"{prefix}_1V2"
            and net_map.get((f"FB{channel}1", "2")) == f"{prefix}_1V2_A"
            and net_map.get((f"FB{channel}2", "1")) == f"{prefix}_2V5_OUT"
            and net_map.get((f"FB{channel}2", "2")) == f"{prefix}_2V5_A"
        )
        coupling_contract = {
            f"C{channel}12": (f"{prefix}_SW_TX_P", f"{prefix}_PCIE_RX_P"),
            f"C{channel}13": (f"{prefix}_SW_TX_N", f"{prefix}_PCIE_RX_N"),
            f"C{channel}14": (f"{prefix}_EP_TX_P", f"{prefix}_PCIE_TX_P"),
            f"C{channel}15": (f"{prefix}_EP_TX_N", f"{prefix}_PCIE_TX_N"),
        }
        lan_contract_ok &= all(
            net_map.get((cap, "1")) == source and net_map.get((cap, "2")) == load
            for cap, (source, load) in coupling_contract.items()
        )
    checks.append(
        check(
            "LAN7430 electrical pin and PCIe contract",
            lan_contract_ok,
            "all endpoint power pins, deterministic PM straps, reset pull-ups, rail ferrites, and TX coupling networks match the datasheet checklist",
        )
    )

    magjack_contract_ok = True
    for reference, prefix in (
        ("J610", "WAN1"), ("J611", "WAN2"),
        ("J612", "LAN1"), ("J613", "LAN2"),
    ):
        mdi = ("0", "1", "2", "3") if reference == "J610" else ("A", "B", "C", "D")
        expected_pin_nets = {
            "1": "GND", "6": "GND", "7": "GND", "12": "GND",
            "11": f"{prefix}_MDI_{mdi[0]}_P" if reference != "J610" else f"{prefix}_MDI{mdi[0]}_P",
            "10": f"{prefix}_MDI_{mdi[0]}_N" if reference != "J610" else f"{prefix}_MDI{mdi[0]}_N",
            "4": f"{prefix}_MDI_{mdi[1]}_P" if reference != "J610" else f"{prefix}_MDI{mdi[1]}_P",
            "5": f"{prefix}_MDI_{mdi[1]}_N" if reference != "J610" else f"{prefix}_MDI{mdi[1]}_N",
            "3": f"{prefix}_MDI_{mdi[2]}_P" if reference != "J610" else f"{prefix}_MDI{mdi[2]}_P",
            "2": f"{prefix}_MDI_{mdi[2]}_N" if reference != "J610" else f"{prefix}_MDI{mdi[2]}_N",
            "8": f"{prefix}_MDI_{mdi[3]}_P" if reference != "J610" else f"{prefix}_MDI{mdi[3]}_P",
            "9": f"{prefix}_MDI_{mdi[3]}_N" if reference != "J610" else f"{prefix}_MDI{mdi[3]}_N",
            "17": f"{prefix}_LED0", "18": f"{prefix}_LED_A1",
            "19": f"{prefix}_LED1", "20": f"{prefix}_LED_A2",
            "21": "CHASSIS_GND", "22": "CHASSIS_GND",
        }
        magjack_contract_ok &= all(
            net_map.get((reference, pin)) == net
            for pin, net in expected_pin_nets.items()
        )
        magjack_contract_ok &= all(
            net_map.get((reference, pin), "").startswith("unconnected-")
            for pin in ("13", "14", "15", "16")
        )
    checks.append(
        check(
            "vertical Bel MagJack pin contract",
            magjack_contract_ok,
            "all four V8BR PHY pairs, grounded PHY center taps, NC PoE center taps, LEDs, and chassis leads match the Bel drawing",
        )
    )
    checks.append(
        check(
            "AW7915-NP1 supply margin",
            all(net_map.get(("J620", str(pin))) == "WIFI_3V3" for pin in (2, 24, 39, 41, 52))
            and "vendor maximum 9.1 W and 3.5 A recommended" in schematic_text
            and "dedicated rail is 3.3 V / 4 A" in schematic_text,
            "all Mini PCIe 3.3 V contacts use the dedicated 4 A rail, above AsiaRF's 3.5 A recommendation",
        )
    )
    checks.append(
        check(
            "606-mode switch strap",
            by_ref.get("R601", {}).get("MPN") == "RC0603FR-074K7L"
            and "GPIO[1:0] = 01 selects 606 mode" in schematic_text,
            "GPIO0 has a 4.7 k pull-up and GPIO1 uses the device pulldown",
        )
    )
    reset_gate_contract = {
        "1": "PCIE_UP_PERST_CMD_N", "2": "GND", "3": "NET_3V3_PG",
        "4": "PCIE_UP_PERST_N", "5": "LOGIC_3V3", "6": "PCIE_1V0_PG",
    }
    checks.append(
        check(
            "hardware-qualified upstream PCIe reset",
            all(net_map.get(("U606", pin)) == net for pin, net in reset_gate_contract.items())
            and net_map.get(("R608", "1")) == "PCIE_UP_PERST_N"
            and net_map.get(("R608", "2")) == "GND"
            and net_map.get(("C611", "1")) == "LOGIC_3V3"
            and net_map.get(("C611", "2")) == "GND"
            and net_map.get(("U601", "C12")) == "PCIE_UP_PERST_N",
            "switch reset requires CM5 request, NET_3V3_PG, and PCIE_1V0_PG; 100 k defaults asserted",
        )
    )
    checks.append(
        check(
            "PCIe reset timing requirement",
            "stable for at least 100 ms" in schematic_text,
            "CM5 root-complex timing must withhold its request until rails and REFCLK have been stable for 100 ms",
        )
    )
    checks.append(
        check(
            "unused switch port isolation",
            "PCIE_SPARE" not in schematic_text and "J621" not in by_ref,
            "port 5 is disabled/unrouted and no generic PCIe cable header is present",
        )
    )
    checks.append(
        check(
            "grounded four-pad crystal model",
            schematic_text.count("CM5Carrier:Crystal_GND24_3225") >= 3,
            "all three oscillators use the project-local grounded-case symbol",
        )
    )
    checks.append(
        check(
            "TDK inductor controlled land pattern",
            INDUCTOR_FOOTPRINT.exists()
            and footprint_text.count('(pad "1" smd') == 1
            and footprint_text.count('(pad "2" smd') == 1
            and "(size 1.00 3.40)" in footprint_text,
            "two 1.0 x 3.4 mm lands with the drawing-backed 1.1 mm gap",
        )
    )

    failures = len(checks) - sum(checks)
    print(f"\nRESULT: {len(checks)} checks, {failures} failures")
    return 1 if failures else 0


if __name__ == "__main__":
    raise SystemExit(main())

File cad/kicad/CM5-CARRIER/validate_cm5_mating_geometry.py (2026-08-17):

#!/usr/bin/env python3
"""Prove the carrier CM5 mating geometry matches Radxa's official PCB."""

from __future__ import annotations

import hashlib
from pathlib import Path
import re
import subprocess
import tempfile
import xml.etree.ElementTree as ET

from openpyxl import load_workbook


ROOT = Path(__file__).resolve().parent
WORKSPACE = ROOT.parent.parent.parent
SOURCE_DIR = (
    WORKSPACE
    / "references"
    / "radxa-cm-projects"
    / "cm5"
    / "radxa-cm5-io-board"
)
SOURCE_ASC = SOURCE_DIR / "radxa_cm5_io_board_v2200.asc"
SOURCE_BOM = SOURCE_DIR / "radxa_cm5_io_board_v2200_BOM.xlsx"
HIROSE_DRAWING = (
    WORKSPACE
    / "references"
    / "components"
    / "hirose"
    / "DF40C-100DS-0.4V"
    / "DF40C-100DS-0.4V-51_2D_drawing.pdf"
)
HIROSE_DRAWING_SHA256 = "30b4c54ab38ddd18a65e1f3b631b8bcfb64efd1799c2a4a10936f010070521cd"
SCHEMATIC = ROOT / "CM5-Core-Allocated.kicad_sch"
FOOTPRINT_DIR = ROOT / "CM5Carrier.pretty"
KICAD_CLI = Path(
    "/Applications/KiCad/KiCad.app/Contents/MacOS/kicad-cli"
)

FOOTPRINTS = {
    "J501": "Radxa_CM5_U33A_DF40C_100DS_OFFICIAL",
    "J502": "Radxa_CM5_U33B_DF40C_100DS_OFFICIAL",
    "J503": "Radxa_CM5_J24_DF40C_100DS_OFFICIAL",
}


def check(name: str, condition: bool, detail: str) -> bool:
    print(f"{'PASS' if condition else 'FAIL'}  {name}: {detail}")
    return condition


def balanced_sexpr(text: str, start: int) -> str:
    depth = 0
    quoted = False
    escaped = False
    for index in range(start, len(text)):
        character = text[index]
        if quoted:
            if escaped:
                escaped = False
            elif character == "\\":
                escaped = True
            elif character == '"':
                quoted = False
            continue
        if character == '"':
            quoted = True
        elif character == "(":
            depth += 1
        elif character == ")":
            depth -= 1
            if depth == 0:
                return text[start:index + 1]
    raise RuntimeError("Unbalanced KiCad S-expression")


def top_level_sexprs(expression: str) -> list[str]:
    children: list[str] = []
    depth = 0
    quoted = False
    escaped = False
    child_start: int | None = None
    for index, character in enumerate(expression):
        if quoted:
            if escaped:
                escaped = False
            elif character == "\\":
                escaped = True
            elif character == '"':
                quoted = False
            continue
        if character == '"':
            quoted = True
        elif character == "(":
            depth += 1
            if depth == 2:
                child_start = index
        elif character == ")":
            if depth == 2 and child_start is not None:
                children.append(expression[child_start:index + 1])
                child_start = None
            depth -= 1
    return children


def expression_name(expression: str) -> str:
    match = re.match(r"\(\s*([^\s()]+)", expression)
    if not match:
        raise RuntimeError(f"Cannot identify expression: {expression[:80]!r}")
    return match.group(1)


def footprint_by_reference(board_text: str, reference: str) -> str:
    marker = f'(property "Reference" "{reference}"'
    property_offset = board_text.find(marker)
    if property_offset < 0:
        raise RuntimeError(f"Imported official board has no {reference}")
    start = board_text.rfind("(footprint ", 0, property_offset)
    return balanced_sexpr(board_text, start)


def restore_native_j24_pad_angle(expression: str) -> str:
    """Restore the 0-degree angle from Radxa's native PADS decal."""
    at_match = re.search(
        r"\(at\s+(-?[0-9.]+)\s+(-?[0-9.]+)\s+(-?[0-9.]+)\)",
        expression,
    )
    if not at_match or float(at_match.group(3)) % 360.0 != 270.0:
        raise RuntimeError("Unexpected J24 pad angle in KiCad PADS import")
    replacement = f"(at {at_match.group(1)} {at_match.group(2)})"
    return expression[:at_match.start()] + replacement + expression[at_match.end():]


def pad_map(footprint: str, *, restore_j24_angle: bool = False) -> dict[int, str]:
    pads: dict[int, str] = {}
    for child in top_level_sexprs(footprint):
        if expression_name(child) != "pad":
            continue
        match = re.match(r'\(pad "(\d+)"', child)
        if match:
            if restore_j24_angle:
                child = restore_native_j24_pad_angle(child)
            pads[int(match.group(1))] = normalized_geometry(child)
    return pads


def pad_dimensions(footprint: str) -> dict[int, tuple[float, float, float, float, float]]:
    """Return pad x, y, local angle, width and height."""
    pads: dict[int, tuple[float, float, float, float, float]] = {}
    for child in top_level_sexprs(footprint):
        if expression_name(child) != "pad":
            continue
        number = re.match(r'\(pad "(\d+)"', child)
        at = re.search(
            r"\(at\s+(-?[0-9.]+)\s+(-?[0-9.]+)(?:\s+(-?[0-9.]+))?\)",
            child,
        )
        size = re.search(r"\(size\s+([0-9.]+)\s+([0-9.]+)\)", child)
        if not number or not at or not size:
            raise RuntimeError("Cannot parse generated CM5 pad geometry")
        pads[int(number.group(1))] = (
            float(at.group(1)),
            float(at.group(2)),
            float(at.group(3) or 0.0) % 360.0,
            float(size.group(1)),
            float(size.group(2)),
        )
    return pads


def native_pads_decal_contract() -> bool:
    """Check pitch and land geometry directly in Radxa's PADS source."""
    source = SOURCE_ASC.read_text(errors="replace")
    start = re.search(r"^DF40C_100DS\s+M\s", source, re.MULTILINE)
    if not start:
        return False
    next_decal = re.search(
        r"^[A-Za-z0-9_+.-]+\s+M\s",
        source[start.end():],
        re.MULTILINE,
    )
    if not next_decal:
        return False
    decal = source[start.start():start.end() + next_decal.start()]
    coordinates = [
        (int(x), int(y), int(pin))
        for x, y, pin in re.findall(
            r"^T(-?\d+)\s+(-?\d+)\s+-?\d+\s+-?\d+\s+(\d+)\s*$",
            decal,
            re.MULTILINE,
        )
    ]
    if [pin for _, _, pin in coordinates] != list(range(1, 101)):
        return False
    pitch_units = {
        abs(coordinates[index + 2][1] - coordinates[index][1])
        for index in range(98)
    }
    row_spacing_units = {
        abs(coordinates[index + 1][0] - coordinates[index][0])
        for index in range(0, 100, 2)
    }
    pad_stack_ok = bool(
        re.search(
            r"^PAD 0 3\s*\n-2 300000 RF\s+0\.000 1710000\b",
            decal,
            re.MULTILINE,
        )
    )
    return pitch_units == {600000} and row_spacing_units == {3960000} and pad_stack_ok


def normalized_geometry(expression: str) -> str:
    expression = re.sub(
        r"\n\s*\((?:net|uuid|path)\s+[^\n()]*\)",
        "",
        expression,
    )
    return " ".join(expression.split())
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

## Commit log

2026-08-16 Initial Radxa CM5 ProComm hardware design
    [01_COVER.SchDoc, 02_INDEX.SchDoc, 03_Block.SchDoc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]
2026-08-16 Add controlled iM2300 mechanical release package
    [im2300-measurement-register.csv]
2026-08-16 Make KiCad review generation reproducible
    [Audio-8x8.kicad_sch, Audio-Control.kicad_sch, CM5-Carrier.kicad_sch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]
2026-08-16 Add controlled connector footprint audit
    [Audio-8x8.kicad_sch, Network-PCIe.kicad_sch, component-footprint-audit.csv]
2026-08-16 Lock compact QRC-GOLD battery bracket
    [PowerSelector.kicad_sch, panel_mechanical_bom_preliminary.csv]
2026-08-16 Clarify panel-mounted battery dock interface
    [PowerSelector.kicad_sch, panel_mechanical_bom_preliminary.csv]
2026-08-16 Define bottom PSU harness interfaces
    [H01-PSU-24V-BOM.csv, PowerSelector.kicad_sch, component-footprint-audit.csv]
2026-08-16 Define serviceable lid display cable bundle
    [Display-Harness.kicad_sch, H03-Lid-Display-BOM.csv]
2026-08-16 Move cooling to sidewalls and isolate hinge-side PSU
    [im2300-cooling-clearance-rev-a.scad, im2300-measurement-register.csv, panel_mechanical_bom_preliminary.csv]
2026-08-16 Move hinge-side PSU away from audio and lid harness
    [im2300-cooling-clearance-rev-b.scad, im2300-measurement-register.csv]
2026-08-16 Add A2 fabrication readiness audit
    [im2300-cooling-clearance-rev-c.scad, im2300-measurement-register.csv, mechanical-stack-budget-a2.csv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]
2026-08-16 Revise RF transport for folded antennas
    [im2300-measurement-register.csv, mechanical-stack-budget-a2.csv, panel_mechanical_bom_preliminary.csv]
2026-08-16 Control documented monitor envelope
    [im2300-measurement-register.csv, mechanical-stack-budget-a2.csv, panel_mechanical_bom_preliminary.csv]
2026-08-16 Add PCB and connector mechanical supports
    [connector-load-path-a2.csv, im2300-cooling-clearance-rev-d.scad, im2300-measurement-register.csv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]
2026-08-16 Clarify monitor connector lid envelope
    [im2300-measurement-register.csv, mechanical-stack-budget-a2.csv, panel_mechanical_bom_preliminary.csv]
2026-08-16 Set direct lid monitor mount and half-inch clearance
    [im2300-measurement-register.csv, mechanical-stack-budget-a2.csv, panel_mechanical_bom_preliminary.csv]
2026-08-16 Complete A1 detailed carrier and audio capture
    [AK4458-DAC.kicad_sch, AK5558-ADC.kicad_sch, Audio-8x8.kicad_sch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]
2026-08-16 Add A1 footprint qualification coupon package
    [Footprint-Coupon-B_Cu.gbl, Footprint-Coupon-B_Mask.gbs, Footprint-Coupon-B_Silkscreen.gbo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]
2026-08-17 Lock CM5 power and radio interfaces before routing
    [Audio-Control.kicad_sch, CM5-Core-Allocated.kicad_sch, Display-Harness.kicad_sch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]
2026-08-17 Add reviewed schematic release and PCBWay gate
    [release-manifest-a0.csv]
2026-08-17 Add complete-system KiCad schematic project
    [Radxa-CM5-ProComm-System.kicad_sch]
2026-08-17 Replace system index with complete electrical schematic
    [Radxa-CM5-ProComm-System.kicad_sch]
2026-08-17 Audit schematic logic against controlled datasheets
    [AK4458-DAC.kicad_sch, AK5558-ADC.kicad_sch, Audio-8x8.kicad_sch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]
2026-08-17 Lock source-verified PCB mating geometry
    [Audio-8x8.kicad_pcb, CM5-Carrier.kicad_pcb, CM5-Core-Allocated.kicad_sch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]
2026-08-17 Fix PCB-A1 in-board 3D placement
    [Audio-8x8.kicad_pcb, CM5-Carrier.kicad_pcb, PowerSelector.kicad_pcb]
2026-08-17 Implement direct socketed dual-SIM daughterboard
    [AK4458-DAC.kicad_sch, AK5558-ADC.kicad_sch, Audio-8x8.kicad_pcb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]
